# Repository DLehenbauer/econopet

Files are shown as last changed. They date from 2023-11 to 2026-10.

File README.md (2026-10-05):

# EconoPET

Open hardware mainboard replacement for Commodore PET/CBM 2001/30xx/40xx/80xx machines. The EconoPET can also run standalone with HDMI display and USB keyboard.

EconoPET running Space Invaders

## User Resources

See the [project page](https://dlehenbauer.github.io/econopet) for user manual and firmware updates.

## Manufacturing

> **⚠️ Warning:** Rev A is not perfect. Before ordering, review the currently [known issues](https://github.com/DLehenbauer/econopet/issues?q=is%3Aissue%20label%3Arev-a%20label%3Aerrata) and understand that new issues may be discovered over time.

Rev. A has been released. For manufacturing and assembly instructions, go [here](https://dlehenbauer.github.io/econopet/manual/build-an-econopet/).

## Development

This project uses a [Dev Container](https://containers.dev/) for a consistent development environment on Windows, macOS, and Linux.

### Prerequisites

- [Docker](https://www.docker.com/)
- [VS Code](https://code.visualstudio.com/)
- [Dev Containers extension](https://marketplace.visualstudio.com/items?itemName=ms-vscode-remote.remote-containers)

### Workflow

This project uses [CMake](https://cmake.org/) to manage the build process for firmware, gateware, ROMs, and SD card package.

```sh
# Configure
cmake --preset default              # Do this first

# Build
cmake --build --preset all          # Build everything
cmake --build --preset fw           # Build firmware only
cmake --build --preset fw-test      # Build firmware tests only
cmake --build --preset gw           # Build gateware only
cmake --build --preset rom          # Build ROMs only
cmake --build --preset sdcard       # Build SD card package

# Test
ctest --preset all --parallel       # Run all tests
ctest --preset fw --parallel        # Run firmware tests only
ctest --preset gw --parallel        # Run gateware unit tests only
ctest --preset gw-boot --parallel   # Run full-boot benches (Verilator, minutes)
```

Gateware benches run under both simulators. `gw` runs both quick suites;
`gw-iv` and `gw-vl` run only Icarus or Verilator, respectively. Verilator is
two-state and settles differently, so it catches races Icarus tolerates. Each
suite takes under a minute. `ECONOPET_MEDIA_DIR` must point at the directory
containing `roms/` and `disks/`; `top_tb` and the boot bench load real ROMs
from its `roms/` subdirectory.

`gw-boot` is separate because it simulates seconds of PET time: it boots the
stock BASIC-4 ROMs on the soft 6502 and passes only once the banner, the RAM
sizing result and the `READY.` prompt are all on screen. That takes ~5 minutes
under Verilator and is impractical under Icarus. It prints the screen at the
end and writes `gw/EconoPET/outflow/stock6502_boot_tb.pgm`:

```
|*** COMMODORE BASIC 4.0 ***             |
|                                        |
| 31743 BYTES FREE                       |
|                                        |
|READY.                                  |
```

`ctest` hides that on success, so use `ctest --preset gw-boot --parallel -V` to see it, or
run `./verilate.sh stock6502_boot_tb 0` directly. See
[docs/dev/verilator.md](docs/dev/verilator.md) for the Verilator runner and
[docs/dev/testing.md](docs/dev/testing.md) for test seeding and replay.

## License

This project is released under the [CC0 1.0 Universal](LICENSE) (CC0) license, placing it in the public domain.

**Exception:** external dependencies are subject to their own licenses as noted in their respective source code and in [NOTICE.md](NOTICE.md).



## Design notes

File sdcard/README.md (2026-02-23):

# EconoPET Release Notes

For the user manual, firmware updates, and more, visit the [project page](https://dlehenbauer.github.io/econopet).

## Updating Firmware

1. Copy the contents of this archive to a FAT32-formatted microSD card.
2. Insert the microSD card into the EconoPET board.
3. Power on. The firmware will update automatically.

For detailed instructions, see the [user manual](https://dlehenbauer.github.io/econopet).

## Changelog

### v0.2.0 (2026-02-22)

- High-Speed Virtual Datasette (see `/prgs/README.md`)
- HDMI output now supports limited CRTC emulation (R1, R6, R9, R12-R13)
- Optionally load a default configuration when powered on (set `default:` in `config.yaml`)
- ColourPET preview (RGBI output on HDMI, color buffer starts at $8800)

### v0.1.0 (2025-08-29)

- Minimal viable product

## License

This project is released under the [CC0 1.0 Universal](LICENSE) (CC0) license, placing it in the public domain.

**Exception:** external dependencies are subject to their own licenses as noted in their respective source code and in [NOTICE.md](NOTICE.md).

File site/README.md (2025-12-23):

# Site

This directory contains the static website for EconoPET, hosted via GitHub Pages at:

https://dlehenbauer.github.io/econopet

## Deployment

The site references files stored in Git LFS (images, PDFs, and firmware downloads). Because GitHub Pages' default deployment does not check out LFS objects, we use a custom GitHub Actions workflow instead.

The workflow is defined in [`.github/workflows/gh-pages.yml`](../.github/workflows/gh-pages.yml) and must be triggered manually:

1. Go to the [Actions](https://github.com/DLehenbauer/econopet/actions) tab in the GitHub repository
2. Select the **Deploy static content to Pages** workflow from the left sidebar
3. Click **Run workflow** and confirm

The workflow checks out the repository with `lfs: true` to fetch LFS objects, then deploys the contents of `site/dist` to GitHub Pages.

## Links

QR codes linking to the site are printed on the PCB silkscreen. Because space is limited, we use [is.gd](https://is.gd) to shorten URLs. Shorter URLs encode fewer characters, resulting in lower-density QR codes that remain scannable at small sizes with a typical phone camera.

Page  | Short URL
------|----------
[https://dlehenbauer.github.io/econopet](https://dlehenbauer.github.io/econopet) | [https://is.gd/FjBm6R](https://is.gd/FjBm6R)
[https://dlehenbauer.github.io/econopet/40-8096-A.html](https://dlehenbauer.github.io/econopet/40-8096-A.html) | [https://is.gd/6hpvh6](https://is.gd/6hpvh6)

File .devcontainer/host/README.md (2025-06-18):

# Host

On Windows 10/11, you can expose a picoprobe to a docker container using usbipd-win:

```ps
winget install --interactive --exact dorssel.usbipd-win
```

To get the serial port, you may need to `sudo modprobe cdc_acm` on Ubuntu.

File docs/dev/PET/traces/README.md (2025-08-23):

# Logic Analyzer Traces

This folder contains traces captured by a logic analyzer from a CBM 8032.

The traces were recorded using the KingstVIS software. You can download KingstVIS for free from the official website to view these files, or use the software to export the traces to `.bin` or `.csv` formats for further analysis.

**Download KingstVIS software and user manual:**  
https://www.qdkingst.com/en

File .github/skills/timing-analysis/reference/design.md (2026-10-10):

# EconoPET Hardware Design (Timing Context)

This document describes the EconoPET board-level hardware design with enough
detail for an AI agent to derive SDC timing constraints. It is intended to be
read alongside the gateware source in `gw/EconoPET/src/` and the existing SDC
file at `gw/EconoPET/EconoPET.sdc`.

## FPGA

| Property | Value |
|---|---|
| Device | Efinix Trion T20 (T20Q144) |
| Package | QFP-144 |
| I/O Standard | 3.3 V LVTTL / LVCMOS (all banks) |
| I/O Registers  | None (all GPIOs are unregistered at the pad) |
| Speed Grade | Default |

### PLL

A single PLL (`PLL_TL1`) generates the system clock:

| Parameter | Value |
|---|---|
| Reference input | 18 MHz (from RP2040 PWM on GPIO 15, derived from 12 MHz crystal) |
| PLL multiplier | 64 |
| PLL pre-divider | 1 |
| PLL post-divider | 2 |
| Output divider | 9 |
| Output frequency | 64 MHz |
| Output net | `sys_clock_i` (routed to global clock network via `gclk`) |
| Feedback mode | Internal |

The reference clock is generated by the RP2040's PWM peripheral from the
on-board 12 MHz crystal oscillator (typical accuracy 30 ppm). The PLL's
`is_bypass_lock` is true, meaning the FPGA does not wait for PLL lock before
releasing the core from reset.

## Clock Domains

| Clock | Frequency | Source | Domain | Notes |
|---|---|---|---|---|
| `sys_clock_i` | 64 MHz | PLL output | Primary | All synchronous logic except SPI shift register |
| `spi0_sck_i`  | 24 MHz | RP2040 SPI0 SCK | SPI | External clock, center-aligned SDR (mode 0) |

These two clock domains are asynchronous. The SDC declares them with
`set_clock_groups -asynchronous`.

### Derived Clock Enables

The `timing` module divides `sys_clock_i` using a 6-bit counter to produce
clock enables (active for a single `sys_clock_i` cycle):

| Enable | Effective Rate | Purpose |
|---|---|---|
| `clk16_en`  | 16 MHz | 80-column video pixel clock |
| `clk8_en` | 8 MHz | 40-column video pixel clock, bus slot advance |
| (CPU slot)  | ~1 MHz | CPU PHI2 cycle (see Bus Arbitration) |

These are not separate clock domains. They are single-cycle strobes
synchronous to `sys_clock_i`.

## Bus Arbitration

The system bus is time-division multiplexed into 8 slots of 8 `sys_clock_i`
cycles each (one 64-cycle frame). The `timing` module assigns slots as
follows:

| Slot | Grant | Purpose |
|---|---|---|
| 0 | VIDEO_1 | Video VRAM/VROM fetch (even character) |
| 1 | VIDEO_2 | Video VROM fetch (even pixels) |
| 2 | SPI_1 | SPI/Wishbone bridge access |
| 3 | VIDEO_3 | Video VRAM fetch (odd character, 80-col only) |
| 4 | VIDEO_4 | Video VROM fetch (odd pixels, 80-col only) |
| 5 | SPI_2 | SPI/Wishbone bridge access |
| 6 | CPU_1 | CPU bus cycle (first half) |
| 7 | CPU_2 | CPU bus cycle (second half) |

During CPU slots (6-7), the FPGA deasserts its bus drivers and the CPU owns
the address and data buses. During non-CPU slots, the FPGA can drive the buses
for SPI bridge or video fetch operations.

The Wishbone bus mux (`wbc_mux`) selects between the video controller and SPI
bridge as bus controllers based on the current grant.

## External Components and Timing Parameters

### W65C02S CPU

| Parameter | Symbol | Min  | Max  | Units |
|---|---|---|---|---|
| Cycle time | tCYC  | 125  | - | ns |
| Clock pulse width high | tPWH | 62 | - | ns |
| Clock pulse width low | tPWL | 63 | - | ns |
| BE to valid data | tBVD | - | 30 | ns |
| Address setup time | tADS | - | 40 | ns |
| Address hold time | tAH | 10 | - | ns |
| Read data setup time | tDSR | 15 | - | ns |
| Read data hold time | tDHR | 10 | - | ns |
| Write data delay time | tMDS | - | 40 | ns |
| Write data hold time | tDHW | 10 | - | ns |
| Processor control setup | tPCS | 15 | - | ns |
| Processor control hold | tPCH | 10 | - | ns |

The CPU address bus (A0-A15), data bus (D0-D7), PHI2, BE, RDY, RWB, /RES,
/NMI, and /IRQ connect directly to FPGA I/O pins (no transceiver). The FPGA
generates PHI2 (cpu_clock_o), BE (cpu_be_o), and RDY (cpu_ready_o). /RES and
/NMI are active-low open-drain, driven via output-enable on the FPGA side.

### AS6C1008-55PCN SRAM (128KB)

| Parameter | Symbol | Min | Max | Units |
|---|---|-----|-----|---|
| Read cycle time | tRC | 55 | - | ns |
| Address access time | tAA | - | 55 | ns |
| OE access time | tOE | - | 30 | ns |
| OE to output low-Z | tOLZ | - | 5 | ns |
| OE disable to high-Z | tOHZ | - | 20 | ns |
| Output hold from addr change | tOH | 10 | - | ns |
| Write cycle time | tWC | 55 | - | ns |
| Address valid to end of write | tAW | 50 | - | ns |
| Address setup time | tAS | 0 | - | ns |
| Write pulse width | tWP | 45 | - | ns |
| Write recovery time | tWR | 0 | - | ns |
| Data to write overlap | tDW | 25 | - | ns |
| Data hold from end of write | tDH | 0 | - | ns |

#### SRAM Address Bus Wiring

The SRAM address bus is wired as follows:

- **A0-A9, A12-A14**: Connected directly from the CPU address bus to the SRAM.
  These bits are shared (physically wired CPU-to-SRAM). The FPGA can also
  drive them via `cpu_addr_o` when `cpu_addr_oe` is asserted (i.e., when
  `cpu_be_o` is deasserted).
- **A10, A11**: Actively muxed by the FPGA (`ram_addr_a10_o`, `ram_addr_a11_o`).
  When the CPU owns the bus, the FPGA applies video RAM address masking. When
  the FPGA owns the bus, it drives the Wishbone bridge address.
- **A15**: Muxed by the FPGA (`ram_addr_a15_o`) for 64KB RAM expansion bank
  selection.
- **A16**: Muxed by the FPGA (`ram_addr_a16_o`) for RAM expansion bank
  selection.

#### SRAM Data Bus Wiring

The SRAM data bus (D0-D7) is a shared bus connecting the CPU, FPGA, and SRAM.
At most one device drives the bus at any time:

- **CPU reads from SRAM**: SRAM drives data, CPU latches on PHI2 rising edge.
- **CPU writes to SRAM**: CPU drives data, SRAM latches on WE deassertion.
- **FPGA reads from SRAM**: FPGA asserts OE and reads `cpu_data_i`.
- **FPGA writes to SRAM**: FPGA drives `cpu_data_o` with `cpu_data_oe` asserted.

#### SRAM Control Signals

- CE is active (active-low directly to SRAM or active). Permanently asserted
  (active low directly tied low on board or active high directly tied high).
- OE (`ram_oe_n_o`) and WE (`ram_we_n_o`) are driven by the FPGA.

### SN74LVC4245A Level-Shifting Transceivers

Two SN74LVC4245A devices sit between the shared CPU/SRAM bus and the PIA/VIA
I/O chips:

- **Address transceiver**: CPU address A0-A3 to PIA/VIA (fixed direction
  B-to-A, permanently enabled).
- **Data transceiver**: CPU data D0-D7 to PIA/VIA (bidirectional, DIR follows
  CPU RWB). /OE is controlled by the FPGA (`io_oe_n_o`) and only asserted
  during decoded PIA/VIA accesses.

| Parameter | Symbol | Min | Max | Units |
|---|---|-----|-----|---|
| Propagation A-to-B | tPLH | 1 | 6.7 | ns |
| Propagation B-to-A | tPHL | 1 | 6.1 | ns |
| Enable to output low-Z (B) | tPZL | 1 | 10.3 | ns |
| Enable to output high-Z (B) | tPHZ | 1 | 7.8 | ns |

The FPGA's `io_oe_n_o` output must account for the transceiver's enable delay
(up to 10.3 ns) when budgeting setup time for PIA/VIA reads.

### W65C21N PIA (PIA1, PIA2)

| Parameter | Symbol | Min | Max | Units |
|---|---|-----|-----|---|
| PHI2 cycle time | tCYC | 70 | - | ns |
| PHI2 pulse width | tC | 35 | - | ns |
| Address setup (read) | tACR | 8 | - | ns |
| Address hold (read) | tCAR | 0 | - | ns |
| Data bus delay | tCDR | - | 20 | ns |
| Data bus hold | tHR | 5 | - | ns |
| Address setup (write) | tACW | 8 | - | ns |
| Address hold (write) | tCAW | 0 | - | ns |
| Data bus setup (write) | tDCW | 10 | - | ns |
| Data bus hold (write) | tHW | 5 | - | ns |

### W65C22N VIA

| Parameter | Symbol | Min | Max | Units |
|---|---|-----|-----|---|
| Cycle time | tCYC | 70 | - | ns |
| PHI2 pulse width high | tPWH | 35 | - | ns |
| PHI2 pulse width low | tPWL | 35 | - | ns |
| CSx/RSx/RWB setup (read) | tACR | 10 | - | ns |
| CSx/RSx/RWB hold (read) | tCAR | 10 | - | ns |
| Data bus delay | tCDR | - | 20 | ns |
| Data bus hold | tHR | 10 | - | ns |
| CSx/RSx/RWB setup (write) | tACW | 10 | - | ns |
| CSx/RSx/RWB hold (write) | tCAW | 10 | - | ns |
| Data bus setup (write) | tDCW | 10 | - | ns |
| Data bus hold (write) | tHW | 10 | - | ns |

## PCB Trace Delays

All traces are under 100 mm except where noted. At a typical propagation
velocity of ~6 ns/m (FR-4 microstrip), trace delays are estimated as:

| Signal | Trace Length | Estimated Delay |
|---|---|---|
| Most signals | < 100 mm | < 0.6 ns |
| CPU PHI2 | ~120 mm | ~0.7 ns |
| CPU RWB | ~150 mm | ~0.9 ns |
| CPU /IRQ | ~230 mm | ~1.4 ns |
| CPU /NMI | ~250 mm | ~1.5 ns |
| CPU /RES | ~250 mm | ~1.5 ns |

For timing constraint purposes, a conservative board delay budget of 2 ns
covers all signals.

The maximum trace delay is derived from first principles in `common_pkg.sv`:

```systemverilog
// Signal velocity = c / sqrt(Dk), where c = 299.79 mm/ns.
localparam real SPEED_OF_LIGHT_MM_PER_NS = 299.79;
localparam real TRACE_VELOCITY_MM_PER_NS = SPEED_OF_LIGHT_MM_PER_NS / $sqrt(PCB_DIELECTRIC_CONSTANT);
localparam real MAX_TRACE_LENGTH_MM      = 250.0;
localparam int  MAX_TRACE_DELAY_NS       = int'($ceil(MAX_TRACE_LENGTH_MM / TRACE_VELOCITY_MM_PER_NS));
```

The `PCB_DIELECTRIC_CONSTANT` is 4.5 (FR-4 per JLCPCB specs), giving a trace
velocity of ~141.3 mm/ns and a `MAX_TRACE_DELAY_NS` of 2. The helper function
`ns_to_cycles_with_trace_delay()` adds this budget to any component timing
parameter before converting to `sys_clock_i` cycles.

## SPI Interface

The SPI bus connects the RP2040 MCU to the FPGA:

| Property | Value |
|---|---|
| SPI mode | 0 (CPOL=0, CPHA=0) |
| Max SCK frequency | 24 MHz (41.67 ns period) |
| Data sampling | Rising SCK edge |
| Data shifting | Falling SCK edge |
| Framing | CS_N (manually toggled by MCU firmware) |

### Clock Domain Crossing

The SPI module (`spi.sv`) operates in the `spi0_sck_i` clock domain. The
`spi1_controller` module bridges SPI to the Wishbone bus using 2-stage
synchronizers (`sync2` with `async_reg` attribute) for:

- `spi_cs_ni` (CS_N assertion/deassertion edges)
- `spi_strobe` (byte-complete pulse)

The synchronizers introduce 2-3 `sys_clock_i` cycle latency (31-47 ns at
64 MHz).

### Flow Control

The FPGA asserts `spi_stall_o` while processing a command. The MCU must poll
this signal before starting a new SPI transaction.

## FPGA Output Signal Mapping

### Directly Registered Outputs

All of the following output signals are driven by `always_ff` blocks clocked
on `posedge sys_clock_i` (registered in fabric, but the I/O pad itself has no
output register):

| Port | Driven By | Notes |
|---|---|---|
| `cpu_clock_o` | `timing` | PHI2 clock to CPU |
| `cpu_be_o` | `timing` | Bus enable to CPU |
| `cpu_ready_o` | `register_file`  | RDY to CPU |
| `cpu_reset_n_oe`  | `register_file`  | Open-drain /RES |
| `cpu_nmi_n_oe` | `register_file`  | Open-drain /NMI |
| `ram_oe_n_o` | combinational | SRAM output enable (derived from `cpu_be_o`, `ram_en`, `ram_ctl_oe`) |
| `ram_we_n_o` | combinational | SRAM write enable (derived from `cpu_be_o`, `cpu_we_i`, `ram_en`, `ram_ctl_we`) |
| `io_oe_n_o` | combinational | I/O transceiver enable |
| `pia1_cs_n_o` | combinational | PIA1 chip select |
| `pia2_cs_n_o` | combinational | PIA2 chip select |
| `via_cs_n_o` | combinational | VIA chip select |
| `ram_addr_a10_o`  | combinational | Muxed RAM A10 |
| `ram_addr_a11_o`  | combinational | Muxed RAM A11 |
| `ram_addr_a15_o`  | combinational | Muxed RAM A15 |
| `ram_addr_a16_o`  | combinational | Muxed RAM A16 |
| `cpu_addr_o[15:0]`| registered | From `ram.sv` address capture |
| `cpu_data_o[7:0]` | registered | From `cpu_data_mux` |
| `cpu_we_n_o` | tied low (0) | Currently unused |
| `h_sync_o` | registered | Video horizontal sync |
| `v_sync_o` | registered | Video vertical sync |
| `video_o` | registered | Video data |
| `audio_o` | registered | Audio output |
| `spi0_sd_o` | `spi.sv` | SPI data out (SCK domain) |
| `spi_stall_o` | registered | SPI flow control |

### Combinational Output Paths

The following outputs are driven by combinational logic from `sys_clock_i`
domain flip-flops. These have longer output delays due to LUT propagation:

- `ram_oe_n_o`: depends on `cpu_be_o`, `cpu_we_i` (input), `ram_en` (from
  address decoding), `ram_ctl_oe` (from Wishbone RAM peripheral)
- `ram_we_n_o`: depends on `cpu_be_o`, `cpu_we_i` (input), `cpu_clock_o`,
  `ram_en`, `is_readonly`, `ram_ctl_we`
- `io_oe_n_o`, `pia1_cs_n_o`, `pia2_cs_n_o`, `via_cs_n_o`: depend on
  address decoding of `cpu_addr_i` and `cpu_be_o`
- `ram_addr_a10_o`, `ram_addr_a11_o`, `ram_addr_a15_o`, `ram_addr_a16_o`:
  muxed between CPU-driven and FPGA-driven values based on `cpu_be_o`

## CPU Bus Cycle Timing

The `timing` module generates the CPU bus cycle within slots 6-7 of the
64-cycle frame. The cycle counts (in `sys_clock_i` cycles from the start of
the CPU slot) are computed from component timing parameters:

| Event | Cycle Offset | Purpose |
|---|---|---|
| `CPU_BE_START` | 0 | Assert BE (CPU takes ownership of bus) |
| `CPU_PHI_START` | +4 | Assert PHI2 (after tBVD + tIOTX delays) |
| `CPU_DATA_STROBE`  | +7 | Capture read data / validate write data |
| `CPU_PHI_END` | +9 | Deassert PHI2 (after tPWH minimum met) |
| `CPU_BE_END` | +11 | Deassert BE (after tDHx hold time met) |

The CPU effective clock rate is 1 MHz (one PHI2 cycle per 64 `sys_clock_i`
cycles, i.e., 64 / 64 MHz = 1 us).

## Wishbone Bus

The internal Wishbone B4 pipelined bus connects:

**Controllers:**
- SPI bridge (`spi1_controller`): MCU read/write access via SPI
- Video controller (`video`): VRAM and character ROM fetches

**Peripherals:**
- RAM (`ram`): External SRAM read/write with multi-cycle state machine
- Register file (`register_file`): CPU control, status, video config
- Keyboard (`keyboard`): USB keyboard matrix state
- CRTC (`video_crtc`): CRT controller register access
- BRAM (`bram`): On-chip character ROM (4KB)

Address decoding is combinational from `wb_addr` in `main.sv`.

## Key Timing Paths for Constraint Derivation

### 1. sys_clock_i Internal Paths

All core logic runs on one clock. Setup/hold analysis is straightforward at
15.625 ns period. The most timing-critical internal paths are likely:

- Address decoding logic (combinational `casez` in `main.sv` and
  `address_decoding.sv`)
- Wishbone peripheral mux (`wbp_mux`) and controller mux (`wbc_mux`)
- CPU data mux (`cpu_data_mux`) with 4 sources

### 2. SPI I/O Paths (spi0_sck_i domain)

- **Input (spi0_sd_i)**: Sampled on rising SCK, transitions on falling SCK.
  Constrained with `set_input_delay` relative to falling SCK edge.
- **Output (spi0_sd_o)**: Shifted out on falling SCK. Constrained with
  `set_output_delay` relative to falling SCK edge.
- **CS_N (spi0_cs_ni)**: Used as async reset in `spi.sv`. Currently a false
  path in the SDC.

### 3. CPU-Facing Output Paths (sys_clock_i to pad)

These are constrained with `set_output_delay` relative to `sys_clock_i`:

- `cpu_clock_o`, `cpu_be_o`, `cpu_ready_o`: Registered outputs.
- `ram_oe_n_o`, `ram_we_n_o`: Combinational from registered signals. The
  relationship between address output delay and WE assertion is critical (WE
  minimum delay must be >= maximum address output delay to maintain SRAM
  address setup to end-of-write).
- `cpu_data_o`, `cpu_addr_o`: Directly driven for FPGA bus master operations.

### 4. CPU-Facing Input Paths (pad to sys_clock_i)

- `cpu_addr_i[15:0]`: Sampled during CPU slots for address decoding and SRAM
  address mux. Not currently constrained with `set_input_delay` in the SDC
  (the CPU drives addresses synchronous to PHI2, which the FPGA generates).
- `cpu_data_i[7:0]`: Sampled at `cpu_data_strobe` timing point. Same
  consideration as address.
- `cpu_we_n_i`: Sampled for read/write direction.

These inputs are quasi-static relative to `sys_clock_i` because the CPU's
timing is controlled by FPGA-generated PHI2. The data is guaranteed valid by
the time the FPGA samples it (multiple `sys_clock_i` cycles after the relevant
edge). This may justify `set_false_path` or relaxed `set_input_delay`
constraints rather than full-speed setup/hold analysis.

### 5. Asynchronous Inputs

The following inputs are asynchronous and should be false-pathed or
constrained with `set_max_delay`:

- `config_crt_i`, `config_keyboard_i`: DIP switch settings (static)
- `text_mode_i`: VIA CA2 output (asynchronous to sys_clock_i)
- `diag_i`, `via_cb2_i`: Audio-related inputs
- `cpu_reset_n_i`, `cpu_irq_n_i`, `cpu_nmi_n_i`: Active-low open-drain signals

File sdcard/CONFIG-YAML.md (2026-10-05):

# config.yaml

The `config.yaml` file describes the startup choices shown by the boot menu and the configuration steps taken when the user selects a configuration.

> **⚠️ Important — please read before customizing `config.yaml`:**
>
> - **Firmware updates overwrite `config.yaml`.** If you have customized the file, be sure to back it up before applying a firmware update.
> - **The format is not stable.** It is likely to change in future firmware revisions. Do not expect forward or backward compatibility between versions.
> - **The YAML parser is custom and does not support all YAML features.** Stick to the constructs you see used in the shipped `config.yaml`.

YAML is a general file format for serializing a tree of data. It is designed to be easy for people to read and edit. If you are new to YAML, the following references are helpful:

- [YAML Basic Syntax - Learn YAML Fundamentals | YAML.cc](https://yaml.cc/tutorial/basic-syntax.html) — a gentle introduction that builds up the syntax one concept at a time.
- [Learn YAML in Y Minutes](https://learnxinyminutes.com/yaml/) — a concise tour of the language with small examples of each feature.
- [YAML Ain't Markup Language (YAML™) revision 1.2.2](https://yaml.org/spec/1.2.2/#chapter-2-language-overview) — the official specification, for when you need the authoritative details.

## Top-level settings

The root of the YAML file has two properties:

| Property | Meaning |
| --- | --- |
| `default` | Optional. The `id` of the configuration to use on power-on. If omitted, the boot menu is shown at power-on. |
| `configs` | A list of configurations to show in the boot menu. |

## Configurations

Each item in `configs` describes one boot menu option:

| Property | Meaning |
| --- | --- |
| `id` | A unique string that identifies the configuration. This is what `default` refers to. |
| `name` | A human-readable name to show in the boot menu. |
| `setup` | A list of actions to perform when this configuration is selected. |

The parser stores up to 40 text bytes for configuration IDs and names, plus
the terminating null. Longer values are truncated. The parser forwards the
`default` scalar unchanged, but the boot menu stores only its first 40 text
bytes when matching configuration IDs. Keep IDs, names, and `default` within
this limit so the menu and default selection use the intended text.

## Setup actions

Each item in a `setup` list is an action. The `action` property tells the
firmware what kind of action to perform:

| Action | Meaning |
| --- | --- |
| `load` | Copies a list of binary files from the SD card to memory addresses. This is used to initialize ROMs. |
| `patch` | Overwrites a range of bytes in memory with a hex string. This is used to overlay patches over ROMs. |
| `copy` | Copies a range of bytes in memory from one address to another. This is also used for patching ROMs. |
| `mount` | Inserts a disk image from `/disks` into an IEEE drive slot. |
| `fix-checksum` | Modifies the byte at the target address so memory matches the desired Commodore checksum after patching. |
| `set` | Configures firmware options. |

SD paths have a capacity of 256 bytes including the terminating null, matching
pico-vfs. The full path may contain at most 255 bytes, including any directory
prefix. `load` files and `usb-keymap` values are complete paths. `mount` filenames
are relative to `/disks/`, leaving at most 248 bytes for the filename. Overlong
paths are fatal errors, not truncated filenames.

Setup lists may also contain `if` / `then` / `else` entries. These are used when
a configuration needs different setup steps for different hardware, such as
loading different ROMs for the graphics and business keyboards.

## Firmware options

The `set` action can configure these firmware options:

| Option | Values | Meaning |
| --- | --- | --- |
| `columns` | `80` or `40` | Selects the screen width. |
| `video-ram-kb` | `1`, `2`, `3`[^vram-3], `4`, or `8`[^vram-8] | Selects the amount of video RAM. |
| `usb-keymap` | File name | Names the SD card file containing the USB HID code to PET keyboard matrix mapping. |
| `tape` | ROM-specific bytes | Tells the firmware how to intercept `LOAD` commands for the virtual tape drive. |
| `cpu` | `physical`, `6502`, `6809`, or `auto` | Selects which CPU drives the bus: the socketed 6502, the soft 6502, the soft 6809 (SuperPET), or auto-detect (physical if populated, else soft 6502). Defaults to `auto`. |

Use the `mount` action to select the images inserted by a configuration.
`device` is `8` through `11`, `drive` is `0` or `1`, and `file` is the image
path relative to `/disks`. The path is opened directly; for example, use
`example.d80` for `/disks/example.d80`:

```yaml
      # If not specified, the default device is 8 and the default drive is 0.
      - action: "mount"
        file: "example1.d80"
      # Available devices are 8 through 11.  Each device is a dual-drive unit
      # with two drives: drive 0 and drive 1.
      - action: "mount"
        device: 8
        drive: 1
        file: "example2.d80"
```

Mounting an image enables the virtual IEEE-488 drives. Selecting another
configuration removes the images mounted by the previous configuration and
disables emulation when no images remain.

[^vram-3]: `video-ram-kb: 3` activates the experimental ColourPET 40-column mode.

[^vram-8]: On models with more than 4 KB of video RAM, the upper 4 KB is "write only": CPU writes and CRTC reads to `$9000-$9FFF` target video RAM, while CPU reads in this range return the option ROM.

## Example: *Attack of the PETSCII Robots*

The full version of [*Attack of the PETSCII Robots*](https://www.the8bitguy.com/product/petscii-robots/)
ships with a custom character ROM that replaces the stock PET font with the
graphics tiles used by the game. This example walks through adding a new boot
menu entry that loads that custom character ROM alongside the standard BASIC 4
ROMs for a 40-column PET.

### 1. Back up your existing `config.yaml`

Firmware updates overwrite `config.yaml`, so make a copy before editing:

```
/config.yaml          ← the live file
/config.backup.yaml   ← your copy
```

### 2. Copy the custom character ROM onto the SD card

Place the custom character ROM from the PETSCII Robots download onto the SD
card under `/roms/`. For this example we'll assume the file is named:

```
/roms/CHAR-ROM.bin
```

### 3. Pick an existing configuration to base the new entry on

The shipped `config.yaml` already contains a configuration named
`pet-40xx-60hz` ("PET 40xx (40 Col 60 Hz)") that loads BASIC 4, the editor
ROM, the kernal, and the standard character ROM. The only thing we need to
change is the character ROM file loaded at address `0x68000`.

### 4. Add a new configuration to `configs`

Open `config.yaml` and add a new entry to the `configs` list. The new entry
should be a sibling of the existing `- id: pet-40xx-60hz` block. Indentation
matters in YAML — line the new `- id:` up with the other `- id:` entries.

```yaml
  - id: pet-40xx-60hz-robots
    name: "PET 40xx + PETSCII Robots font"
    setup:
      - action: "load"
        files:
          - address: 0xb000
            file: "/roms/basic-4-b000.901465-23.bin"
          - address: 0xc000
            file: "/roms/basic-4-c000.901465-20.bin"
          - address: 0xd000
            file: "/roms/basic-4-d000.901465-21.bin"
          - address: 0xe000
            file: "/roms/edit-4-40-n-60Hz.901499-01.bin"
          - address: 0xf000
            file: "/roms/kernal-4.901465-22.bin"
          - address: 0x68000
            file: "/roms/CHAR-ROM.bin"   # Custom character ROM
      - action: "set"
        usb-keymap: "/ukm/us.bin"
        video-ram-kb: 1
        tape: "2ef415f4c9cad1d4da"
```

The only change from `pet-40xx-60hz` is the `file:` value at address
`0x68000`, which now points at the PETSCII Robots character ROM.

### 5. Save and reboot

Save `config.yaml` back to the SD card, reinsert it, and power-on the PET. The
new entry should now appear in the boot menu. Loading a BASIC program from the
game will now use the custom font.

**Tip:** If the new entry does not appear, or the machine fails to boot,
restore `config.backup.yaml` and re-check your indentation.

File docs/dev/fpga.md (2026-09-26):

# FPGA

## Documentation

* [T20 Datasheet](https://www.efinixinc.com/docs/trion20-ds-v5.10.pdf)
* [Trion Interfaces User Guide](https://www.efinixinc.com/support/docsdl.php?s=ef&pn=UG-TINTF)
* [Efinity Synthesis User Guide](https://www.efinixinc.com/support/docsdl.php?s=ef&pn=UG-EFN-SYNTH)
* [Efinity Timing Closure User Guide](https://www.efinixinc.com/support/docsdl.php?s=ef&pn=UG-EFN-TIMING)
* [AN 006: Configuring Trion FPGAs](https://www.efinixinc.com/docs/an006-configuring-trion-fpgas-v6.5.pdf)

## Driver

Directions for installing the driver are in [AN 006: Configuring Trion FPGAs](https://www.efinixinc.com/docs/an006-configuring-trion-fpgas-v6.5.pdf):

1. Connect the board to your computer with the appropriate cable and power it up.
2. Run the Zadig software.
Note:  To ensure that the USB driver is persistent across user sessions, run the
Zadig software as administrator.
3. Choose Options > List All Devices.
4. Repeat the following steps for each interface. The interface names end with (Interface N),
where N is the channel number.
    1. Select libusb-win32 in the Driver drop-down list.
    2. Click Replace Driver.
5. Close the Zadig software.

(Mine show as `Dual RS232-HS (Interface n)`)

## T8

There are 24 BRAMs for ~12KB of RAM.

Supported access modes:

* 256 x 20
* 256 x 16
* 512 x 10
* 512 x 8
* 1024 x 5
* 1024 x 4
* 2048 x 2
* 4096 x 1

## T20

Pin-compatible with T8.  There are 204 BRAMs for ~102KB of RAM (+90KB).

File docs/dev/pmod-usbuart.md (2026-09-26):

# Using a PmodUSBUART with the ACIA serial port

> **⚠️ Warning:** Do not use a 5V TTL serial adapter. This will damage the FPGA.

The EconoPET's ACIA serial port is available on the `PMOD2` header. It uses the
Digilent Pmod Type-4 UART pinout, so a Digilent
[PmodUSBUART](https://digilent.com/shop/pmod-usbuart-usb-to-uart-interface/)
provides a direct USB connection to the ACIA.

## Connecting the Pmod USBUART

1. Install the [FTDI VCP drivers](https://ftdichip.com/drivers/vcp-drivers/) on the host computer.
1. Verify that the Pmod USBUART jumper connects `LVL` to `VCC`. (Leave the
   `SYS` pin disconnected.)
1. With the EconoPET powered off, install the Pmod USBUART on the **TOP row** of
   pins on `PMOD2`.

   ```text
   Pmod USBUART board
       +---+---+---+---+---+---+
       | 6 | 5 | 4 | 3 | 2 | 1 |  <-- use this row
       +---+---+---+---+---+---+
       |12 |11 |10 | 9 | 8 | 7 |
       +---+---+---+---+---+---+
   ================================= EconoPET PCB
   ```

1. Connect the Pmod USBUART to the host computer with USB.

PMOD2 connects the signals below. The PmodUSBUART supplies the required
cross-over between the EconoPET and USB serial interface.

| PMOD2 pin | EconoPET signal | Pmod USBUART signal |
| --- | --- | --- |
| 1 | CTS input | RTS# |
| 2 | TXD output | RXD |
| 3 | RXD input | TXD |
| 4 | RTS# output | CTS# |

The ACIA is at `$EFF0-$EFF3`. Configure the host terminal to use the serial
settings required by the software running on the EconoPET.

## Testing with SuperPET OS-9

OS-9 provides a convenient way to verify the serial connection:

1. Boot the EconoPET in SuperPET 6809 mode, then boot OS-9.
1. At the main OS-9 terminal, start a terminal monitor for the serial port:

   ```text
   tsmon /t1 &
   ```

1. Configure the host terminal for **1200 baud, 8 data bits, no parity, and 1
   stop bit (8N1)**. Disable both hardware and software flow control.

The serial terminal should present an OS-9 login prompt after `tsmon` starts. If
output is garbled or absent, verify that the terminal's baud, data bits, parity,
and stop bits match the OS-9 configuration.

## Reference

- [Digilent PmodUSBUART Reference Manual](https://digilent.com/reference/_media/pmod:pmod:pmodusbuart_rm.pdf)

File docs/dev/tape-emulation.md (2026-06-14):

# Virtual Tape Drive

This document describes how the MCU emulates a tape drive to load PRG files
from the SD card when the user types `LOAD`. Rather than emulating the tape
hardware signals, the MCU intercepts the KERNAL's LOAD dispatch, copies the
program directly into SRAM, and redirects execution to a stub that prints a
LOADING message and returns to the BASIC ready prompt.

## Overview

1. User types `LOAD "PROGRAM"` (or `LOAD "P*"` for wildcard prefix match)
2. BASIC calls the KERNAL LOAD routine, which parses the filename and device
   number into zero page variables (FNLEN, FNADR, FA)
3. MCU breakpoint fires just before the KERNAL dispatches to the
   device-specific load path (at `JSR LD15` for ROM 2/4, `LDA FA` for ROM 1)
4. MCU reads the device number. If not a tape device (1 or 2), the MCU
   resumes the KERNAL so it can handle disk/IEEE LOADs normally
5. MCU reads the filename from PET memory. If empty or just `*`, the MCU
   resumes the KERNAL (fall through to physical datasette). If the filename is
   `$`, the MCU generates a directory listing instead (see the Directory
   Listing section below)
6. MCU searches `/sd/prgs/` for a matching `.prg` file
7. If found:
   - MCU copies the PRG data into SRAM at the load address from the PRG file
   - MCU sets EAL/EAH to the end address
   - MCU saves the existing tape buffer contents (for later restoration)
   - MCU writes a stub to the tape buffer that prints
     `FOUND "/SD/PRGS/FILENAME.PRG"` then jumps to the KERNAL's LD210
     routine, which prints "READY.", sets VARTAB, relinks BASIC lines,
     clears variables, and enters the main loop
   - When the stub's `JMP LD210` fires a second breakpoint at LD210, the
     MCU restores the original tape buffer contents before resuming
8. If not found:
   - MCU resumes the KERNAL, which enters the tape path normally (prints
     "PRESS PLAY ON TAPE" and polls the sense pin)

## Background

When the user types `LOAD`, the KERNAL displays "PRESS PLAY ON TAPE" and
enters a tight loop polling PIA1 Port A bit 4 (the cassette sense pin),
waiting for it to go low. See [tape.md](PET/tape.md) for full details.

## Detection Strategy

The firmware uses its breakpoint subsystem (see [breakpoint.h](../../../fw/src/breakpoint.h))
to intercept the KERNAL's LOAD dispatch before it enters the device-specific
code path.

### LOAD Dispatch (ROM 4)

The KERNAL's LOAD routine parses the filename and device number into zero
page variables via PARS1, then dispatches to the appropriate device handler
via `JSR LD15`:

```
LOAD   F401  LDA #0
       F403  STA VERCK            ; set load (not verify)
LD10   F405  JSR PARS1            ; parse FNLEN, FNADR, FA, SA
LOADNP F408  JSR SV60             ; set STAL/STAH/EAL/EAH
       F40B  LDA #$FF
LD11   F40D  CMP STKEY            ; wait for all keys released
       F40F  BNE LD11
       F411  CMP STKEY
       F413  BNE LD11
  -->  F415  JSR LD15             ; <--- breakpoint here
```

At `$F415`, PARS1 and SV60 have both returned. FNLEN, FNADR, and FA (device
number) are fully initialized in zero page, and there are no stale KERNAL
subroutine frames on the stack. This is essential for program-mode LOADs
(e.g., a BASIC program that LOADs itself), because LD210's program-mode path
uses STKINI to pop the top return address from the stack and reset the stack
pointer. If stale KERNAL frames were present, STKINI would pop the wrong
address.

ROM 1.0 uses inline device dispatch instead of `JSR LD15`. The equivalent
clean breakpoint is `LDA FA` at `$F362`, just before the `BCC LD100` branch
to the tape path.

Since the breakpoint fires for all LOADs (tape, disk, IEEE), the callback
checks the device number first and immediately resumes if it is not a tape
device (1 or 2). This costs a single SPI read for non-tape LOADs.

## PRG File Format

A `.prg` file is the standard Commodore program format:

| Offset | Size | Description |
|---|---|---|
| 0 | 2 | Load address (little-endian) |
| 2 | n | Program data (BASIC tokens or ML code) |

For BASIC programs, the load address is typically `$0401` (start of BASIC
program area). The program data consists of linked BASIC lines.

### BASIC Line Format

Each BASIC line has:

| Offset | Size | Description |
|---|---|---|
| 0 | 2 | Pointer to next line (or $0000 for end)  |
| 2 | 2 | Line number |
| 4 | n | Tokenized BASIC text |
| 4+n | 1 | Zero terminator ($00) |

The "next line" pointers form a linked list. These pointers are absolute
addresses that depend on where the program is loaded in memory.

## Memory Locations

### Zero Page Variables (ROM 4)

| Address | Name | Description |
|---|---|---|
| $28-29  | TXTTAB | Pointer: Start of BASIC program |
| $2A-2B  | VARTAB | Pointer: Start of BASIC variables |
| $C9 | EAL | End address low (end of loaded program)  |
| $CA | EAH | End address high |
| $D1 | FNLEN  | Length of current filename (0-16) |
| $D4 | DEVNUM | Current device number (1=Cass#1, 2=Cass#2) |
| $DA-DB  | FNADR  | Pointer to filename string |

### BASIC/KERNAL Entry Points (ROM 4)

| Address | Name | Description |
|---|---|---|
| $B3FF | READY | BASIC warm start (prints "READY" prompt) |
| $B4B6 | LINKPRG | Rechain BASIC lines (fix link pointers)  |
| $B5E9 | RSTXCLR | Reset TXTPTR and perform CLR |
| $B5F0 | CLR | Clear variables, reset stack |
| $F42E | LD210 | Post-load fixup (see below) |

## Load Sequence

When the breakpoint fires and a matching PRG file is found:

### Step 1: Read Filename from PET Memory

```c
uint8_t fnlen = spi_read_at(FNLEN);      // $D1
uint16_t fnadr = spi_read16_at(FNADR);   // $DA-DB
char filename[17];
spi_read(fnadr, filename, fnlen);
filename[fnlen] = '\0';
```

### Step 2: Search SD Card

Search `/sd/prgs/` for a file matching the requested name. Support the `*`
wildcard for prefix matching:

- `LOAD "*"` or `LOAD ""` - fall through to physical datasette
- `LOAD "GAME*"` - load first file starting with "game"
- `LOAD "ADVENTURE"` - load exact match "adventure.prg"

Filename matching is case-insensitive. PETSCII is converted to ASCII for
filesystem operations.

### Step 3: Copy PRG to SRAM

```c
// Read PRG header (2-byte load address)
uint16_t load_addr;
f_read(&file, &load_addr, 2, &bytes_read);

// Use the load address from the PRG file (typically $0401 for BASIC).
// This matches KERNAL behavior: the tape header's start address (not
// TXTTAB) determines where data is loaded.
uint16_t dest = load_addr;

// Copy program data to SRAM
while (f_read(&file, buffer, sizeof(buffer), &bytes_read) == FR_OK 
       && bytes_read > 0) {
    spi_write(dest, buffer, bytes_read);
    dest += bytes_read;
}

uint16_t end_addr = dest;
```

### Step 4: Update End-of-Load Pointer

Set EAL/EAH to point just past the end of the loaded program. The KERNAL's
LD210 routine copies these into VARTAB before calling FINI (which relinks
BASIC lines and clears variables). The EAL/EAH ZP addresses come from the
config blob:

```c
spi_write_at(cfg.eal, end_addr & 0xFF);
spi_write_at(cfg.eah, end_addr >> 8);
```

### Step 5: Write Stub to Tape Buffer

The MCU writes a small 6502 program to the tape buffer ($027A) that:

1. Prints a message with the SD card path using CHROUT ($FFD2)
2. Jumps to the KERNAL's LD210 routine

Before overwriting the tape buffer, the MCU saves its current contents
(192 bytes) in a local buffer. These are restored when the stub reaches
LD210 (see [Step 7](#step-7-restore-tape-buffer)).

CHROUT ($FFD2) is in the KERNAL jump table and stable across all ROM
versions. The LD210 address comes from the config blob.

The LD210 routine is the KERNAL's own post-tape-load fixup path. It:

1. Prints "READY." (from the KERNAL message table)
2. Copies EAL/EAH into VARTAB
3. Calls FINI, which calls RUNC (reset TXTPTR, clear variables), then
   falls through into LNKPRG (rechain BASIC line pointers), which ends
   by jumping to the BASIC main input loop

This reuses the exact same code path the KERNAL uses after a real tape load,
so all ROM versions (including ROM 1.0 where LNKPRG ends with `JMP MAIN`
instead of `RTS`) work correctly.

#### Tape Buffer Layout

The MCU constructs the following program at runtime (ROM 4 shown):

```
Offset  Addr   Hex          Asm
------  -----  -----------  ----------------------------------
 0      027A   A2 00        LDX #$00
 2      027C   BD 8A 02     LDA $028A,X      ; message address
 5      027F   F0 06        BEQ $0287        ; null terminator
 7      0281   20 D2 FF     JSR $FFD2        ; CHROUT
10      0284   E8           INX
11      0285   D0 F5        BNE $027C        ; loop
13      0287   4C 2E F4     JMP $F42E        ; LD210
16      028A   ...          message string (null-terminated)
```

Bytes 0-12 are a fixed print loop. The `LDA` operand at offset 3-4 is
computed as `TAPE_BUFFER + 16` (print loop size + JMP size). Bytes 13-15
are `JMP ld210` built at runtime from `cfg.ld210`. The message string
starts at byte 16, for example:

```
FOUND /PRGS/GAME.PRG\rLOADING
```

The `\r` ($0D, carriage return) moves the cursor to the next line. LD210
then prints "READY." on the following line. The path is converted to
uppercase for the PET's default character set. The tape buffer is 192
bytes, leaving 176 bytes for the message (more than enough for any path).

### Step 6: Resume Execution

The breakpoint callback returns the stub address ($027A) as the resume
target. The breakpoint system writes a JMP instruction to redirect execution.

### Step 7: Restore Tape Buffer

The `tape_load_callback` arms a one-shot breakpoint at LD210 (`cfg.ld210`).
When the stub's `JMP LD210` reaches this breakpoint, the MCU restores the
saved tape buffer contents, removes the breakpoint, and resumes LD210
normally. This ensures the tape buffer is left in its original state after
the virtual load completes.

Because the breakpoint only exists while a virtual load is in progress,
physical datasette loads never trigger the callback.

```c
// Fixed print loop: LDX #0 / LDA msg,X / BEQ done / JSR CHROUT / INX / BNE loop
static const uint8_t print_loop[] = {
    0xA2, 0x00,                     // LDX #$00
    0xBD, 0x00, 0x00,               // LDA $xxxx,X  (patched below)
    0xF0, 0x06,                     // BEQ done
    0x20, 0xD2, 0xFF,               // JSR $FFD2 (CHROUT)
    0xE8,                           // INX
    0xD0, 0xF5                      // BNE loop
};

#define PRINT_LOOP_SIZE  sizeof(print_loop)  // 13
#define JMP_SIZE         3

static void tape_build_stub(uint8_t* buf, const char* path) {
    // Print loop (13 bytes)
    memcpy(buf, print_loop, PRINT_LOOP_SIZE);

    // Patch LDA operand with message address
    uint16_t msg_addr = TAPE_BUFFER + PRINT_LOOP_SIZE + JMP_SIZE;
    buf[3] = msg_addr & 0xFF;
    buf[4] = msg_addr >> 8;

    // JMP ld210 (3 bytes)
    buf[PRINT_LOOP_SIZE]     = 0x4C;    // JMP
    buf[PRINT_LOOP_SIZE + 1] = state.cfg.ld210 & 0xFF;
    buf[PRINT_LOOP_SIZE + 2] = state.cfg.ld210 >> 8;

    // Message string
    uint8_t off = PRINT_LOOP_SIZE + JMP_SIZE;
    const char prefix[] = "FOUND ";
    memcpy(buf + off, prefix, sizeof(prefix) - 1);
    off += sizeof(prefix) - 1;
    for (size_t i = 0; path[i]; i++)
        buf[off++] = toupper((unsigned char)path[i]);
    buf[off++] = '\r';      // CR (newline on PET)
    static const char loading[] = "LOADING";
    memcpy(buf + off, loading, sizeof(loading) - 1);
    off += sizeof(loading) - 1;
    buf[off++] = '\0';      // Null terminator
}

static bp_result_t tape_load_callback(uint16_t pc, void* context) {
    // ... check device number, read filename, search SD card ...

    if (load_successful) {
        // Set EAL/EAH so LD210 can update VARTAB
        spi_write_at(state.cfg.eal, end_addr & 0xFF);
        spi_write_at(state.cfg.eah, end_addr >> 8);

        // Save tape buffer before overwriting with stub
        spi_read(TAPE_BUFFER, TAPE_BUFFER_CAPACITY, state.saved_buf);

        // Arm a one-shot breakpoint at LD210 to restore the tape buffer
        bp_set(state.cfg.ld210, tape_ld210_callback, NULL);

        uint8_t buf[192];
        tape_build_stub(buf, path);     // e.g. "/prgs/game.prg"
        uint8_t total = PRINT_LOOP_SIZE + JMP_SIZE + msg_len;
        spi_write(TAPE_BUFFER, buf, total);
        return (bp_result_t){ .pc = TAPE_BUFFER, .rearm = true };
    }

    return (bp_result_t){ .pc = pc, .rearm = true };
}

// One-shot breakpoint at LD210: restore tape buffer after virtual load.
static bp_result_t tape_ld210_callback(uint16_t pc, void* context) {
    spi_write(TAPE_BUFFER, state.saved_buf, TAPE_BUFFER_CAPACITY);
    return (bp_result_t){ .pc = pc, .rearm = false };
}
```

The callback returns a `bp_result_t` with the resume address and a `rearm`
flag. Setting `rearm = false` tells the breakpoint system to remove the
breakpoint after resuming (one-shot behavior).

## Wildcard Matching

The `*` wildcard matches zero or more characters at the end of the pattern.
However, `LOAD ""` and `LOAD "*"` fall through to the physical datasette
since the user did not specify a particular file:

| User Types | Behavior |
|---|---|
| `LOAD ""` | Physical datasette (no file specified) |
| `LOAD "*"` | Physical datasette (no file specified) |
| `LOAD "$"` | Directory listing (see below) |
| `LOAD "A*"` | First file starting with "a" |
| `LOAD "GAME"` | Exactly "game.prg" |
| `LOAD "GAME*"`  | "game.prg", "game2.prg", etc. |

Implementation:

```c
bool match_filename(const char* pattern, uint8_t pattern_len, 
                    const char* filename) {
    // Empty pattern or "*" alone: fall through to physical tape
    if (pattern_len == 0) return false;
    if (pattern_len == 1 && pattern[0] == '*') return false;
    
    // Check for trailing wildcard
    bool has_wildcard = (pattern[pattern_len - 1] == '*');
    uint8_t match_len = has_wildcard ? pattern_len - 1 : pattern_len;
    
    // Compare prefix (case-insensitive, PETSCII to ASCII)
    for (uint8_t i = 0; i < match_len; i++) {
        char p = petscii_to_ascii(pattern[i]);
        char f = tolower(filename[i]);
        if (p != f) return false;
    }
    
    // If no wildcard, filename must match exactly (minus .prg extension)
    if (!has_wildcard) {
        // filename should be "pattern.prg" or just end here
        return (filename[match_len] == '.' || filename[match_len] == '\0');
    }
    
    return true;
}
```

## Directory Listing (`LOAD "$"`)

`LOAD "$"` is special-cased to synthesize a directory listing of the loadable
`.prg` files in `/sd/prgs/`. Listing the directory with `LOAD "$"` is a
convenience borrowed from Commodore DOS (the virtual tape drive does not
otherwise emulate a disk drive). After the load completes, the user types `LIST`
to view it.

The detection happens in `tape_load_callback`, after the device-number gate and
after the empty/`*` check: if the requested name is exactly `$` (and the device
is a tape device), the MCU branches to the directory generator instead of
searching for a file. (A bare `LOAD "$"` defaults to device 1, so it is
intercepted; `LOAD "$",8` is device 8 and is ignored.)

### How It Works

The listing is built as a synthetic BASIC program (the same trick Commodore DOS
uses) and written to memory at the BASIC start (`$0401`, universal across all PET
ROM versions). The MCU then reuses the existing stub + LD210 path: it sets
EAL/EAH to the end of the synthesized program, writes the print stub to the tape
buffer, and redirects execution. LD210 prints `READY.`, sets VARTAB, and relinks
the (fake) BASIC line pointers, leaving a `LIST`-able directory in memory.

Because the program is relinked by LD210/LINKPRG, the line link pointers only
need to be plausible placeholders. The generator fills them with the correct
absolute addresses anyway, and terminates the program with a `$0000` link.

### Directory Format

Each "line" is a fake BASIC line whose line number is printed by `LIST`:

| Line | Line number | Text |
|---|---|---|
| Header | `0` | RVS-ON, `"ECONOPET "`, ` SD 2A` |
| One per file  | block count | quoted name (`.prg` suppressed), then `PRG` |
| Footer | free blocks | `BLOCKS FREE.` |

- The header reports the EconoPET firmware as the disk name, with an `SD`
  disk id (for SD card) and a `2A` DOS-type id.
- The block count is `ceil(file_size / 254)` (at least 1). Leading spaces in the
  text shrink as the block count grows so the filename quote stays aligned.
- Filenames are uppercased for the PET default character set and the `.prg`
  extension is suppressed. The quoted name is padded to a 16-character field.
- Entries are sorted alphabetically (case-insensitive), since `readdir`
  returns filesystem order.
- The footer reports the SD card's free space, obtained from the FAT backend's
  `f_getfree` and converted to 254-byte blocks. CBM BASIC line numbers cap at
  63999, so block counts and the free-block total are clamped to that value.

The number of entries is bounded (`MAX_DIR_ENTRIES`, 144, matching the classic
1541) to keep the synthesized program within the PET's BASIC RAM.

### Rendering

The byte-level formatting lives in `fw/src/tape_dir.c` (`tape_dir_render`),
which is a pure function with no SPI or filesystem dependencies, so it is unit
tested directly (`fw/test/tape_dir_test.c`). `tape.c` gathers the entries
(`readdir` + `stat` for sizes, then sort), queries `sd_free_bytes()`, calls
`tape_dir_render` (which converts the free bytes to CBM blocks), and streams
the result to SRAM.

## Gateware Changes

**None required.** This approach reuses the existing breakpoint infrastructure
which relies on the FPGA's halt mechanism (triggered by the `STP` opcode).

## Firmware Implementation Summary

### New Files

- `fw/src/tape.h` - Public interface
- `fw/src/tape.c` - Implementation
- `fw/src/tape_dir.h` / `fw/src/tape_dir.c` - Directory listing renderer
  (pure function, unit tested in `fw/test/tape_dir_test.c`)

### Tape Configuration Blob

All ROM-specific addresses are encoded as a single packed struct that maps
directly to a hex string in `config.yaml`. The struct contains the LD210
address (where the stub jumps after printing), the breakpoint address, and
the zero page locations the MCU reads/writes. At runtime, the MCU builds a
print loop, appends a `JMP ld210`, and writes the message (see
[Step 5](#step-5-write-stub-to-tape-buffer)):

```c
typedef struct __attribute__((packed)) {
    // KERNAL post-load fixup address (2 bytes, little-endian).
    // The stub jumps here after printing FOUND/LOADING. LD210 prints
    // "READY.", copies EAL/EAH into VARTAB, relinks BASIC lines,
    // clears variables, and enters the main loop.
    uint16_t ld210;

    // Breakpoint address (2 bytes, little-endian).
    // Set at the LOAD dispatch point: JSR LD15 (ROM 2/4) or LDA FA
    // (ROM 1). FNLEN/FNADR/FA are set up and the stack is clean.
    uint16_t bp_addr;

    // Zero page locations (5 bytes)
    // These vary by ROM version. The MCU reads/writes them to access
    // the filename, end address, and device number in PET memory.
    uint8_t eal;        // ZP addr of EAL (end address low)
    uint8_t eah;        // ZP addr of EAH (end address high)
    uint8_t fnlen;      // ZP addr of FNLEN (filename length)
    uint8_t devnum;     // ZP addr of DEVNUM (device number)
    uint8_t fnadr;      // ZP addr of FNADR (filename pointer)
} tape_config_t;        // 9 bytes total
```

The tape buffer address ($027A) is the same across all ROMs and is a
compile-time constant:

```c
#define TAPE_BUFFER 0x027A
```

#### ROM 4 Example

```
Offset  Bytes     Field    Value    Meaning
------  --------  -------  -------  ---------------------------
 0..1   2E F4     ld210    $F42E    KERNAL post-load fixup
 2..3   15 F4     bp_addr  $F415    JSR LD15 (LOAD dispatch)
 4      C9        eal      $C9      ZP: End address low
 5      CA        eah      $CA      ZP: End address high
 6      D1        fnlen    $D1      ZP: Filename length
 7      D4        devnum   $D4      ZP: Device number
 8      DA        fnadr    $DA      ZP: Filename pointer
```

`config.yaml` hex string: `"2ef415f4c9cad1d4da"`

#### ROM 1 Example

```
Offset  Bytes     Field    Value    Meaning
------  --------  -------  -------  ---------------------------
 0..1   E5 F3     ld210    $F3E5    KERNAL post-load fixup
 2..3   62 F3     bp_addr  $F362    LDA FA (inline dispatch)
 4      E5        eal      $E5      ZP: End address low
 5      E6        eah      $E6      ZP: End address high
 6      EE        fnlen    $EE      ZP: Filename length
 7      F1        devnum   $F1      ZP: Device number
 8      F9        fnadr    $F9      ZP: Filename pointer
```

`config.yaml` hex string: `"e5f362f3e5e6eef1f9"`

### State Structure

```c
typedef struct {
    tape_config_t cfg;      // Parsed from config.yaml hex blob
    bool enabled;           // Virtual tape enabled (config had 'tape' key)
    uint8_t saved_buf[192]; // Original tape buffer contents
} tape_state_t;
```

### Public Interface

```c
// Initialize with config blob from config.yaml. If cfg is NULL, virtual
// tape is disabled and all LOADs go to the physical datasette.
void tape_init(const tape_config_t* cfg);

void tape_task(void);       // Process pending loads (call from main loop)
void tape_deinit(void);     // Remove breakpoint
```

## Testing

### Unit Tests

1. **Filename matching**: Test wildcard patterns against various filenames
2. **PETSCII conversion**: Verify correct ASCII conversion for filesystem ops
3. **PRG parsing**: Test reading load address and program data

### Integration Tests

1. **Basic load**: `LOAD "TEST"` loads `/sd/prgs/test.prg`
2. **Empty name**: `LOAD`, `LOAD ""`, and `LOAD "*"` falls through to physical datasette
3. **Prefix match**: `LOAD "GA*"` loads "game.prg"
4. **No match**: `LOAD "NOEXIST"` falls through to tape polling
5. **BASIC execution**: Loaded program runs correctly (line links valid)
6. **Variables cleared**: No stale data from previous programs

### Manual Testing

1. Copy test PRG files to `/sd/prgs/`
2. Boot PET, type `LOAD "filename"`
3. Verify program loads and `LIST` shows correct line numbers
4. Run program to verify execution

## ROM Compatibility

Every address used by the virtual tape drive (zero page variables, BASIC
routines, and the KERNAL LOAD dispatch point) moves between ROM versions.
The PET KERNAL jump table at `$FFC0`+ is stable across all versions, but it
only covers I/O vectors (OPEN, CLOSE, LOAD, SAVE, etc.). The routines we
need (LD210, the LOAD dispatch) are internal routines with no stable vectors.

### Address Table

All addresses below are derived from [memorymap-gen.csv](PET/memorymap-gen.csv):

| Symbol | ROM 1.0 | ROM 2.0 | ROM 4.0 | Description |
|---|---|---|---|---|
| TXTTAB | $7A | $28 | $28 | ZP: Start of BASIC program |
| VARTAB | $7C | $2A | $2A | ZP: Start of variables |
| EAL | $E5 | $C9 | $C9 | ZP: End address low |
| EAH | $E6 | $CA | $CA | ZP: End address high |
| FNLEN | $EE | $D1 | $D1 | ZP: Filename length |
| DEVNUM | $F1 | $D4 | $D4 | ZP: Device number |
| FNADR | $F9 | $DA | $DA | ZP: Filename pointer |
| READY | $C38B | $C389 | $B3FF | BASIC warm start (READY prompt) |
| LINKPRG | $C433 | $C442 | $B4B6 | Rechain BASIC line pointers |
| RSTXCLR | $C567 | $C572 | $B5E9 | Reset TXTPTR and CLR |
| LD210 | $F3E5 | $F3EF | $F42E | Post-load fixup (prints READY, sets VARTAB) |
| CSTE1 | $F83B | $F812 | $F857 | Press-play routine entry |
| bp_addr | $F362 | $F3D6 | $F415 | Breakpoint: LOAD dispatch (see above) |

### Configuration via `config.yaml`

Since none of these addresses have stable vectors, the correct values must be
provided per configuration. The `config.yaml` already has a per-config `set`
action. We extend it with a `tape` key whose value is a hex string encoding
the `tape_config_t` blob (see [Firmware Implementation Summary](#firmware-implementation-summary)):

```yaml
configs:
  - name: "PET 40xx (40 Col 60 Hz)"
    setup:
      - action: "load"
        # ... ROM files ...
      - action: "set"
        usb-keymap: "/ukm/us.bin"
        video-ram-kb: 1
        tape: "2ef415f4c9cad1d4da"
```

Pre-computed blobs for each ROM version:

| ROM Version | Hex Blob (9 bytes) |
|---|---|
| ROM 4.0 | `2ef415f4c9cad1d4da` |
| ROM 2.0 | `eff3d6f3c9cad1d4da` |
| ROM 1.0 | `e5f362f3e5e6eef1f9` |

When the `tape` key is present, the firmware casts the decoded bytes to
`tape_config_t` and enables the virtual tape drive. When absent, the virtual
tape drive is disabled (all LOADs go to the physical datasette).

This makes ROM compatibility explicit and per-config without requiring
auto-detection. Custom or patched ROMs can supply their own blob.

## Limitations

- Only supports `.prg` files (not `.tap` tape images)
- No VERIFY support (would require different interception point)
- No SAVE support (separate feature)
- Single directory (`/sd/prgs/`) - no subdirectory navigation
- `LOAD "$"` lists at most `MAX_DIR_ENTRIES` (144) files; only the plain `$`
  form is recognized (no `$0`, `$:pattern`, etc.)

## Future Enhancements

- Support subdirectories via special filename syntax
- IEEE-488 device emulation for disk-style commands
- SAVE to SD card

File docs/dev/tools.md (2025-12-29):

# Tools

## PCB Design

* [KiCad](https://www.kicad.org/)
  * [JLC2KiCadLib](https://github.com/TousstNicolas/JLC2KiCad_lib)
  * [KiCAD JLCPCB tools](https://github.com/Bouni/kicad-jlcpcb-tools)
  * [Fabrication Toolkit](https://github.com/bennymeg/JLC-Plugin-for-KiCad)
* [Freerouting](https://github.com/freerouting/freerouting/releases)
  * `winget install -e --id EclipseAdoptium.Temurin.17.JRE`
* [LTSpice](https://www.analog.com/en/design-center/design-tools-and-calculators/ltspice-simulator.html)
  * [Parts](https://www.diyaudio.com/community/threads/a-large-free-ltspice-model-library.360086/)
* Online calculators
  * [Ohm's Law](https://www.calculatorology.com/ohms-law-calculator/)
  * [VIA Size Calculator](https://j.mp/via-calc)
  * [VIA Size Calculator](http://circuitcalculator.com/wordpress/2006/03/12/pcb-via-calculator/)
  * [LM317 Calculator](https://circuitdigest.com/calculators/lm317-resistor-voltage-calculator)
  * [Switch Debounce Calculator](https://clisystems.com/tool_debounce.php)
  * [Trace Width Calculator](https://www.digikey.com/en/resources/conversion-calculators/conversion-calculator-pcb-trace-width)
  * [Trace Width Calculator](http://circuitcalculator.com/wordpress/?p=25/)
  * [Trace Impedance Calculator](https://www.eeweb.com/tools/edge-coupled-microstrip-impedance/)
  * [Parallel Resistor Calculator](https://www.qsl.net/in3otd/parallr.html)
* JLCPCB
  * [Capabilities](https://jlcpcb.com/capabilities/Capabilities)
  * [Parts Search](https://jlcpcb.com/parts/all-electronic-components) ([Alt](https://yaqwsx.github.io/jlcparts/#/))
  * [DFM Analysis](https://jlcdfm.com/)

## RP2040

* [Debug Probe Firmware](https://www.raspberrypi.com/documentation/microcontrollers/debug-probe.html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)

## FPGA & Verilog

* [Efinity IDE](https://www.efinixinc.com/support/efinity.php)
  * Requires [Visual C++ Redistributable](https://aka.ms/vs/17/release/vc_redist.x64.exe)
* [Icarus Verilog](http://bleyer.org/icarus/)
* [GtkWave](https://sourceforge.net/projects/gtkwave/files/)
* [Timing Constraints Visualizer](https://juj.github.io/gowin_fpga_code_generators/timing_constraints.html)

## Logic Analyzer

* [PulseView](https://www.sigrok.org/wiki/Downloads) for [HiLetgo 8Ch Logic Analyzer](https://www.amazon.com/dp/B077LSG5P2)
  * Install WinUSB driver with [ZaDig](https://zadig.akeo.ie/) for device 0925 3881
* [KingstVIS](http://www.qdkingst.com/en/download) for [LA1010 16Ch Logic Analyzer](https://www.amazon.com/dp/B07D21GG6J)

## Drawing

* [Diagrams.net](https://app.diagrams.net/)
* [WaveDrom](https://wavedrom.com/editor.html)
  * [asciiwave](https://github.com/Wren6991/asciiwave)

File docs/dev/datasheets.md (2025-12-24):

# Datasheets

## 6502 CPU

* [Western Digital W65C02S](https://www.westerndesigncenter.com/wdc/documentation/w65c02s.pdf)

## 6520/6521 PIA

* [Western Digital W65C21](https://www.westerndesigncenter.com/wdc/documentation/w65c21.pdf)
* [Rockwell R6520](http://archive.6502.org/datasheets/rockwell_r6520_pia.pdf)

## 6522 VIA

* [Western Digital W65C22](https://www.westerndesigncenter.com/wdc/documentation/w65c22.pdf)

## 6545 CRTC

* [Rockwell R6545](http://archive.6502.org/datasheets/rockwell_r6545-1_crtc.pdf)

## SRAM

* [AS6C1008](https://www.alliancememory.com/wp-content/uploads/AS6C1008_Mar_2023V1.2.pdf)
* [IS61WV1288EEBLL](https://www.issi.com/WW/pdf/61-64WV1288EEBLL.pdf)

## MCU

* [RP2040](https://datasheets.raspberrypi.com/rp2040/rp2040-datasheet.pdf)
* [ARM PrimeCell Synchronous Serial Port (PL022)](https://developer.arm.com/documentation/ddi0194/h/introduction/about-the-arm-primecell-ssp--pl022-)

## IEEE

* [MC3446](http://pdf.datasheetcatalog.com/datasheets/400/501349_DS.pdf) Original IEEE-488 Bus Transceiver
* [Card Edge Connector](https://files.edac.net/edac/content/305/305-024-500-501%20-%20EDAC%20Card%20Edge%20Connector.PDF)

## Other

* [SN74LVC4245A](https://www.ti.com/lit/ds/symlink/sn74lvc4245a.pdf) Octal Bus Transceiver and 3.3-V to 5-V Shifter
* TPS5430 3A Wide Input Range Step-Down Converter
  * [Datasheet](https://www.ti.com/lit/ds/symlink/tps5430.pdf)
  * [User's Guide](https://www.ti.com/lit/ug/slvu157a/slvu157a.pdf)
  * [Application Report](https://www.ti.com/lit/an/slva237c/slva237c.pdf)
  * [ROHM Layout Guide](https://fscdn.rohm.com/en/products/databook/applinote/ic/power/switching_regulator/converter_pcb_layout_appli-e.pdf)
* [TLV1117LV](https://www.ti.com/lit/ds/symlink/tlv1117lv.pdf) MLCC compatible LDO
* Op Amps
  * [How to Bias Op Amps Correctly](https://www.renesas.com/en/document/apn/r13an0003-how-bias-op-amps-correctly)

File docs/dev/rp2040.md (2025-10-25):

# RP2040

## Debugprobe Firmware (formely Picoprobe)

Download 'debugprobe_on_pico.uf2' from [releases](https://github.com/raspberrypi/debugprobe/releases).

No drivers necessary on Windows 11, but for container development you will need [usbipd-win](https://learn.microsoft.com/en-us/windows/wsl/connect-usb):

```ps
winget install --interactive --exact dorssel.usbipd-win
```

Share the Debugprobe with WSL via:

```ps
# Older 'interface/picoprobe.cfg' is 2e8a:0004
# Newer 'interface/csmis-dap.cfp' is 2e8a:000c
sudo usbipd bind --hardware-id 2e8a:000c
usbipd attach --auto-attach --hardware-id 2e8a:000c --wsl
```

And add the following to your devcontainer.json:

```json
    "runArgs": [
        "--privileged",             // Required to access Picoprobe SWD from dev container
        "--device=/dev/ttyACM0"     // Expose Picoprobe URT to dev container
    ],
    
    // TODO: Figure out how to connect to Picoprobe as a non-root user.
    //       Maybe https://github.com/robotdad/piconotes?tab=readme-ov-file#setup-udev-rules-in-wsl?
    "remoteUser": "root"
```

## Notes

https://github.com/jfredine/wsl_pico_setup

## Oscillator

With a 1K resistor, YSX321SL requires XOSC workaround:

```cmake
# EconoPET 40/8096 Rev. A: xosc requires a little extra time to stabilize.
# On tested sample (45240-60), 8ms was intermittent and 16ms was reliable.
# 64ms provides a large tolerance.
target_compile_definitions(${PROJECT_NAME} PUBLIC PICO_XOSC_STARTUP_DELAY_MULTIPLIER=64)
```

Anecdotally, [this project](https://github.com/Swyter/psdaptwor/tree/master) claims that 100 ohm + 33pF is "known good".  (4-layer)

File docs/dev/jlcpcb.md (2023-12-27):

# JLCPCB

[PCB Capabilities](https://jlcpcb.com/capabilities/pcb-capabilities)

Property            | Value
--------------------|--------------------------
Thickness           | 1.6 mm
Dielectric constant | 4.5 (double-sided PCB)
Outer copper layer  | 1 oz/ft^2 (35 um / 0.035 mm)

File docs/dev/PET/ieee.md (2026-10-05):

# IEEE

## Signals

Name   | Description
-------|------------
DIO1-8 | Data Input/Output 1-8, used for transmitting and receiving data or commands.
EOI    | End Or Identify, indicates the last byte of a data transfer or is used in parallel polling.
DAV    | Data Valid, signals when data is ready on the data bus for reading.
NRFD   | Not Ready For Data, indicates that a device is not ready to accept data.
NDAC   | Not Data Accepted, signals that a device has not yet accepted the data.
IFC    | Interface Clear, used to initialize the bus and set all devices to a known state.
SRQ    | Service Request, indicates that a device requires attention from the controller.
ATN    | Attention, asserted only by the controller to gain attention and to denote address/control information on the data bus.
SHIELD | Ground shield for reducing electrical noise.
REN    | Remote Enable, allows the controller to set devices into remote or local mode.
GND    | Signal Ground, provides a reference point for all signals on the bus.

## Addresses

Outputs are captured on write
Inputs are intercepted on read

Chip | Address | Register | Bit | Pin   | Signal
-----|---------|----------|-----|-------|------------
PIA1 | E810    | ORA      |  0  | PA0   | KEY_A (Out)
PIA1 | E810    | ORA      |  1  | PA1   | KEY_B (Out)
PIA1 | E810    | ORA      |  2  | PA2   | KEY_C (Out)
PIA1 | E810    | ORA      |  3  | PA3   | KEY_D (Out)
PIA1 | E810    | PIBA     |  4  | PA4   | CASS1_SWITCH (In)
PIA1 | E810    | PIBA     |  5  | PA5   | CASS2_SWITCH (In)
PIA1 | E810    | PIBA     |  6  | PA6   | EOI (In)
PIA1 | E810    | PIBA     |  7  | PA7   | DIAG (In)
PIA1 | E811    | CRA      |  3  | CA2   | EOI (Out)
PIA2 | E820    | PIBA     | 0-7 | PA0-7 | DIO1-8 (In)
PIA2 | E821    | CRA      |  3  | CA2   | NDAC (Out)
PIA2 | E821    | CRA      |  7  | CA1   | ATN (In)
PIA2 | E822    | ORB      | 0-7 | PB0-7 | DIO1-8 (Out)
PIA2 | E823    | CRB      |  3  | CB2   | DAV (Out)
PIA2 | E823    | CRB      |  7  | CB1   | SRQ (In)
VIA  | E840    | IRB      |  0  | PB0   | NDAC (In)
VIA  | E840    | ORB      |  1  | PB1   | NRFD (Out)
VIA  | E840    | ORB      |  2  | PB2   | ATN (Out)
VIA  | E840    | ORB      |  3  | PB3   | CASS_WRITE (Out)
VIA  | E840    | ORB      |  4  | PB4   | CASS2_MOTOR (Out)
VIA  | E840    | IRB      |  5  | PB5   | VERT (In)
VIA  | E840    | IRB      |  6  | PB6   | NRFD (In)
VIA  | E840    | IRB      |  7  | PB7   | DAV (In)

REN is held permanently low by the PET
IFC is tied to RESB

### Virtual drive reset and status

Firmware-initiated PET resets reset DOS/channel state and flush the FPGA's IEEE
FIFOs before releasing the CPU, without ejecting mounted images. This is the
normal reset path used by the menu and long MENU-button hold.

Externally resetting only the CPU or MCU is a development edge case. The FPGA
still releases emulated IEEE lines while RES/IFC is asserted, but firmware-owned
peripheral state is not guaranteed to be coordinated. Power-cycle the board or
use a firmware-initiated reset for normal operation.

Status formatting follows the drive that produced the status. D64 images use
4040 behavior and report four fields, while D80 and `.hdd` images use 8050
behavior and report a fifth drive-number field. This also applies when a
dual-drive unit contains mixed image types. Power-on status follows drive 0,
or the sole mounted drive when drive 0 is empty. Therefore, D64 power-on status
is `73,CBM DOS V2,00,00`, while D80 and `.hdd` power-on status is
`73,CBM DOS V2.7,00,00,0`.

Channel-15 `I` and `V` commands use an explicit drive 0/1 when present and
otherwise retain the previous drive, matching the ROM's `SIMPRS`/`SETANY`
selection.

## ROM

PIA Addressing

Address | CRA (Bit 2) | CRB (Bit 2) | Read | Write
--------|-------------|-------------|------|-------
      0 |           1 |           x | PIBA | ORA
      0 |           0 |           x | DDRA | DDRA
      1 |           x |           x | CRA  | CRA
      2 |           x |           1 | PIBB | ORB
      2 |           x |           0 | DDRB | DDRB
      3 |           x |           x | CRB  | CRB

```
; cint1 Initialize I/O
...

; Configure PIA 1 Port B:
; PB0-3: KEYA-D (Select Key Row)
 E631   LDA #$0F
 E633   STA $E810 ; ORA = 0000_1111 (Key Row = F)
 
; Configures VIA Port B:
; PB0: NDAC (Input)
; PB1: NRFD (Output = 1)
; PB2: ATN  (Output = 1)
; PB3: CASS_WRITE (Output = 1)
; PB4: CASS2_MOTOR (Output = 1)
; PB5: VERT (Input)
; PB6: NRFD (Input)
; PB7: DAV (Input)
 E636   ASL       ; A = 0001_1110
 E637   STA $E840 ; ORB  = 0001_1110
 E63A   STA $E842 ; DDRB = 0001_1110

; Configure PIA 2 Port B
; PB0-7: DIO1-8
 E63D   STX $E822 ; ORB  = 1111_1111

; Configure VIA T1 High Order Counter
 E640   STX $E845 ; = FF

; 
 E643   LDA #$3D
 E645   STA $E813 ; CRB = 0011_1101
 E648   BIT $E812

 E64B   LDA #$3C
 E64D   STA $E821 ; CRA = 0011_1100
 E650   STA $E823 ; CRB = 0011_1100
 E653   STA $E811 ; CRA = 0011_1100
 E656   STX $E822 ; ORB = 1111_1111
 E659   LDA #$0E

; Send TALK Command on IEEE Bus
 F0D2 LDA #$40
 F0D4 BIT $20A9 ; BIT used as 2-byte jump that skips LDA #$20 (A9 20)

; *** Resyncing ***
; Send LISTEN Command on IEEE Bus
 F0D5   LDA #$20

; TALK/LISTEN continue here
 F0D7   PHA
 F0D8   LDA $E840 ; VIA
 F0DB   ORA #$02
 F0DD   STA $E840 ; VIA
 F0E0   LDA #$3C
 F0E2   STA $E821
 F0E5   BIT $A0
 F0E7   BEQ $F0FA
 F0E9   LDA #$34
 F0EB   STA $E811
 F0EE   JSR $F109 ; - Send Data On IEEE Bus
 F0F1   LDA #$00
 F0F3   STA $A0   ; Flag: IEEE Bus-Output Char. Buffered
 F0F5   LDA #$3C
 F0F7   STA $E811
 F0FA   PLA
 F0FB   ORA $D4   ; Current Device Number
 F0FD   STA $A5   ; Buffered Character for IEEE Bus
 F0FF   LDA $E840 ; VIA
 F102   BPL $F0FF
 F104   AND #$FB
 F106   STA $E840 ; VIA
```

## Reference

* [Commodore Peripheral Bus](https://www.pagetable.com/?p=1018)
  * [Part 1: IEEE-488](https://www.pagetable.com/?p=1023)
  * [Part 2: The TALK/LISTEN Layer](https://www.pagetable.com/?p=1031)
  * [Part 3: The Commodore DOS Layer](https://www.pagetable.com/?p=1038)
* [PET and the IEEE488 Bus](http://www.primrosebank.net/computers/pet/documents/PET_and_the_IEEE488_Bus_text.pdf)
* [The Hewlett-Packard Interface Bus (HP-IB)](https://www.hp9845.net/9845/tutorials/hpib/)
* ROM Disassembly
  * [Kernal 4.0](https://www.zimmers.net/anonftp/pub/cbm/src/pet/pet_rom4_disassembly.txt)
  * [4040](https://github.com/mist64/cbmsrc/tree/master/DOS_4040)
  * [8250](https://github.com/mist64/cbmsrc/tree/master/DOS_8250)
* Datasheets
  * [Western Digital W65C21](https://www.westerndesigncenter.com/wdc/documentation/w65c21.pdf)
  * [Rockwell R6520](http://archive.6502.org/datasheets/rockwell_r6520_pia.pdf)
  * [Western Digital W65C22](https://www.westerndesigncenter.com/wdc/documentation/w65c22.pdf)

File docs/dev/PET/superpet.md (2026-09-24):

# SuperPET

## Memory Test

Memory tests are available in [testram9000.d80.gz](https://www.zimmers.net/anonftp/pub/cbm/pet/SuperPET/os9/testram9000.d80.gz):
  
* Mount as disk8/1
* Boot in 6809 mode
* Type `test.main`, `test.banks`, or `test.os9` from the Waterloo microSystems menu
* Use `edit` and `g README` to view the test instructions.

## OS-9

OS-9 path | IEEE device | Physical drive | REL file
---------:|:-----------:|:--------------:|:-----------
/d0       |           8 |              0 | OS9 DRIVE A
/d1       |           8 |              1 | OS9 DRIVE A
/d2       |           8 |              0 | OS9 DRIVE B
/d3       |           8 |              1 | OS9 DRIVE B

## References

* Hardware
  * [CommonPET](https://github.com/InsaneDruid/CommonPET/tree/main) replica of the SuperPET combo board.
  * MMU
    * [SuperPET OS/9 MMU](https://mikenaberezny.com/hardware/superpet/super-os9-mmu)
    * [Schematic](https://mikenaberezny.com/wp-content/uploads/2018/03/superos9-mmu-schematic-nils-eilers.pdf)
    * [Instructions](https://mikenaberezny.com/wp-content/uploads/2009/11/install-2-boards.txt)
  * 6702
    * [Patching Waterloo Disks](https://mikenaberezny.com/wp-content/uploads/2012/04/Waterloo-D64-Disk-Patches.pdf)
* Waterloo
  * [ROM Disassemblies](https://mikenaberezny.com/hardware/superpet/disassemblies/)
  * [Waterloo Languages on the SuperPET](https://mikenaberezny.com/hardware/superpet/waterloo-languages/)
* OS-9
  * [System Disk](https://mikenaberezny.com/wp-content/uploads/2009/11/os9-systemdisk.d80)
  * [OS-9 Operating System User's Guide](https://www.roug.org/retrocomputing/os/os9/os9guide.pdf)
  * [Commodore SuperPET MMU OS/9 Software Notes](https://retro-bobbel.de/zimmers/cbm/pet/SuperPET/os9/OS9_SW_Docs.pdf)

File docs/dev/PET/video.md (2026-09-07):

# Video

## Non-CRTC (9" monitor)

Thomas Skibo documented the Non-CRTC (9") video timings [here](https://github.com/skibo/attiny2313_petvid).

Some additional measurements from a 2001-32N (1979):

Signal | Frequency  | Period   | Width  | Polarity    | Source
-------|------------|----------|--------|-------------|-----------
Crystal| 16.007 MHz |        - |      - |         -   | I1 pin 1
CPU    | 1.0009 MHz |        - |      - |         -   | 6502 pin 37
HSync  | 15.63 KHz  |    64us  |   24us | Active High | Video pin 5 (consistent with 16.007 MHz / 1024 = 15.632 KHz)
VSync  | 60.12 Hz   | 16.64ms  | 1.28ms | Active Low  | Video pin 3 (consistent with 15.632 KHz / 260 lines = ~60.122 Hz)
Video  |          - |        - |      - | Active Low  | -

### EconoPET 9" timing override

The 9" mode overrides the CRTC register outputs to reproduce the timing
[documented by Thomas Skibo](https://github.com/skibo/attiny2313_petvid) as closely as is possible using the CRTC.  Conveniently, the math works out such that 1us = one 8-pixel character.

Register | Value | Description
---------|-------|-----------------------------------------------
 R0      |   63  | H_TOTAL = 8 MHz pixel clock / 8 pixel char / (64 chars - 1) = 15.625 KHz
 R1      |   40  | H_DISPLAYED = 40 columns
 R2      |   48  | H_SYNC_POS = 48 us into each line, 16 us before the next line
 R3[3:0] |   24  | H_SYNC_WIDTH = 24 us (EconoPET internally extends H_SYNC_WIDTH to 5 bits)
 R3[7:4] |   20  | V_SYNC_WIDTH = 20 scan-line lines (EconoPET internally extends V_SYNC_WIDTH to 5 bits)
 R4      |   31  | V_TOTAL = 15.625 KHz / ((33 rows - 1) * 8 lines per row) = 61.04 Hz
 R5      |    4  | V_LINE_ADJUST = 15.625 KHz / (33 rows * 8 lines per row + 5 lines) = 60.10 Hz
 R6      |   25  | V_DISPLAYED = 25 rows
 R7      |   28  | V_SYNC_POS = character-row position
 R9      |    7  | SCAN_LINE = 8 pixel character height (-1)

HSYNC is active high for 24 us every 64 us. The CRTC display-enable signal
starts 16 us after the internal HSYNC rising edge and lasts 40 us. The video
output pipeline adds approximately 1.9 us relative to the HORZ output
pipeline, producing a measured 17.8 us from HORZ rising edge to video data.
VSYNC is active low for 20 lines (1.28 ms), with a 260-line frame period of
16.64 ms (about 60.1 Hz).

The CRTC can position VSYNC only on an 8-line character-row boundary. R7=28
starts it at frame line 224, four lines after the measured line 220. This gives
24 blank lines before VSYNC and 16 after it, rather than the measured 20/20
split. VSYNC also changes at the line boundary, 48 us before HSYNC, rather than
the measured 5 us. R7=27 has the same four-line error in the opposite direction,
so R7=28 retains the existing closest CRTC configuration.

`video_crtc_timing_tb` verifies these timings under Verilator.

## CRTC

### Address decoding

Address decoding asserts the CRTC's CS line (Chip Select) for $E880-E8FF.
The CRTC has a single RS (Register Select) input that is tied to A0.

### Timing (CRTC)

Measurements from a North American 8032 (60 Hz) at power on:

Signal | Frequency  | Period   | Width  | Polarity    | Source
-------|------------|----------|--------|-------------|-----------
HSync  |     20 KHz |    50us  |   15us | Active Low  | Video pin 5
VSync  | 60.062 Hz  | 16.65ms  |  800us | Active Low  | Video pin 3
Video  |          - |        - |      - | Active High | -

`video_crtc_timing_tb` verifies these power-on timings and their original CRTC
counter positions.

## Reference

* non-CRTC
  * [Restoring the Early PET Computer 9" VDU](https://www.worldphaco.com/uploads/RESTORING%20THE%20%20PET%20COMPUTER%209.pdf)
  * [attiny2313_petvid](https://github.com/skibo/attiny2313_petvid)
  * [PET/CBM 4 State Machine](https://forum.vcfed.org/index.php?attachments/cbm4state-jpg.1251230/)
  * [PetVideoSim](https://github.com/skibo/PetVideoSim) ([VCDs](https://github.com/skibo/PetVideoSim/releases))
* CRTC
  * [Operation](http://www.6502.org/users/andre/hwinfo/crtc/crtc.html)
  * [Internals](http://www.6502.org/users/andre/hwinfo/crtc/internals/index.html)
  * [CRTC - BeebWiki](https://beebwiki.mdfs.net/CRTC)
  * [The Amstrad CPC CRTC 
Compendium](https://www.cpcwiki.eu/imgs/4/4a/ACCC1.8-EN.pdf)
  * [Wikipedia](https://en.wikipedia.org/wiki/Motorola_6845)
  * Register Values
    * [Spreadsheet](https://view.officeapps.live.com/op/view.aspx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)
    * [SJGray](https://github.com/sjgray/cbm-edit-rom/blob/master/docs/CRTC%20Registers.txt)
  * [Reverse Engineering](https://stardot.org.uk/forums/viewtopic.php?t=22008)
  * [Part Info](https://www.amiga-stuff.com/hardware/crtc.html)
  * Datasheet
    * [Motorolla MC6845](https://archive.org/details/bitsavers_motorolada_1431515/page/n9/mode/2up)
    * [Motorolla AN-851](https://archive.org/details/bitsavers_motorolaapaMC6845CRTCSimplifiesVideoDisplayControl_9722748/mode/2up)
    * [Rockwell R6545](http://archive.6502.org/datasheets/rockwell_r6545-1_crtc.pdf)
    * [C6845 CRT Controller IP](https://colorcomputerarchive.com/repo/Documents/Datasheets/SY6845E-C6845%20CRT%20Controller%20(CAST).pdf)
    * [DB6845 CRTC IP](https://www.digitalblocks.com/files/DB6845-DS-V1_1.pdf)
* VGA
  * [VGA Timings](http://martin.hinner.info/vga/timing.html)
  * [TinyVGA Timings](http://www.tinyvga.com/vga-timing)
* DVI
  * [CEA-861-D](https://ia903002.us.archive.org/1/items/CEA-861-D/CEA-861-D.pdf)
* NTSC / PAL
  * [Timing Characteristics](http://www.kolumbus.fi/pami1/video/pal_ntsc.html)

## Tools

* [VGA Timing Calculator](https://www.epanorama.net/faq/vga2rgb/calc.html)
* [Pixel Clock Calculator](https://www.monitortests.com/pixelclock.php)
* [Hunter](https://gitlab.com/rabenauge/hunter/)

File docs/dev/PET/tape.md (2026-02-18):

# Tape

The Commodore PET supports two cassette drives (Cassette #1 and Cassette #2) for loading and saving programs. The PET Datasette (C2N) is a simple audio cassette mechanism with no intelligence of its own. All encoding, decoding, and motor control are performed by the PET's KERNAL software using the PIA and VIA I/O chips.

## Signals

Signal         | Chip | Address | Register | Bit | Direction | Description
---------------|------|---------|----------|-----|-----------|----------------------------------
CASS1_SWITCH   | PIA1 | E810    | PIBA     |  4  | In        | Cassette #1 sense (0 = key pressed, 1 = no key pressed)
CASS2_SWITCH   | PIA1 | E810    | PIBA     |  5  | In        | Cassette #2 sense (0 = key pressed, 1 = no key pressed)
CASS1_READ     | PIA1 | E811    | CRA      |  7  | In (CA1)  | Cassette #1 read data
CASS1_MOTOR    | PIA1 | E811    | CRA      |  3  | Out (CA2) | Cassette #1 motor (0 = On, 1 = Off)
CASS_WRITE     | VIA  | E840    | ORB      |  3  | Out       | Cassette write signal
CASS2_MOTOR    | VIA  | E840    | ORB      |  4  | Out       | Cassette #2 motor (0 = On, 1 = Off)

## Sense Pin

The cassette sense pin (PIA1 PA4 for Cassette #1) reflects the physical state of the cassette deck's mechanical switches. It is active-low: bit 4 reads 0 when a key is pressed, and 1 when no key is pressed.

The sense pin is asserted (driven low) whenever the user presses the PLAY, REW (rewind), or F.FWD (fast forward) keys on the Datasette. The KERNAL does not distinguish which key was pressed. It only checks whether any transport key is currently held down.

The STOP/EJECT key is mechanical only and releases all other keys, which causes the sense pin to go inactive (high).

## Loading a Program

When the user types `LOAD "program"`, the following sequence occurs:

1. BASIC calls the KERNAL LOAD routine, which opens Cassette #1 as the default tape device (device 1).

2. The KERNAL displays:

   ```text
   PRESS PLAY ON TAPE
   ```

3. The KERNAL enters a loop polling PIA1 PA4 (the sense pin), waiting for it to go low. The tape mechanism is idle at this point because the motor is off. The user must physically press the PLAY key on the Datasette.

4. Once the sense pin goes low, the KERNAL turns the motor on by clearing the CA2 output on PIA1 (setting CRA bit 3 to drive CA2 low). The tape begins moving.

5. The KERNAL reads data from the tape via the CA1 input on PIA1. Each pulse edge on the read line triggers an interrupt (or is polled), and the KERNAL measures the time between transitions to decode the bit stream. The PET tape format encodes data as pairs of pulses with varying periods to represent 0 and 1 bits.

6. The KERNAL searches for a tape header that matches the requested filename. If the header does not match, it continues searching. If the header matches, the KERNAL displays:

   ```text
   FOUND "program"
   LOADING
   ```

7. The KERNAL reads the program data into memory.

8. When the load is complete (or on error), the KERNAL turns the motor off by setting CA2 high. The tape stops.

## Motor Control

The KERNAL controls the Cassette #1 motor through the CA2 output of PIA1 (active-low: 0 = motor on, 1 = motor off). Cassette #2 motor is controlled via VIA PB4. The motor is only energized when the KERNAL is actively reading or writing the tape. At all other times the motor is off, even if PLAY is held down.

Because the cassette mechanism has no fast-forward or rewind motor control from the PET, the REW and F.FWD operations are entirely mechanical and always run at full speed regardless of motor state.

## Tape Encoding

The PET uses a simple pulse-width encoding scheme:

- A short pulse pair represents a 0 bit.
- A long pulse pair represents a 1 bit.
- A medium pulse pair is used as a sync/marker.

Each byte is recorded twice on tape for error detection. The first copy is followed by an inter-record gap, then the second copy. During playback, the KERNAL compares both copies and reports a `?LOAD ERROR` if they disagree.

## Tape Data Format

A tape file consists of:

1. **Leader** - a series of sync pulses used by the KERNAL to lock onto the data rate.
2. **Header block** - contains the file type, start address, end address, and filename (up to 16 characters).
3. **Data blocks** - the file contents, broken into 192-byte blocks.
4. **Repeat** - the entire sequence (header and data) is recorded a second time for error correction.

## KERNAL Routines (ROM 4)

The following describes the tape-related KERNAL routines from the
[ROM 4 disassembly](https://www.zimmers.net/anonftp/pub/cbm/src/pet/pet_rom4_disassembly.txt).

### Jump Table Entry Points

Address | Label  | Description
--------|--------|----------------------------------------------
FFD5    | load   | JMP $F401 (Perform [load])
FFD8    | save   | JMP $F6DD (Perform [save])
FFDB    | verify | JMP $F4F6 (Perform [verify])

### I/O Messages

The KERNAL stores tape-related messages in a table at $F000. Each message is
terminated by setting bit 7 of the final character.

Offset | Message
-------|-------------------
$41    | PRESS PLAY
$4D    | & RECORD
$56    | ON TAPE
$5F    | LOAD
$64    | WRITING
$6D    | VERIFY

### Zero-Page and Low-RAM Variables

Address | Label                | Description
--------|----------------------|---------------------------------------------------
$96     | ST                   | KERNAL I/O Status Word
$9D     | VERCK                | Flag: 0 = Load, 1 = Verify
$B2     | RITEFLAG             | Flag: Tape Byte-Received
$B7     | (temp)               | Bit counter (8 bits per byte)
$B9     | (temp)               | Pulse pair toggle (alternates 0/1)
$BD     | (temp)               | Block sequence indicator
$C0     | (index)              | Index to tape error log (pass 1)
$C1     | (index)              | Tape pass 2 error log index
$C2     | READFLAGS            | Tape read state: $00=scan, $0F=count, $40=load, $80=end
$C3     | SHORTCNT             | Checksum / seconds before tape write
$C7-C8  | BUFPTR               | Pointer: Tape buffer / screen scrolling
$C9-CA  | ENDADDR              | Tape end address / end of program
$CB     | TCON                 | Tape timing constant (adaptive)
$CE     | READTMR              | Tape read timer flag (IRQ enabled for Timer 1)
$D4     | DEVNUM               | Current device number (1 = Cassette #1, 2 = Cassette #2)
$D6-D7  | TAPBUF               | Pointer: Start of tape buffer
$DD     | CASSCHAR             | Cassette temp (current byte being read/written)
$DE     | BLKCNT               | Cassette read/write block count
$F9     | MOTORLOCK1           | Tape motor interlock #1 (Cassette #1)
$FA     | MOTORLOCK2           | Tape motor interlock #2 (Cassette #2)
$FB-FC  | IOSTART              | I/O start address

### Load Flow (F401)

The BASIC `LOAD` command enters the KERNAL at `$F401`:

```text
F401  verfyt   LDA #$00
F403           STA $9D          ; VERCK = 0 (Load, not Verify)
F405           JSR $F47D        ; slpara - Get Parameters For LOAD/SAVE
F408           JSR $F6CC        ; Set I/O start/end addresses from BASIC pointers
F40B           LDA #$FF
F40D  wait     CMP $9B          ; Wait for STOP key debounce
F40F           BNE wait
F411           CMP $9B
F413           BNE wait
F415           JSR $F356        ; Dispatch by device number
```

The dispatcher at `$F356` branches based on the device number (`$D4`):

- Device 0: syntax error
- Device 3: screen (syntax error)
- Device >= 4: IEEE-488 load (at `$F361`)
- Device 1-2: tape load (falls through to `$F3D4`)

### Tape Load Path (F3D4)

For tape devices, execution continues at `$F3D4`:

```text
F3D4           JSR $F695        ; Get Buffer Address (Cassette #1 or #2)
F3D7           JSR $F857        ; Print "PRESS PLAY ON TAPE"
F3DA           JSR $F449        ; Wait for STOP or sense
F3DD  search   LDA $D1          ; Length of Current File Name
F3DF           BEQ $F3E9        ; If empty name, accept any file
F3E1           JSR $F4D3        ; Read next header block, compare filename
F3E4           BNE $F3EE        ; Found match
F3E6           JMP $F5AD        ; File not found error
F3E9           JSR $F5E5        ; Read next header (any name)
F3EC           BEQ $F3E6        ; Error
F3EE           CPX #$01         ; Check file type (1 = relocatable program)
F3F0           BNE search       ; Not a program header, keep searching
F3F2           LDA $96          ; Check ST
F3F4           AND #$10
F3F6           BNE $F46C        ; Error
F3F8           JSR $F67B        ; Copy header addresses to I/O pointers
F3FB           JSR $F46D        ; Print "LOADING" or "VERIFYING" message
F3FE           JMP $F8A3        ; Enter main tape read loop
```

### Print "PRESS PLAY ON TAPE" (F857)

This routine prints the prompt and waits for the user to press a transport key:

```text
F857           JSR $F87A        ; Check Tape Status (test sense pin)
F85A           BEQ $F88B        ; Already pressed, return
F85C           LDY #$41
F85E           JSR $F185        ; Print "PRESS PLAY"
F861           LDY #$56
F863           JSR $F185        ; Print "ON TAPE "
F866           LDA $D4          ; Device number
F868           ORA #$30         ; Convert to ASCII digit
F86A           JSR $E202        ; Print device number
F86D  poll     JSR $F935        ; Check for STOP key
F870           JSR $F87A        ; Check Tape Status
F873           BNE poll         ; Loop until sense pin asserted
F875           LDY #$AA
F877           JMP $F185        ; Print CR and return
```

### Check Tape Status (F87A)

This routine tests the cassette sense pin for the active device:

```text
F87A           LDA #$10         ; Bit 4 mask (Cassette #1)
F87C           LDX $D4          ; Current Device Number
F87E           DEX
F87F           BEQ $F883        ; Device 1, use bit 4
F881           LDA #$20         ; Bit 5 mask (Cassette #2)
F883           BIT $E810        ; Test PIA1 Port A
F886           BNE $F88B        ; NZ = no key pressed (sense high)
F888           BIT $E810        ; Double-read for debounce
F88B           RTS              ; Z flag: 0 = pressed, 1 = not pressed
```

For Cassette #1, bit 4 of PIA1 Port A ($E810) is tested. For Cassette #2,
bit 5 is tested.

### Initiate Tape Read (F89A)

Sets up the tape system for reading a block:

```text
F89A           LDA #$00
F89C           STA $96          ; Clear ST
F89E           STA $9D          ; Clear verify flag
F8A0           JSR $F6AB        ; Set Buffer Start/End Pointers
F8A3           JSR $F92B        ; Check for STOP key / wait for tape ready
F8A6           JSR $F857        ; Print "PRESS PLAY ON TAPE"
F8A9           SEI
F8AA           LDA #$00
F8AC           STA $C2          ; Read flags = scan mode
F8AE           STA $CE          ; Clear read timer flag
F8B0           STA $CB          ; Clear timing constant
F8B2           STA $C0          ; Clear error log index (pass 1)
F8B4           STA $C1          ; Clear error log index (pass 2)
F8B6           STA $B2          ; Clear byte-received flag
F8B8           LDX $D4          ; Device number
F8BA           DEX
F8BB           BEQ $F8C4        ; Cassette #1
F8BD           LDA #$90
F8BF           STA $E84E        ; VIA IER: enable CB1 interrupt (Cass #2)
F8C2           BNE $F8C7
F8C4           INC $E811        ; PIA1 CRA: enable CA1 interrupt (Cass #1)
F8C7           LDX #$0E         ; IRQ vector index for tape read
F8C9           BNE $F8E0        ; Jump to Common Tape Code
```

### Common Tape Code (F8E0)

Shared setup for both read and write operations. Installs the appropriate IRQ
handler and turns on the motor:

```text
F8E0           JSR $FCE0        ; Set IRQ Vector (from table at $FD4C)
F8E3           LDA #$02
F8E5           STA $DE          ; Block count = 2 (each block recorded twice)
F8E7           JSR $FBC9        ; New Character Setup (reset bit counter)
F8EA           DEC $E813        ; PIA1 CRB: toggle motor control bit
F8ED           LDX $D4          ; Device number
F8EF           DEX
F8F0           BNE $F8FB        ; Not Cassette #1
F8F2           LDA #$34
F8F4           STA $E813        ; PIA1 CRB = $34: CA2 low = Motor ON (Cass #1)
F8F7           STA $F9          ; Set motor interlock #1
F8F9           BNE $F905
F8FB           LDA $E840        ; Read VIA Port B
F8FE           STX $FA          ; Set motor interlock #2
F900           AND #$EF         ; Clear bit 4 = Motor ON (Cass #2)
F902           STA $E840        ; Write VIA Port B
F905           LDX #$FF         ; Delay loop: let the motor spin up
F907  delay    LDY #$FF
F909  inner    DEY
F90A           BNE inner
F90C           DEX
F90D           BNE delay
F90F           STA $E849        ; Reset VIA Timer 2
F912           CLI              ; Enable interrupts, begin tape I/O
```

### Wait For Tape (F913)

After enabling interrupts, the KERNAL waits for the IRQ-driven tape routines
to complete:

```text
F913  waitlp   LDA #$E4
F915           CMP $91          ; Check if IRQ vector still points to tape handler
F917           BEQ $F92A        ; Done (vector restored to normal)
F919           JSR $F935        ; Check for STOP key
F91C           BIT $E813        ; Check PIA1 CRB (CA1 interrupt flag)
F91F           BPL waitlp       ; Loop while tape I/O in progress
F921           BIT $E812        ; Clear interrupt flag by reading PIA1 Port B
F924           JSR $F768        ; Update Jiffy Clock
F927           JMP waitlp
```

### Read Tape Bits (F976)

The core ISR for tape reading. Measures the time between pulses using VIA
Timer 2 and classifies each pulse as short (0), medium (sync), or long (1):

```text
F976           LDX $E849        ; Read VIA Timer 2 high byte
F979           LDY #$FF
F97B           TYA
F97C           SBC $E848        ; Subtract Timer 2 low byte
F97F           CPX $E849        ; Check for timer rollover
F982           BNE $F976        ; Retry if timer changed during read
F984           STX $CC          ; Save high byte
F986           TAX
F987           STY $E848        ; Reset Timer 2 low = $FF
F98A           STY $E849        ; Reset Timer 2 high = $FF
...
F998           LDA $CB          ; Tape Timing Constant (adaptive)
F99A           CLC
F99B           ADC #$3C         ; Threshold offset
...
F9A3           CMP $CC          ; Compare measured period
F9A5           BCS $F9F1        ; Short pulse (< threshold) = 0 bit
...
F9B4           ADC #$30         ; Next threshold
F9B6           ADC $CB
F9B8           CMP $CC
F9BA           BCS $F9D8        ; Medium pulse = sync marker
F9BC           INX
F9BD           ADC #$26         ; Next threshold
F9BF           ADC $CB
F9C1           CMP $CC
F9C3           BCS $F9DC        ; Long pulse = 1 bit
```

The adaptive timing constant (`$CB`) is continuously adjusted based on the
measured pulse widths, allowing the KERNAL to compensate for tape speed
variations.

### Store Tape Characters (FA9C)

After 8 bit-pairs are received, the assembled byte is stored and verified:

```text
FA9C           JSR $FBC9        ; New Character Setup (reset for next byte)
FA9F           STA $B2          ; Clear byte-received flag
...
FAFC           LDA $CF          ; End of tape marker?
FAFE           BEQ $FB0A
FB00           LDA #$04
FB02           JSR $FBC4        ; Set Status Bit (short block error)
FB05           LDA #$00
FB07           JMP $FB8B
FB0A           JSR $FD0B        ; Check if buffer pointer reached end address
FB0D           BNE $FB12        ; More data to store
FB0F           JMP $FB89        ; Block complete
FB12           LDX $BD          ; Block sequence (1st or 2nd copy)
FB14           DEX
FB15           BEQ $FB44        ; 2nd copy: verify against 1st
FB17           LDA $9D          ; Load or Verify?
FB19           BEQ $FB27        ; Load: store directly
FB1B           LDY #$00
FB1D           LDA $DD          ; Byte from tape
FB1F           CMP ($C7),Y      ; Compare with memory (verify mode)
FB21           BEQ $FB27
FB23           LDA #$01
FB25           STA $D0          ; Mark read error
FB27           LDA $D0          ; Check for errors
FB29           BEQ $FB77        ; No error, store byte
...
FB77           LDA $9D          ; Load or Verify?
FB79           BNE $FB81        ; Verify: skip store
FB7B           LDA $DD          ; Byte from tape
FB7D           LDY #$00
FB7F           STA ($C7),Y      ; Store to memory via buffer pointer
```

### Wind Up Tape I/O (FCC0)

Called when tape I/O is complete (or aborted). Disables tape interrupts and
stops the motor:

```text
FCC0           PHP
FCC1           SEI
FCC2           JSR $FCEB        ; Kill Tape Motor
FCC5           LDA #$7F
FCC7           STA $E84E        ; VIA IER: disable all VIA interrupts
FCCA           LDA #$3C
FCCC           STA $E811        ; PIA1 CRA: disable CA1 interrupt
FCCF           LDA #$3D
FCD1           STA $E813        ; PIA1 CRB: restore default
FCD4           LDX #$0C
FCD6           JSR $FCE0        ; Set IRQ Vector back to normal (keyboard scan)
FCD9           PLP
FCDA           RTS
```

### Kill Tape Motor (FCEB)

Turns off both cassette motors:

```text
FCEB           LDA #$3C
FCED           STA $E813        ; PIA1 CRB = $3C: CA2 high = Motor OFF (Cass #1)
FCF0           LDA $E840        ; Read VIA Port B
FCF3           ORA #$10         ; Set bit 4 = Motor OFF (Cass #2)
FCF5           STA $E840        ; Write VIA Port B
FCF8           RTS
```

### Motor Interlock (E47A, in Main IRQ)

The main IRQ handler (at `$E455`) includes a motor interlock that automatically
controls the motors based on the sense pins. This runs on every interrupt
(during keyboard scanning), independent of tape I/O:

```text
E47A           LDY #$00
E47C           LDA $E810        ; Read PIA1 Port A
E47F           AND #$F0         ; Isolate upper nibble (sense pins + EOI + DIAG)
E481           STA $E810        ; Write back (updates key scan outputs)
E484           LDA $E810        ; Re-read to get stable input
E487           ASL              ; Shift bit 4 (Cass #1 sense) into bit 5
E488           ASL              ; Shift into bit 6
E489           ASL              ; Shift into bit 7 (now in N flag)
E48A           BPL $E495        ; Branch if Cass #1 sense = 1 (no key pressed)
E48C           STY $F9          ; Key pressed: clear motor interlock #1
E48E           LDA $E813
E491           ORA #$08         ; Set CRB bit 3: CA2 forced high = motor OFF
E493           BNE $E49E
E495           LDA $F9          ; Motor interlock flag
E497           BNE $E4A1        ; If set, keep motor running
E499           LDA $E813        ;
E49C           AND #$F7         ; Clear CRB bit 3: CA2 forced low = motor ON
E49E           STA $E813
E4A1           BCC $E4AC        ; Now check Cassette #2 (carry from ASL chain)
E4A3           STY $FA          ; Key pressed: clear motor interlock #2
E4A5           LDA $E840        ; Read VIA Port B
E4A8           ORA #$10         ; Set bit 4 = motor OFF
E4AA           BNE $E4B5
E4AC           LDA $FA
E4AE           BNE $E4B8
E4B0           LDA $E840
E4B3           AND #$EF         ; Clear bit 4 = motor ON
E4B5           STA $E840
E4B8           JSR $E4BE        ; Continue to keyboard scan
```

When no transport key is pressed (sense high), the interlock turns the motor
off. When the tape I/O routines set the interlock flag (`$F9`/`$FA`), the
motor stays on regardless of the sense pin state. This prevents the motor
from turning off during brief sense pin glitches while tape I/O is active.

### Initiate Tape Write (F8CB)

Sets up the tape system for writing:

```text
F8CB           JSR $F6AB        ; Set Buffer Start/End Pointers
F8CE           JSR $F92B        ; Check for STOP key
F8D1           LDA #$14
F8D3           STA $C3          ; Leader duration (20 units)
F8D5           JSR $F88C        ; Print "PRESS PLAY & RECORD..."
F8D8           SEI
F8D9           LDA #$A0
F8DB           STA $E84E        ; VIA IER: enable Timer 2 interrupt
F8DE           LDX #$08         ; IRQ vector index for tape write leader
F8E0           (falls through to Common Tape Code)
```

### Write Tape Leader (FC99)

Writes the sync leader that precedes each data block:

```text
FC99           LDA #$78
FC9B           JSR $FBE1        ; Write sync pulse (medium length)
FC9E           BNE $FC83        ; Return from interrupt
FCA0           DEC $BD          ; Decrement leader pulse counter
FCA2           BNE $FC83        ; More leader pulses needed
FCA4           JSR $FBC9        ; New Character Setup
FCA7           DEC $C3          ; Decrement seconds counter
FCA9           BPL $FC83        ; More leader seconds needed
FCAB           LDX #$0A         ; Switch to data write IRQ handler
FCAD           JSR $FCE0        ; Set IRQ Vector
```

### Write Transition to Tape (FBD8)

Writes a single pulse to the tape by toggling VIA PB3 (CASS_WRITE):

```text
FBD8           LDA $DD          ; Current byte being written
FBDA           LSR              ; Shift out low bit
FBDB           LDA #$60         ; Short pulse duration (0 bit)
FBDD           BCC $FBE1
FBDF           LDA #$B0         ; Long pulse duration (1 bit)
FBE1           LDX #$00
FBE3           STA $E848        ; Load VIA Timer 2 low byte
FBE6           STX $E849        ; Load VIA Timer 2 high byte (start timer)
FBE9           LDA $E840        ; Read VIA Port B
FBEC           EOR #$08         ; Toggle bit 3 (CASS_WRITE)
FBEE           STA $E840        ; Write VIA Port B
FBF1           AND #$08         ; Check new state of CASS_WRITE
FBF3           RTS              ; (NZ = high, Z = low)
```

The timer values determine the pulse width: `$60` for a short pulse (0 bit)
and `$B0` for a long pulse (1 bit). The sync/leader uses `$78` (medium).

### Set IRQ Vector (FCE0)

Installs different IRQ handlers depending on the current tape operation phase:

```text
FCE0           LDA $FD4C,X      ; Load handler address low byte from table
FCE3           STA $90          ; Store to IRQ vector low byte
FCE5           LDA $FD4D,X      ; Load handler address high byte
FCE8           STA $91          ; Store to IRQ vector high byte
FCEA           RTS
```

The KERNAL switches between multiple IRQ handlers during tape operations.
The index (X register) selects the appropriate handler:

Index | Purpose
------|------------------------------
$08   | Write tape leader (FC99)
$0A   | Write data to tape (FBF4)
$0C   | Normal IRQ (keyboard scan, E455)
$0E   | Read tape bits (F976)
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

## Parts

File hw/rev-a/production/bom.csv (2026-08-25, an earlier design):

Designator | Footprint | Quantity | Value | LCSC Part #
C1, C100, C104, C106, C107, C13, C14, C2, C25, C27, C3, C33, C34, C35, C36, C37, C38, C40, C44, C45, C46, C47, C48, C49, C50, C51, C52, C53, C55, C57, C59, C67, C68, C69, C70, C71, C72, C73, C74, C78, C83, C90, C93, C94, C95, C96, C97, C98 | 0402 | 48 | 100n | C307331
C10, C81, C85, C9 | 0402 | 4 | 22n | C1532
C101, C102, C16, C28, C30, C8, C84 | 1206 | 7 | 47u 10V | C96123
C103, C19, C20, C39, C41, C42, C43, C80 | 0402 | 8 | 1u | C52923
C105 | 0603 | 1 | 47n | C1622
C11, C12, C15, C17 | 0805 | 4 | 22u | C45783
C18, C26 | 0603 | 2 | 10u | C96446
C21 | 0402 | 1 | 150p | C1527
C22, C54, C56, C58, C60, C61 | 0402 | 6 | 10n | C15195
C23, C31, C32, C62, C63, C64, C65, C66, C75, C76, C77, C79, C99 | 0402 | 13 | 4u7 10V | C23733
C24 | 0402 | 1 | 220n 16V | C16772
C29 | 0402 | 1 | 1n | C1523
C7 | CP_Radial_D16.0mm_P7.50mm | 1 | 4700uF 25V
C82 | 0603 | 1 | 68n | C31658
C86, C87 | 0402 | 2 | 33p | C1562
C88, C91, C92 | 0402 | 3 | 2u2 6.3V | C12530
C89 | CP_Radial_D24.0mm_P5.00mm_P7.50mm_P10.00mm_SnapIn | 1 | 120uF
D1, D12, D2, D3, D5 | D_SMA | 5 | SS54 | C22452
D10, D6, D8, D9 | 0603 | 4 | LED_RED | C2286
D11, D7 | 0603 | 2 | LED_GRN | C2986059
D13, D14 | D_SOD-323 | 2 | 1N4148WS | C2128
D4 | D_SOD-123F | 1 | SM4007 | C64898
FB1 | 0603 | 1 | 600 200ma | C1002
H1 | MountingHole_4mm_Pad | 1 | MountingHole_Pad
H2, H3, H4 | PET_MountingHole_4mm | 3 | MountingHole
J1 | CBM_PET_IEEE_EDGE_CON_24P | 1 | IEEE_EDGE
J10 | PinHeader_2x03_P2.54mm_Vertical | 1 | 5V PWR
J11 | PinHeader_1x02_P2.54mm_Vertical | 1 | 9V POWER
J12 | PinHeader_1x03_P2.54mm_Vertical_or_SolderJumper | 1 | VIDEO_OR_5V
J13 | BarrelJack_Horizontal | 1 | 9V POWER JACK
J14 | PinHeader_2x11_P2.54mm_Vertical | 1 | USER_HEADER
J15 | PinHeader_1x06_P2.54mm_Vertical | 1 | CASS_A_HEADER
J16 | PinHeader_1x06_P2.54mm_Vertical | 1 | CASS_B_HEADER
J17 | PMOD_Socket_2x06_P2.54mm_Horizontal | 1 | PMOD1
J18 | PMOD_Socket_2x06_P2.54mm_Horizontal | 1 | PMOD2
J19 | PinHeader_2x08_P2.54mm_Vertical | 1 | KEYBOARD_EX
J2 | CBM_PET_USER_EDGE_CON_24P | 1 | USER_EDGE
J20 | PinHeader_2x09_P2.54mm_Vertical | 1 | IEEE_HEADER
J21 | CUI_SJ-43504-SMT-TR | 1 | AUDIO
J22 | IDC-Header_2x08_P2.54mm_Vertical | 1 | PROG
J23 | PinHeader_1x02_P2.54mm_Vertical | 1 | MENU_HDR
J24 | HDMI_A_Molex_208658-1001_Horizontal | 1 | NOT_HDMI_A | C138388
J25 | TF-SMD_TF-PUSH | 1 | MICRO_SD | C393941
J26 | USB-C_SMD-TYPE-C-31-M-12 | 1 | USB1.1_HOST_TYPE_C | C165948
J27 | PinHeader_1x02_P2.54mm_Vertical | 1 | 6V POWER
J3 | CBM_PET_CASS_EDGE_CON_12P | 1 | CASS_A_EDGE
J4 | PinHeader_2x25_P2.54mm_Vertical | 1 | BUS_EXPANSION
J5 | CBM_PET_KEYBOARD_KEYED_20P | 1 | KEYBOARD
J6 | CBM_PET_CASS_EDGE_CON_12P | 1 | CASS_B_EDGE
J7 | PET_Video | 1 | VIDEO
J8 | PET_POWER_Molex_KK-396_A-41791-0009_1x09_P3.96mm_Vertical | 1 | PET POWER
J9 | PinHeader_2x10_P2.54mm_Vertical | 1 | FPGA_MCU
JP1 | SolderJumper-3_P1.3mm_Open_RoundedPad1.0x1.5mm | 1 | CASS A ~{SWITCH}
JP2 | SolderJumper-3_P1.3mm_Open_RoundedPad1.0x1.5mm | 1 | CASS B ~{SWITCH}
JP3 | SolderJumper-3_P1.3mm_Open_RoundedPad1.0x1.5mm | 1 | CASS A READ
JP4 | SolderJumper-3_P1.3mm_Open_RoundedPad1.0x1.5mm | 1 | CASS B READ
JP5 | SolderJumper-3_P1.3mm_Open_RoundedPad1.0x1.5mm | 1 | CASS A ~{MOTOR}
JP6 | SolderJumper-3_P1.3mm_Open_RoundedPad1.0x1.5mm | 1 | CASS B ~{MOTOR}
JP7 | SolderJumper-2_P1.3mm_Open_RoundedPad1.0x1.5mm | 1 | DVI_CEC
JP8 | SolderJumper-3_P1.3mm_Open_RoundedPad1.0x1.5mm | 1 | DVI_SDA
JP9 | SolderJumper-3_P1.3mm_Open_RoundedPad1.0x1.5mm | 1 | DVI_SCL
L1 | IND-SMD_L12.5-W12.5 | 1 | 22uH | C2924827
LS1 | AT1220TT9R | 1 | 42Ω SPK
Q1 | SOT-23 | 1 | MMBT3904 | C20526
Q2, Q3 | SOT-23_L2.9-W1.3-P1.90-LS2.4-BR | 2 | AO3401A | C15127
Q4, Q5, Q6 | SOT-23 | 3 | SS8050 | C2150
Q7 | SOT-23 | 1 | SS8550 | C8542
R1, R15, R2, R3, R4, R40 | 0402 | 6 | 4k7 | C25900
R10 | 0603 | 1 | 330 | C23138
R11 | 0402 | 1 | 300 | C25102
R12 | 0402 | 1 | 120 | C25079
R13 | 0402 | 1 | 220 | C25091
R14, R16, R18, R19, R20, R25, R32, R33, R39, R62, R66, R70 | 0402 | 12 | 10k | C25744
R17, R34, R35, R67, R69, R7 | 0402 | 6 | 1k5 | C25867
R21, R22, R23 | 0402 | 3 | 5k6 | C25908
R24, R28, R71 | 0402 | 3 | 100k | C25741
R26, R36 | 0402 | 2 | 12k | C25752
R27, R29, R41, R42, R43, R65, R74 | 0402 | 7 | 1k | C11702
R30, R31, R38 | 0402 | 3 | 470 | C25117
R37 | 0402 | 1 | 22k | C25768
R44, R45, R48, R49, R50, R51, R52 | 0402 | 7 | 2k2 | C25879
R46, R47 | 0603 | 2 | 27 | C25190
R5 | 0805 | 1 | 68 | C17802
R53, R54, R55, R56, R57, R58, R59, R60, R61 | 0603 | 9 | 270 | C22966
R6, R8 | 0603 | 2 | 0 | C21189
R63, R64 | 0402 | 2 | 56k | C25796
R68 | 0402 | 1 | 680 | C25130
R72, R73 | 0603 | 2 | 1 | C22936
R9 | 0402 | 1 | 5k1 | C25905
RN1, RN10, RN14, RN15, RN16, RN4, RN5, RN8, RN9 | R_Array_Convex_4x0603 | 9 | 10kx4 | C29718
RN11, RN12, RN13 | R_Array_Convex_4x0603 | 3 | 470x4 | C25510
RN2, RN3, RN6, RN7 | R_Array_Convex_4x0603 | 4 | 4k7x4 | C1980
SW1 | SW_PUSH_1P1T_6x3.5mm_H4.3_APEM_MJTP1243 | 1 | RESET
SW2 | SW_PUSH_1P1T_6x3.5mm_H4.3_APEM_MJTP1243 | 1 | NMI
SW3 | SW_DIP_SPSTx02_Slide_6.7x6.64mm_W7.62mm_P2.54mm_LowProfile_or_SolderJumper | 1 | CONFIG
SW4 | SW_PUSH_1P1T_6x3.5mm_H4.3_APEM_MJTP1243 | 1 | RUN
SW5 | APEM_MJTP1117 | 1 | MENU_BTN
SW6 | SW_PUSH_1P1T_6x3.5mm_H4.3_APEM_MJTP1243 | 1 | BOOTSEL
SYM3 | EconoPET_Model | 1 | SYM_Arrow_Small
U1 | DIP-40_W15.24mm_Socket | 1 | W65C02S
U10 | LQFP-144_20x20mm_P0.5mm | 1 | T20Q144C3 | C3278392
U11, U12 | DIP-40_W15.24mm_Socket | 2 | W65C21N
U13 | DIP-40_W15.24mm_Socket | 1 | W65C22N
U14, U15, U16 | SOIC-14_3.9x8.7mm_P1.27mm | 3 | SN74LS07 | C513513
U17, U18 | SOIC-20W_7.5x12.8mm_P1.27mm | 2 | 74LS245 | C129580
U19 | SOIC-16_3.9x9.9mm_P1.27mm | 1 | 74LS145 | C60829
U2 | DIP-32_W15.24mm_Socket | 1 | AS6C1008
U21 | LQFN-56_L7.0-W7.0-P0.4-EP | 1 | RP2040 | C2040
U22 | SOIC-8_5.23x5.23mm_P1.27mm | 1 | W25Q128JVS | C97521
U3 | SOT-223-3_TabPin2 | 1 | TLV1117LV33 | C15578
U4, U5 | TO-252-2 | 2 | LM317AG-TN3-R | C75510
U6 | TI_SO-PowerPAD-8_ThermalVias | 1 | TPS5430DDA | C9864
U7, U8, U9 | TSSOP-24_4.4x7.8mm_P0.65mm | 3 | SN74LVC4245APWR | C7859
Y1 | Crystal_SMD_3225-4Pin_3.2x2.5mm | 1 | 12 MHz | C9002

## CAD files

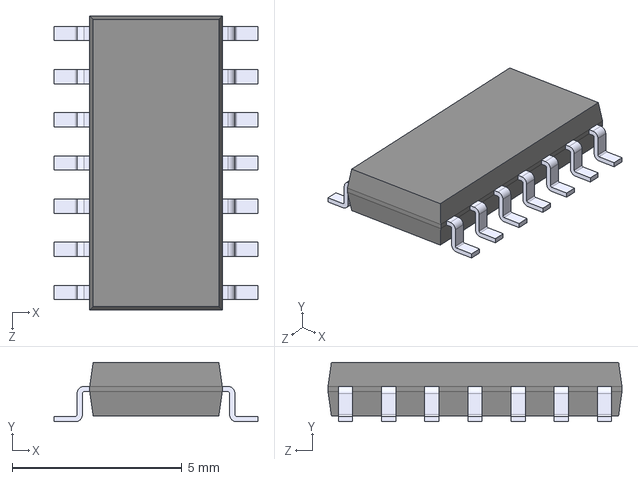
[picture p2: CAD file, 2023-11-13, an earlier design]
hw/rev-b/mainboard/kicad/SN74LS07DR.step
6.00 x 1.75 x 8.65 mm

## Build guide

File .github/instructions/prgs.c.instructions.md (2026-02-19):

---
description: 'C coding conventions for Commodore PET/CBM test and utility programs compiled with CC65'
applyTo: 'prgs/**/*.c, prgs/**/*.h, prgs/**/*.s'
---

# PET/CBM Program Guidelines

Example, utility, and test programs that run on the Commodore PET/CBM (WDC 65C02). Written in C, compiled with CC65 (`cl65 -t pet --cpu 65C02`), with inline or linked assembly where needed.

## File Header

```c
/* SPDX-License-Identifier: CC0-1.0 */
/* https://github.com/dlehenbauer/econopet */

/*
 * example.c -- One-line summary.
 *
 * Extended description of the test scenario or utility purpose.
 */
```

## Project Layout

Each program lives in its own subdirectory under `prgs/`. Name the subdirectory and main source file identically (e.g., `bp/bp.c`). Register new subdirectories in `prgs/CMakeLists.txt`. See `prgs/bp/CMakeLists.txt` for the build template.

## CC65-Specific C Conventions

- Prefer `unsigned char` over `int` for byte-sized values (CC65 generates far better code for 8-bit types)
- Declare counters and accumulators as `static` at file scope (CC65 generates more efficient code for statics than stack locals)
- Use `<conio.h>` (`cputs`, `cprintf`, `clrscr`) for text output, not `<stdio.h>` (`printf` pulls in a much larger runtime)
- Use `\r\n` for newlines in `cputs()`
- Use `PEEK()`/`POKE()` from `<peekpoke.h>` for direct memory access
- Use CC65/CA65 syntax (not ACME) for linked `.s` assembly files

## Test Program Pattern

1. Clear screen and print a banner identifying the test
2. Run each test case with a pass/fail check
3. Print a summary (`N/M passed`)

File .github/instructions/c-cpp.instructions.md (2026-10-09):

---
description: 'General C/C++ coding conventions for project code, including system integration tests'
applyTo: '**/*.c, **/*.cpp, **/*.cc, **/*.cxx, **/*.h, **/*.hpp, **/*.hh, **/*.hxx'
---

# C/C++ Development Guidelines

Apply these conventions to project-owned C/C++ sources and headers, including
firmware, shared test support, and system integration tests. Follow additional
target-specific instructions for toolchain and platform requirements. Do not
rewrite external dependencies to enforce these conventions.

## Build

- Build production with `RelWithDebInfo`.
- Build tests, simulator integration, frameworks, and their dependencies with
  `Debug`, including production sources compiled for tests.
- Compile Verilator-generated models and runtime separately with optimized
  `RelWithDebInfo` flags (Verilator `-O3`, C++ `-O3`, native CPU tuning, and LTO).
  Preserve debug symbols and SV assertions. Keep linked test, framework, and
  firmware sources in `Debug`. Do not propagate model flags or `NDEBUG` to them.
- Do not add Release builds or cross-configuration matrices, or undefine `NDEBUG`.

## Invariants and Test Expectations

- Prefer compile-time `static_assert` and `_Static_assert` checks when possible.
- Enforce production-required invariants with `vet()` from `fatal.h` and a
  useful diagnostic.
- Use `assert()` for sufficiently test-covered paranoid production checks
  (active in Debug tests, elided from production).
- Use GoogleTest `EXPECT_*`/`ASSERT_*` or Check `ck_assert_*` for expectations
  and helper checks within the respective framework.
- Keep required validation, work, and side effects outside assertions and
  `NDEBUG` guards.
- Fail stubs explicitly with useful diagnostics. Never return placeholders
  or succeed.

## Header File Conventions

- `#pragma once` must be the first non-comment line
- Never include `pch.h` from header files

## Source File Include Order

Include files in this order with blank lines between groups:

1. `pch.h` (when the target uses a precompiled header), followed by the corresponding header for this source file (when one exists)
2. Standard library headers `<...>` (alphabetized)
3. External headers (alphabetized, using the dependency's include style)
4. Project headers `"..."` (alphabetized)

Do not add a precompiled header to targets that do not use one.

### Good Example (With a Precompiled Header)

```c
#include "pch.h"
#include "my_module.h"

#include <stdbool.h>
#include <stdint.h>

#include "external/library.h"

#include "project/helper.h"
```

### Bad Example

```c
#include "project/helper.h"
#include <stdint.h>
#include "pch.h"  // Wrong: pch.h must be first when used
#include "my_module.h"
```

## Include Paths

- Use include-directory-relative paths: `#include "my_module.h"` or `#include "subdir/header.h"`
- Never use parent-relative paths like `../../pch.h`
- Configure the target's include directories instead of traversing the source tree in includes

## Const Correctness

- Default all variables, parameters, and pointers to `const` or `constexpr` when possible
- Use `const` pointee types (`const T *`) unless the pointed-to data is modified

## Enums and Constants

- Use enums for natural categories such as states, selections, and opcodes.
  Use `constexpr`, `const`, or `#define` for other constants. Do not group
  unrelated constants in an enum.

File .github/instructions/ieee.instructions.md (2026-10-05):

---
description: 'ROM-evidenced compatibility requirements for Commodore IEEE-488 disk-drive emulation'
applyTo: 'fw/src/ieee/**/*, fw/test/**/*ieee*, fw/test/**/*disk*, gw/**/*ieee*, docs/**/*ieee*'
---

# IEEE Drive Compatibility Instructions

Treat externally observable behavior of the virtual drive as a compatibility
contract with the original Commodore peripheral. Require primary-source
evidence for implementation decisions and code-review conclusions. Do not infer
behavior from the current EconoPET implementation or its tests.

## Compatibility Standard

For native Commodore behavior, require the implementation to match the relevant
4040 ROM or the selected 8050/8250 ROM revision and hardware mode in every
observable respect:

- command and secondary-address decoding
- TALK, LISTEN, UNTALK, UNLISTEN, OPEN, and CLOSE state transitions
- channel allocation, readiness, isolation, reuse, and teardown
- data bytes, byte ordering, EOI placement, EOF behavior, and repeated reads
- command-channel collection, termination, execution, and status clearing
- exact status numbers, text, punctuation, track, sector, and drive fields
- filename parsing, drive prefixes, wildcards, file types, and access modes
- directory byte stream, BASIC line structure, entries, free-block count, and
  final EOI
- D64 and D80 geometry, directory layout, BAM interpretation, sector links, and
  final-sector length
- REL record positioning, record lengths, side-sector behavior, overflow,
  read/write errors, and channel interaction
- reset, initialization, device addressing, dual-drive behavior, and per-unit
  state
- IEEE-488 electrical polarity, open-collector composition, handshake ordering,
  ATN behavior, and EOI timing

Treat a difference as a compatibility defect unless primary evidence proves it
belongs to the selected peripheral or ROM revision.

Extensions without an original-hardware counterpart, such as EconoPET's flat
`.hdd` container, must be explicitly labeled as extensions. Isolate them so
native D64/D80 and IEEE behavior remains unchanged.

## Source Priority

Use evidence in this order:

1. Relevant Commodore drive ROM source or disassembly.
2. Relevant PET KERNAL source for the controller side of the exchange.
3. Original manuals, schematics, datasheets, and captures from real hardware.
4. Established emulators and FPGA implementations as corroboration.
5. Existing EconoPET code and tests only as descriptions of current behavior.

Never use a secondary source to override the relevant Commodore ROM. When
sources disagree, identify the target model and ROM revision, follow the
primary source, and document the discrepancy.

## Primary ROM Sources

Use the exact files below. Start from `master` to understand composition, then
follow calls and constants through every routine that controls the changed
behavior.

### Commodore 4040 and D64 behavior

- Build/source index:
  [DOS_4040/master](https://github.com/mist64/cbmsrc/blob/master/DOS_4040/master)
- IEEE handshake, addressing, command-byte decoding, EOI, TALK, and LISTEN:
  [DOS_4040/ieee](https://github.com/mist64/cbmsrc/blob/master/DOS_4040/ieee)
- OPEN names, drive prefixes, file type/mode parsing, directory and direct
  channels:
  [DOS_4040/open](https://github.com/mist64/cbmsrc/blob/master/DOS_4040/open)
- CLOSE and channel teardown:
  [DOS_4040/close](https://github.com/mist64/cbmsrc/blob/master/DOS_4040/close)
- Read/write channel construction and channel state:
  [DOS_4040/opchnl](https://github.com/mist64/cbmsrc/blob/master/DOS_4040/opchnl)
- Command-channel parsing, dispatch, syntax, and termination:
  [DOS_4040/parsex](https://github.com/mist64/cbmsrc/blob/master/DOS_4040/parsex)
  and
  [DOS_4040/idle](https://github.com/mist64/cbmsrc/blob/master/DOS_4040/idle)
- Exact status numbers and strings:
  [DOS_4040/erproc](https://github.com/mist64/cbmsrc/blob/master/DOS_4040/erproc)
- Directory stream construction and final EOI:
  [DOS_4040/lstdir](https://github.com/mist64/cbmsrc/blob/master/DOS_4040/lstdir)
- File lookup and transfer:
  [DOS_4040/lookup](https://github.com/mist64/cbmsrc/blob/master/DOS_4040/lookup),
  [DOS_4040/getact](https://github.com/mist64/cbmsrc/blob/master/DOS_4040/getact),
  and
  [DOS_4040/trnsfr](https://github.com/mist64/cbmsrc/blob/master/DOS_4040/trnsfr)
- Block and memory commands:
  [DOS_4040/block](https://github.com/mist64/cbmsrc/blob/master/DOS_4040/block)
  and
  [DOS_4040/memrw](https://github.com/mist64/cbmsrc/blob/master/DOS_4040/memrw)
- REL behavior:
  [DOS_4040/record](https://github.com/mist64/cbmsrc/blob/master/DOS_4040/record),
  [DOS_4040/fndrel](https://github.com/mist64/cbmsrc/blob/master/DOS_4040/fndrel),
  [DOS_4040/rel1](https://github.com/mist64/cbmsrc/blob/master/DOS_4040/rel1),
  [DOS_4040/rel2](https://github.com/mist64/cbmsrc/blob/master/DOS_4040/rel2),
  [DOS_4040/rel3](https://github.com/mist64/cbmsrc/blob/master/DOS_4040/rel3),
  and
  [DOS_4040/rel4](https://github.com/mist64/cbmsrc/blob/master/DOS_4040/rel4)
- Geometry, constants, BAM, and disk initialization:
  [DOS_4040/equate](https://github.com/mist64/cbmsrc/blob/master/DOS_4040/equate),
  [DOS_4040/dskint](https://github.com/mist64/cbmsrc/blob/master/DOS_4040/dskint),
  and
  [DOS_4040/romtbl](https://github.com/mist64/cbmsrc/blob/master/DOS_4040/romtbl)

### Commodore 8050/8250 shared DOS source and D80 behavior

`DOS_8250` is the shared DOS 2.7 source base used by full-size 8050 and 8250
drives. The same main ROM can branch on the hardware's single-sided 8050 or
double-sided 8250 mode. It is not a universal source for earlier DOS 2.5
revisions, vendor-specific controller ROMs, or the later 8250LP.

Select the exact ROM revision and hardware mode before drawing a compatibility
conclusion. Use the corresponding DOS 8250 files whenever D80 geometry,
8050/8250 status, or model-specific behavior is involved. EconoPET's current
D80 path primarily targets single-sided 8050 behavior:

- [DOS_8250/master](https://github.com/mist64/cbmsrc/blob/master/DOS_8250/master)
- [DOS_8250/ieee](https://github.com/mist64/cbmsrc/blob/master/DOS_8250/ieee)
- [DOS_8250/open](https://github.com/mist64/cbmsrc/blob/master/DOS_8250/open)
- [DOS_8250/close](https://github.com/mist64/cbmsrc/blob/master/DOS_8250/close)
- [DOS_8250/opchnl](https://github.com/mist64/cbmsrc/blob/master/DOS_8250/opchnl)
- [DOS_8250/parsex](https://github.com/mist64/cbmsrc/blob/master/DOS_8250/parsex)
- [DOS_8250/erproc](https://github.com/mist64/cbmsrc/blob/master/DOS_8250/erproc)
- [DOS_8250/lstdir](https://github.com/mist64/cbmsrc/blob/master/DOS_8250/lstdir)
- [DOS_8250/block](https://github.com/mist64/cbmsrc/blob/master/DOS_8250/block)
- [DOS_8250/memrw](https://github.com/mist64/cbmsrc/blob/master/DOS_8250/memrw)
- [DOS_8250/record](https://github.com/mist64/cbmsrc/blob/master/DOS_8250/record)
- [DOS_8250/fndrel](https://github.com/mist64/cbmsrc/blob/master/DOS_8250/fndrel)
- [DOS_8250/rel1](https://github.com/mist64/cbmsrc/blob/master/DOS_8250/rel1)
- [DOS_8250/rel2](https://github.com/mist64/cbmsrc/blob/master/DOS_8250/rel2)
- [DOS_8250/rel3](https://github.com/mist64/cbmsrc/blob/master/DOS_8250/rel3)
- [DOS_8250/rel4](https://github.com/mist64/cbmsrc/blob/master/DOS_8250/rel4)
- [DOS_8250/equate](https://github.com/mist64/cbmsrc/blob/master/DOS_8250/equate)
- [DOS_8250/dskint](https://github.com/mist64/cbmsrc/blob/master/DOS_8250/dskint)
- [DOS_8250/map](https://github.com/mist64/cbmsrc/blob/master/DOS_8250/map)
- [DOS_8250/sidsec](https://github.com/mist64/cbmsrc/blob/master/DOS_8250/sidsec)

### PET controller-side behavior

PET ROM 1 and the uncorrected early ROM 2 IEEE input implementation are not
native compatibility targets. Cover the installed corrected PET KERNAL 2.0
image, grouped below as ROM 2/3, and PET KERNAL 4.0/4.1:

- PET KERNAL 2.0 reconstructed IEEE primitives:
  [KERNAL_PET_2.0_REC/ob1src](https://github.com/mist64/cbmsrc/blob/master/KERNAL_PET_2.0_REC/ob1src)
- PET KERNAL 2.0 reconstructed LOAD/OPEN, SAVE/CLOSE, and channel-I/O paths:
  [ob2src](https://github.com/mist64/cbmsrc/blob/master/KERNAL_PET_2.0_REC/ob2src),
  [ob3src](https://github.com/mist64/cbmsrc/blob/master/KERNAL_PET_2.0_REC/ob3src),
  and
  [ob4src](https://github.com/mist64/cbmsrc/blob/master/KERNAL_PET_2.0_REC/ob4src)
- PET KERNAL 4.0 reconstructed IEEE primitives and controller sequences:
  [KERNAL_PET_4.0_REC/ob1src](https://github.com/mist64/cbmsrc/blob/master/KERNAL_PET_4.0_REC/ob1src)

- IEEE send/receive primitives, TALK, LISTEN, UNTALK, UNLISTEN, secondary
  addressing, EOI, and handshakes:
  [KERNAL_PET_4.0_1979-10-23/ob1src](https://github.com/mist64/cbmsrc/blob/master/KERNAL_PET_4.0_1979-10-23/ob1src)
- LOAD and OPEN byte sequences:
  [KERNAL_PET_4.0_1979-10-23/ob2src](https://github.com/mist64/cbmsrc/blob/master/KERNAL_PET_4.0_1979-10-23/ob2src)
- SAVE and CLOSE byte sequences:
  [KERNAL_PET_4.0_1979-10-23/ob3src](https://github.com/mist64/cbmsrc/blob/master/KERNAL_PET_4.0_1979-10-23/ob3src)
- CHKIN/CHRIN and channel input behavior:
  [KERNAL_PET_4.0_1979-10-23/ob4src](https://github.com/mist64/cbmsrc/blob/master/KERNAL_PET_4.0_1979-10-23/ob4src)
- ROM 4 disk statement parsing, command construction, and public vectors:
  [dos.syntax](https://github.com/mist64/cbmsrc/blob/master/KERNAL_PET_4.0_REC/dos.syntax),
  [dos.write](https://github.com/mist64/cbmsrc/blob/master/KERNAL_PET_4.0_REC/dos.write),
  and
  [ob7src](https://github.com/mist64/cbmsrc/blob/master/KERNAL_PET_4.0_REC/ob7src)

Use "ROM 2/3" below only for the installed corrected KERNAL 2.0 image. It does
not mean that every early PET KERNAL has the same `ACPTR` implementation.

| ROM group | Address range | Part | ROM binary | MD5 |
|---|---|---|---|-----|
| ROM 2/3 KERNAL 2.0 | `$F000-$FFFF` | `901465-03` | [kernal-2.901465-03.bin](https://www.zimmers.net/anonftp/pub/cbm/firmware/computers/pet/kernal-2.901465-03.bin) | `51a38bfef8f9e72cb64bf7d874b4c8c6` |
| ROM 4 disk statements | `$D000-$DFFF` | `901465-21` | [basic-4-d000.901465-21.bin](https://www.zimmers.net/anonftp/pub/cbm/firmware/computers/pet/basic-4-d000.901465-21.bin) | `ab780e94772dca756a0678a17b5bc3a2` |
| ROM 4 KERNAL 4.0/4.1 | `$F000-$FFFF` | `901465-22` | [kernal-4.901465-22.bin](https://www.zimmers.net/anonftp/pub/cbm/firmware/computers/pet/kernal-4.901465-22.bin) | `16ec21443ea5431ab63d511061054e6f` |

Use the repository's generated
[PET memory map](../../docs/dev/PET/memorymap-gen.csv) as the authoritative
cross-version symbol map. Its `2.0` and `4.0` columns supply the two address
columns below. Preserve the map's case-sensitive names: `DOPEN` is the public
vector while `dopen` is the disk implementation; `STOP` is BASIC's statement
handler while `stop` is the KERNAL routine; `LIST4` and `list4` are unrelated
BASIC and IEEE labels. Reconstructed listings use uppercase names in separate
assembly units, so do not join them to this map by uppercasing symbol names.
The addresses, instruction boundaries, and behavior were then
checked against the
[PET2](https://github.com/ethandicks/cbmsymbols/blob/master/listings/PET2.txt)
and
[PET4](https://github.com/ethandicks/cbmsymbols/blob/master/listings/PET4.txt)
assembler listings, the
[8032 ROM 4 disassembly](https://www.zimmers.net/anonftp/pub/cbm/src/pet/pet_rom4_disassembly.txt),
and the installed binaries. Every listing byte present in the KERNAL 2 range
matched `901465-03`. Every listed byte in the ROM 4 `$D000` and `$F000` ranges
matched except the source placeholders at `CKSUMD` (`$DE9D`) and `CKSUMF`
(`$FD5C`), which contain generated checksum bytes in the installed images.
Source labels describe internal structure and are not automatically safe entry
points.

The dated 1979 KERNAL 4 source is not the final byte-level revision authority.
Its LOAD path calls `SECND` after TALK, while the reconstructed source and
installed `901465-22` call `TKSA` at `$F379`. The production path therefore
performs the talk-side receive-line setup before releasing ATN. No separate
KERNAL 4.1 F-ROM was found. The patched BASIC B-ROM still uses `901465-22`.

#### Callable IEEE transport entries

These routines directly manipulate PIA2 or VIA IEEE lines, or deliberately
enter the byte handshake. Use `ISOUR` and `ACPTR` for electrical handshake
tests. Use the addressing and termination entries for controller-sequence
tests.

| ROM 2/3 address | ROM 4 address | Source label or role | Entry evidence | Observable behavior and test relevance |
|---|---|---|---|---|
| `$E1DE` | `$E000` | `CINT`, editor-resident system initialization | The authoritative map names both entries. ROM 2/3 starts `A9 7F 8D 4E E8`. ROM 4 is editor-dependent and starts either the implementation or a jump to it. | Initializes system I/O including the IEEE-facing PIA and VIA registers. It is useful for full-machine startup, but it is outside the KERNAL ROM and is not a focused bus-reset primitive. |
| `$F0B6` | `$F0D2` | `TALK` | ROM 2/3 starts `A9 40 D0 02 A9 20`. ROM 4 starts `A9 40 2C A9 20`. Called by LOAD and CHKIN paths, and by ROM 4 `EREAD`. | Enters `LIST1` with the TALK base `$40`, combines it with `FA`, asserts ATN, and sends MTA. It does not send the secondary address. |
| `$F0BA` | `$F0D5` | `LISTN` | Both start `A9 20 48 AD 40 E8`. Called by OPEN, SAVE, CLOSE, CHKOUT, and ROM 4 command paths. | Enters `LIST1` with the LISTEN base `$20`, combines it with `FA`, asserts ATN, and sends MLA. |
| `$F0BC` | `$F0D7` | `LIST1`, command-byte sender | Both start `48 AD 40 E8 09 02 8D 40`. Called by `UNLSN`, and reached by `TALK`, `LISTN`, and `UNTLK`. | Releases the receive handshake lines, flushes a pending `CIOUT` byte with EOI when required, waits for DAV release, asserts ATN, and sends `A OR FA` through `ISOUR`. Use only with a valid base command in A and a valid `FA`. |
| `$F0EE` | `$F109` | `ISOUR`, physical byte output | Both start `A9 3C 8D 23 E8 AD 40 E8`. Called by `LIST1`, `SECND`, `TKSA`, and `CIOUT`. | Takes the logical byte in `BSOUR` and complements it for PIA2 output, waits for NRFD and NDAC, applies the VIA timer policy (with ROM 4's optional STOP-key retry), then releases DAV and DIO. This is the focused controller-output handshake. |
| `$F128` | `$F143` | `SECND` | ROM 2/3 starts `85 A5 20 EE F0 AD 40 E8`. ROM 4 starts `85 A5 20 09 F1 AD 40 E8`. Called by OPEN, SAVE, CLOSE, and CHKOUT. | Sends A as a listener secondary command through `ISOUR`, then falls into `SCATN` to release ATN. |
| `$F12D` | `$F148` | `SCATN`, release ATN | Both start `AD 40 E8 09 04 8D 40 E8`. Called by `SECND` and `TKATN`, and reached after UNLISTEN. | Sets VIA port-B bit 2 to release ATN. Use it for a focused ATN-polarity test, not as a complete address sequence. |
| `$F164` | `$F193` | `TKSA` | ROM 2/3 starts `85 A5 20 EE F0 20 46 F1`. ROM 4 starts `85 A5 20 09 F1 20 75 F1`. Called by CHKIN. ROM 4 LOAD and `EREAD` also call it. | Sends A as a talker secondary command, establishes controller-listener handshake state through `TKATN`, and releases ATN. |
| `$F169` | `$F198` | `TKATN` | ROM 2/3 starts `20 46 F1 4C 2D F1`. ROM 4 starts `20 75 F1 4C 48 F1`. Called by `TKSA` and by CHKIN for a negative secondary address. | Asserts NRFD, prepares PIA2 for input, and then jumps to `SCATN`. It is the correct talk-to-data transition entry. |
| `$F16F` | `$F19E` | `CIOUT`, buffered IEEE output | Both start `24 A0 30 04 C6 A0 D0 05`. Called by `BSOUT`, OPEN, and SAVE paths. | Buffers A in `BSOUR` and sends the previously buffered byte when required. The final pending byte is flushed with EOI by the next command or UNLISTEN. Do not expect one call to produce the current byte immediately. |
| `$F17F` | `$F1AE` | `UNTLK` | ROM 2/3 starts `A9 5F D0 02 A9 3F`. ROM 4 starts `AD 40 E8 29 FB 8D 40 E8`. Called by LOAD, `CLRCHN`, and ROM 4 status reads. | Sends `$5F`. ROM 2/3 enters `LIST1`, which releases NRFD and NDAC before asserting ATN. ROM 4 asserts ATN first, then enters the shared command path. Keep these termination-order tests separate. |
| `$F183` | `$F1B9` | `UNLSN` | ROM 2/3 starts `A9 3F EA EA 20 BC F0`. ROM 4 starts `A9 3F 20 D7 F0 D0 88`. Called by OPEN, SAVE, CLOSE, `CLRCHN`, and ROM 4 disk paths. | Sends `$3F` through `LIST1`, flushing a pending output byte with EOI first, then releases ATN through `SCATN`. |
| `$F18C` | `$F1C0` | `ACPTR`, physical byte input | Both start `A9 34 8D 21 E8 AD 40 E8`. Called by LOAD, `BASIN`, and ROM 4 `EREAD`. | Asserts NDAC, releases NRFD, waits for DAV, asserts NRFD, samples EOI and complemented DIO, releases NDAC, waits for DAV release, then re-arms NDAC while leaving NRFD asserted. This is the focused controller-input handshake. |
| `$F146` | `$F175` | `ER001`, receive-state setup/recovery | ROM 2/3 starts `AD 40 E8 29 FD 8D 40 E8`. ROM 4 has the same bytes. Both `TKATN` implementations call it with `JSR`. | Asserts NRFD and NDAC and returns CR in A. Does not release ATN. A valid prepared-state helper, also entered by receive-timeout handling. |

The transport routines merge status into `SATUS`/ST at `$96`: `$01` is an
output/listener timeout, `$02` is an input timeout, `$40` is EOI, and `$80` is
device not present. VERIFY sets `SATUS` to `$10` on a compare failure (it does not OR that bit into the previous status).

#### Callable KERNAL channel and file entries

These entries intentionally invoke the transport routines. They are valid
integrated tests, but they include file-table, parser, screen, cassette, and
error-message behavior that is unrelated to the electrical handshake.

| ROM 2/3 address | ROM 4 address | Source label or role | Entry evidence | Behavior and test relevance |
|---|---|---|---|---|
| `$F466` | `$F4A5` | `OPENI`, IEEE OPEN sender | ROM 2/3 starts `A5 D3 30 F5 A4 D1 F0 F1`. ROM 4 starts `A5 D3 30 F5 A4 D1 F0 F1`. Called by generic OPEN, LOAD, and SAVE. | With `FA`, `SA`, `FNLEN`, and `FNADR` prepared, sends MLA, `$F0 OR SA`, the filename through `CIOUT`, and UNLISTEN. This is the generic end-to-end OPEN transaction. |
| `$F2AE` | `$F2E2` | `CLOS5`/`FCLOSE`, close logical file in A | ROM 2/3 starts `20 8D F2 D0 4D 20 99 F2`. ROM 4 starts `20 C1 F2 D0 4D 20 CD F2`. Called by generic CLOSE. ROM 4 `DCLOSE` also jumps here. | Looks up the logical file, calls `CLSE1` for IEEE devices, and removes the table entry. |
| `$F6F0` | `$F72F` | `CLSE1`, IEEE CLOSE sender | ROM 2/3 starts `24 D3 30 78 20 BA F0 A5`. ROM 4 starts `24 D3 30 78 20 D5 F0 A5`. Called by CLOSE and after LOAD/SAVE. | If SA is nonnegative, sends MLA, `$E0 OR (SA AND $0F)`, and UNLISTEN. A negative SA deliberately suppresses the close command. |
| `$F322` | `$F356` | `LD15`, LOAD/VERIFY device dispatcher | ROM 2/3 starts `A5 D4 D0 03 4C 03 CE C9`. ROM 4 starts `A5 D4 D0 03 4C 00 BF C9`. Called by LOAD and the resident monitor. | For IEEE devices, sends OPEN, TALK, the secondary address, reads the two-byte load address and data through `ACPTR`, UNTALKs, and closes. ROM 2/3 uses `SECND` after TALK. ROM 4 uses `TKSA` and checks status before the second address byte. |
| `$F3C9` | `$F408` | `LOADNP`, load with prepared parameters | ROM 2/3 starts `20 8D F6 A9 FF C5 9B D0`. ROM 4 starts `20 CC F6 A9 FF C5 9B D0`. ROM 4 `DLOAD` jumps here. | Copies BASIC bounds, waits for the keyboard switch state, and calls `LD15`. Use this only when the LOAD parameters have already been prepared. |
| `$F6A1` | `$F6E0` | `SV3`, save with prepared parameters | ROM 2/3 starts `20 8D F6 A5 D4 D0 05 A0`. ROM 4 starts `20 CC F6 A5 D4 D0 05 A0`. ROM 4 `DSAVE` jumps here. | Copies BASIC bounds and falls into `SV5`. It is an integrated prepared-state entry, not an IEEE primitive. |
| `$F6A4` | `$F6E3` | `SV5`, SAVE device dispatcher | ROM 2/3 starts `A5 D4 D0 05 A0 74 4C 70`. ROM 4 starts `A5 D4 D0 05 A0 74 4C AF`. Called by SAVE and the resident monitor. | For IEEE devices, sends OPEN, MLA, secondary `$61`, the start address and data through `CIOUT`, then UNLISTENs and closes. |
| `$F770` | `$F7AF` | `CHKIN` | Both start `48 8A 48 98 48 A9 00 85`. Public vector `$FFC6`. | Selects logical file X. For IEEE input it sends TALK and the stored secondary address, then makes the device the default input. ROM 4 first invalidates cached `DS$`. |
| `$F7BC` | `$F7FE` | `CHKOUT`/`CKOUT` | Both start `48 8A 48 98 48 A9 00 85`. Public vector `$FFC9`. | Selects logical file X. For IEEE output it sends LISTEN and the stored secondary address, then makes the device the default output. ROM 4 first invalidates cached `DS$`. |
| `$F272` | `$F2A6` | `CLRCHN`/`CLRCH` | ROM 2/3 starts `A5 B0 C9 04 90 03 20 83`. ROM 4 starts `A5 B0 C9 04 90 03 20 B9`. Public vector `$FFCC`. | Sends UNLISTEN for an active IEEE output and UNTALK for an active IEEE input, then restores screen and keyboard defaults. |
| `-` | `$F563` | `OP94`, prepared generic OPEN | ROM 4 starts `A5 D2 F0 F6 A0 0E 20 C1`. Called by `DOPEN` and `APPEND`. | Validates prepared `LA`, `FA`, `SA`, `FNLEN`, and `FNADR`, installs the file-table entry, then reaches `OPENI` for IEEE. ROM 2/3 has equivalent inline code but no archived caller or source entry at its initial `LDA LA`. |

#### ROM 4 disk-statement and status entries

ROM 4's disk commands are not implemented in `901465-22`. The KERNAL adds
`JMP` trampolines at `$FF93-$FFBD`, but their implementations are in
`901465-21` at `$D000-$DFFF`. ROM 2/3 uses `$FF93-$FFBD` for resident-monitor
code and has none of these entries. The addresses below name the implementation
first and the public trampoline second.

| ROM 2/3 address | ROM 4 address | Source label or BASIC statement | Entry evidence | Command behavior and test relevance |
|---|---|---|---|---|
| `-` | `$DAC7` via `$FF93` | `CONCAT` | Starts `20 68 DC 20 1D D8 A0 22`. `$FF93` is `JMP $DAC7`. | Parses and sends `C<dest-drive>:<dest>=<dest-drive>:<dest>,<source-drive>:<source>` on command channel 15 through `TRANS`. |
| `-` | `$D942` via `$FF96` | `DOPEN` | Starts `20 68 DC 20 2E D8 29 22`. `$FF96` is `JMP $D942`. | Parses `DOPEN`, allocates a secondary address, builds the drive/name/type/mode/record-length string, and enters `OP94`. |
| `-` | `$DA07` via `$FF99` | `DCLOSE` | Starts `20 68 DC 29 F3 F0 03 4C`. `$FF99` is `JMP $DA07`. | Clears cached disk status and closes one logical file through `CLOS5`, or every open file matching the selected primary device address `FA` through `DCLALL` (both disk drive numbers). |
| `-` | `$D7AF` via `$FF9C` | `RECORD` | Starts `A9 01 8D 3A 03 20 76 00`. `$FF9C` is `JMP $D7AF`. | Parses channel, record number, and optional position, then `BOBREC` sends binary `P`, channel, record low/high, and position on command channel 15. |
| `-` | `$D9D2` via `$FF9F` | `FORMAT`/`HEADER` | Starts `20 68 DC 20 04 D8 29 11`. `$FF9F` is `JMP $D9D2`. | Validates name and optional disk ID, closes files on the drive, obtains confirmation in direct mode, and sends `N<drive>:<name>[,<id>]`. |
| `-` | `$DA65` via `$FFA2` | `COLECT`, BASIC `COLLECT` | Starts `20 68 DC 20 18 D8 20 1B`. `$FFA2` is `JMP $DA65`. | Closes files on the drive and sends `V[<drive>]` on command channel 15. |
| `-` | `$DA7E` via `$FFA5` | `BACKUP` | Starts `20 68 DC 29 30 C9 30 F0`. `$FFA5` is `JMP $DA7E`. | Closes affected files and sends `D<destination-drive>=<source-drive>`. |
| `-` | `$DAA7` via `$FFA8` | `COPY` | Starts `20 68 DC 29 30 C9 30 D0`. `$FFA8` is `JMP $DAA7`. | Sends the parsed `C<destination-drive>:<destination>=<source-drive>:<source>` command through `TRANS`. |
| `-` | `$D977` via `$FFAB` | `APPEND` | Starts `20 68 DC 20 2E D8 29 E2`. `$FFAB` is `JMP $D977`. | Allocates a secondary address, builds `<drive>:<name>,A`, and enters prepared generic OPEN through `OP94`. |
| `-` | `$DB0D` via `$FFAE` | `DSAVE` | Starts `20 68 DC 20 0B D8 29 66`. `$FFAE` is `JMP $DB0D`. | Builds the disk filename, optionally prefixes `@`, then enters `SV3` to perform the normal KERNAL SAVE transaction. |
| `-` | `$DB3A` via `$FFB1` | `DLOAD` | Starts `20 68 DC 20 0B D8 29 E6`. `$FFB1` is `JMP $DB3A`. | Builds the disk filename, clears VERIFY mode, and enters `LOADNP` to perform the normal KERNAL LOAD transaction. |
| `-` | `$D873` via `$FFB4` | `CATLOG`, BASIC `DIRECTORY`/`CATALOG` | Starts `A5 D2 85 B3 20 68 DC 20`. `$FFB4` is `JMP $D873`. | Opens `$` or `$<drive>` as logical file 14, reads and formats the directory stream, then closes it. This exercises OPEN, TALK, repeated `ACPTR`, and CLOSE. |
| `-` | `$DB55` via `$FFB7` | `RENAME` | Starts `20 68 DC 20 24 D8 29 E4`. `$FFB7` is `JMP $DB55`. | Sends `R<drive>:<new>=<drive>:<old>` through command channel 15. |
| `-` | `$DB66` via `$FFBA` | `SCRTCH`, BASIC `SCRATCH` | Starts `20 68 DC 20 04 D8 20 9E`. `$FFBA` is `JMP $DB66`. | Obtains confirmation in direct mode, sends `S<drive>:<name>`, then reads and optionally prints the disk status. |
| `-` | `$D991` | `ERRCHL`, user status entry | Starts `A5 0D D0 16 A9 28 85 0D`. Source marks it `ENTRY FOR USER`. | Reuses an allocated `DS$` buffer or falls into `GETDS` to allocate one, then performs the same status-channel read. |
| `-` | `$D995` via `$FFBD` | `GETDS`, BASIC `DS$`/`READDS` | Starts `A9 28 85 0D 20 1D C6 86`. `$FFBD` is `JMP $D995`. | Allocates the 40-byte `DS$` buffer, defaults `FA` to 8, TALKs on secondary `$6F`, reads through CR with `ACPTR`, and UNTALKs. This is the ROM 4 integrated status-channel entry. |

#### Wrappers and helpers without direct IEEE register access

The generic I/O wrappers can cause bus traffic through the entries above. The
parsers and state helpers do not establish any gateware or drive-firmware
behavior by themselves.

| ROM 2/3 address | ROM 4 address | Source label or role | Entry evidence | Relevance |
|---|---|---|---|---|
| `$F521` via `$FFC0` | `$F560` via `$FFC0` | `OPEN`, BASIC OPEN parser | ROM 2/3 starts `20 CE F4 A5 D2 F0 F6 A0`. ROM 4 starts `20 0D F5 A5 D2 F0 F6 A0`. | Parses BASIC text, installs a file-table entry, and calls `OPENI` only for IEEE devices. Use `OPENI` or `OP94` for a prepared-state transaction. |
| `$F2A9` via `$FFC3` | `$F2DD` via `$FFC3` | `CLOSE`, BASIC CLOSE parser | ROM 2/3 starts `20 CE F4 A5 D2 20 8D F2`. ROM 4 starts `20 0D F5 A5 D2 20 C1 F2`. | Parses BASIC text, then enters `CLOS5`. |
| `$F3C2` via `$FFD5` | `$F401` via `$FFD5` | `LOAD`, BASIC LOAD/VERIFY front end | ROM 2/3 starts `A9 00 85 9D 20 3E F4`. ROM 4 starts `A9 00 85 9D 20 7D F4`. | Parses BASIC LOAD arguments, waits for key-switch stability, and calls `LD15`. |
| `$F69E` via `$FFD8` | `$F6DD` via `$FFD8` | `SAVE`, BASIC SAVE front end | ROM 2/3 starts `20 3E F4 20 8D F6 A5 D4`. ROM 4 starts `20 7D F4 20 CC F6 A5 D4`. | Parses BASIC SAVE arguments, copies BASIC bounds, and enters `SV5`. |
| `$F4B7` via `$FFDB` | `$F4F6` via `$FFDB` | `VER`, BASIC VERIFY front end | ROM 2/3 starts `A9 01 85 9D 20 C6 F3 A5`. ROM 4 starts `A9 01 85 9D 20 05 F4 A5`. | Sets `VERCK`, reuses the LOAD path, and compares received bytes instead of storing them. It sets SATUS to `$10` on a mismatch. |
| `$F1D1` via `$FFE4` | `$F205` via `$FFE4` | `GETIN` | Both start `A9 00 85 96 A5 AF D0 17`. | Dispatches keyboard, tape, or IEEE input. The IEEE branch jumps to `ACPTR`, but GETIN adds current-device policy. |
| `$F1E1` via `$FFCF` | `$F215` via `$FFCF` | `BASIN`/`CHRIN` | Both start `A5 AF D0 0B A5 C6 85 A4`. | Dispatches screen, tape, or IEEE input. Use `ACPTR` for an electrical receive test. |
| `$F232` via `$FFD2` | `$F266` via `$FFD2` | `BSOUT`/`CHROUT` | Both start `48 A5 B0 C9 03 D0 04 68`. | Dispatches screen, tape, or IEEE output. The IEEE branch jumps to buffered `CIOUT`. |
| `$F26E` via `$FFE7` | `$F2A2` via `$FFE7` | `CLALL` | ROM 2/3 starts `A9 00 85 AE A5 B0 C9 04`. ROM 4 starts `A9 00 85 AE A5 B0 C9 04`. | Clears the open-file count and falls into `CLRCHN`. It aborts file bookkeeping rather than issuing CLOSE commands for each file. |
| `$F43E` | `$F47D` | `PARS1` | Both start `A2 00 86 96 86 D1 86 D3`. | Parses LOAD/SAVE arguments only. It performs no IEEE access. |
| `$F4CE` | `$F50D` | `PARS2` | Both start `A2 00 86 D3 86 96 86 D1`. | Parses OPEN/CLOSE arguments only. It performs no IEEE access. |
| `$F28D` | `$F2C1` | `JLTLK`, file-table lookup | Both start `A6 AE CA 30 16 DD 51 02`. | Finds logical file A in LAT, returning index X and comparison flags. No bus access. |
| `$F299` | `$F2CD` | `JZ100`, load file parameters | Both start `BD 51 02 85 D2 BD 5B 02`. | Loads LA, FA and SA from file-table index X. No bus access. |
| `$FB7F` | `$FBC4` | `UDST`, status-bit merge | Both start `05 96 85 96 60`. | ORs A into `SATUS` and returns. It records EOI and timeout results but does not perform a handshake. |
| `-` | `$DC68` | `DOSPAR`, ROM 4 disk parser | Starts `A2 00 8E 3E 03 86 D2 8E`. | Parses disk-statement parameters into `LA`, `FA`, drive, filename, record, and option fields. No bus access occurs. |
| `-` | `$DA1B` | `DCLALL`, close all files on a device | Starts `A5 D4 A6 AE CA 30 0E DD`. | Walks the file table and invokes `CLOS10` for matching `FA` values, irrespective of disk drive number. It adds no electrical behavior. |
| `-` | `$DBFA` | `SENDP`, ROM 4 command builder | Starts `A2 00 8D 41 03 20 E1 DB`. | Expands a `TABLD` template into `TBUFF` and sets `FNLEN`/`FNADR`. It does not transmit the command. |
| `-` | `$DBE1` | `OLDCLR`, ROM 4 status-cache reset | Starts `98 48 A5 0D F0 0A A0 28`. | Invalidates the allocated `DS$` string and clears `SATUS`. It performs no bus access. |

The shared `$FFC0-$FFEA` entries are three-byte `JMP` trampolines to generic
OPEN, CLOSE, CHKIN, CHKOUT, CLRCHN, CHRIN, CHROUT, LOAD, SAVE, VERIFY, SYS,
STOP, GETIN, CLALL, and UDTIM implementations. The ROM 4-only `$FF93-$FFBD`
disk vectors are listed above. Do not treat ROM 2/3 bytes at `$FF93-$FFBD` as
those vectors. That range contains resident-monitor code in `901465-03`.
Unlike later Commodore KERNALs, these PET OPEN, CLOSE, LOAD, SAVE, and VERIFY
targets parse the current BASIC text stream. They are not `SETNAM`/`SETLFS`
register APIs.

#### Shared PET public I/O vectors

These vectors are callable ABI entries distinct from their implementation
addresses. The ROM 4 disk-only vectors are paired with their targets above.
SYS (`$FFDE`) and UDTIM (`$FFEA`) are generic execution/time services, not file
or IEEE entries, and are recorded as exclusions in the audit ledger.

| ROM 2/3 address | ROM 4 address | Source role | Exact bytes | Target and calling convention |
|---|---|---|---|---|
| `$FFC0` | `$FFC0` | `OPEN` public vector | ROM 2: `4C 21 F5`. ROM 4: `4C 60 F5`. | JMP to ROM 2/3 `$F521` or ROM 4 `$F560`. Uses the implementation calling convention above. |
| `$FFC3` | `$FFC3` | `CLOSE` public vector | ROM 2: `4C A9 F2`. ROM 4: `4C DD F2`. | JMP to ROM 2/3 `$F2A9` or ROM 4 `$F2DD`. Uses the implementation calling convention above. |
| `$FFC6` | `$FFC6` | `CHKIN` public vector | ROM 2: `4C 70 F7`. ROM 4: `4C AF F7`. | JMP to ROM 2/3 `$F770` or ROM 4 `$F7AF`. Uses the implementation calling convention above. |
| `$FFC9` | `$FFC9` | `CHKOUT` public vector | ROM 2: `4C BC F7`. ROM 4: `4C FE F7`. | JMP to ROM 2/3 `$F7BC` or ROM 4 `$F7FE`. Uses the implementation calling convention above. |
| `$FFCC` | `$FFCC` | `CLRCHN` public vector | ROM 2: `4C 72 F2`. ROM 4: `4C A6 F2`. | JMP to ROM 2/3 `$F272` or ROM 4 `$F2A6`. Uses the implementation calling convention above. |
| `$FFCF` | `$FFCF` | `CHRIN` public vector | ROM 2: `4C E1 F1`. ROM 4: `4C 15 F2`. | JMP to ROM 2/3 `$F1E1` or ROM 4 `$F215`. Uses the implementation calling convention above. |
| `$FFD2` | `$FFD2` | `CHROUT` public vector | ROM 2: `4C 32 F2`. ROM 4: `4C 66 F2`. | JMP to ROM 2/3 `$F232` or ROM 4 `$F266`. Uses the implementation calling convention above. |
| `$FFD5` | `$FFD5` | `LOAD` public vector | ROM 2: `4C C2 F3`. ROM 4: `4C 01 F4`. | JMP to ROM 2/3 `$F3C2` or ROM 4 `$F401`. Uses the implementation calling convention above. |
| `$FFD8` | `$FFD8` | `SAVE` public vector | ROM 2: `4C 9E F6`. ROM 4: `4C DD F6`. | JMP to ROM 2/3 `$F69E` or ROM 4 `$F6DD`. Uses the implementation calling convention above. |
| `$FFDB` | `$FFDB` | `VERIFY` public vector | ROM 2: `4C B7 F4`. ROM 4: `4C F6 F4`. | JMP to ROM 2/3 `$F4B7` or ROM 4 `$F4F6`. Uses the implementation calling convention above. |
| `$FFE1` | `$FFE1` | `STOP` public vector | ROM 2: `4C 0F F3`. ROM 4: `4C 43 F3`. | JMP to ROM 2/3 `$F30F` or ROM 4 `$F343`. Uses the implementation calling convention above. |
| `$FFE4` | `$FFE4` | `GETIN` public vector | ROM 2: `4C D1 F1`. ROM 4: `4C 05 F2`. | JMP to ROM 2/3 `$F1D1` or ROM 4 `$F205`. Uses the implementation calling convention above. |
| `$FFE7` | `$FFE7` | `CLALL` public vector | ROM 2: `4C 6E F2`. ROM 4: `4C A2 F2`. | JMP to ROM 2/3 `$F26E` or ROM 4 `$F2A2`. Uses the implementation calling convention above. |

#### Internal continuations and prepared-state entries

A prepared-state entry is callable when its documented register, flag, memory,
and bus prerequisites hold. It is not the same as a stack-dependent continuation.
The following first group contains internal phases. The second group contains
legitimate alternate entries that must remain in the callable inventory.

| ROM 2/3 address | ROM 4 address | Label | Why it is not a standalone entry |
|---|---|---|---|
| `$F0DF` | `$F0FA` | `LIST2` | It begins with `PLA` to recover the byte pushed by `LIST1`. A direct JSR consumes the caller's return address as command data and corrupts the stack. |
| `$F0E4` | `$F0FF` | `LIST4` | It assumes `LIST1` already released the receive lines and placed the addressed command in `BSOUR`. A direct call can send stale data under an invalid line state. |
| `$F103/$F10D/$F112/$F11D` | `$F11E/$F128/$F12D/$F138` | `ISR1`/`ISR0`/`ISR2`/`ISR3` | These are wait, timeout, and cleanup phases inside `ISOUR`. They require DIO, DAV, the timer, and saved state established by the prologue. |
| `$F177/$F17C` | `$F1A6/$F1AB` | `CI2`/`CI4` | These are the send-previous-byte and buffer-current-byte branches inside `CIOUT`. `CI2` relies on CIOUT's A value and `CI4` bypasses the required prior-byte decision. |
| `$F199/$F19E/$F1BA/$F1C5` | `$F1CD/$F1D2/$F1EE/$F1F9` | `ACP00`/`ACP01`/`ACP03`/`ACP05` | These are timer, wait, sample, and DAV-release phases inside `ACPTR`. They assume the input handshake was initialized at the real entry. |
| `$F7A1/$F7AE/$F7B1` | `$F7E3/$F7F0/$F7F3` | `JX3301`/`JX340`/`JX350` | These are mid-CHKIN addressing and status labels. They assume CHKIN saved the selected device on the stack. Their common tail executes `PLA`, so a direct JSR corrupts the return address. |
| `-` | `$F831` | `JX3701` | ROM 4 reaches this after CHKOUT saves the selected device and clears `DS$`. Direct entry skips that setup and later consumes an unsaved stack byte. ROM 2/3 has no separate label before its LISTEN call. |
| `$F7F8/$F7FB` | `$F83D/$F840` | `JX380`/`JX390` | These are mid-CHKOUT secondary-address and status labels. They assume CHKOUT's saved registers and device byte. The common tail executes `PLA`. |

Prepared-state entries (the prerequisites are part of the calling contract):

| ROM 2/3 address | ROM 4 address | Label | Required state and use |
|---|---|---|---|
| `$F2B3` | `$F2E7` | `CLOS10` | Callable close-and-remove entry, explicitly called by ROM 4 `DCLALL`. X must identify an existing logical-file table entry. It calls `JZ100`, saves X, performs device close, then removes the table entry. Use `CLOS5` when starting with a logical file number in A. |
| `$F526` | `$F565` | `FOPEN` | The label is a `BEQ` that depends on flags set by the preceding `LDA LA` or, for ROM 4 CATALOG, by a prior call. ROM 4's safe prepared-parameter entry is `OP94` at `$F563`. ROM 2/3 has no source-labelled equivalent. |
| `$F475` | `$F4B4` | `OPENIB` | It starts by sending a secondary command. It assumes the device is already LISTEN-addressed and that `FNLEN`/`FNADR` describe the message. ROM 4 `TRANS1` uses it, but it is not a complete OPEN entry. |
| `-` | `$D9B3` | `EREAD` | It is the bus-reading tail of `GETDS`. It assumes a valid `DS$` descriptor and buffer pointer. Use `$D995`/`$FFBD` for the complete status operation. |
| `-` | `$DA31` | `BOBREC` | It is the command-building tail reached after `RECORD` parsing. It assumes prepared logical-file and record fields before jumping to `TRANS1`. |
| `-` | `$DA98` | `TRANS` | It expects a command-template offset in Y and a template length in A, then calls `SENDP` and falls into `TRANS1`. It is a callable command sender with those explicit parameters. |
| `-` | `$DA9B` | `TRANS1` | It sends a prepared `FNLEN`/`FNADR` buffer on command channel 15 through `OPENIB`. It does not parse or build a command. |

#### Additional called and prepared-state PET helpers

These are part of the file/disk call graph, including parser and error helpers.
They require the calling state described below. They are not all electrical
primitives, and a routine that deliberately unwinds a parser or error stack
must not be used as an ordinary leaf call. Source labels, instruction bytes,
call sites, and excluded continuations are retained in the
[audit ledger](../../docs/dev/PET/ieee-rom-entry-audit.json).

| ROM 2/3 address | ROM 4 address | Source label | Entry bytes | Required state and relevance |
|---|---|---|---|---|
| `$F301` | `$F335` | `STOP1` | ROM 2: `A5 9B C9 EF D0 07`. ROM 4: `A5 9B C9 EF D0 07`. | Tests the STOP key and clears active channels on STOP. Changes keyboard state. Required by LOAD/SAVE, directory and timeout paths. |
| `$F30F` | `$F343` | `STOP` | ROM 2: `20 01 F3 4C 3F C7`. ROM 4: `20 35 F3 4C C6 B7`. | Calls STOP1, then jumps to BASIC stop handling. Public vector `$FFE1`. May unwind into BASIC rather than return normally. |
| `$F3C6` | `$F405` | `LD10` | ROM 2: `20 3E F4 20 8D F6`. ROM 4: `20 7D F4 20 CC F6`. | Alternate LOAD parser used by VERIFY. Requires VERCK already selected and a valid BASIC text pointer. Falls through LOADNP. |
| `$F68D` | `$F6CC` | `SV60` | ROM 2: `A5 2A 85 C9 A5 2B`. ROM 4: `A5 2A 85 C9 A5 2B`. | Copies BASIC start/end bounds to transfer pointers. No bus access. |
| `$FB76` | `$FBBB` | `RD300` | ROM 2: `A5 FC 85 C8 A5 FB`. ROM 4: `A5 FC 85 C8 A5 FB`. | Copies STAL/STAH to SAL/SAH for SAVE. Despite its location in tape source, it is also a called IEEE SAVE helper. |
| `$FCC6` | `$FD0B` | `WRT62` | ROM 2: `A5 C8 C5 CA D0 04`. ROM 4: `A5 C8 C5 CA D0 04`. | Compares SAL/SAH with EAL/EAH for SAVE completion. Requires valid pointers. No bus access. |
| `$F460` | `$F49F` | `PR070` | ROM 2: `20 16 F5 4C 78 D6`. ROM 4: `20 55 F5 4C D4 C8`. | Parses a comma and byte argument through PR150 and GETBYT. Requires BASIC parser state. |
| `$F519` | `$F558` | `PR130` | ROM 2: `20 76 00 D0 F7 4C`. ROM 4: `20 76 00 D0 F7 4C`. | Checks that an argument follows at the current BASIC text pointer. Missing arguments raise a BASIC syntax error. |
| `$F50E` | `$F54D` | `PR140` | ROM 2: `20 76 00 D0 02 68`. ROM 4: `20 76 00 D0 02 68`. | Optional-argument probe. On end-of-statement it discards its own return address, returning from the enclosing parser. Requires that enclosing parser frame. |
| `$F516` | `$F555` | `PR150` | ROM 2: `20 F8 CD 20 76 00`. ROM 4: `20 F5 BE 20 76 00`. | Consumes a required comma then enters PR130. Requires BASIC parser state. |
| `-` | `$BFC1` | `ISVDS` | ROM 4: `C9 44 D0 0E C0 D3`. | Prepared BASIC string-variable dispatch with A/Y holding the variable identity. Recognizes DS$, calls CHKDS, and returns its cached descriptor through STRLIT; other names return through STRRTS. |
| `-` | `$BFFC` | `CHKDS` | ROM 4: `A5 0D D0 D3 4C BD`. | Callable DS/DS$ cache guard. Returns if DSDESC is populated; otherwise jumps through READDS at $FFBD. This routine crosses the B-ROM/C-ROM boundary at $C000. |
| `-` | `$C01C` | `QDSAV` | ROM 4: `C9 44 D0 20 C0 53`. | Prepared BASIC numeric-variable dispatch with A/Y holding the variable identity. Recognizes DS, calls CHKDS, and converts the first two status-string digits to a BASIC number. Other variables continue through GOMOVF. |
| `$F4FD` | `$F53C` | `PR200` | ROM 2: `20 9F CC 20 7D D5`. ROM 4: `20 98 BD 20 B5 C7`. | Evaluates a filename string and sets FNLEN/FNADR. Requires BASIC expression and string workspace. |
| `$F156` | `$F185` | `MSG` | ROM 2: `B9 00 F0 08 29 7F`. ROM 4: `B9 00 F0 08 29 7F`. | Prints a high-bit-terminated ROM message starting at offset Y through editor PRT. Presentation helper, no IEEE transport. |
| `$F315` | `$F349` | `SPMSG` | ROM 2: `20 1D F3 D0 F4 4C`. ROM 4: `20 51 F3 D0 F4 4C`. | Prints MSG only in direct mode. Requires Y to name a message offset. |
| `$F31D` | `$F351` | `TXTST` | ROM 2: `A5 78 C9 02 60 A5`. ROM 4: `A5 78 C9 02 60 A5`. | Tests the BASIC text pointer for direct mode. No bus access. |
| `$F40A` | `$F449` | `LD300` | ROM 2: `20 1D F3 D0 1E A0`. ROM 4: `20 51 F3 D0 1E A0`. | Prints SEARCHING and the prepared filename when appropriate. Uses MSG and LD105. |
| `$F41D` | `$F45C` | `LD105` | ROM 2: `A4 D1 F0 0C A0 00`. ROM 4: `A4 D1 F0 0C A0 00`. | Prints FNLEN bytes from FNADR through current output. That output can itself be IEEE, so this is not necessarily screen-only. |
| `$F42E` | `$F46D` | `LD400` | ROM 2: `A0 5F A5 9D F0 02`. ROM 4: `A0 5F A5 9D F0 02`. | Selects LOADING or VERIFYING messages using VERCK and SPMSG. |
| `$F570` | `$F5AF` | `ERMSG` | ROM 2: `20 6E F2 A9 0D 20`. ROM 4: `20 A2 F2 A9 0D 20`. | Closes active channels through CLALL, prints the selected error, and jumps to BASIC error handling. Does not return normally. |
| `-` | `$D92F` | `ENTRY0` | ROM 4: `A0 61 C8 98 A6 AE`. | Allocates an unused secondary address starting at `$62`, comparing SAT entries. Does not send OPEN. |
| `-` | `$D931` | `ENTRY1` | ROM 4: `C8 98 A6 AE CA 30`. | Alternate allocator entry with initial secondary candidate in Y (incremented before testing). Called through ENTRY0 fall-through. |
| `-` | `$DBFC` | `SENDP1` | ROM 4: `8D 41 03 20 E1 DB`. | Command-template builder with initial output offset X, template offset Y, and length A. Preserves an existing prefix such as `@`. |
| `-` | `$DC4C` | `TRANR` | ROM 4: `86 D1 A9 53 85 DA`. | Sets FNLEN from X and FNADR to TBUFF. Used after both template expansion and binary REL-position construction. |
| `-` | `$DAD4` | `RSFN` | ROM 4: `A5 D1 8D 3A 03 A5`. | Copies filename-1 descriptor to filename-2 scratch fields, then falls into RDFN. Requires buffer index X and template index Y. |
| `-` | `$DAE1` | `RDFN` | ROM 4: `98 48 AC 3A 03 F0`. | Appends filename-2 to TBUFF at X, preserving Y. Used by SENDP. No bus access. |
| `-` | `$DAFD` | `RID` | ROM 4: `AD 3F 03 9D 53 03`. | Appends two disk-ID bytes at TBUFF,X and advances X. No bus access. |
| `-` | `$DC57` | `RWRT` | ROM 4: `AD 3D 03 F0 04 A9`. | Returns `L` for a REL record length or `W` while setting default type `S`. Used by template expansion. |
| `-` | `$D804` | `CHK1` | ROM 4: `29 E6 F0 03 4C 00`. | Checks HEADER/SCRATCH option mask, then CHK2 required filename. Requires parsed PARCHK and A. |
| `-` | `$D80B` | `CHK2` | ROM 4: `AD 3E 03 29 01 C9`. | Requires filename-1 in PARCHK and returns PARCHK in A. |
| `-` | `$D818` | `CHK3` | ROM 4: `29 E7 D0 EC 60 29`. | Rejects invalid CATALOG/COLLECT options in A. |
| `-` | `$D81D` | `CHK4` | ROM 4: `29 C4 D0 E7 AD 3E`. | Checks COPY/CONCAT options, then CHK5 required filenames. |
| `-` | `$D824` | `CHK5` | ROM 4: `29 03 C9 03 D0 DE`. | Requires both filenames in PARCHK and returns PARCHK in A. |
| `-` | `$D82E` | `CHK6` | ROM 4: `29 05 C9 05 D0 D4`. | Requires logical file and filename for DOPEN/APPEND. |
| `-` | `$DE2C` | `ON` | ROM 4: `20 70 00 C9 55 D0`. | Consumes the ON clause and requires U, then enters UNIT. |
| `-` | `$DE33` | `UNIT` | ROM 4: `20 87 DE E0 20 B0`. | Parses a unit in the ROM-accepted range 3 through 31, stores FA, and sets its PARCHK bit. |
| `-` | `$DE49` | `NEWNAM` | ROM 4: `D0 D5 20 98 BD 20`. | Filename-expression helper. Requires Z set by caller option check, valid BASIC string workspace, and PARCHK. Returns filename length and pointer. |
| `-` | `$DE87` | `GETVAL` | ROM 4: `20 70 00 D0 03 4C`. | Advances CHRGET then enters GTVL2 to parse a byte value. |
| `-` | `$DE8A` | `GTVL2` | ROM 4: `D0 03 4C 00 BF 90`. | Alternate numeric parser entry. Requires A and condition flags from CHRGET/CHRGOT. Handles an expression in parentheses. |
| `-` | `$DB99` | `DDIREC` | ROM 4: `A5 78 C9 02 60 20`. | Tests direct/program mode from TXTPTR. No bus access. |
| `-` | `$DB9E` | `RUSURE` | ROM 4: `20 99 DB D0 32 A0`. | Confirmation helper for HEADER/SCRATCH. Uses CLRCH and BASIN, returns carry set on rejection in direct mode. |
| `-` | `$DBD7` | `BADDIS` | ROM 4: `20 99 DB D0 FA A0`. | Prints BAD DISK only in direct mode, otherwise returns. Presentation helper. |
| `-` | `$DE9E` | `PATCH5` | ROM 4: `85 96 91 0E 88 60`. | GETDS helper at `$DE9E`, after checksum data `$DE9D`. Clears SATUS, stores the high backlink byte through DSDESC, and decrements Y. |
| `-` | `$D9F8` | `FERRS` | ROM 4: `20 91 D9 A0 00 B1`. | Prepared status-check tail of HEADER. Reads ERRCHL and treats first status digit >= `2` as BAD DISK. |
| `-` | `$DB78` | `NUMSCR` | ROM 4: `20 99 DB D0 1B 20`. | Prepared SCRATCH completion entry. Reads and prints disk status only in direct mode. |
| `-` | `$D91A` | `SUBA` | ROM 4: `20 23 D9 20 66 F2`. | Directory-output helper: selects saved output through SUBB, writes A through BSOUT, then CLRCHN. Requires CATALOG state. |
| `-` | `$D923` | `SUBB` | ROM 4: `A6 BA E0 03 F0 05`. | Restores CATALOG output selection using CNTDN/WSW, possibly calling CHKOUT. Requires saved CATALOG state. |
| `-` | `$D87D` | `CATALG` | ROM 4: `A0 00 A2 01 AD 3E`. | Prepared CATALOG entry after parsing and option checks. Requires PARCHK, FA, DRIVE1 and saved WSW. Builds and reads the directory. |

IEEE initialization is editor-resident, not KERNAL-resident. The ROM 2/3
source places `CINT` at `$E1DE`. ROM 4 non-CRTC editor `901447-29` starts its
implementation at `$E000`. The
[4032 CRTC editor](https://www.zimmers.net/anonftp/pub/cbm/firmware/computers/pet/edit-4-40-n-60hz-901499-01.dis.txt)
uses `$E000` as a jump to `$E036`, and the cited 8032 editor uses `$E000` as a
jump to `$E04B`. Use the public `$E000` editor entry for ROM 4 startup tests and
load the matching editor ROM. Do not invent one fixed ROM 4 `CINT`
implementation address.

### SuperPET Waterloo 6809 controller behavior

Use the exact Waterloo revision 12 ROM set downloaded by
[`.devcontainer/download.sh`](../../.devcontainer/download.sh). Use the linked
6809 disassemblies for navigation and the pinned Zimmers.net binaries as the
primary byte-level evidence:

| Address range | Part | Disassembly | ROM binary | MD5 |
|---|---|---|---|-----|
| `$A000-$BFFF` | `970018-12` | [waterloo-a000-bfff.asm](https://github.com/prachwal/personal-004/blob/main/docs/pet/disassembly/waterloo-a000-bfff.asm) | [waterloo-a000-bfff.970018-12.bin](https://www.zimmers.net/anonftp/pub/cbm/firmware/computers/pet/SuperPET/waterloo-a000-bfff.970018-12.bin) | `84cb402449c6107b7d2b636cb28f0042` |
| `$C000-$DFFF` | `970019-12` | [waterloo-c000-dfff.asm](https://github.com/prachwal/personal-004/blob/main/docs/pet/disassembly/waterloo-c000-dfff.asm) | [waterloo-c000-dfff.970019-12.bin](https://www.zimmers.net/anonftp/pub/cbm/firmware/computers/pet/SuperPET/waterloo-c000-dfff.970019-12.bin) | `0f9bd7123d99892ce80f1e7e438c2194` |
| `$E000-$FFFF` | `970034-12` | [waterloo-e000-ffff.asm](https://github.com/prachwal/personal-004/blob/main/docs/pet/disassembly/waterloo-e000-ffff.asm) | [waterloo-e000-ffff-970034-12.bin](https://www.zimmers.net/anonftp/pub/cbm/firmware/computers/pet/SuperPET/waterloo-e000-ffff-970034-12.bin) | `c03098d26dbb1a23737d3286f264bc97` |

These are generated linear
[Capstone 6809 disassemblies](https://github.com/prachwal/personal-004/blob/main/docs/pet/disassembly/README.md),
not original Waterloo source or an annotated reconstruction. They can decode
embedded strings and tables as instructions. Confirm conclusions against the
pinned ROM bytes, call sites, and reachable control flow.

Use the
[Waterloo investigation notes](https://github.com/prachwal/personal-004/blob/main/docs/pet/waterloo-investigation.md)
as a secondary call-path guide, not as primary compatibility evidence. The
notes distinguish verified traces from open hypotheses. Preserve that
distinction in implementations and reviews.

The Waterloo 6809 directly controls the PET's PIA2 and VIA. It does not invoke
the 6502 KERNAL as an intermediary. Its IEEE implementation spans the
`$A000-$BFFF` and `$C000-$DFFF` ROMs:

### Revision-12 IEEE routine map

The archived `OPSYSDIS*` and `MAP*` files on TPUG disks `(s)t8.d64`, `(s)t9.d64`,
and `(s)ta.d64` are an annotated 1983 navigation aid, not a revision authority.
`NOTE_FROM_JOHN` says that a disassembler bug may have produced bad code and only
comments identify sections the author considered reliable. `NOTE_FROM_DICK`
identifies the files as John A. Toebes VIII's paged operating-system disassembly
and partial map, but neither note identifies the ROM revision. Do not use their
labels or addresses without checking the pinned binaries.

The tables below were cross-checked against the revision-12 images whose MD5
values are listed above. An address is a callable entry only when the binary
starts on the archived instruction boundary and the archived disassembly shows
a caller or a complete leaf routine with its own return. Names present in `OPSYSDIS*` but absent from `MAP*` (for example `ByteOut_`,
`sysrdbyt`, and `openf`) are archived disassembly labels, not invented roles.
Neither archive is original Waterloo source. Inferred descriptions are marked
as roles in the tables.

#### Callable bus and disk-command entries

These entries either access the IEEE registers directly or deliberately invoke
the lower-level routines to produce an IEEE transaction. Use the electrical
entries for focused gateware tests and the disk-command entries for integrated
gateware and firmware tests.

| Address | Archived label or role | Entry evidence | Revision-12 behavior and test relevance |
|---|---|---|---|
| `$BCD0` | `addrbcd0`, generic OPEN sender | Starts `34 06 32 7E CC 00 14`; called by `ieeopen` and `sysdirop`. | Addresses the device as listener with OPEN secondary offset `$F0`, sends the filename, and terminates it with EOI and UNLISTEN. This is the normal end-to-end disk OPEN entry. |
| `$BD11` | `addrbd11`, CLOSE/role release | Starts `34 06 CC 00 15`; called by `$D331` and `sysdircl`. | Sends a CLOSE secondary command (`$E0 + SA`) when required, then ends TALK or LISTEN if this FCB owns the active role. |
| `$BD51` | `addrbd51`, REL OPEN sender | Starts `34 06 32 7E CC 00 16`; called by `ieeopen` at `$D308`. | Sends the REL filename followed by `L,` and the record length as the EOI byte, then UNLISTENs. |
| `$BD96` | `addrbd96`, SCRATCH sender | Starts `34 06 C6 0F AE E4`; called by `sysscrat`. | Selects command channel 15, sends `S` plus the parsed name, then sends CR with EOI and UNLISTENs. |
| `$BDC6` | `addrbdc6`, RENAME sender | Starts `34 06 C6 0F AE E4`; called by `sysrenam`. | Selects command channel 15 and sends `R` plus the new and old names separated by `=` before EOI and UNLISTEN. |
| `$BE23` | `addrbe23`, drive initialize sender | Starts `34 06 C6 0F AE E4`; called by `sysmount`. | Selects command channel 15 and sends `I0` or `I1` followed by EOI and UNLISTEN. |
| `$BE53` | final-byte and UNLISTEN helper | Starts `34 06 4F E6 61 8D 05`; called by the OPEN and REL-position paths. | Sends one EOI-marked byte through `$BE5F`, then calls `$C0D0`. It is useful for verifying final-byte EOI and command termination together. |
| `$BE5F` | EOI byte output | Starts `34 06 BD C1 76`; called by `$BE53`, `$D3DE`, and write paths. | Calls `$C176`, sends the byte through `$BE6F`, then calls `$C17E`. This is the focused EOI-send entry. |
| `$BE6F` | `ByteOut_` | Starts `34 06 CC 00 17 BD E7 6B`; called throughout the command and write paths. | Drives complemented DIO through PIA2 port B, waits for NRFD and NDAC, reports absent-device or timeout status through the active control block, and releases DAV and DIO on exit. |
| `$BEFB` | byte input | Starts `32 7F CC 00 18 BD E7 6B`; called by status, read, and directory paths. | Asserts NDAC and NRFD, waits for DAV, samples EOI and complemented DIO, releases NDAC, waits for DAV release, then re-arms NDAC and releases DIO. |
| `$BF98` | REL position sender | Starts `34 06 32 E8 EF CC 00 19`; called by `sysseek`. | Sends five bytes `P`, channel, record low, record high, and `$00` on command channel 15. The trailing position byte `$00`, not record high, carries EOI through `$BE53`, followed by UNLISTEN. |
| `$BFEF` | status-channel reader | Starts `34 06 32 E8 ED CC 00 1A`; called by seek, scratch, rename, mount, read, and error paths. | Talks on command channel 15, reads through CR, UNTALKs, and treats status prefixes `00` and `01` as success. |
| `$C072` | `SetLstnr` | Starts `34 06 CC 00 1B BD E7 6B`; called by all listener-side senders. | Resolves any prior role, asserts ATN, sends MLA and MSA, then releases ATN. This is the focused LISTEN-addressing entry. |
| `$C0D0` | `UNListen` | Starts `CC 00 1C BD E7 6B`; called by `$BE53` and role replacement. | Calls `$C14F`, sends `$3F`, releases ATN, and clears the active-role flag. |
| `$C0DD` | `SetTalkr` | Starts `34 06 CC 00 1D BD E7 6B`; called by read and directory paths. | Resolves any prior role, asserts ATN, sends MTA and MSA, asserts NRFD, then releases ATN. This is the focused TALK-addressing entry. |
| `$C13C` | `UNTalk_` | Starts `CC 00 1E BD E7 6B`; called by close and role replacement. | Calls `$C14F`, sends `$5F`, releases ATN, and clears the active-role flag. |
| `$C14F` | `ATNDown_` | Starts `4F F6 E8 40 CA 02`; called by the address and termination routines. | Releases NRFD and NDAC, waits for DAV to release, then asserts ATN. Use it to verify controller line ordering, not disk protocol. |
| `$C16E` | `ATNUp_` | Starts `4F F6 E8 40 CA 04`; called by the address and termination routines. | Releases ATN through the shared `$C1C4` store. Use it to verify the VIA mapping and ATN polarity. |
| `$C176` | `EOIDown_` | Starts `4F F6 E8 11 C4 F7`; called by `$BE5F`. | Asserts EOI through PIA1 control register `$E811`. |
| `$C17E` | `EOIUp_` | Starts `4F F6 E8 11 CA 08`; called by `$BE5F`. | Releases EOI through PIA1 control register `$E811`. |
| `$C188` | `IEEEInit` | Starts `0F 77 4F F6 E8 11 CA 38`; called by `sysioini` at `$C1F5`. | Configures the PIAs and VIA, releases DIO and EOI, establishes the initial ATN/NRFD state, and clears the active role. This is the correct focused initialization entry. |

#### Internal labels that are not independent entries

Do not start a ROM test at an address merely because `MAP*` names it, unless
it is useful to do so for white-box testing.

| Address | Label | Why it is not an independent entry |
|---|---|---|
| `$BEA2` | byte-output continuation | It is inside `$BE6F`, after the prologue, active-control-block lookup, absent-device check, and DIO setup. Entering here does not implement `ByteOut_`. |
| `$C137` | `SetFin_` | It is the shared tail of `$C072` and `$C0DD`. It calls `$C16E`, then falls through to `$C139`, which removes their saved `D` before returning. A direct `JSR $C137` corrupts the caller's stack. |
| `$C139` | `SetTdone` | It is only the `LEAS 2,S; RTS` epilogue for `$C072` and `$C0DD`. |
| `$C147` | `CMDFin_` | It is the shared command-completion tail reached from `$C0D0` and `$C13C`, not a separately called routine. |
| `$C184` | `EOISet_` | It is the shared final store and return reached by branches from `$C176` and `$C17E`. The archive has no caller that treats it as a standalone EOI operation. |
| `$C1C4` | `ATNSet_` | It is the shared final store and return reached by branches from `$C14F` and `$C16E` and by fall-through from `$C188`. The archive has no standalone call to it. |

The following archived numeric labels are not instruction boundaries in the
pinned revision. They must not be promoted to entries, even for white-box tests:

| Address | Archived anchor | Binary evidence and disposition |
|---|---|---|
| `$B29C` | `addrb29c` | Operand of `JSR $C9D6` at `$B29B` (`BD C9 D6`). The complete close wrapper starts at `$B292`. |
| `$C6E7` | `addrc6e7` | Displacement of `BEQ $C6ED` at `$C6E6` (`27 05`), inside sysnl. |
| `$C6FF` | `addrc6ff` | Indexed postbyte of `STB [,S]` at `$C6FE` (`E7 F4`), inside sysnl. |
| `$D33C` | `addrd33c` | Register mask of `PSHS D` at `$D33B` (`34 06`). `$D33B` is the IEEE read adapter entry. |
| `$DD75` | `addrdd75` | Address operand of `STB $E810` at `$DD74` (`F7 E8 10`), inside keyboard initialization. |
| `$FF86` | `addrff86` | Opcode byte following the page prefix of `LDY #$0100` at `$FF85` (`10 8E 01 00`), inside reset initialization. |

#### Wrappers and parser helpers without direct IEEE register access

None of these routines directly accesses `$E810`, `$E811`, `$E820-$E823`, or
`$E840`. The `$Cxxx` dispatchers and `$Dxxx` adapters can still cause bus
traffic by calling the `$BCxx-$C1xx` routines, so they are valid full-stack
entry points but not electrical primitive tests. The `$Exxx` helpers only
parse or mutate FCB state and are not evidence that the gateware or firmware
drive implementation works.

| Address | Map label or inferred role | Entry evidence | Relevance |
|---|---|---|---|
| `$C1F5` | `sysioini` | Starts `BD E7 7A 4F 5F 34 06`; target of the `$B0A8` public trampoline. | Initializes all system I/O and eventually calls `$C188`. Use `$C188`, not `$C1F5`, for a focused IEEE initialization test. |
| `$C244` | `sysopen` | Starts `34 06 32 7E 4F 5F`; reached through the public file API. | Parses and dispatches all device types, calling `$D28C` only for IEEE. It is an application-level OPEN entry, not an IEEE primitive. |
| `$C2A5` | `sysclose` | Starts `34 06 32 7E CC 00 01`. | Dispatches IEEE close through `$D331`; it adds FCB and generic-device handling. |
| `$C2D8` | `sysread` | Starts `34 06 32 7C CC 00 02`. | Implements record buffering and format handling, then uses `$C0DD`, `$D33B`, and `$BFEF` for IEEE files. |
| `$C52C` | `syswrite` | Starts `34 06 32 7D CC 00 03`. | Implements record sizing and buffering, then uses `$C072`, `$D37B`, or `$BE5F` for IEEE files. |
| `$C6C6` | `sysnl` | Starts `34 06 32 7C CC 00 08`. | Implements end-of-record policy and dispatches IEEE termination through `$D3DE` or `$BE5F`. |
| `$C7F7` | `sysskip` | Starts `34 06 32 7D CC 00 09`. | Skips to the next record by calling `sysread` or `sysnl`; it has no IEEE logic of its own. |
| `$C846` | `sysseek` | Starts `34 06 32 7E CC 00 0A`. | Validates REL access, adds one to the caller record number, dispatches positioning through `$BF98`, and reads status through `$BFEF`. A returned `50` prefix is cleared for seek. |
| `$C8C9` | `sysscrat` | Starts `34 06 32 7E CC 00 0B`. | Parses and dispatches disk SCRATCH through `$BD96`, then reads status through `$BFEF`. |
| `$C90A` | `sysrenam` | Starts `34 06 32 7E CC 00 0C`. | Parses and dispatches disk RENAME through `$BDC6`, then reads status through `$BFEF`. |
| `$C963` | `sysmount` | Starts `34 06 32 7E CC 00 0D`. | Parses and dispatches disk initialize through `$BE23`, then reads status through `$BFEF`. |
| `$C9D6` | `geterror` | Starts `34 06 32 7E CC 00 0E`. | Applies cached FCB error policy and calls `$BFEF` only when a disk status read is required. |
| `$CA99` | `sysdirop` | Starts `34 06 32 7E CC 00 11`. | Opens a directory through `$BCD0`, addresses TALK through `$C0DD`, and consumes its two-byte header through `$BEFB`. |
| `$CAEA` | `sysdirrd` | Starts `34 06 32 7E CC 00 12`. | Reads and reformats directory records by repeated calls to `$BEFB`. |
| `$CB98` | `sysdircl` | Starts `34 06 32 7E CC 00 13`. | Dispatches disk directory close through `$BD11`. |
| `$D28C` | `ieeopen` | Starts `34 06 AE E4 E6 02`; called by `sysopen`. | Rewrites mode suffixes and dispatches to `$BD51` for REL or `$BCD0` otherwise. Use only for full OPEN-path testing. |
| `$D331` | IEEE close adapter | Starts `34 06 EC E4 BD BD 11`; called by `sysclose`. | A stack adapter around `$BD11`. It adds no IEEE behavior. |
| `$D33B` | IEEE read adapter | Starts `34 06 32 7F 4F AE 61`; called by `sysread`. | Checks cached EOF/EOR flags, calls `$BEFB`, and updates FCB status. It adds no electrical behavior. |
| `$D37B` | IEEE write adapter | Starts `34 06 4F AE E4 E6 0C`; called by `syswrite` through `outbyte`. | Clears FCB status and performs printer character translation before calling `$BE6F`. It adds no disk handshake behavior. |
| `$D3DE` | IEEE end-record adapter | Starts `34 06 CC 00 0D BD BE 5F`; called by `sysnl`. | Sends CR through `$BE5F` and updates printer state. It adds no electrical behavior. |
| `$E1EE` | `chkfname` | Starts `34 06 CC 00 0F BD E7 6B`. | Parses file type, device, secondary address, drive, and disk filename before `sysopen`. No bus access occurs. |
| `$E2EE` | `chkdirpm` | Starts `34 06 CC 00 10 BD E7 6B`. | Parses directory or mount parameters and constructs `$0` or `$1`. No bus access occurs. |
| `$E373` | `chkdevnm` | Starts `32 7E 9E 13 6F 02`. | Maps a textual device name to an FCB device code and defaults an omitted device to disk 8. No bus access occurs. |
| `$E3D1` | `chkieedv` | Starts `32 7E BD E6 D5 ED E4`. | Parses an IEEE primary address, defaulting disk to 8 and printer to 4. No bus access occurs. |
| `$E408` | `chkieesa` | Starts `32 7E 9E 68 E6 84`. | Parses a `-secondary-address` suffix or calls `$E570` for a disk default. No bus access occurs. |
| `$E444` | `chkdskdr` | Starts `32 7E 9E 68 E6 84`. | Parses a `/drive` suffix and defaults to drive 0. No bus access occurs. |
| `$E47D` | `chddevcd` | Starts `9E 13 E6 02 26 0A`. | Validates the device/file separator and marks a disk-style filename. No bus access occurs. |
| `$E4C6` | `chkrcdsz` | Starts `34 06 9E 11 EC 01`. | Validates the requested record size against the selected format. No bus access occurs. |
| `$E570` | `ieegetsa` | Starts `32 7C C6 02 9E 13`. | Allocates an unused secondary address, starting at `$02`, from the active FCB list. No bus access occurs. |
| `$E5B9` | `ieedname` | Starts `BD E4 7D 9E 11 AE 04`. | Forms the disk filename with drive prefix and default `,SEQ` or `,PRG` type. No bus access occurs. |

#### Additional Waterloo application and support entries

For normal Waterloo calls, the first word argument is in D, subsequent word
arguments start at `2,S` on callee entry, and the caller removes those extra
arguments. `CALL.MACRO` implements this convention. D/B carry return values.
Use DP=0 and initialized system RAM. Application FCB pointers and their
parameter-block pointers at FCB+4 are distinct: the transport routines take
the latter, while the file API takes the former. Byte senders take the byte
in B and use the active parameter block at `$02`. `SetLstnr` takes a parameter
block in D plus a stacked secondary-command offset. `SetTalkr` takes the
parameter block in D. Preserve these distinctions in ROM tests.

| Address | Archived label or inferred role | Entry bytes | Required state and relevance |
|---|---|---|---|
| `$F303` | `monitor file-load command (unlabelled in OPSYSDIS.26)` | `32 E8 E6 BD B0 C6 E7 E4` | Reads a filename from default input, opens mode L through openf_, calls $F39E, and closes the FCB. Complete 26-byte-frame entry, distinct from loadcmd at $AC20. |
| `$F39E` | `addrf39e / monitor module reader` | `34 06 32 74 1F 41 C6 06` | FCB in D. Reads six-byte headers and payloads through $F3FB, checks errorf_, selects the bank via $EFFC for type 1, stops on type 2, and restores bank zero. Requires initialized monitor state. |
| `$F3FB` | `addrf3fb / monitor byte reader` | `34 06 EC 64 34 06 C3 00` | FCB in D, destination and nonzero count on stack. Copies bytes through fgetchar_ at $B0D8. Decrements the count after each byte; zero is not an empty transfer. |
| `$AC20` | `loadcmd` | `34 06 32 7D EC 63 34 06` | Filename string in D. Opens using mode L through openf_, invokes loadprog on success, and closes through closef_. `$AC30` is an internal argument-load instruction, not its entry. |
| `$AC59` | `loadprog` | `34 06 32 73 4F 5F DD 2A` | FCB in D. Reads six-byte module headers and payloads through progread, supports banked loads, checks errorf_, and sets the program-start vector. Requires initialized banks and FCB state. |
| `$ACFC` | `progread` | `34 06 EC 66 34 06 EC 66` | FCB in D, buffer and count on stack. Stack adapter to public sysread_ at `$B108`. |
| `$B1C1` | `initstd` | `BD D4 06 4F 5F DD 6B CC` | Initializes the FCB pool and default terminal input/output FCBs. Establishes defaults used by the application wrappers, not an IEEE reset. |
| `$B1E5` | `getchar` | `DC 6B 7E B2 A6 34 06 4F` | Reads one character from default input FCB `$6B` through fgetchar. |
| `$B1EA` | `putchar` | `34 06 4F E6 61 34 06 DC` | Byte in B. Writes through default output FCB `$6D` and fputchar. |
| `$B1F9` | `putnl` | `DC 6D 7E B3 24 34 06 EC` | Ends a record on default output FCB through fputnl. |
| `$B1FE` | `getrec` | `34 06 EC 64 34 06 EC 62` | Buffer in D, capacity on stack. Reads a record from default input through fgetrec. |
| `$B20F` | `putrec` | `34 06 EC 64 34 06 EC 62` | Buffer in D, length on stack. Writes a record to default output through fputrec. |
| `$B221` | `printf` | `35 10 34 06 34 10 1F 41` | Format string in D and variadic stack arguments. Repackages the return address and calls the archived sprintf formatter on default output. |
| `$B23B` | `openf` | `34 06 32 E8 CA BD D4 12` | Filename in D, mode-string pointer on stack. Allocates FCB, copies strings to workspace, calls sysopen and geterror, frees failed opens, and returns FCB or zero. |
| `$B292` | `closef` | `34 06 EC E4 BD C2 A5 EC` | FCB in D. Calls sysclose, geterror and freefcb. Generic file API, not the low-level CLOSE sender. |
| `$B2A6` | `fgetchar` | `34 06 32 7F AE 61 E6 98` | FCB in D. Reads through sysread and implements cached EOR/EOF and CR policy. |
| `$B2FD` | `fputchar` | `34 06 32 7F 4F E6 66 E7` | FCB in D, character word on stack. Calls syswrite for one byte and updates cached status. |
| `$B324` | `fputnl` | `34 06 CC FF FF 34 06 EC` | FCB in D. Calls sysnl with reset-status argument `$FFFF`. |
| `$B333` | `fgetrec` | `34 06 32 7E 4F 5F ED E4` | FCB in D, buffer and count on stack. Skips previous record, invokes sysread, returns count, and caches status. |
| `$B367` | `fputrec` | `34 06 EC E4 BD C7 F7 AE` | FCB in D, buffer and count on stack. Calls sysskip, syswrite and sysnl, caching status. |
| `$B3AA` | `fprintf` | `34 06 1F 41 C6 04 3A 34` | FCB in D, format and substitutions on stack. Calls the shared formatter. |
| `$B3BA` | `sprintf` | `34 06 32 E8 E5 EC F8 1F` | Archived name, not a memory-only C sprintf. FCB in D, argument-block pointer on stack. Formats through fputchar/fputnl and can therefore cause IEEE output. |
| `$B4A3` | `fseek` | `34 06 EC E4 BD C7 F7 AE` | FCB in D, record number on stack. Ends current record through sysskip, invokes sysseek and caches status. |
| `$B4C9` | `eor` | `34 06 AE E4 E6 03 C1 01` | FCB in D. Tests cached status at FCB+3 against 1. No bus transaction. |
| `$B4D3` | `eof` | `34 06 AE E4 E6 03 C1 02` | FCB in D. Tests cached status at FCB+3 against 2. No bus transaction. |
| `$B4E5` | `errorf` | `34 06 32 7F EC 61 26 07` | FCB in D, or zero for global status. A nonzero FCB can invoke geterror and a disk status read. |
| `$B510` | `errormsg` | `34 06 CC 03 00 32 62 39` | Returns pointer `$0300` to the global message buffer. Does not read the disk. |
| `$B518` | `scratchf` | `34 06 32 E8 D5 BD D4 12` | Filename in D. Allocates temporary FCB and workspace, dispatches sysscrat and frees the FCB. |
| `$B543` | `renamef` | `34 06 32 E8 AC BD D4 12` | Old filename in D, new-name pointer on stack. Allocates temporary FCB/workspace and dispatches sysrenam. |
| `$B58B` | `mount` | `34 06 32 E8 D5 BD D4 12` | Device/drive string in D. Allocates temporary FCB/workspace and dispatches sysmount. |
| `$B5BD` | `timeout` | `34 06 AE E4 AE 04 34 10` | FCB in D, timeout word on stack. Sets parameter-block+7. Zero selects unbounded handshake waits. No bus transaction. |
| `$B5D2` | `diropenf` | `34 06 32 E8 D5 BD D4 12` | Device/drive string in D. Allocates an FCB and calls sysdirop. Returns FCB or zero. Binary prologue allocates 43 bytes despite archive placeholder. |
| `$B610` | `dirreadf` | `34 06 EC 64 34 06 EC 62` | Directory FCB in D, destination buffer on stack. Calls sysdirrd and caches status. |
| `$B627` | `dirclosef` | `34 06 EC E4 BD CB 98 EC` | Directory FCB in D. Calls sysdircl then freefcb. |
| `$B636` | `global status clear` | `0F 6A 8E 03 00 6F 84 39` | Clears `$6A` and first message byte at `$0300`. Called by system I/O and allocation. No bus transaction. |
| `$B63E` | `global EOF setter` | `C6 02 D7 6A CC 03 00 34` | Sets `$6A=2` and copies eof to `$0300`. Does not receive a byte. |
| `$B650` | `timeout error setter` | `CC B6 6A 34 06 C6 03 D7` | Loads timeout message and falls through `$B653`. Sets global error 3. Does not perform a handshake. |
| `$B653` | `global error-message setter` | `34 06 C6 03 D7 6A CC 03` | Message pointer in D. Own prologue saves D, sets `$6A=3`, and copies the message to `$0300`. Independent callable entry, not an unsafe tail. |
| `$C4D2` | `sysrdbyt / MAP sysread7` | `34 06 32 7D CC 00 06 BD` | FCB in D. Complete byte-input dispatcher, hook 6. Resolves FCB+4 and calls `$D33B` for IEEE. It is not a sysread continuation despite the MAP name. |
| `$C669` | `outbyte` | `34 06 32 7E CC 00 07 BD` | FCB in D, byte on stack. Complete output dispatcher, hook 7. Resolves FCB+4 and calls `$D37B` for IEEE. |
| `$C9A5` | `getacmod` | `34 06 EC 64 BD B7 B1 34` | Parameter block in D, mode string on stack. Decodes mode through the table at `$B18C` and sets access flags or error. No bus access. |
| `$CA15` | `chekcod2` | `34 06 AE E4 E6 98 04 C1` | FCB in D. Tests parameter-block status for EOF (2), returning boolean D. Complete leaf helper even without a direct caller in the audited graph. |
| `$CA20` | `chekcod1` | `34 06 AE E4 E6 98 04 C1` | FCB in D. Tests parameter-block status for EOR (1), returning boolean D. Called repeatedly by sysread. |
| `$D406` | `initfcbs` | `CC 05 7F DD 75 DD 73 9E` | Initializes FCB-pool bounds `$73/$75` to `$057F` and clears its sentinel. Called by initstd. No bus access. |
| `$D412` | `asignfcb` | `32 7A BD B6 36 DC 75 ED` | Allocates a 26-byte slot downward within `$0480-$057F`, links it into the FCB ring and initializes status. Returns FCB in D or zero plus an error. No bus access. |
| `$D483` | `freefcb` | `34 06 32 7C EC 64 C3 FF` | FCB in D, valid circular FCB list required. Unlinks and marks the slot free, coalesces the pool boundary. No bus access. |
| `$E476` | `invfname` | `9E 68 E6 84 26 3D 39 9E` | Checks the remaining filename text at `$68`, using the existing parser state. Returns if empty, otherwise enters the invalid-filename error tail. |
| `$E4DF` | `record-format parser` | `32 7E 4F 5F 9E 11 ED 01` | Uses parser globals `$11/$13/$68`. Initializes and parses record format and optional record size. Called by chkfname. No bus access. |
| `$E6C0` | `alphabetic-prefix scanner` | `32 7E DC 68 ED E4 4F E6` | Returns the length of the alphabetic prefix at `$68`. Used by device and format parsing. |
| `$E6D5` | `numeric-prefix scanner` | `32 7E DC 68 ED E4 4F E6` | Returns the length of the numeric prefix at `$68`. Used by primary, secondary, drive and record-size parsing. |
| `$E6F1` | `consume filename prefix` | `34 06 DC 68 34 06 E3 62` | Count in D. Removes that many bytes from the string at `$68` using the overlapping copy helper. No bus access. |
| `$E76B` | `system I/O hook dispatch` | `1F 01 E6 89 05 80 27 06` | Hook index in D. Tests byte at `$0580+index`, otherwise returns. If enabled, jumps indirectly through `$05C0+index`. Clear hooks for native-ROM tests. |
| `$E77A` | `clear system I/O hooks` | `32 7E CC 05 80 ED E4 83` | Clears `$0580-$05FF`. Called by sysioini. Prevents user hooks from changing native I/O behavior. |
| `$DD48` | `keyboard/PIA1 initialization` | `C6 1E F7 01 2A 7F 01 2B` | Called by terminal initialization. Programs `$E810/$E811/$E813`, including releasing EOI. Shared hardware setup, not a complete IEEE initialization. |
| `$FE74` | `early PIA1/clock initialization` | `32 79 C6 FF F7 EF F1 7F` | Called during restart. Clears PIA1 control and data/direction registers before sysioini configures IEEE. Not a focused bus operation. |
| `$F000` | `restart1` | `10 CE 02 20 BD FE 74 BD` | Boot entry sets S itself, calls `$FE74` and system I/O initialization, then enters startup. Not a subroutine returning to a test caller. |
| `$FF80` | `reset-vector target` | `8E FF B1 C6 07 10 8E 01` | Reached through hardware vector `$FFFE`. Initializes interrupt dispatch and jumps to restart1. Do not invoke with JSR expecting a return. |

#### Waterloo public file and disk vectors

Each row is an independently verified three-byte JMP. These application ABI
entries are relevant even though the trampoline itself has no electrical
behavior. Date/time, generic request, and keyboard-enable vectors interleaved
in this block are excluded from the file/disk API and recorded in the ledger.

| Address | Public label | Implementation target | Exact bytes |
|---|---|---|---|
| `$B09F` | `diropenf_` | `$B5D2` | `7E B5 D2` |
| `$B0A2` | `dirreadf_` | `$B610` | `7E B6 10` |
| `$B0A5` | `dirclose_` | `$B627` | `7E B6 27` |
| `$B0A8` | `sysioini_` | `$C1F5` | `7E C1 F5` |
| `$B0AB` | `initstd_` | `$B1C1` | `7E B1 C1` |
| `$B0AE` | `openf_` | `$B23B` | `7E B2 3B` |
| `$B0B1` | `closef_` | `$B292` | `7E B2 92` |
| `$B0B4` | `fseek_` | `$B4A3` | `7E B4 A3` |
| `$B0B7` | `printf_` | `$B221` | `7E B2 21` |
| `$B0BA` | `putrec_` | `$B20F` | `7E B2 0F` |
| `$B0BD` | `putchar_` | `$B1EA` | `7E B1 EA` |
| `$B0C0` | `putnl_` | `$B1F9` | `7E B1 F9` |
| `$B0C3` | `getrec_` | `$B1FE` | `7E B1 FE` |
| `$B0C6` | `getchar_` | `$B1E5` | `7E B1 E5` |
| `$B0C9` | `fprintf_` | `$B3AA` | `7E B3 AA` |
| `$B0CC` | `fputrec_` | `$B367` | `7E B3 67` |
| `$B0CF` | `fputchar_` | `$B2FD` | `7E B2 FD` |
| `$B0D2` | `fputnl_` | `$B324` | `7E B3 24` |
| `$B0D5` | `fgetrec_` | `$B333` | `7E B3 33` |
| `$B0D8` | `fgetchar_` | `$B2A6` | `7E B2 A6` |
| `$B0DB` | `eor_` | `$B4C9` | `7E B4 C9` |
| `$B0DE` | `eof_` | `$B4D3` | `7E B4 D3` |
| `$B0E1` | `errorf_` | `$B4E5` | `7E B4 E5` |
| `$B0E4` | `errormsg_` | `$B510` | `7E B5 10` |
| `$B0E7` | `mount_` | `$B58B` | `7E B5 8B` |
| `$B0EA` | `scratchf_` | `$B518` | `7E B5 18` |
| `$B0ED` | `renamef_` | `$B543` | `7E B5 43` |
| `$B105` | `timeout_` | `$B5BD` | `7E B5 BD` |
| `$B108` | `sysread_` | `$C2D8` | `7E C2 D8` |
| `$B10B` | `syswrite_` | `$C52C` | `7E C5 2C` |
| `$B10E` | `sysnl_` | `$C6C6` | `7E C6 C6` |

The standard PET I/O range `$E800-$EFFF` lies inside the 6809 ROM address
range but must override ROM. In particular, `$E820-$E83F` must select PIA2 and
`$E840-$E87F` must select the VIA. This is required by the direct register
accesses above, matches
[VICE `petmem.c`](https://github.com/VICE-Team/svn-mirror/blob/main/vice/src/pet/petmem.c),
and is implemented by
[`address_decoding.sv`](../../gw/EconoPET/src/address_decoding.sv). A test that
loads the Waterloo ROM without this I/O hole cannot establish IEEE behavior.

For TALK termination and counted-read continuation, trace these routines:

- `$C13C` calls `$C14F`, sends UNTALK byte `$5F`, then calls `$C16E` to
  release ATN.
- `$C14F-$C16D` releases NRFD by setting `$E840` bit 1, releases NDAC by
  setting `$E821` bit 3, waits for DAV to release through `$E840` bit 7, then
  clears `$E840` bit 2 to assert ATN.
- `$C16E-$C175` sets `$E840` bit 2 to release ATN.

Tests that claim Waterloo compatibility must reproduce this register-write and
handshake order. Do not substitute ATN-before-NDAC termination. A fast FPGA
talker can already have the next byte's DAV asserted when `$C14F` releases
NDAC, so review FIFO advancement and resumed TALK data explicitly.

Do not use PET 6502 BASIC or KERNAL memory-map labels as symbols for the
Waterloo 6809 ROMs merely because an address matches. Derive routine boundaries
and behavior from the pinned Waterloo binaries and their call sites.

The Waterloo module-load path starts at `loadcmd` `$AC20`. `$AC30` is an
internal instruction preparing the mode pointer before the call at `$AC37`
to `openf_` `$B0AE`, which jumps to `openf` `$B23B`. Its call at `$B240`
reaches `asignfcb` `$D412`. The allocator examines RAM pool/list state,
returns zero on exhaustion, and performs no IEEE transaction. A successful
allocation continues through `sysopen` `$C244`, `ieeopen` `$D28C`, and the
normal OPEN sender, then `geterror`. Successful module reads use `loadprog`
`$AC59` and `progread` `$ACFC` through `sysread_` `$B108`. This resolves the
static call path, not the cause of a particular failed runtime load. Displayed
`Loading` or `Program not found` text alone is not compatibility evidence.

The exhaustive address/disposition ledger and reproducible validation command
are documented in [the ROM entry audit](../../docs/dev/PET/ieee-rom-entry-audit.md).
That audit verifies addresses and static calling contracts. It does not claim
that every listed entry has an executed full-ROM compatibility test.

## Corroborating Sources

Use at least one independent secondary source for ordinary changes and two when
the ROM is ambiguous, timing-sensitive, or model-dependent.

- Michael Steil's Commodore Peripheral Bus series:
  - [Part 1: IEEE-488](https://www.pagetable.com/?p=1023)
  - [Part 2: TALK/LISTEN](https://www.pagetable.com/?p=1031)
  - [Part 3: Commodore DOS](https://www.pagetable.com/?p=1038)
- VICE ROM-level IEEE-drive emulation:
  - [vice/src/drive/ieee/ieee.c](https://github.com/VICE-Team/svn-mirror/blob/main/vice/src/drive/ieee/ieee.c)
  - [vice/src/drive/iecieee/iecieee.c](https://github.com/VICE-Team/svn-mirror/blob/main/vice/src/drive/iecieee/iecieee.c)
- MAME original-hardware models:
  - [c2040.cpp](https://github.com/mamedev/mame/blob/master/src/devices/bus/ieee488/c2040.cpp)
  - [c8050.cpp](https://github.com/mamedev/mame/blob/master/src/devices/bus/ieee488/c8050.cpp)
  - [ieee488.cpp](https://github.com/mamedev/mame/blob/master/src/devices/bus/ieee488/ieee488.cpp)
  - [c4040_dsk.cpp](https://github.com/mamedev/mame/blob/master/src/lib/formats/c4040_dsk.cpp)
  - [d80_dsk.cpp](https://github.com/mamedev/mame/blob/master/src/lib/formats/d80_dsk.cpp)
- PET Universal for MiSTer:
  - [rtl/ieee_drive/ieee_drive.sv](https://github.com/raparici/PET_Universal_MiSTer/blob/main/rtl/ieee_drive/ieee_drive.sv)
  - [rtl/ieee_drive/ieeedrv_drv.sv](https://github.com/raparici/PET_Universal_MiSTer/blob/main/rtl/ieee_drive/ieeedrv_drv.sv)
  - [rtl/ieee_drive/ieeedrv_logic.sv](https://github.com/raparici/PET_Universal_MiSTer/blob/main/rtl/ieee_drive/ieeedrv_logic.sv)
- Repository summaries and original-hardware references:
  - [docs/dev/PET/ieee.md](../../docs/dev/PET/ieee.md)
  - [PET and the IEEE-488 Bus](http://www.primrosebank.net/computers/pet/documents/PET_and_the_IEEE488_Bus_text.pdf)
  - [Rockwell R6520 PIA](http://archive.6502.org/datasheets/rockwell_r6520_pia.pdf)
  - [Western Design Center W65C22 VIA](https://www.westerndesigncenter.com/wdc/documentation/w65c22.pdf)

## Required Workflow

1. Define the exact observable behavior being changed and select the target
   peripheral and ROM revision.
2. Trace the complete EconoPET path across gateware, FIFOs/registers, firmware,
   disk-image access, and caller-visible output.
3. Trace the corresponding primary ROM routine from entry through all relevant
   calls, tables, flags, and error exits. Do not rely on routine names or
   comments alone.
4. Record the exact bytes, state transitions, status, EOI behavior, and edge
   cases established by the primary source.
5. Corroborate the conclusion with the required independent sources. Explain
   any disagreement.
6. Implement the change that matches the selected Commodore behavior.
7. Add tests derived from the primary behavior, including negative, boundary,
   state-transition, repeated-operation, and multi-unit/channel cases.
8. Run the set of relevant tests, then the complete affected suite.
9. Include the compatibility evidence in the final implementation summary or
   code-review report.

## Required Evidence

For every changed or reviewed behavior, provide a table with this shape:

| Behavior | Target peripheral/ROM | Primary source and routine | Required observable result | EconoPET code and test | Corroboration |
|---|---|---|---|---|---|

Use exact file links and routine labels. State the ROM-derived rule in concrete
terms, such as command bytes, channel state, returned bytes, error code, EOI
position, track/sector values, or handshake transitions.

Do not claim compatibility based only on:

- passing existing tests
- agreement with VICE, MAME, MiSTer, or pagetable
- comments in EconoPET code
- general Commodore DOS documentation
- behavior observed in one happy-path program

If primary evidence is unavailable or ambiguous, stop and report the gap. Do
not describe the behavior as compatible until it is resolved through another
ROM revision, a real-hardware trace, or equivalent primary evidence.

## Implementation and Review Gates

Report an incomplete implementation when changed behavior lacks a primary ROM
citation, an exact compatibility conclusion, or a ROM-derived test.

Report a compatibility defect when EconoPET bytes, state transitions, status,
EOI, filesystem interpretation, or handshake behavior differs from the
selected Commodore source.

Report insufficient evidence when a conclusion relies only on secondary
sources or existing EconoPET behavior.

Report a model-selection defect when 4040 behavior is applied to an 8050/8250
path, or the reverse, without evidence that the ROMs agree.

Report an extension-boundary defect when EconoPET-specific behavior leaks into
native D64/D80, channel, status, or IEEE semantics.

For code reviews, treat every gate above as actionable. For implementations,
resolve each gate before declaring the task complete.

## Validation

Use the relevant commands:

```sh
cmake --build --preset fw-test
ctest --preset fw --parallel --output-on-failure
ctest --preset gw --parallel -R 'ieee_.*tb' --output-on-failure
```

Run both Icarus and Verilator variants when gateware behavior changes:
`ieee_tb`, `ieee_tb_vl`, `ieee_sys_tb`, and `ieee_sys_tb_vl`.

Tests must assert exact compatibility outputs. Avoid tests that check only that
an operation succeeds.

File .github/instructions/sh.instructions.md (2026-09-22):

---
description: 'Shell script conventions for EconoPET build, simulation, and tooling scripts'
applyTo: '**/*.sh'
---

# Shell Script Guidelines

Conventions for the `.sh` scripts that drive the build, simulation, and tooling flows (`build.sh`, `sim.sh`, `verilate.sh`, `seed.sh`, and the helpers under `.devcontainer/`, `gw/`, and `tools/`).

## Interpreter

- Start every shell script with `#!/usr/bin/env bash`. It resolves bash through `PATH`, so the same script works in the dev container and on a host where bash lives outside `/bin` (Homebrew on macOS, `/usr/local/bin` on BSD, Nix).
- Never omit the shebang. An executable script without one runs under `sh`, where bash builtins such as `pushd` and `[[` fail.
- Keep options out of the shebang. `env` does not pass flags portably, so put them in a `set` line instead.
- Leave a non-bash shebang alone. A few files carry a `.sh` extension but are not shell (`docs/dev/PET/scripts/*.sh` are perl and keep `#!/usr/bin/perl`).

## Executable Bit

Commit every `.sh` file mode `100755`. CMake and the scripts themselves invoke each other directly (`CTestCustom.cmake.in` runs `seed.sh --write` as a pre-test hook, `sim.sh` and `verilate.sh` exec `seed.sh`), so a non-executable script fails with "permission denied" on a fresh clone.

This repository sets `core.fileMode=false`, so `chmod +x` alone stages nothing and git never reports the drift. Set the bit in the index:

```sh
git update-index --chmod=+x path/to/script.sh
```

## File Header

Follow the shebang with the SPDX header (see `fw/src/main.c`), a one-line statement of purpose, and a `Usage:` line when the script takes arguments.

### Good Example

```sh
#!/usr/bin/env bash
# SPDX-License-Identifier: CC0-1.0
# https://github.com/dlehenbauer/econopet
#
# Compile and run a gateware testbench under Verilator (--binary --timing).
# Usage: ./verilate.sh TEST_NAME [RAND_RESET]
#   RAND_RESET: 0 (default; required for m6502), 1 (all ones), or 2 (random).

set -e
```

### Bad Example

```sh
#!/bin/bash -e
cd build
make
```

## Conventions

- Use `set -e` so a failed step stops the script. Add `-uo pipefail` when the script has pipelines or reads variables that may be unset.
- Quote expansions (`"$VAR"`, `"$@"`) and give optional arguments a default (`"${2:-0}"`).
- Resolve paths relative to the script, not the caller's working directory (`SCRIPT_DIR="$(readlink -f $(dirname "$0"))"`).
- Name scripts in lowercase with hyphens (`download.sh`, `lcsc-import.sh`).

## Validation

```sh
bash -n path/to/script.sh                       # Syntax check (no execution)
git ls-files -s '*.sh' | awk '$1 != "100755"'   # Lists any script missing the executable bit
git grep -l '^#!/bin/bash' -- '*.sh'            # Lists any script with a hardcoded interpreter
```

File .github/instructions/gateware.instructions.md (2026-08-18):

---
description: 'SystemVerilog coding conventions and patterns for FPGA gateware development'
applyTo: 'gw/**/*.sv, gw/**/*.v, gw/**/*.svh'
---

# Gateware Development Guidelines

Instructions for developing SystemVerilog gateware for the Efinix FPGA.

## Module Organization

| Module | Purpose |
|---|---|
| `top.sv` | Normalizes hardware signals (inverts active-low pins) |
| `main.sv` | Contains core logic with active-high internal signals |

## Signal Conventions

- Use active-high signals internally
- The `top` module inverts active-low hardware pins at the boundary
- Use "controller" and "peripheral" instead of deprecated "master" and "slave" terminology for all buses (Wishbone, SPI, I2C, etc.):

| Use | Instead of |
|-----|---|
| Controller | Master |
| Peripheral | Slave |

### Naming Suffixes

| Suffix | Meaning | Example |
|---|---|---|
| `_i` | Input port | `clock_i` |
| `_o` | Output port | `data_o` |
| `_n` | Active-low  | `reset_n` |
| `_ni` | Active-low input | `cs_ni` |
| `_no` | Active-low output | `irq_no` |
| `_en` | Enable signal | `write_en` |
| `_oe` | Output enable | `data_oe` |
| `_d` | Combinational next state (D input) | `state_d` |
| `_q` | Registered output (Q output) | `state_q` |

### Wishbone Bus Prefixes

| Prefix | Meaning | Example |
|---|---|---|
| `wb_` | Shared Wishbone bus signals | `wb_addr` |
| `wbc_` | Wishbone controller signals | `wbc_addr_o` |
| `wbp_` | Wishbone peripheral signals | `wbp_addr_i` |

### SPI Signal Names

For SPI signals specifically, follow the [OSHWA resolution](https://oshwa.org/resources/a-resolution-to-redefine-spi-signal-names/):

| Use | Instead of |
|-----|---|
| `SDO` / `SDI` | `MOSI` / `MISO` |
| `PICO` / `POCI` | (for bidirectional devices) |
| `CS` | `SS` |

## Testbenches

- Name testbenches with `*_tb.sv` suffix
- Place testbenches in `gw/EconoPET/sim/`
- Each testbench is standalone and auto-discovered by CTest
- Use TB_INIT and assertion macros from `gw/EconoPET/sim/tb.svh`:
  - `` `TB_INIT `` - emits an `initial` block that sets up VCD dumping, runs the `run` task, and calls `$finish`
  - `` `assert_equal(actual, expected) `` - compare with detailed error messages
  - `` `assert_exact_equal(actual, expected) `` - strict equality check
  - `` `assert_compare(actual, op, expected) `` - comparison with operator

## Running Testbenches

```sh
./sim.sh                  # Run all tests in parallel
./sim.sh spi_tb           # Run the specified test only
./sim.sh --update-only    # Regenerate simulation file lists and exit
./sim.sh --no-update spi_tb # Run one test with existing file lists
```

## Adding New Files

When adding new `*.sv` or `*.v` files, they must be registered in the project:

- Source files (`src/*.sv`): Add `<efx:design_file name="src/mymodule.sv" .../>` in the `<efx:design_info>` section
- Simulation files (`sim/*.sv`): Add `<efx:sim_file name="sim/mymodule_tb.sv"/>` in the `<efx:sim_info>` section

**Critical:** New sources and testbenches must be added in `EconoPET.xml` or they will be excluded from build and test.

## Verification Checklist

- [ ] If the change is testable, add or update a `*_tb.sv` file in `gw/EconoPET/sim/` to add coverage
- [ ] Update `gw/EconoPET/EconoPET.xml` to register new source and test files or remove deleted files
- [ ] Run `./sim.sh` and verify all tests pass
- [ ] Update timing constraints per [timing-analysis/SKILL.md](/.github/skills/timing-analysis/SKILL.md)
- [ ] Only if tests pass, run `cmake --build --preset gw`

**Critical:** Never start gateware build when simulation tests are failing. The gateware build is slow (~2 min) and simulation catches most issues.

## External Dependencies

The `/gw/EconoPET/external` directory contains git submodules. Do not modify files in this path without explicit confirmation.

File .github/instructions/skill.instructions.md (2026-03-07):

---
description: 'Guidelines for authoring AI agent skills following the Agent Skills specification'
applyTo: '**/SKILL.md'
---

# Agent Skills Authoring Guidelines

Instructions for creating skills that follow the Agent Skills specification (https://agentskills.io/specification).

## What Are Agent Skills?

Agent Skills are self-contained directories with instructions and bundled resources that teach AI agents specialized capabilities. Unlike custom instructions (which define coding standards), skills enable task-specific workflows that can include scripts, templates, examples, and reference data.

Key characteristics:

- Portable across VS Code, Copilot CLI, and Copilot coding agent
- Progressive loading (only loaded when relevant to the user's request)
- Resource-bundled (can include scripts, templates, examples alongside instructions)
- Activated automatically based on prompt relevance

## Directory Structure

Skills are stored in `.github/skills/<skill-name>/`. Each skill lives in its own directory named to match the `name` field in SKILL.md:

```
.github/skills/my-skill/
  SKILL.md              # Required: main instructions
  scripts/              # Optional: executable automation
  references/           # Optional: documentation loaded on demand
  assets/               # Optional: static files used as-is in output
  templates/            # Optional: starter code the agent modifies
```

## SKILL.md Format

### Frontmatter (Required)

Every SKILL.md must begin with YAML frontmatter containing at minimum `name` and `description`:

```yaml
---
name: skill-name
description: What this skill does and when to use it.
---
```

#### Required Fields

| Field | Limit | Rules |
|---|---|---|
| name | 1-64 chars | Lowercase alphanumeric and hyphens only. No leading, trailing, or consecutive hyphens. Must match parent directory name. |
| description | 1-1024 chars | Describe what the skill does, when to use it, and include keywords for discovery. |

#### Optional Fields

| Field | Limit | Purpose |
|---|---|---|
| license | -- | License name or reference to a bundled license file |
| compatibility | 1-500 chars | Environment requirements (product, system packages, network access) |
| metadata | key-value map | Arbitrary additional properties (use unique key names to avoid conflicts) |
| allowed-tools | space-delimited | Pre-approved tools the skill may use (experimental) |

### Writing Effective Descriptions

The `description` field is the primary mechanism for automatic skill discovery. Agents read only `name` and `description` to decide whether to load a skill. Include three things:

1. WHAT the skill does (capabilities)
2. WHEN to use it (specific triggers, scenarios, file types, or user requests)
3. KEYWORDS matching terms users would include in their prompts

Good:

```yaml
description: Toolkit for testing local web applications using Playwright. Use
  when asked to verify frontend functionality, debug UI behavior, capture browser
  screenshots, check for visual regressions, or view browser console logs.
  Supports Chrome, Firefox, and WebKit browsers.
```

Bad:

```yaml
description: Web testing helpers.
```

The bad example fails because it has no specific triggers, no keywords, and no capabilities.

### Body Content

The body contains detailed instructions loaded after the skill is activated. Recommended sections:

| Section | Purpose |
|---|---|
| Overview | Brief summary of what this skill enables |
| When to Use | Scenarios that trigger this skill (reinforces description) |
| Prerequisites | Required tools, dependencies, environment setup |
| Step-by-Step Workflows | Numbered steps for common tasks |
| Troubleshooting | Common issues and solutions |
| References | Links to bundled docs or external resources |

## Progressive Disclosure

Structure skills for efficient context usage. Agents load content in three tiers:

1. **Discovery (~100 tokens)**: `name` and `description` loaded at startup for all skills
2. **Instructions (target < 5000 tokens)**: Full SKILL.md body loaded when the request matches the description
3. **Resources (on demand)**: Files in `scripts/`, `references/`, `assets/`, and `templates/` loaded only when the agent references them

This means many skills can be installed without consuming context. Keep SKILL.md under 500 lines. Move detailed reference material to separate files.

## Bundling Resources

### Resource Types

| Directory | Purpose | Loaded into context? | Examples |
|---|---|---|---|
| scripts/ | Executable automation | When executed | helper.py, validate.sh |
| references/ | Documentation the agent reads | When referenced | api_reference.md, schema.md |
| assets/ | Static files used as-is in output | No | logo.png, report-template.html |
| templates/ | Starter code the agent modifies | When referenced | scaffold.py, config.template |

### Assets vs Templates

- **Assets** are static resources consumed unchanged (a logo embedded into a generated document, a font applied to rendered text)
- **Templates** are starter code or scaffolds the agent actively modifies (a config file the agent fills in, a project directory the agent extends)

Rule of thumb: if the agent reads and builds upon the content, use `templates/`. If the file is used as-is in output, use `assets/`.

### Referencing Resources

Use relative paths from the skill root:

```markdown
See [API reference](./references/api_reference.md) for detailed documentation.

Run the extraction script:
scripts/extract.py
```

Keep references one level deep from SKILL.md. Avoid deeply nested reference chains.

## Writing Style

- Use imperative mood: "Run", "Create", "Configure" (not "You should run")
- Be specific and actionable
- Include exact commands with parameters
- Show expected outputs where helpful
- Keep sections focused and scannable

## Scripts

Scripts in `scripts/` must:

- Be self-contained or clearly document dependencies
- Include help/usage documentation (`--help` flag)
- Handle errors gracefully with clear messages
- Avoid storing credentials or secrets
- Use relative paths where possible

Prefer cross-platform languages:

| Language | Good for |
|---|---|
| Python | Complex automation, data processing |
| Node.js | JavaScript-based tooling |
| Bash/Shell | Simple automation tasks |

### When to Bundle Scripts

Include scripts when:

- The same code would be rewritten repeatedly by the agent
- Deterministic reliability is critical (file manipulation, API calls)
- Complex logic benefits from being pre-tested rather than generated each time
- The operation has a self-contained purpose that can evolve independently
- Predictable behavior is preferred over dynamic generation

### Security

- Rely on existing credential helpers (no credential storage in scripts)
- Include `--force` flags only for destructive operations
- Warn users before irreversible actions
- Document any network operations or external calls

### Scratch Data

- Store repo-local AI logs, traces, and temporary state under `.cache/ai/`

## Name Validation

Valid:
- `pdf-processing`
- `data-analysis`
- `code-review`

Invalid:
- `PDF-Processing` (uppercase not allowed)
- `-pdf` (cannot start with hyphen)
- `pdf-` (cannot end with hyphen)
- `pdf--processing` (consecutive hyphens not allowed)

## Workflow Execution Pattern

For multi-step workflows, create a TODO list where each step references the relevant documentation:

```markdown
## TODO
- [ ] Step 1: Configure environment (see [workflow-setup.md](./references/workflow-setup.md#environment))
- [ ] Step 2: Build project (see [workflow-setup.md](./references/workflow-setup.md#build))
- [ ] Step 3: Deploy to staging (see [workflow-deployment.md](./references/workflow-deployment.md#staging))
```

This ensures traceability and allows resuming workflows if interrupted. Split large workflows (more than 5 steps) into separate reference files.

## Validation Checklist

Before publishing a skill:

- [ ] SKILL.md has valid frontmatter with `name` and `description`
- [ ] `name` is lowercase with hyphens, at most 64 characters, matches directory name
- [ ] `description` clearly states WHAT it does, WHEN to use it, and relevant KEYWORDS
- [ ] Body includes when to use, prerequisites, and step-by-step workflows
- [ ] If SKILL.md exceeds 500 lines, warn the user but do not shorten it unless asked
- [ ] Large workflows split into `references/` with clear links from SKILL.md
- [ ] Scripts include help documentation and error handling
- [ ] Relative paths used for all resource references
- [ ] No hardcoded credentials or secrets

## Additional Resources

- [Agent Skills Specification](https://agentskills.io/specification)
- [Awesome Copilot Agent Skills Instructions](https://github.com/github/awesome-copilot/blob/main/instructions/agent-skills.instructions.md)

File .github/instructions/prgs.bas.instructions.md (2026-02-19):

---
description: 'BASIC coding conventions for Commodore PET/CBM test and utility programs compiled with petcat'
applyTo: 'prgs/**/*.bas'
---

# PET/CBM BASIC Program Guidelines

Test and utility programs written in Commodore BASIC for the PET/CBM. Source files use VICE `petcat` text format and are compiled to `.prg` with the `petcat` tool.

## Toolchain

Programs are compiled with `petcat` (from VICE). The standard invocation is:

```sh
petcat -h -v -l 401 -w1p -o output.prg -- input.bas
```

| Flag | Purpose |
| --- | --- |
| `-h` | Write load address header in output |
| `-v` | Verbose output |
| `-l 401`| Set load address to $0401 (PET BASIC start) |
| `-w1p`  | Target PET/CBM BASIC 1.0+ tokenization |
| `-o` | Output file path |

## Project Layout

Each program lives in its own subdirectory under `prgs/`. Name the subdirectory and the `.bas` source file identically (e.g., `hello/hello.bas`). Register new subdirectories in `prgs/CMakeLists.txt`.

### CMakeLists.txt Template

Use `prgs/hello/CMakeLists.txt` as the build template. Key elements:

```cmake
find_program(PETCAT_EXECUTABLE petcat REQUIRED)

set(PRG_NAME example.prg)

add_custom_command(
    OUTPUT ${BIN_DIR}/${PRG_NAME}
    COMMAND ${CMAKE_COMMAND} -E make_directory ${BIN_DIR}
    COMMAND ${PETCAT_EXECUTABLE} -h -v -l 401 -w1p -o ${BIN_DIR}/${PRG_NAME} -- ${SRC_DIR}/example.bas
    DEPENDS ${SRC_DIR}/example.bas
    COMMENT "Building ${PRG_NAME}"
    VERBATIM
)
```

## BASIC Coding Conventions

- Write all BASIC keywords in lowercase (`print`, `goto`, `peek`, `poke`)
- Use explicit line numbers, starting at 10 and incrementing by 10
- Use `peek()` and `poke` for direct memory access
- Keep lines short (under 80 characters) for readability
- Use `rem` for comments (sparingly, since they consume PET memory)

### Good Example

```basic
10 print "hello"
20 goto 10
```

### Bad Example

```basic
10 PRINT "HELLO"
20 GOTO 10
```

## Build and Verify

```sh
cmake --build --preset prgs    # Build all BASIC programs
```

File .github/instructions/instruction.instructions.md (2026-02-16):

---
description: 'Guidelines for creating high-quality instruction files for GitHub Copilot'
applyTo: '**/*.instructions.md'
---

# Instructions File Guidelines

Instructions for creating effective and maintainable instruction files that guide GitHub Copilot in generating domain-specific code and following project conventions.

## Project Context

- Target audience: Developers and GitHub Copilot working with domain-specific code
- File format: Markdown with YAML frontmatter
- File naming convention: lowercase with hyphens (e.g., `react-best-practices.instructions.md`)
- Location: `.github/instructions/` directory
- Purpose: Provide context-aware guidance for code generation, review, and documentation

## Required Frontmatter

Every instruction file must include YAML frontmatter with the following fields:

```yaml
---
description: 'Brief description of the instruction purpose and scope'
applyTo: 'glob pattern for target files (e.g., **/*.ts, **/*.py)'
---
```

### Frontmatter Guidelines

- **description**: Single-quoted string, 1-500 characters, clearly stating the purpose
- **applyTo**: Glob pattern(s) specifying which files these instructions apply to
  - Single pattern: `'**/*.ts'`
  - Multiple patterns: `'**/*.ts, **/*.tsx, **/*.js'`
  - Specific files: `'src/**/*.py'`
  - All files: `'**'`

## File Structure

A well-structured instruction file should include the following sections:

### 1. Title and Overview

- Clear, descriptive title using `#` heading
- Brief introduction explaining the purpose and scope
- Optional: Project context section with key technologies and versions

### 2. Core Sections

Organize content into logical sections based on the domain:

- **General Instructions**: High-level guidelines and principles
- **Best Practices**: Recommended patterns and approaches
- **Code Standards**: Naming conventions, formatting, style rules
- **Architecture/Structure**: Project organization and design patterns
- **Common Patterns**: Frequently used implementations
- **Security**: Security considerations (if applicable)
- **Performance**: Optimization guidelines (if applicable)
- **Testing**: Testing standards and approaches (if applicable)

### 3. Examples and Code Snippets

Provide concrete examples with clear labels:

```markdown
### Good Example
\`\`\`language
// Recommended approach
code example here
\`\`\`

### Bad Example
\`\`\`language
// Avoid this pattern
code example here
\`\`\`
```

### 4. Validation and Verification (Optional but Recommended)

- Build commands to verify code
- Linting and formatting tools
- Testing requirements
- Verification steps

## Content Guidelines

### Writing Style

- Use clear, concise language
- Write in imperative mood ("Use", "Implement", "Avoid")
- Be specific and actionable
- Avoid ambiguous terms like "should", "might", "possibly"
- Use bullet points and lists for readability
- Keep sections focused and scannable

### Best Practices

- **Be Specific**: Provide concrete examples rather than abstract concepts
- **Show Why**: Explain the reasoning behind recommendations when it adds value
- **Use Tables**: For comparing options, listing rules, or showing patterns
- **Include Examples**: Real code snippets are more effective than descriptions
- **Stay Current**: Reference current versions and best practices
- **Link Resources**: Include official documentation and authoritative sources

### Common Patterns to Include

1. **Naming Conventions**: How to name variables, functions, classes, files
2. **Code Organization**: File structure, module organization, import order
3. **Error Handling**: Preferred error handling patterns
4. **Dependencies**: How to manage and document dependencies
5. **Comments and Documentation**: When and how to document code
6. **Version Information**: Target language/framework versions

## Patterns to Follow

### Bullet Points and Lists

```markdown
## Security Best Practices

- Always validate user input before processing
- Use parameterized queries to prevent SQL injection
- Store secrets in environment variables, never in code
- Implement proper authentication and authorization
- Enable HTTPS for all production endpoints
```

### Tables for Structured Information

```markdown
## Common Issues

| Issue            | Solution            | Example                       |
| ---------------- | ------------------- | ----------------------------- |
| Magic numbers    | Use named constants | `const MAX_RETRIES = 3`       |
| Deep nesting     | Extract functions   | Refactor nested if statements |
| Hardcoded values | Use configuration   | Store API URLs in config      |
```

### Code Comparison

````markdown
### Good Example - Using TypeScript interfaces
```typescript
interface User {
  id: string;
  name: string;
  email: string;
}

function getUser(id: string): User {
  // Implementation
}
```

### Bad Example - Using any type
```typescript
function getUser(id: any): any {
  // Loses type safety
}
```
````

### Conditional Guidance

```markdown
## Framework Selection

- **For small projects**: Use Minimal API approach
- **For large projects**: Use controller-based architecture with clear separation
- **For microservices**: Consider domain-driven design patterns
```

## Patterns to Avoid

- **Overly verbose explanations**: Keep it concise and scannable
- **Outdated information**: Always reference current versions and practices
- **Ambiguous guidelines**: Be specific about what to do or avoid
- **Missing examples**: Abstract rules without concrete code examples
- **Contradictory advice**: Ensure consistency throughout the file
- **Copy-paste from documentation**: Add value by distilling and contextualizing

## Testing Your Instructions

Before finalizing instruction files:

1. **Test with Copilot**: Try the instructions with actual prompts in VS Code
2. **Verify Examples**: Ensure code examples are correct and run without errors
3. **Check Glob Patterns**: Confirm `applyTo` patterns match intended files

## Example Structure

Here's a minimal example structure for a new instruction file:

````markdown
---
description: 'Brief description of purpose'
applyTo: '**/*.ext'
---

# Technology Name Development

Brief introduction and context.

## General Instructions

- High-level guideline 1
- High-level guideline 2

## Best Practices

- Specific practice 1
- Specific practice 2

## Code Standards

### Naming Conventions
- Rule 1
- Rule 2

### File Organization
- Structure 1
- Structure 2

## Common Patterns

### Pattern 1
Description and example

```language
code example
```

### Pattern 2
Description and example

## Validation

- Build command: `command to verify`
- Linting: `command to lint`
- Testing: `command to test`
````

## Maintenance

- Review instructions when dependencies or frameworks are updated
- Update examples to reflect current best practices
- Remove outdated patterns or deprecated features
- Add new patterns as they emerge in the community
- Keep glob patterns accurate as project structure evolves

## Additional Resources

- [Custom Instructions Documentation](https://code.visualstudio.com/docs/copilot/customization/custom-instructions)
- [Awesome Copilot Instructions](https://github.com/github/awesome-copilot/tree/main/instructions)

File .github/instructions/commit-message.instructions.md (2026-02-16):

---
description: 'Conventional Commits format for generated commit messages'
applyTo: ''
---

# Commit Message Format

Use the Conventional Commits standard (https://www.conventionalcommits.org/).

## Structure

```
<type>(<scope>): <description>

[optional body]
```

## Types

| Type | When to use |
|---|---|
| feat | A new feature or capability |
| fix | A bug fix |
| refactor | Code change that neither fixes a bug nor adds a feature |
| test | Adding or updating tests or testbenches |
| build | Changes to build system, CI, or dependencies |
| docs | Documentation only changes |
| style | Formatting, whitespace - no code change |
| chore | Maintenance tasks that don't fit other types |

## Scopes

Use a short scope that identifies the component:

| Scope | When to use |
|---|---|
| gw | Gateware changes (gw/) |
| fw | Firmware changes (fw/) |
| rom | ROM changes (rom/) |
| dev | VS Code settings, Dev container or Dockerfile changes (.devcontainer/) |

Omit scope when the change spans multiple components or does not fit a single scope.

## Rules

- Subject line: lowercase, imperative mood, no period at the end
- Keep the subject line under 72 characters
- Use plain ASCII (no smart quotes, em-dashes, or ellipsis characters)
- Add a body only when the "what" and "why" are not obvious from the subject
- Separate subject from body with a blank line

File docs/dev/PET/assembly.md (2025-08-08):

# 6502

* 6502
  * [Opcodes](http://www.6502.org/tutorials/6502opcodes.html)
  * [Compare and Branch](http://www.6502.org/tutorials/compare_beyond.html)
* PET
  * [Memory Map](https://www.commodore.ca/manuals/pdfs/commodore_pet_memory_map.pdf)
  * [8032 ROM Map](https://www.zimmers.net/anonftp/pub/cbm/maps/PET8032rom-map.txt)
  * PETSCII Editor
    * [PetMate 9](https://wbochar.com/petmate9/)
    * [lvllvl](https://lvllvl.c64online.com/)

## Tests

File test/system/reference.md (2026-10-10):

# Host test authoring reference

## Building fixture tests

Build production with `RelWithDebInfo`. Build tests, simulator integration,
frameworks, and their dependencies with `Debug`, including production sources
compiled for host tests. Root presets apply this split.

Build Verilator-generated models and runtime separately with optimized
`RelWithDebInfo` flags and SV assertions enabled. Keep linked test, framework,
and firmware sources in `Debug`, without model optimization flags or `NDEBUG`.

Use GoogleTest or Check assertions for test expectations. Use `vet()` for
invariants required in production and `assert()` for test-covered paranoid
checks that are intentionally elided from production. Do not undefine `NDEBUG`
or put required work or side effects inside assertions. Host fatal checks use
[`test_fatal.c`](../support/test_fatal.c).
The host C++ framework requires C++23. Firmware and external dependencies keep
their existing language standards.

The root presets require CMake 3.21 or later and build and run this suite,
including the hardware contract test:

```sh
cmake --preset default
cmake --build --preset sys-test
ctest --preset sys
```

Both `all` presets include this suite, so it runs in CI. Root builds place its
generated files in `build/system`. The standalone commands below use
`build/host-fixtures` instead.

The shared D64 fixtures, checked framework value types, external PIA/VIA models,
and their C++ tests run
without Verilator, a simulated board, ROM media, or firmware transport.
Standalone configuration defaults to `BUILD_BOARD_TESTS=OFF`. Root presets
enable the production-top board tests as well, requiring Verilator but no ROM
media or firmware transport.

Standalone builds require CMake 3.20 or later.
Initialize the pinned peripheral model dependency before configuring:

```sh
git submodule update --init test/external/chips
```

The hardware contract consistency test requires Icarus Verilog (`iverilog`
and `vvp`). It elaborates only the production constants, not a simulated board.

```sh
cmake -S test/system -B build/host-fixtures -G Ninja -DCMAKE_BUILD_TYPE=Debug
cmake --build build/host-fixtures
ctest --test-dir build/host-fixtures --output-on-failure
```

To include board simulation in a standalone build, configure with
`-DBUILD_BOARD_TESTS=ON`. Its SID lookup table is copied into the generated
board-test runtime directory, so tests do not rely on the source working directory.

The firmware Check tests also use the shared C builder. Build and run those
with `cmake --build --preset fw-test` and `ctest --preset fw`.

Keep regression tests in the suite for the feature they exercise. Register
expected-abort tests with the forked runner, using a separate fatal suite in the
same feature test file when its normal suite runs without forking.

## Production-top simulator foundation

[`system.h`](system.h) owns an independent Verilator context, the production
FPGA model, physical SRAM, and fitted PIA/VIA devices. The simulation-only
[`system.sv`](../../gw/EconoPET/sim/system.sv) wraps production `top.sv`
without replacing SPI, Wishbone, address decoding, CPU selection, or video logic.
[`SystemTest`](framework/system_test.h) gives each test a fresh board.

`tick(Cycles)` advances whole 64 MHz system clocks. It resolves CPU/FPGA data
ownership, previews read data, completes peripheral accesses at falling PHI2,
and commits SRAM data when write enable releases. Fitted devices receive the
physical reset, selects and jiffy input, and feed IRQ, text-mode and audio levels
back to the FPGA. The diagnostic switch also drives fitted PIA1 PA7 without
replacing the other port-A input levels. `RawStimulus::audio_det_i` is active-high
(true means a jack is inserted). The wrapper converts it to the production
active-low `audio_det_n_i` pin, which `top` normalizes back to active-high for `main`.
PIA1 follows its isolated keyboard-scanning clock while PIA2
and the VIA follow CPU PHI2. `peek` and `poke` access physical SRAM for fixture setup,
not CPU-visible addresses or the SPI bridge.
The VIA CA2 level reaches the FPGA and snapshots as `text_mode_i`
(high selects upper/lowercase text, low selects uppercase/graphics).

If a tick rejects an access after the FPGA advances, it suspends at the exact
phase rather than rolling state back or rounding the simulator counter.
`clock_faulted()` identifies this state, `half_ticks()` retains its exact
timestamp, and `time()` remains readable as the last completed whole cycle.
Snapshots, SRAM and peripheral inspection remain available. Further ticks
require external reset assertion. `set_external_reset(true)` followed by
`tick(Cycles{1})` cancels the rejected access and completes the retained cycle
(including only its remaining half when interrupted in the high phase).
Remove invalid stimulus before releasing reset. A zero-cycle tick does not
recover the clock.
Reset does not override normal SRAM or FPGA bus resolution, so SPI memory
inspection remains available while either reset driver holds the CPU.
Only an unsupported VIA shift-register read canceled by reset is treated as
undriven data instead of rejecting recovery.

Use `drive_physical_cpu`, external reset/interrupt setters, and
`raw_stimulus(callback)` for pin-level setup. Raw edits commit only after
successful completion and cannot mutate or clock the board during the callback.
`drive_spi` drives only SPI0 pin levels and cannot steal a scoped transaction's
pins. Changes do not evaluate the FPGA until `tick`.
`snapshot()` and `peek_stimulus()` return editable, assignable detached values
that can outlive their board. Fixture-owned inputs have one access path,
`snapshot().stimulus`. Resolved bus data, device feedback, harness inputs and
FPGA outputs remain separate snapshot members. Editing a snapshot does not
edit the board. The board is noncopyable/nonmovable, and borrowed `io()` devices must
not outlive it.

## Observation, deadlines and failures

`observe(callback)` returns a move-only `ObserverSubscription`. Keep it alive
for the interval to observe. Callbacks receive `const System&` after each full
cycle's FPGA evaluation, peripheral updates, SRAM commits and time advancement.
No callback runs for `tick(0)`. Subscribers run in registration order.
Disconnecting a subscription is idempotent and takes effect during dispatch,
including when a callback disconnects itself or a later subscriber. An executing
callback retains its captures until it returns. A subscription may outlive its
board, but does not keep the board alive.

Observers and completion predicates cannot mutate or clock the board through
captured references, register observers, or mutate retained fitted devices.
Read-only snapshots, SRAM/device inspection and diagnostics remain available.
An observer exception propagates unchanged and stops that cycle's dispatch.
The completed cycle is retained and the board remains clockable after the
throwing subscription is removed. This differs from an interrupted hardware
access, which still requires the external-reset recovery described above.

`run_until(predicate, budget, reason)` checks completion immediately, then
after each cycle through the inclusive final boundary. `service_until` uses
the same predicate contract, but passes a mutable board and the remaining
`Cycles` to an active service callback. If service makes no clock progress,
completion is checked again, then one cycle is clocked if still incomplete.
An already complete zero-budget wait succeeds without work. An incomplete
zero-budget wait times out without service or clocks. Oversized clock requests
are rejected before advancing. Nested waits inherit the tighter deadline and
restore the enclosing deadline on every exit. Predicate and service exceptions
propagate unchanged, and guards are restored. Clock health is checked before
every completion predicate. If active service catches a hardware rejection,
it must complete external-reset recovery before completion can be observed.
Merely asserting reset without completing the retained cycle is not recovery.

```cpp
System board;
const auto start = board.time();
unsigned samples = 0;
auto subscription = board.observe([&](const System& observed) {
    EXPECT_EQ(observed.time(), start + econopet::Cycles{++samples});
});
board.run_until([&](const System& observed) {
    return observed.time() == start + econopet::Cycles{7};
}, econopet::Cycles{7}, "seven observed cycles");
subscription.reset();
```

The default simulation seed is 1, or the decimal value of `ECONOPET_SIM_SEED`.
Valid seeds are in `[1, INT_MAX]`. `System(seed)` supplies a per-board override.
Startup is zero-initialized unless `System(seed, System::InitialState::Random)`
is requested. The seed and policy are installed before model construction and
do not alter a peer board's RNG. These are simulation seeds, not FPGA placement
seeds. `SystemTest` records the actual seed in test properties and assertion
traces, and reports diagnostics when a test fails.

`diagnostic(operation, detail)` formats read-only evidence with the completed
cycle, half-cycle phase, CPU selection, seed, startup policy, reset/fault state,
bus address, SPI levels and up to 16 recent fixture/deadline/SRAM events.
Successful raw-stimulus edits record changed fields and their requested values,
including CPU direction/data and indexed spare pins. Unchanged fields, no-op
edits and discarded callbacks do not add history entries.
Timeouts and board-side access rejections attach this evidence while preserving
their standard exception category. `failure<Exception>(operation, detail)`
constructs an exception with the same evidence for later framework layers.
Diagnostics do not clock, dispatch callbacks or acknowledge peripheral reads.

## External PIA/VIA models

[`io.h`](io.h) and [`io.cpp`](io.cpp) adapt the pinned
[`chips`](../external/chips) digital models. The `econopet_external_io` library
builds in Debug, independently of GoogleTest and the FPGA simulator. Its tests
are in [`io_test.cpp`](io_test.cpp).

The submodule requires the [DLehenbauer/chips fork](https://github.com/DLehenbauer/chips),
pinned to [`264ddc2`](https://github.com/DLehenbauer/chips/commit/264ddc2fe7a5127eeb0e87e44af6ca2314818706),
rather than upstream `floooh/chips`. The adapters depend on its:

- MOS 6520 model and `m6520_peek`/`m6522_peek` functions, which preview
  register reads with current input levels without advancing the original
  model or acknowledging its interrupts or handshakes.
- PIA C2 fixes for manual levels, read-A/write-B handshake strobes, one-cycle
  pulses, and preservation of externally driven control-input levels.
- VIA fixes for independent control-input edge sampling, preservation of
  input levels, IRQ summary gating after enable changes, and ignoring IFR
  summary-bit writes when acknowledging source flags.
- VIA timer-load pipeline restart, underflow detection only on actual count
  edges (including maximum loads), and reset suppression of one-shot
  interrupts until the timers are rearmed.
- T2 pulse counting from resolved PB6 levels across DDR/output changes,
  independently of external/output disagreement or the port input latch.

Dependency updates must preserve them and pass the peripheral regressions.
PIA/VIA control and GPIO pin encodings must also match (checked at compile time).

`Pia6520` models DDR/output-latch isolation, mixed GPIO, both control-input
edge polarities, interrupt flags/enables, and fixed/handshake/pulse C2 outputs.
`Via6522` models unlatched GPIO, T1 one-shot/free-running timers, timed or
PB6-counted T2, IFR/IER, control-input interrupts, and fixed/handshake C2
outputs. VIA shift-register accesses, input latching, PB7 timer output, and C2
pulse-output modes throw before changing device state or write observations.
These are digital models, not analog loading or propagation-delay models.
T2 pulse counting observes the resolved PB6 pin: DDR selects the external
input or output latch. External transitions cannot count while PB6 is driven
as an output, and stable levels never generate repeated pulses. Output-latch
and direction changes count only when they produce a resolved falling edge.

Access fitted devices with `pia1()`, `pia2()`, and `via()`. Use named
`PiaRegister`, `ViaRegister`, control flags, and interrupt sources.
PIA control composites such as `PiaC2High` pass directly to `set_control`.
Use `.bits()` only when encoding a raw bus or assembly byte.
Use `ChipSelect::None`, `ChipSelect::Pia1`, `ChipSelect::Pia2`, and
`ChipSelect::Via` directly when constructing `ChipSelects` bus selections.

```cpp
using namespace econopet;
using namespace econopet::io;

Io devices;
auto& pia = devices.pia1();
const CycleTime at{Cycles{0}};

// Configure external inputs and a mixed-direction port.
pia.inputs([](Inputs& levels) { levels.port_a = 0xa5; });
pia.set_control(PiaRegister::ControlA, PiaDdrAccess, at);
write(pia, PiaRegister::PortA, 0x0f, at + Cycles{1});
// Select port access and a fixed high CA2 output, then drive the output latch.
pia.set_control(PiaRegister::ControlA, PiaC2High, at + Cycles{2});
write(pia, PiaRegister::PortA, 0x03, at + Cycles{3});
// Observe without acknowledgment, then complete a read.
const auto presented = pia.peek(PiaRegister::PortA);
const auto completed = read(pia, PiaRegister::PortA, at + Cycles{4});
```

`read(device, reg, at)` and `write(device, reg, data, at)` each advance that
peripheral by one clock, not the board clock. Reads return the presented value
before acknowledging flags or handshakes. `peek` and `peek_inputs` change
nothing. Keep `clock(access)` for timestamped PHI2 bus integration.

`inputs(callback)` edits detached levels and commits only after successful
callback completion and mutation-guard checks. Callback or guard failures
discard the edit. Nested edits and peripheral mutation during a fitted
device's callback are rejected across all fitted devices.

`Pia6520`, `Via6522`, and `Io` are noncopyable and nonmovable. Device references
must not outlive their `Io` owner. Copy `state()` or use `peek_inputs()` for
detached snapshots. Reset preserves externally driven inputs, injected faults,
and write history.

`Io::sample` captures the preceding stable bus sample once at falling PHI2.
`BusSample::pia1_phi2` optionally supplies the isolated PIA1 clock (otherwise
PIA1 follows CPU PHI2). Isolated PIA1 edges do not advance PIA2, the VIA or the
CPU PHI2 clock count.
Repeated high/low samples do not duplicate accesses, deselected devices still
clock their timers, and reset assertion cancels pending accesses even with
overlapping selects or an invalid register. Held reset does not repeatedly
reset the devices. Multiple physical chip selects are rejected when reset is
inactive. `writes().last()` is optional, so no write
is distinct from a write of zero. Completed-write records carry the caller's
full-cycle timestamp, and explicit observation clearing does not reset devices.
The selected access is validated before any peripheral advances. Unsupported
VIA modes or out-of-range registers leave every device, write history, cycle
count, and pending bus sample unchanged. Retrying the rejected falling edge
rejects again without ticking. Present a corrected high sample before completing
the access, or assert reset to cancel it.

`Via6522::Timer1Fault::StuckInterruptFlag` is an explicit synthetic overlay.
It does not modify normal timer state, survives reset, and raises IRQ only
when the corresponding source is enabled. Removing the fault exposes the
normal underlying interrupt flags again.

Run the standalone peripheral checks with:

```sh
ctest --test-dir build/system \
  -R '^system\.External(Types|Pia|Via|Bus)\.' --output-on-failure
```

Trace publication and real-CPU bus/IRQ integration tests belong
to later incremental layers.

## Checked SPI and CPU lifecycle

[`registers.h`](registers.h) defines named FPGA registers, SPI commands,
status flags, PET peripheral addresses and native reset vectors.
`StatusBit::Text` uses `ECONOPET_REG_STATUS_TEXT_MODE_MASK` for the asserted
video-mode bit (clear means graphics).
`spi().read` and `spi().write` use the production SPI/Wishbone path, not a
memory shortcut. Use `fpga::address(SramAddress)` for direct SRAM access
(including the upper bank), or a named `fpga::Register`. Valid but unmapped
Wishbone addresses reach the real decoder and time out rather than being
rejected as out of range. These operations advance simulation time and work
while the CPU is held in reset.

`spi().command(ByteView)` accepts exactly one complete command, rejects
reserved bits and wrong lengths before clocks or pin changes, and returns
the first received byte. Production reads are pipelined. `spi().read`
seeks with `ReadAt`, then clocks the result with `ReadNext`.
`spi().transaction(callback)` holds CS across complete commands. Its callback
receives only `SpiCommands::command`, not raw shifting or release controls.
The scope drains the controller and releases CS before returning.
Void and value results (including owning move-only values) are supported.
References, raw pointers and
`reference_wrapper` results are rejected. Other returned values must not
retain callback-local or board-borrowed state. These restrictions reject common
borrowed forms, not all borrowing types. Spans, views and reference-capturing
callables still require the caller to ensure every referenced object outlives
its use. The API does not prove that a returned value is detached.

```cpp
System board;
const auto address = fpga::address(econopet::SramAddress{0x12345});
board.spi().write(address, 0x42);
EXPECT_EQ(board.spi().read(address), 0x42);

const std::array<uint8_t, 2> write_next{
    fpga::command_byte(fpga::SpiCommand::WriteNext), 0x5a};
board.spi().transaction([&](auto& commands) {
    commands.command(write_next);
});
```

`spi().raw_transaction(half_period)` explicitly permits partial commands,
bit/byte shifting and custom positive timing. Call `finish()` to drain the
controller before releasing CS, or `abort()` for a deliberate reusable release.
Abort does not roll back an admitted write. Default SCK half-periods are two
system cycles, and release settles for four. Readiness waits accept the
inclusive final cycle and inherit enclosing deadlines. No phase is shortened
to fit a deadline.

An unfinished owner or exception escaping acquisition, work, drain or release
fails closed: CS is raised, SCK lowered and ownership released without cleanup
clocks, FPGA evaluation or observer calls. The original exception and timestamp
are retained. `spi().peek_failed()` then rejects further clocks and active
transport/deadline work permanently, even if a service callback catches the
exception. Discard that board and construct another. Passive snapshots, SRAM,
CPU observations and diagnostics remain usable. This transport policy is
distinct from recoverable hardware clock suspension.

`cpu()` offers shared reset, selection/control reads and passive inspection.
Selection reads decode only the CPU field, independently of the SuperPET I/O
mode flag. Selection, preparation and startup preserve that independent flag.
CPU-control reads mask unspecified upper register bits before constructing
typed flags. Raw SPI register reads still return the complete byte.
`cpu(CPU_SOFT_6502)` or `cpu(CPU_SOFT_6809)` binds core-specific lifecycle
operations. `prepare()` asserts reset, drains admitted activity and selects
the core. `write_vector(entry)` requires that bound core quiescent in reset.
`start(entry)` prepares, installs a native-endian vector, holds reset and
releases it. `start()` instead uses an already installed vector.
Startup does not imply program completion.

6502 reset vectors use little-endian bytes at $FFFC, while 6809 vectors use
big-endian bytes at $FFFE. Reset hold is 1,280 system cycles. Release sets READY
for both physical and soft 6502, clears it for soft 6809, and verifies resolved reset.
External reset cannot be overridden. Selection requires quiescent reset, and
stale bound views cannot release another core or overwrite its vector.
Direct vector installation also requires an idle, unowned SPI bus. It drains
outstanding controller work before patching SRAM, then rechecks CPU
quiescence. Raw CS release settles for four cycles before checking both SPI
and admitted Wishbone/SRAM activity. Calling it inside a checked or raw
transaction is rejected before
clocks or memory changes.
Physical-6502 startup requires explicit fixture vector/memory setup, and its
fetch history is unsupported. `write_control_raw(byte)` is the escape hatch
for deliberately unusual control sequences.

```cpp
auto cpu = board.cpu(CPU_SOFT_6502);
cpu.prepare();
// Install native machine-code bytes in physical SRAM before writing the vector.
board.poke(econopet::SramAddress{0x0300}, 0x4c);
board.poke(econopet::SramAddress{0x0301}, 0x00);
board.poke(econopet::SramAddress{0x0302}, 0x03);
cpu.write_vector(econopet::CpuAddress{0x0300});
const auto checkpoint = cpu.peek_fetch_checkpoint();
cpu.release_reset();
board.run_until([&](const System& observed) {
    return observed.cpu(CPU_SOFT_6502).peek_fetched_at(
        econopet::CpuAddress{0x0300}, checkpoint);
}, econopet::Cycles{10000}, "6502 loop fetch");
```

Native address observations are not necessarily opcode fetches. Fetch history
is per-address, monotonically checkpointed and preserved across reset and
selection changes. Soft 6502 records SYNC opcode consumption at its advancing
falling clock edge,
using that edge's READY and pre-advance address. A core held on SYNC does not
advance checkpoints, even as bus arbitration continues.
Soft 6809 records native SYNC (not exact opcode attribution). Inactive
cores and SPI accesses do not create CPU observations. Snapshots expose these
simulation-only native signals without changing production RTL.

SPI/CPU views borrow a persistent board and must not outlive it. Factories
reject temporary boards. Const-board views expose only passive inspection.
Active operations and captured transaction handles remain subject to observer
and input-edit mutation guards.
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

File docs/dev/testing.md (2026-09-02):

# Test randomization

`ctest` picks one pseudo-random seed per run and shares it with every test, so
a run that trips a seed-sensitive bug can be replayed in full.

## How it works

CTest runs `seed.sh --write` as a pre-test hook (rather than a fixture) so the
seed prints even when every test passes. The hook picks a seed, prints it as
`Test seed: N`, and writes it to `build/test.seed`. Each test is handed that
path in `ECONOPET_TEST_SEED_FILE`.

`sim.sh` and `verilate.sh` call `seed.sh` to resolve the effective seed
(`ECONOPET_TEST_SEED` wins over the file) and pass it to the simulator as a
`+seed=N` plusarg. The `TB_INIT` macro in `gw/EconoPET/sim/tb.svh` reads the
plusarg and feeds it to `$urandom`. Verilator additionally gets
`+verilator+seed+N`, which also drives `RAND_RESET=2` power-up randomization
(see [verilator.md](verilator.md)).

The firmware tests receive `ECONOPET_TEST_SEED_FILE` as well, though no
firmware test consumes it yet.

## Replaying a run

Each bench echoes the seed it used, so `--output-on-failure` shows the value
alongside the failure. Set `ECONOPET_TEST_SEED` to replay:

```sh
ECONOPET_TEST_SEED=123456789 ctest --preset gw --parallel   # whole run
ECONOPET_TEST_SEED=123456789 ./verilate.sh top_tb           # one Verilator bench
ECONOPET_TEST_SEED=123456789 ./sim.sh top_tb                # one Icarus bench
```

The two simulators produce different values from the same seed, so a seed
reproduces a given bench under a given simulator, not across both.

Simulators accept `1..2147483647`. A seed outside that range fails the pre-test
hook and no tests run.

## Caveats

- Each `ctest` run draws a fresh seed, so a bench with a latent seed-sensitive
  bug presents as flaky. The reported seed is the reproducer.
- Running a bench directly (outside CTest, without `ECONOPET_TEST_SEED`) passes
  no seed at all, so the simulator's own default applies. Those runs repeat but
  do not report a seed.
- Icarus has no global RNG seed and its `$random()` stream ignores `$urandom`
  seeding, so benches must use `$urandom`/`$urandom_range` to be reproducible.
- The seed only affects benches that call `$urandom`/`$urandom_range` or run
  with `RAND_RESET=2`. Benches that draw no random values are unaffected.

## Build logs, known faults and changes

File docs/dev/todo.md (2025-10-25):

# TODOs

* Before release
  * Hang on reset?
* Firmware
  * Try [pio_spi](https://github.com/raspberrypi/pico-examples/tree/master/pio/spi):
    * Handles CS automatically
    * Potentially can exceed 24 MHz
  * 8K Video RAM:
    * Move character rom to shadowed I/O region at $E000-$E800?
    * (Will require gw support for "ghost byte" readback for compat.)
  * Menu:
    * Enter/Exit without reset?
  * Commit patched PicoDVI (?)
* Gateware:
  * Handle reset for:
    * Keyboard
  * Consider CPU addr_strobe signal?
  * Use writes to VIA/CA2 to cache Gfx state instead of physical pin?
  * Remove unused *.sv files (cpu, arbiter, bram, vsync, io, ??)
  * Generalize IO shadowing and interception for keyboard and (future) IEEE, etc.
* Compat:
  * Echo last byte on bus when reading unmapped regions. ("ghost byte")
* Hardware
  * Straighten bumped traces below User Port header (front)
  * Parts
    * SMT Tactile Buttons (C318884)
    * SMT Dip for config (C2961921)
      * Maybe could use to switch on/off sound and 5V/Video as well (using diode)?
    * Insufficient 1x headers due to 6V and 5V/VIDEO selector (but maybe we can use scrap from 2x header?)
  * Silk
    * Recommended Assembly order: IDC header accidentally included in 2x header parts
    * Reorder so that we do large headers first and in an order that ensures scraps will have sufficient parts.
      * Header #1 (length 25): 25 = 25 used, 0 waste
      * Header #2 (length 25): 11 + 10 + 3 = 24 used, 1 waste
      * Header #3 (length 20): 9 + 8 = 17 used, 3 waste
  * Layout / Routing
    * These parts should be offset: CPU, RAM, 25-pin header
    * Route ground with signals
    * Check http://jlcdfm.com recommendations
      * Ideal SMD pad to THT is >= 3.05mm (Really? This seems very large.)
      * Annular rings >0.15mm

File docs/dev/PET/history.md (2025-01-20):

# History

## Reference

* [Serial Numbers](https://docs.google.com/spreadsheets/d/1NTQpIdW1gT3KTPUPs5mWHLGJxomzp0It32OHQ076W90/edit?usp=sharing)

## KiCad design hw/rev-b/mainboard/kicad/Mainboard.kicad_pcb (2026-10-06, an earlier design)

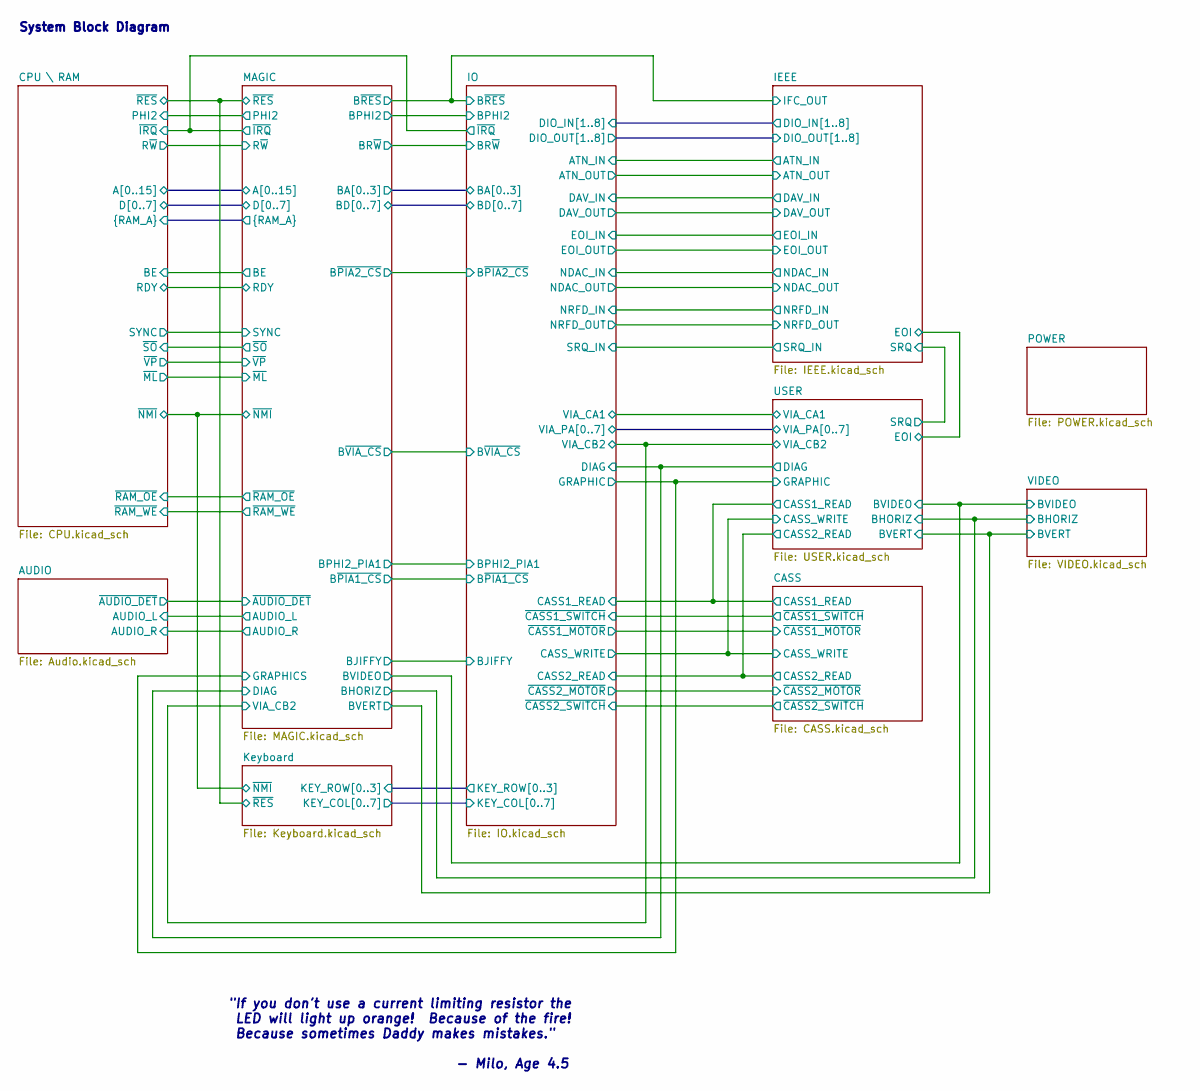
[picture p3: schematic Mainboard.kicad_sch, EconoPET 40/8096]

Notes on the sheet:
"If you don't use a current limiting resistor the LED will light up orange! Because of the fire! Because sometimes Daddy makes mistakes." - Milo, Age 4.5
System Block Diagram

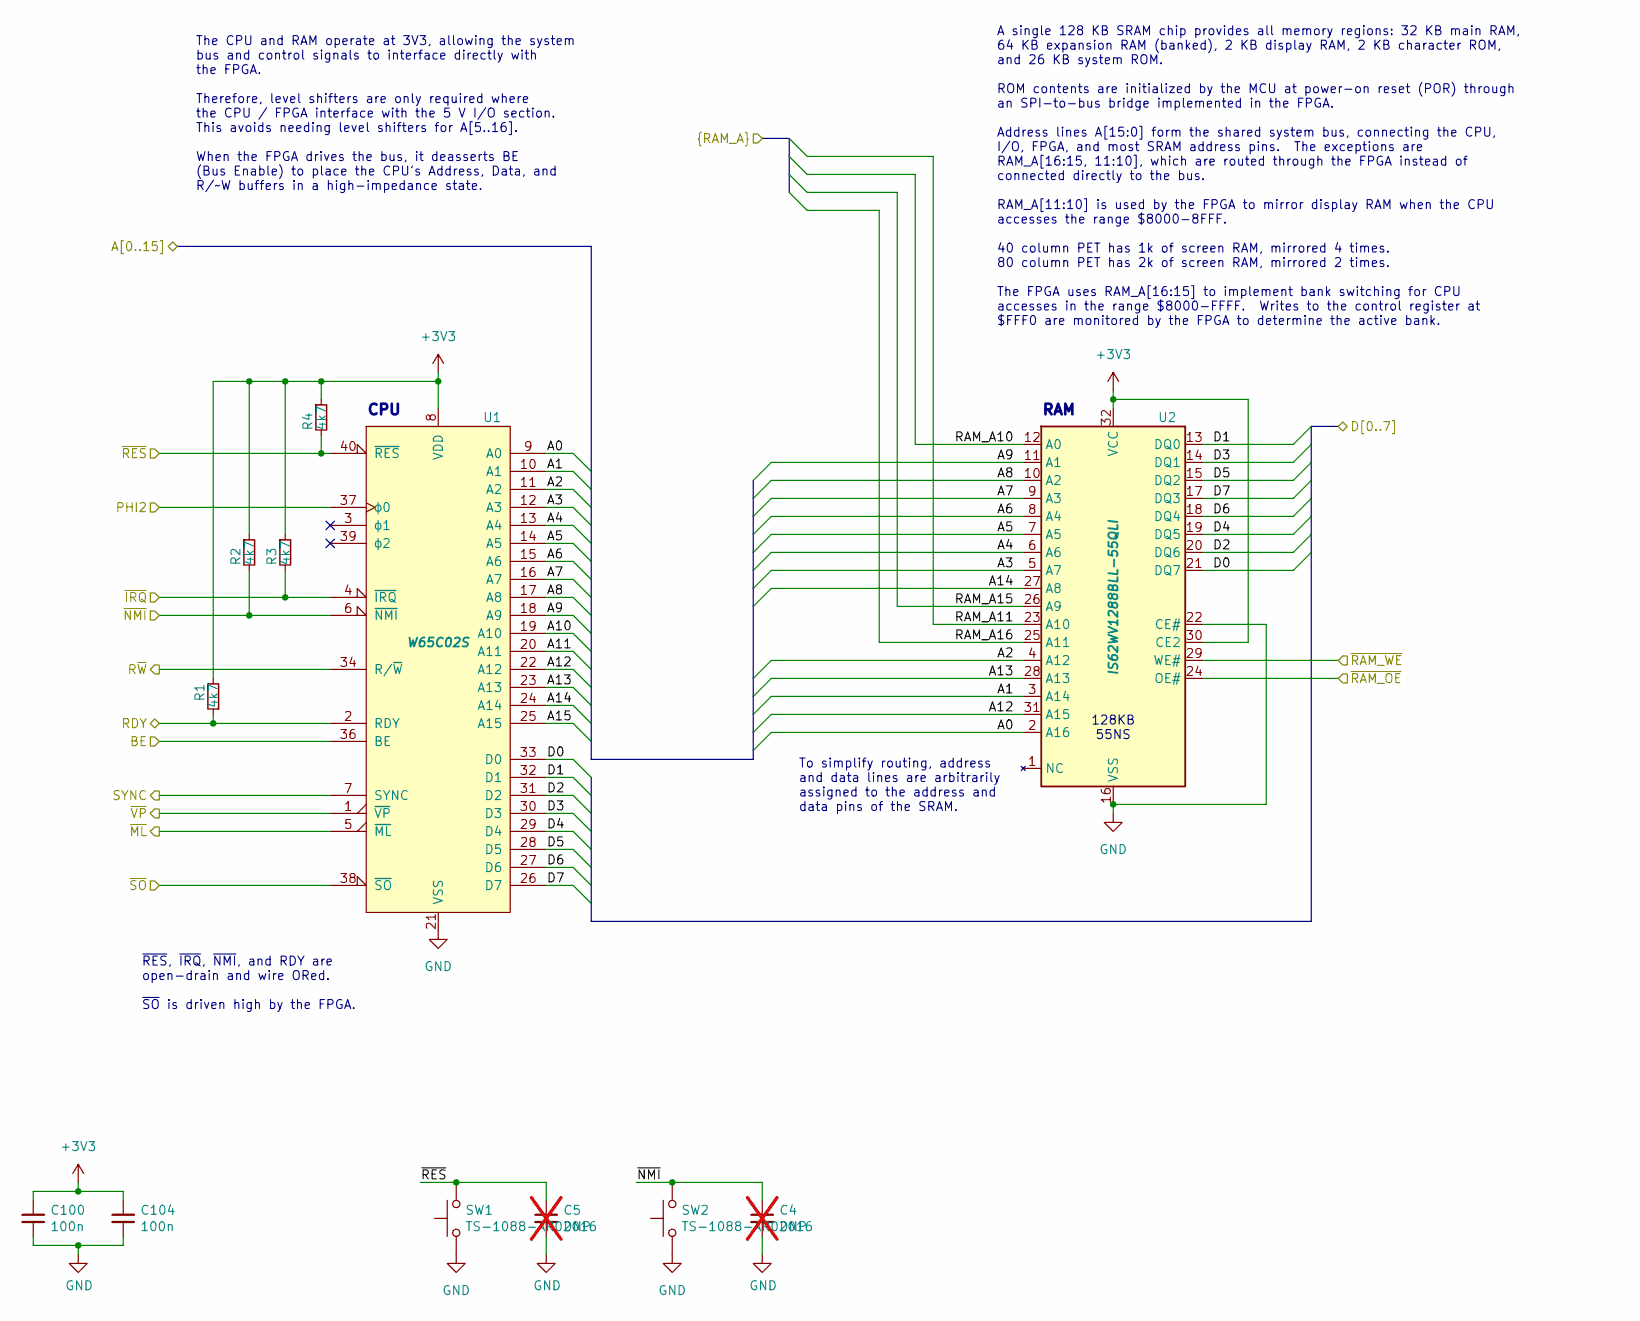
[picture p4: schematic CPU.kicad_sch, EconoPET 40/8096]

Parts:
C4, C5: DNP; C_0402_1005Metric; not fitted
C100, C104: 100n; C_0402_1005Metric; LCSC Part # C307331
R1, R2, R3, R4: 4k7; R_0402_1005Metric; LCSC Part # C25900
SW1, SW2: TS-1088-AR02016; SW-SMD_L3.9-W3.0-P4.45; LCSC Part # C720477
U1: W65C02S; DIP-40_W15.24mm_Socket; MOUSER 955-W65C02S6TPG-14,571-1-2199299-5
U2: IS62WV1288BLL-55QLI; SOP-32_L20.7-W11.3-P1.27-LS14.1-BL; LCSC Part # C1351025

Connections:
+3V3: C100.1, C104.1, R1.2, R2.1, R3.1, R4.1, U1.8 (VDD), U2.30 (CE2), U2.32 (VCC); also elsewhere on the board
/CPU \ RAM/A0: U1.9 (A0), U2.2 (A16); also elsewhere on the board
/CPU \ RAM/A1: U1.10 (A1), U2.3 (A14); also elsewhere on the board
/CPU \ RAM/A2: U1.11 (A2), U2.4 (A12); also elsewhere on the board
/CPU \ RAM/A3: U1.12 (A3), U2.5 (A7); also elsewhere on the board
/CPU \ RAM/A4: U1.13 (A4), U2.6 (A6); also elsewhere on the board
/CPU \ RAM/A5: U1.14 (A5), U2.7 (A5); also elsewhere on the board
/CPU \ RAM/A6: U1.15 (A6), U2.8 (A4); also elsewhere on the board
/CPU \ RAM/A7: U1.16 (A7), U2.9 (A3); also elsewhere on the board
/CPU \ RAM/A8: U1.17 (A8), U2.10 (A2); also elsewhere on the board
/CPU \ RAM/A9: U1.18 (A9), U2.11 (A1); also elsewhere on the board
/CPU \ RAM/A10: U1.19 (A10); also elsewhere on the board
/CPU \ RAM/A11: U1.20 (A11); also elsewhere on the board
/CPU \ RAM/A12: U1.22 (A12), U2.31 (A15); also elsewhere on the board
/CPU \ RAM/A13: U1.23 (A13), U2.28 (A13); also elsewhere on the board
/CPU \ RAM/A14: U1.24 (A14), U2.27 (A8); also elsewhere on the board
/CPU \ RAM/A15: U1.25 (A15); also elsewhere on the board
/CPU \ RAM/D0: U1.33 (D0), U2.21 (DQ7); also elsewhere on the board
/CPU \ RAM/D1: U1.32 (D1), U2.13 (DQ0); also elsewhere on the board
/CPU \ RAM/D2: U1.31 (D2), U2.20 (DQ6); also elsewhere on the board
/CPU \ RAM/D3: U1.30 (D3), U2.14 (DQ1); also elsewhere on the board
/CPU \ RAM/D4: U1.29 (D4), U2.19 (DQ5); also elsewhere on the board
/CPU \ RAM/D5: U1.28 (D5), U2.15 (DQ2); also elsewhere on the board
/CPU \ RAM/D6: U1.27 (D6), U2.18 (DQ4); also elsewhere on the board
/CPU \ RAM/D7: U1.26 (D7), U2.17 (DQ3); also elsewhere on the board
/CPU \ RAM/RAM_A10: U2.12 (A0); also elsewhere on the board
/CPU \ RAM/RAM_A11: U2.23 (A10); also elsewhere on the board
/CPU \ RAM/RAM_A15: U2.26 (A9); also elsewhere on the board
/CPU \ RAM/RAM_A16: U2.25 (A11); also elsewhere on the board
/CPU \ RAM/~ML: U1.5 (~ML); also elsewhere on the board
/CPU \ RAM/~NMI: C4.1, R2.2, SW2.2, U1.6 (~NMI); also elsewhere on the board
/CPU \ RAM/~RAM_OE: U2.24 (OE#); also elsewhere on the board
/CPU \ RAM/~RAM_WE: U2.29 (WE#); also elsewhere on the board
/CPU \ RAM/~RES: C5.1, R4.2, SW1.2, U1.40 (~RES); also elsewhere on the board
/CPU \ RAM/~VP: U1.1 (~VP); also elsewhere on the board
/MAGIC/FPGA/BE: U1.36 (BE); also elsewhere on the board
/MAGIC/FPGA/RDY: R1.1, U1.2 (RDY); also elsewhere on the board
/MAGIC/FPGA/SYNC: U1.7 (SYNC); also elsewhere on the board
/MAGIC/FPGA/~IRQ: R3.2, U1.4 (~IRQ); also elsewhere on the board
/MAGIC/FPGA/~SO: U1.38 (~SO); also elsewhere on the board
/MAGIC/PHI2: U1.37 (ϕ0); also elsewhere on the board
/MAGIC/R~W: U1.34 (R/~W); also elsewhere on the board
GND: C4.2, C5.2, C100.2, C104.2, SW1.1, SW2.1, U1.21 (VSS), U2.16 (VSS), U2.22 (CE#); also elsewhere on the board

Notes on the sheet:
RAM
A single 128 KB SRAM chip provides all memory regions: 32 KB main RAM, 64 KB expansion RAM (banked), 2 KB display RAM, 2 KB character ROM, and 26 KB system ROM. ROM contents are initialized by the MCU at power-on reset (POR) through an SPI-to-bus bridge implemented in the FPGA. Address lines A[15:0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
To simplify routing, address and data lines are arbitrarily assigned to the address and data pins of the SRAM.
~{RES}, ~{IRQ}, ~{NMI}, and RDY are open-drain and wire ORed. ~{SO} is driven high by the FPGA.
128KB 55NS
CPU
The CPU and RAM operate at 3V3, allowing the system bus and control signals to interface directly with the FPGA. Therefore, level shifters are only required where the CPU / FPGA interface with the 5 V I/O section. This avoids needing level shifters for A[5..16]. When the FPGA drives the bus, it dea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

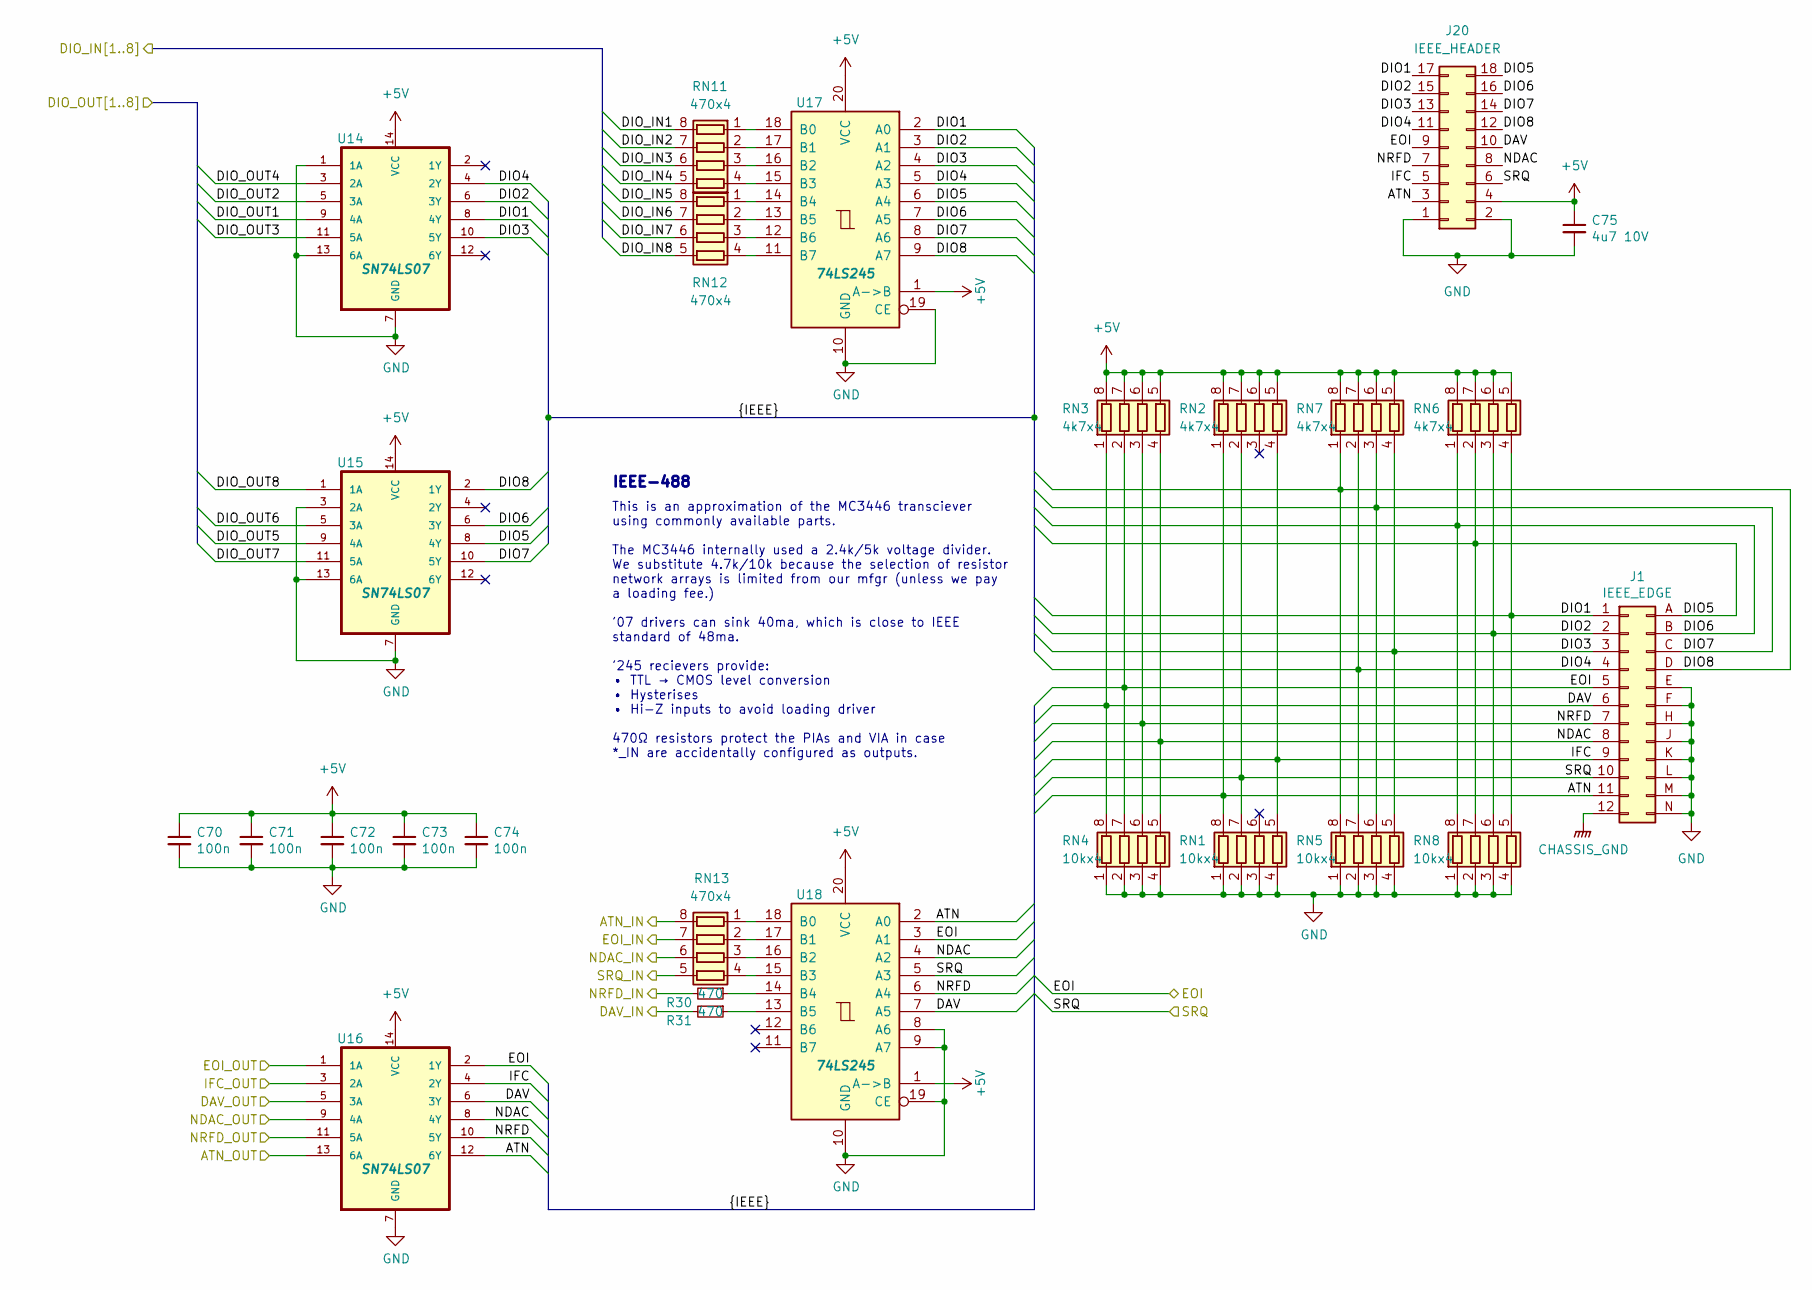
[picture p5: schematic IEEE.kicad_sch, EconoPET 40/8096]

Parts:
C70, C71, C72, C73, C74: 100n; C_0402_1005Metric; LCSC Part # C307331
C75: 4u7 10V; C_0402_1005Metric; LCSC Part # C23733
J1: IEEE_EDGE; CBM_PET_IEEE_EDGE_CON_24P
J20: IEEE_HEADER; PinHeader_2x09_P2.54mm_Vertical; MOUSER 649-1012938195002BLF
R30, R31: 470; R_0402_1005Metric; LCSC Part # C25117
RN1, RN4, RN5, RN8: 10kx4; R_Array_Convex_4x0603; LCSC Part # C29718
RN2, RN3, RN6, RN7: 4k7x4; R_Array_Convex_4x0603; LCSC Part # C1980
RN11, RN12, RN13: 470x4; R_Array_Convex_4x0603; LCSC Part # C25510
U14, U15, U16: SN74LS07; SOIC-14_3.9x8.7mm_P1.27mm; LCSC Part # C513513
U17, U18: 74LS245; SOIC-20W_7.5x12.8mm_P1.27mm; LCSC Part # C129580

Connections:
+5V: C70.1, C71.1, C72.1, C73.1, C74.1, C75.1, J20.4, RN2.5 (R4.2), RN2.6 (R3.2), RN2.7 (R2.2), RN2.8 (R1.2), RN3.5 (R4.2), RN3.6 (R3.2), RN3.7 (R2.2), RN3.8 (R1.2), RN6.5 (R4.2), RN6.6 (R3.2), RN6.7 (R2.2), RN6.8 (R1.2), RN7.5 (R4.2), RN7.6 (R3.2), RN7.7 (R2.2), RN7.8 (R1.2), U14.14 (VCC), U15.14 (VCC), U16.14 (VCC), U17.1 (A->B), U17.20 (VCC), U18.1 (A->B), U18.20 (VCC); also elsewhere on the board
/IEEE/ATN: J1.11 (ATN), J20.3, RN1.8 (R1.2), RN2.1 (R1.1), U16.12 (6Y), U18.2 (A0)
/IEEE/ATN_IN: RN13.8 (R1.2); also elsewhere on the board
/IEEE/ATN_OUT: U16.13 (6A); also elsewhere on the board
/IEEE/DAV: J1.6 (DAV), J20.10, RN3.1 (R1.1), RN4.8 (R1.2), U16.6 (3Y), U18.7 (A5)
/IEEE/DAV_IN: R31.2; also elsewhere on the board
/IEEE/DAV_OUT: U16.5 (3A); also elsewhere on the board
/IEEE/DIO1: J1.1 (DIO1), J20.17, RN6.4 (R4.1), RN8.5 (R4.2), U14.8 (4Y), U17.2 (A0)
/IEEE/DIO2: J1.2 (DIO2), J20.15, RN6.3 (R3.1), RN8.6 (R3.2), U14.6 (3Y), U17.3 (A1)
/IEEE/DIO3: J1.3 (DIO3), J20.13, RN5.5 (R4.2), RN7.4 (R4.1), U14.10 (5Y), U17.4 (A2)
/IEEE/DIO4: J1.4 (DIO4), J20.11, RN5.7 (R2.2), RN7.2 (R2.1), U14.4 (2Y), U17.5 (A3)
/IEEE/DIO5: J1.A (DIO5), J20.18, RN6.2 (R2.1), RN8.7 (R2.2), U15.8 (4Y), U17.6 (A4)
/IEEE/DIO6: J1.B (DIO6), J20.16, RN6.1 (R1.1), RN8.8 (R1.2), U15.6 (3Y), U17.7 (A5)
/IEEE/DIO7: J1.C (DIO7), J20.14, RN5.6 (R3.2), RN7.3 (R3.1), U15.10 (5Y), U17.8 (A6)
/IEEE/DIO8: J1.D (DIO8), J20.12, RN5.8 (R1.2), RN7.1 (R1.1), U15.2 (1Y), U17.9 (A7)
/IEEE/DIO_IN1: RN11.8 (R1.2); also elsewhere on the board
/IEEE/DIO_IN2: RN11.7 (R2.2); also elsewhere on the board
/IEEE/DIO_IN3: RN11.6 (R3.2); also elsewhere on the board
/IEEE/DIO_IN4: RN11.5 (R4.2); also elsewhere on the board
/IEEE/DIO_IN5: RN12.8 (R1.2); also elsewhere on the board
/IEEE/DIO_IN6: RN12.7 (R2.2); also elsewhere on the board
/IEEE/DIO_IN7: RN12.6 (R3.2); also elsewhere on the board
/IEEE/DIO_IN8: RN12.5 (R4.2); also elsewhere on the board
/IEEE/DIO_OUT1: U14.9 (4A); also elsewhere on the board
/IEEE/DIO_OUT2: U14.5 (3A); also elsewhere on the board
/IEEE/DIO_OUT3: U14.11 (5A); also elsewhere on the board
/IEEE/DIO_OUT4: U14.3 (2A); also elsewhere on the board
/IEEE/DIO_OUT5: U15.9 (4A); also elsewhere on the board
/IEEE/DIO_OUT6: U15.5 (3A); also elsewhere on the board
/IEEE/DIO_OUT7: U15.11 (5A); also elsewhere on the board
/IEEE/DIO_OUT8: U15.1 (1A); also elsewhere on the board
/IEEE/EOI: J1.5 (EOI), J20.9, RN3.2 (R2.1), RN4.7 (R2.2), U16.2 (1Y), U18.3 (A1); also elsewhere on the board
/IEEE/EOI_IN: RN13.7 (R2.2); also elsewhere on the board
/IEEE/EOI_OUT: U16.1 (1A); also elsewhere on the board
/IEEE/IFC: J1.9 (IFC), J20.5, RN1.5 (R4.2), RN2.4 (R4.1), U16.4 (2Y)
/IEEE/IFC_OUT: U16.3 (2A); also elsewhere on the board
/IEEE/NDAC: J1.8 (NDAC), J20.8, RN3.4 (R4.1), RN4.5 (R4.2), U16.8 (4Y), U18.4 (A2)
/IEEE/NDAC_IN: RN13.6 (R3.2); also elsewhere on the board
/IEEE/NDAC_OUT: U16.9 (4A); also elsewhere on the board
/IEEE/NRFD: J1.7 (NRFD), J20.7, RN3.3 (R3.1), RN4.6 (R3.2), U16.10 (5Y), U18.6 (A4)
/IEEE/NRFD_IN: R30.2; also elsewhere on the board
/IEEE/NRFD_OUT: U16.11 (5A); also elsewhere on the board
/IEEE/SRQ: J1.10 (SRQ), J20.6, RN1.7 (R2.2), RN2.2 (R2.1), U18.5 (A3); also elsewhere on the board
/IEEE/SRQ_IN: RN13.5 (R4.2); also elsewhere on the board
CHASSIS_GND: J1.12 (GND); also elsewhere on the board
GND: C70.2, C71.2, C72.2, C73.2, C74.2, C75.2, J1.E (GND), J1.F (GND), J1.H (GND), J1.J (GND), J1.K (GND), J1.L (GND), J1.M (GND), J1.N (GND), J20.1, J20.2, RN1.1 (R1.1), RN1.2 (R2.1), RN1.3 (R3.1), RN1.4 (R4.1), RN4.1 (R1.1), RN4.2 (R2.1), RN4.3 (R3.1), RN4.4 (R4.1), RN5.1 (R1.1), RN5.2 (R2.1), RN5.3 (R3.1), RN5.4 (R4.1), RN8.1 (R1.1), RN8.2 (R2.1), RN8.3 (R3.1), RN8.4 (R4.1), U14.1 (1A), U14.7 (GND), U14.13 (6A), U15.3 (2A), U15.7 (GND), U15.13 (6A), U16.7 (GND), U17.10 (GND), U17.19 (CE), U18.8 (A6), U18.9 (A7), U18.10 (GND), U18.19 (CE); also elsewhere on the board
unnamed: RN11.1 (R1.1), U17.18 (B0)
unnamed: RN11.2 (R2.1), U17.17 (B1)
unnamed: RN11.3 (R3.1), U17.16 (B2)
unnamed: RN11.4 (R4.1), U17.15 (B3)
unnamed: RN12.1 (R1.1), U17.14 (B4)
unnamed: RN12.2 (R2.1), U17.13 (B5)
unnamed: RN12.3 (R3.1), U17.12 (B6)
unnamed: RN12.4 (R4.1), U17.11 (B7)
unnamed: RN13.1 (R1.1), U18.18 (B0)
unnamed: RN13.2 (R2.1), U18.17 (B1)
unnamed: RN13.3 (R3.1), U18.16 (B2)
unnamed: RN13.4 (R4.1), U18.15 (B3)
unnamed: R30.1, U18.14 (B4)
unnamed: R31.1, U18.13 (B5)

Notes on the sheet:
This is an approximation of the MC3446 transciever using commonly available parts. The MC3446 internally used a 2.4k/5k voltage divider. We substitute 4.7k/10k because the selection of resistor network arrays is limited from our mfgr (unless we pay a loading fee.) '07 drivers can sink 40ma, which i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
IEEE-488

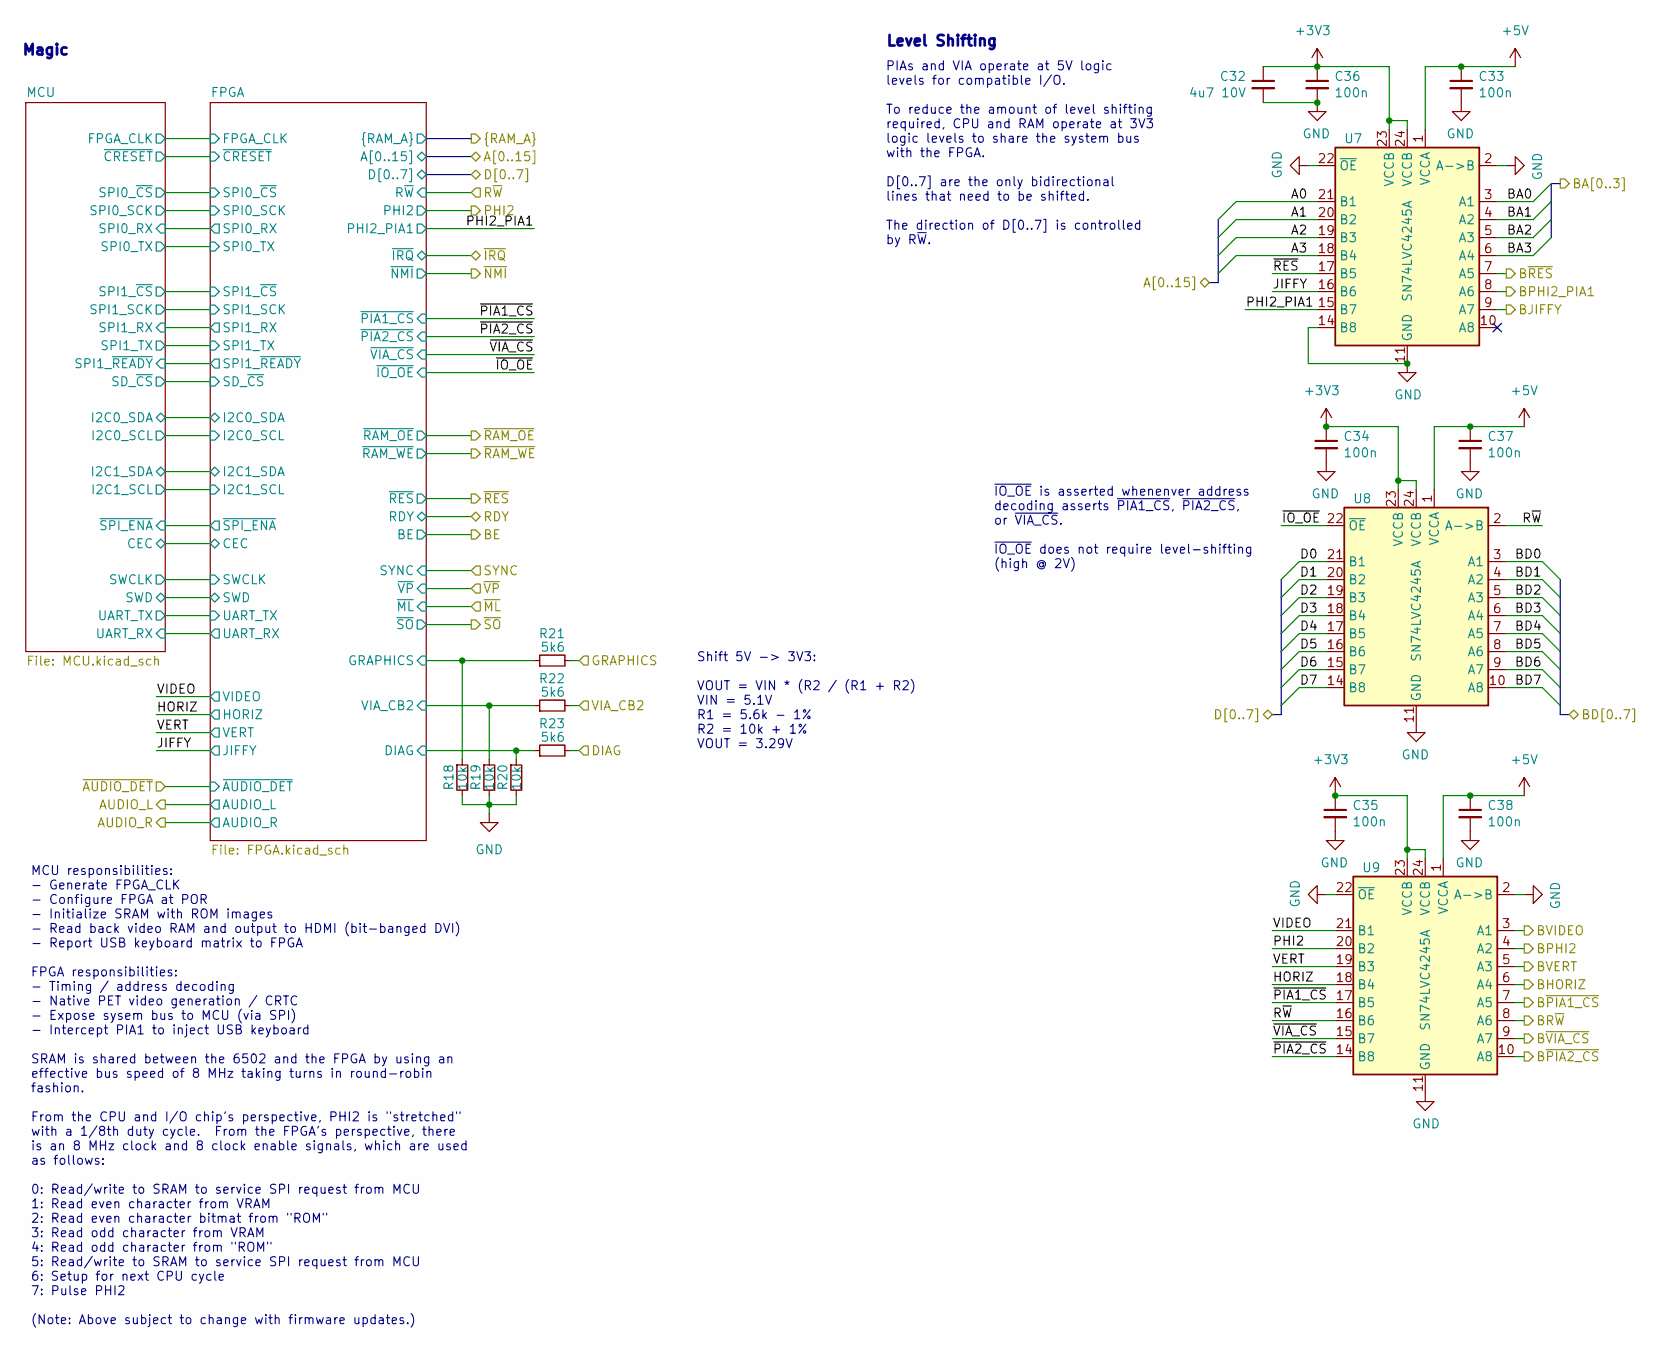
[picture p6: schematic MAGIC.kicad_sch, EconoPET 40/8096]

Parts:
C32: 4u7 10V; C_0402_1005Metric; LCSC Part # C23733
C33, C34, C35, C36, C37, C38: 100n; C_0402_1005Metric; LCSC Part # C307331
R18, R19, R20: 10k; R_0402_1005Metric; LCSC Part # C25744
R21, R22, R23: 5k6; R_0402_1005Metric; LCSC Part # C25908
U7, U8, U9: SN74LVC4245A; TSSOP-24_4.4x7.8mm_P0.65mm; LCSC Part # C7859

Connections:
+3V3: C32.1, C34.1, C35.1, C36.1, U7.23 (VCCB), U7.24 (VCCB), U8.23 (VCCB), U8.24 (VCCB), U9.23 (VCCB), U9.24 (VCCB); also elsewhere on the board
+5V: C33.1, C37.1, C38.1, U7.1 (VCCA), U8.1 (VCCA), U9.1 (VCCA); also elsewhere on the board
/CPU \ RAM/A0: U7.21 (B1); also elsewhere on the board
/CPU \ RAM/A1: U7.20 (B2); also elsewhere on the board
/CPU \ RAM/A2: U7.19 (B3); also elsewhere on the board
/CPU \ RAM/A3: U7.18 (B4); also elsewhere on the board
/CPU \ RAM/D0: U8.21 (B1); also elsewhere on the board
/CPU \ RAM/D1: U8.20 (B2); also elsewhere on the board
/CPU \ RAM/D2: U8.19 (B3); also elsewhere on the board
/CPU \ RAM/D3: U8.18 (B4); also elsewhere on the board
/CPU \ RAM/D4: U8.17 (B5); also elsewhere on the board
/CPU \ RAM/D5: U8.16 (B6); also elsewhere on the board
/CPU \ RAM/D6: U8.15 (B7); also elsewhere on the board
/CPU \ RAM/D7: U8.14 (B8); also elsewhere on the board
/CPU \ RAM/~RES: U7.17 (B5); also elsewhere on the board
/IEEE/IFC_OUT: U7.7 (A5); also elsewhere on the board
/IO/BA0: U7.3 (A1); also elsewhere on the board
/IO/BA1: U7.4 (A2); also elsewhere on the board
/IO/BA2: U7.5 (A3); also elsewhere on the board
/IO/BA3: U7.6 (A4); also elsewhere on the board
/IO/BD0: U8.3 (A1); also elsewhere on the board
/IO/BD1: U8.4 (A2); also elsewhere on the board
/IO/BD2: U8.5 (A3); also elsewhere on the board
/IO/BD3: U8.6 (A4); also elsewhere on the board
/IO/BD4: U8.7 (A5); also elsewhere on the board
/IO/BD5: U8.8 (A6); also elsewhere on the board
/IO/BD6: U8.9 (A7); also elsewhere on the board
/IO/BD7: U8.10 (A8); also elsewhere on the board
/IO/BJIFFY: U7.9 (A7); also elsewhere on the board
/IO/BPHI2: U9.4 (A2); also elsewhere on the board
/IO/BPHI2_PIA1: U7.8 (A6); also elsewhere on the board
/IO/BR~W: U9.8 (A6); also elsewhere on the board
/IO/B~PIA1_CS: U9.7 (A5); also elsewhere on the board
/IO/B~PIA2_CS: U9.10 (A8); also elsewhere on the board
/IO/B~VIA_CS: U9.9 (A7); also elsewhere on the board
/IO/DIAG: R23.2; also elsewhere on the board
/IO/GRAPHIC: R21.2; also elsewhere on the board
/IO/VIA_CB2: R22.2; also elsewhere on the board
/MAGIC/BHORIZ: U9.6 (A4); also elsewhere on the board
/MAGIC/BVERT: U9.5 (A3); also elsewhere on the board
/MAGIC/BVIDEO: U9.3 (A1); also elsewhere on the board
/MAGIC/FPGA/DIAG: R20.1, R23.1; also elsewhere on the board
/MAGIC/FPGA/GRAPHICS: R18.1, R21.1; also elsewhere on the board
/MAGIC/FPGA/VIA_CB2: R19.1, R22.1; also elsewhere on the board
/MAGIC/HORIZ: U9.18 (B4); also elsewhere on the board
/MAGIC/JIFFY: U7.16 (B6); also elsewhere on the board
/MAGIC/PHI2: U9.20 (B2); also elsewhere on the board
/MAGIC/PHI2_PIA1: U7.15 (B7); also elsewhere on the board
/MAGIC/R~W: U8.2 (A->B), U9.16 (B6); also elsewhere on the board
/MAGIC/VERT: U9.19 (B3); also elsewhere on the board
/MAGIC/VIDEO: U9.21 (B1); also elsewhere on the board
/MAGIC/~IO_OE: U8.22 (~OE); also elsewhere on the board
/MAGIC/~PIA1_CS: U9.17 (B5); also elsewhere on the board
/MAGIC/~PIA2_CS: U9.14 (B8); also elsewhere on the board
/MAGIC/~VIA_CS: U9.15 (B7); also elsewhere on the board
GND: C32.2, C33.2, C34.2, C35.2, C36.2, C37.2, C38.2, R18.2, R19.2, R20.2, U7.2 (A->B), U7.11 (GND), U7.12 (GND), U7.13 (GND), U7.14 (B8), U7.22 (~OE), U8.11 (GND), U8.12 (GND), U8.13 (GND), U9.2 (A->B), U9.11 (GND), U9.12 (GND), U9.13 (GND), U9.22 (~OE); also elsewhere on the board

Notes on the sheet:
PIAs and VIA operate at 5V logic levels for compatible I/O. To reduce the amount of level shifting required, CPU and RAM operate at 3V3 logic levels to share the system bus with the FPGA. D[0..7] are the only bidirectional lines that need to be shifted. The direction of D[0..7] is controlled by R~{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
Level Shifting
Magic
MCU responsibilities: - Generate FPGA_CLK - Configure FPGA at POR - Initialize SRAM with ROM images - Read back video RAM and output to HDMI (bit-banged DVI) - Report USB keyboard matrix to FPGA FPGA responsibilities: - Timing / address decoding - Native PET video generation / CRTC - Expose sysem b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
~{IO_OE} is asserted whenenver address decoding asserts ~{PIA1_CS}, ~{PIA2_CS}, or ~{VIA_CS}. ~{IO_OE} does not require level-shifting (high @ 2V)
Shift 5V -> 3V3: VOUT = VIN * (R2 / (R1 + R2) VIN = 5.1V R1 = 5.6k - 1% R2 = 10k + 1% VOUT = 3.29V

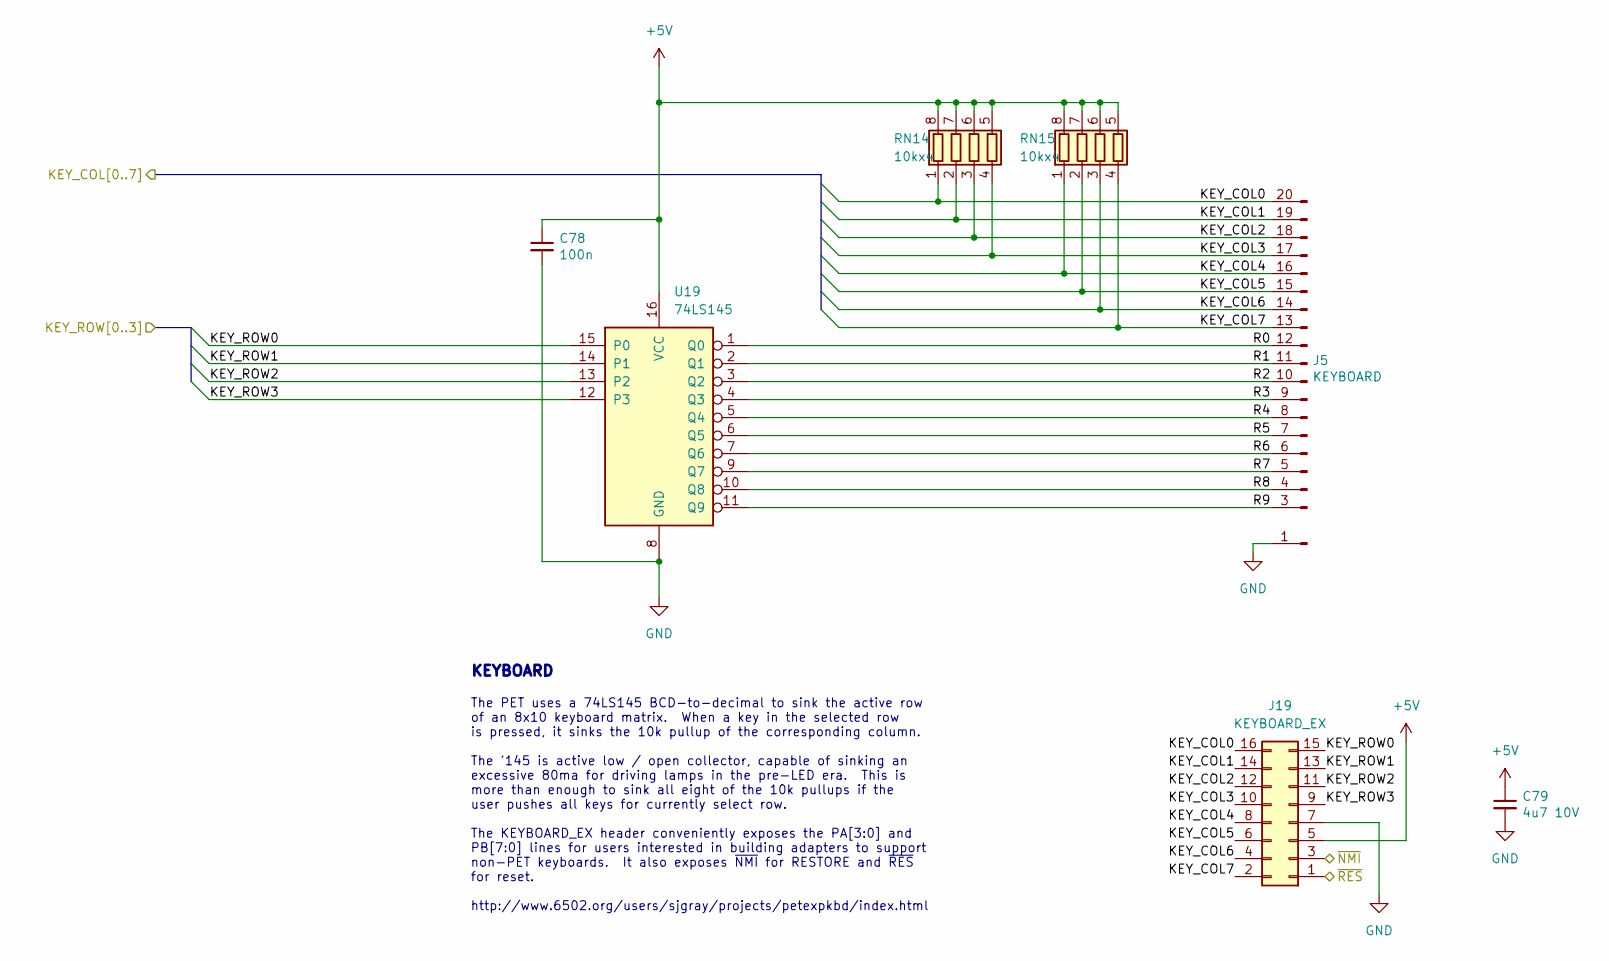
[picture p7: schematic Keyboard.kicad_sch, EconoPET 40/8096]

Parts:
C78: 100n; C_0402_1005Metric; LCSC Part # C307331
C79: 4u7 10V; C_0402_1005Metric; LCSC Part # C23733
J5: KEYBOARD; CBM_PET_KEYBOARD_KEYED_20P; MOUSER 649-1012937893603BLF
J19: KEYBOARD_EX; PinHeader_2x08_P2.54mm_Vertical; MOUSER 649-1012938195002BLF
RN14, RN15: 10kx4; R_Array_Convex_4x0603; LCSC Part # C29718
U19: 74LS145; SOIC-16_3.9x9.9mm_P1.27mm; LCSC Part # C60829

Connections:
+5V: C78.1, C79.1, J19.5, RN14.5 (R4.2), RN14.6 (R3.2), RN14.7 (R2.2), RN14.8 (R1.2), RN15.5 (R4.2), RN15.6 (R3.2), RN15.7 (R2.2), RN15.8 (R1.2), U19.16 (VCC); also elsewhere on the board
/CPU \ RAM/~NMI: J19.3; also elsewhere on the board
/CPU \ RAM/~RES: J19.1; also elsewhere on the board
/IO/KEY_COL0: J5.20, J19.16, RN14.1 (R1.1); also elsewhere on the board
/IO/KEY_COL1: J5.19, J19.14, RN14.2 (R2.1); also elsewhere on the board
/IO/KEY_COL2: J5.18, J19.12, RN14.3 (R3.1); also elsewhere on the board
/IO/KEY_COL3: J5.17, J19.10, RN14.4 (R4.1); also elsewhere on the board
/IO/KEY_COL4: J5.16, J19.8, RN15.1 (R1.1); also elsewhere on the board
/IO/KEY_COL5: J5.15, J19.6, RN15.2 (R2.1); also elsewhere on the board
/IO/KEY_COL6: J5.14, J19.4, RN15.3 (R3.1); also elsewhere on the board
/IO/KEY_COL7: J5.13, J19.2, RN15.4 (R4.1); also elsewhere on the board
/IO/KEY_ROW0: J19.15, U19.15 (P0); also elsewhere on the board
/IO/KEY_ROW1: J19.13, U19.14 (P1); also elsewhere on the board
/IO/KEY_ROW2: J19.11, U19.13 (P2); also elsewhere on the board
/IO/KEY_ROW3: J19.9, U19.12 (P3); also elsewhere on the board
/Keyboard/R0: J5.12, U19.1 (Q0)
/Keyboard/R1: J5.11, U19.2 (Q1)
/Keyboard/R2: J5.10, U19.3 (Q2)
/Keyboard/R3: J5.9, U19.4 (Q3)
/Keyboard/R4: J5.8, U19.5 (Q4)
/Keyboard/R5: J5.7, U19.6 (Q5)
/Keyboard/R6: J5.6, U19.7 (Q6)
/Keyboard/R7: J5.5, U19.9 (Q7)
/Keyboard/R8: J5.4, U19.10 (Q8)
/Keyboard/R9: J5.3, U19.11 (Q9)
GND: C78.2, C79.2, J5.1, J19.7, U19.8 (GND); also elsewhere on the board

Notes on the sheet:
The PET uses a 74LS145 BCD-to-decimal to sink the active row of an 8x10 keyboard matrix. When a key in the selected row is pressed, it sinks the 10k pullup of the corresponding column. The '145 is active low / open collector, capable of sinking an excessive 80ma for driving lamps in the pre-LED era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
KEYBOARD

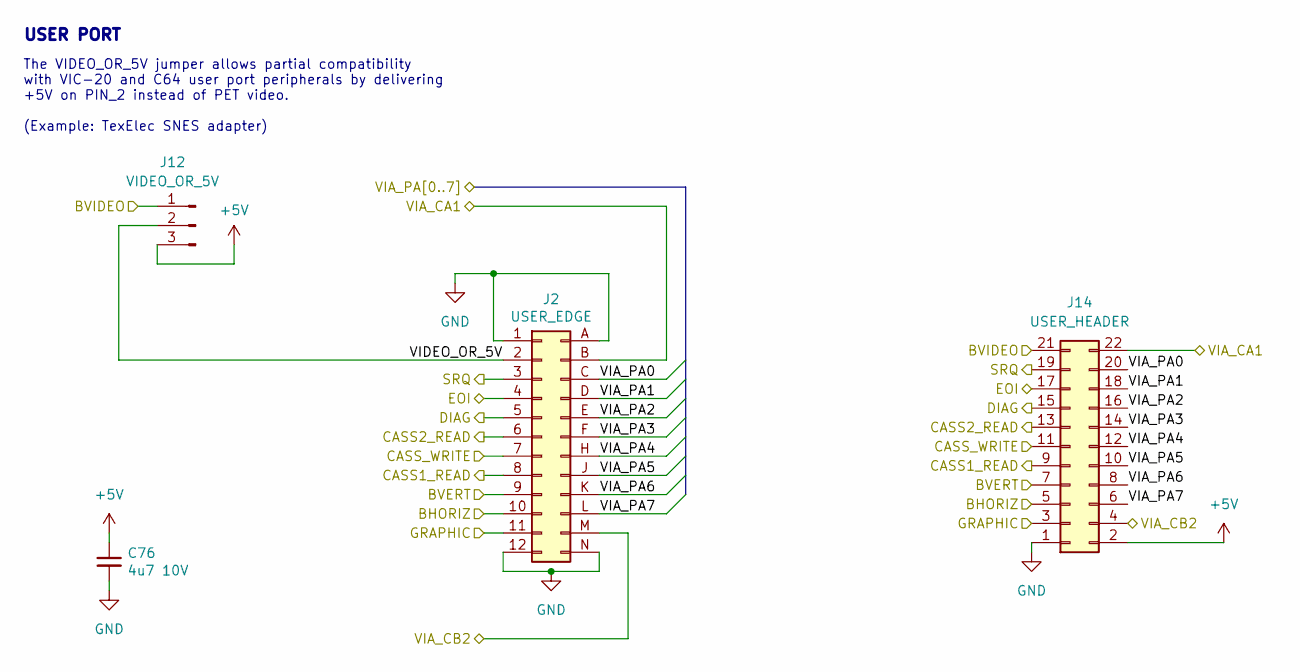
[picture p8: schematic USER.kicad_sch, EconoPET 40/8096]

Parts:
C76: 4u7 10V; C_0402_1005Metric; LCSC Part # C23733
J2: USER_EDGE; CBM_PET_USER_EDGE_CON_24P
J12: VIDEO_OR_5V; PinHeader_1x03_P2.54mm_Vertical_or_SolderJumper
J14: USER_HEADER; PinHeader_2x11_P2.54mm_Vertical; MOUSER 649-1012938195002BLF

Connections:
+5V: C76.1, J12.3, J14.2; also elsewhere on the board
/CASS/CASS1_READ: J2.8 (CASS1_READ), J14.9; also elsewhere on the board
/CASS/CASS2_READ: J2.6 (CASS2_READ), J14.13; also elsewhere on the board
/CASS/CASS_WRITE: J2.7 (CASS_WRITE), J14.11; also elsewhere on the board
/IEEE/EOI: J2.4 (EOI), J14.17; also elsewhere on the board
/IEEE/SRQ: J2.3 (SRQ), J14.19; also elsewhere on the board
/IO/DIAG: J2.5 (DIAG), J14.15; also elsewhere on the board
/IO/GRAPHIC: J2.11 (GRAPHIC), J14.3; also elsewhere on the board
/IO/VIA_CA1: J2.B (VIA_CA1), J14.22; also elsewhere on the board
/IO/VIA_CB2: J2.M (VIA_CB2), J14.4; also elsewhere on the board
/IO/VIA_PA0: J2.C (VIA_PA0), J14.20; also elsewhere on the board
/IO/VIA_PA1: J2.D (VIA_PA1), J14.18; also elsewhere on the board
/IO/VIA_PA2: J2.E (VIA_PA2), J14.16; also elsewhere on the board
/IO/VIA_PA3: J2.F (VIA_PA3), J14.14; also elsewhere on the board
/IO/VIA_PA4: J2.H (VIA_PA4), J14.12; also elsewhere on the board
/IO/VIA_PA5: J2.J (VIA_PA5), J14.10; also elsewhere on the board
/IO/VIA_PA6: J2.K (VIA_PA6), J14.8; also elsewhere on the board
/IO/VIA_PA7: J2.L (VIA_PA7), J14.6; also elsewhere on the board
/MAGIC/BHORIZ: J2.10 (HORIZ), J14.5; also elsewhere on the board
/MAGIC/BVERT: J2.9 (VERT), J14.7; also elsewhere on the board
/MAGIC/BVIDEO: J12.1, J14.21; also elsewhere on the board
/USER/VIDEO_OR_5V: J2.2 (~VIDEO), J12.2
GND: C76.2, J2.1 (GND), J2.12 (GND), J2.A (GND), J2.N (GND), J14.1; also elsewhere on the board

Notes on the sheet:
The VIDEO_OR_5V jumper allows partial compatibility with VIC-20 and C64 user port peripherals by delivering +5V on PIN_2 instead of PET video. (Example: TexElec SNES adapter)
USER PORT

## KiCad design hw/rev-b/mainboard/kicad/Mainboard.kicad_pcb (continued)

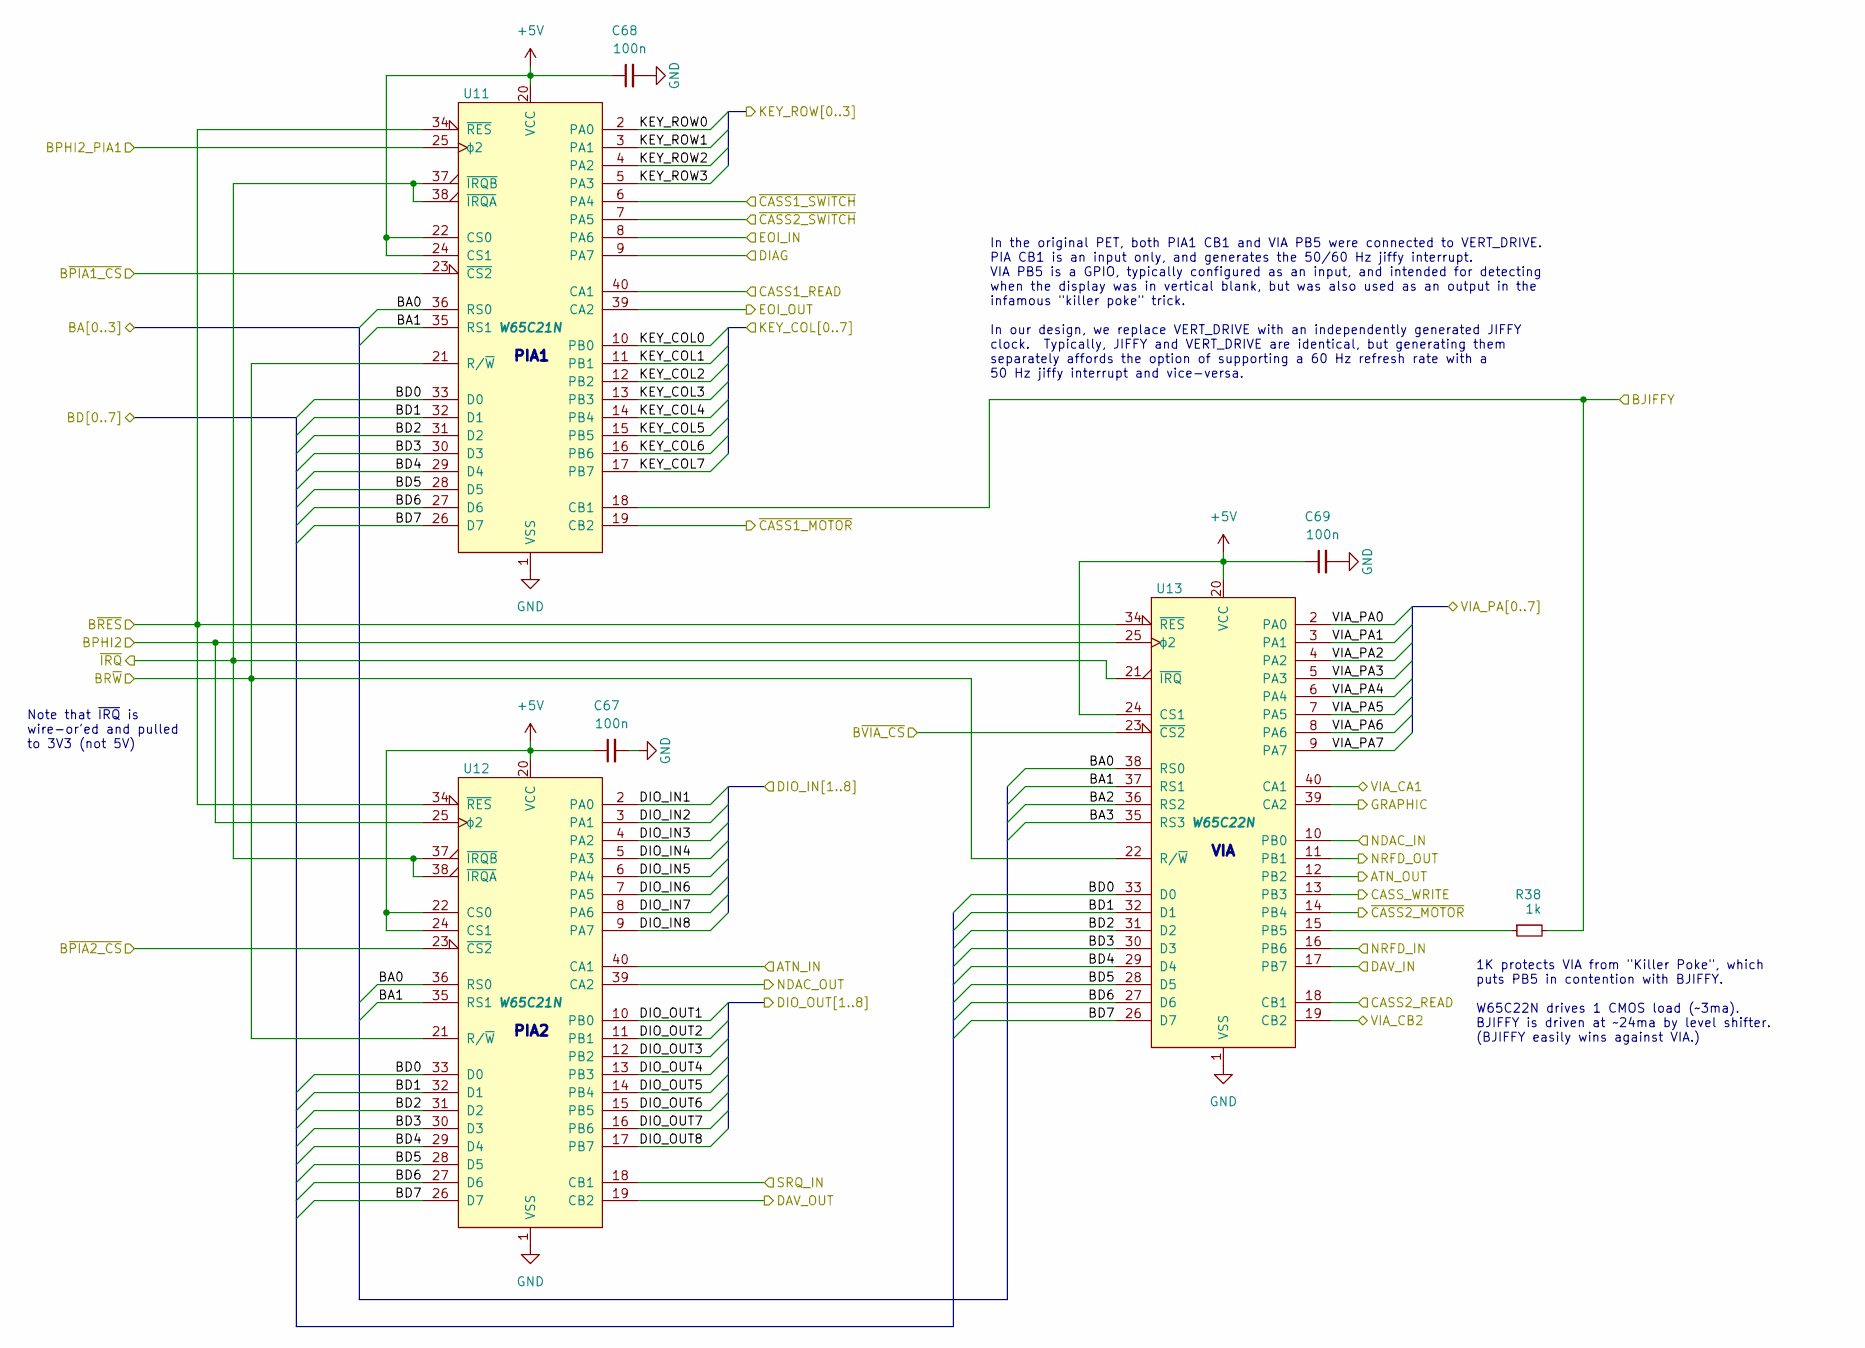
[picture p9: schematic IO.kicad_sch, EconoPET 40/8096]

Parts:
C67, C68, C69: 100n; C_0402_1005Metric; LCSC Part # C307331
R38: 1k; R_0402_1005Metric; LCSC Part # C11702
U11, U12: W65C21N; DIP-40_W15.24mm_Socket; MOUSER 955-W65C21N6TPG-14,571-1-2199299-5
U13: W65C22N; DIP-40_W15.24mm_Socket; MOUSER 955-W65C22N6TPG-14,571-1-2199299-5

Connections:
+5V: C67.1, C68.1, C69.1, U11.20 (VCC), U11.22 (CS0), U11.24 (CS1), U12.20 (VCC), U12.22 (CS0), U12.24 (CS1), U13.20 (VCC), U13.24 (CS1); also elsewhere on the board
/CASS/CASS1_READ: U11.40 (CA1); also elsewhere on the board
/CASS/CASS2_READ: U13.18 (CB1); also elsewhere on the board
/CASS/CASS_WRITE: U13.13 (PB3); also elsewhere on the board
/CASS/~CASS1_MOTOR: U11.19 (CB2); also elsewhere on the board
/CASS/~CASS1_SWITCH: U11.6 (PA4); also elsewhere on the board
/CASS/~CASS2_MOTOR: U13.14 (PB4); also elsewhere on the board
/CASS/~CASS2_SWITCH: U11.7 (PA5); also elsewhere on the board
/IEEE/ATN_IN: U12.40 (CA1); also elsewhere on the board
/IEEE/ATN_OUT: U13.12 (PB2); also elsewhere on the board
/IEEE/DAV_IN: U13.17 (PB7); also elsewhere on the board
/IEEE/DAV_OUT: U12.19 (CB2); also elsewhere on the board
/IEEE/DIO_IN1: U12.2 (PA0); also elsewhere on the board
/IEEE/DIO_IN2: U12.3 (PA1); also elsewhere on the board
/IEEE/DIO_IN3: U12.4 (PA2); also elsewhere on the board
/IEEE/DIO_IN4: U12.5 (PA3); also elsewhere on the board
/IEEE/DIO_IN5: U12.6 (PA4); also elsewhere on the board
/IEEE/DIO_IN6: U12.7 (PA5); also elsewhere on the board
/IEEE/DIO_IN7: U12.8 (PA6); also elsewhere on the board
/IEEE/DIO_IN8: U12.9 (PA7); also elsewhere on the board
/IEEE/DIO_OUT1: U12.10 (PB0); also elsewhere on the board
/IEEE/DIO_OUT2: U12.11 (PB1); also elsewhere on the board
/IEEE/DIO_OUT3: U12.12 (PB2); also elsewhere on the board
/IEEE/DIO_OUT4: U12.13 (PB3); also elsewhere on the board
/IEEE/DIO_OUT5: U12.14 (PB4); also elsewhere on the board
/IEEE/DIO_OUT6: U12.15 (PB5); also elsewhere on the board
/IEEE/DIO_OUT7: U12.16 (PB6); also elsewhere on the board
/IEEE/DIO_OUT8: U12.17 (PB7); also elsewhere on the board
/IEEE/EOI_IN: U11.8 (PA6); also elsewhere on the board
/IEEE/EOI_OUT: U11.39 (CA2); also elsewhere on the board
/IEEE/IFC_OUT: U11.34 (~RES), U12.34 (~RES), U13.34 (~RES); also elsewhere on the board
/IEEE/NDAC_IN: U13.10 (PB0); also elsewhere on the board
/IEEE/NDAC_OUT: U12.39 (CA2); also elsewhere on the board
/IEEE/NRFD_IN: U13.16 (PB6); also elsewhere on the board
/IEEE/NRFD_OUT: U13.11 (PB1); also elsewhere on the board
/IEEE/SRQ_IN: U12.18 (CB1); also elsewhere on the board
/IO/BA0: U11.36 (RS0), U12.36 (RS0), U13.38 (RS0); also elsewhere on the board
/IO/BA1: U11.35 (RS1), U12.35 (RS1), U13.37 (RS1); also elsewhere on the board
/IO/BA2: U13.36 (RS2); also elsewhere on the board
/IO/BA3: U13.35 (RS3); also elsewhere on the board
/IO/BD0: U11.33 (D0), U12.33 (D0), U13.33 (D0); also elsewhere on the board
/IO/BD1: U11.32 (D1), U12.32 (D1), U13.32 (D1); also elsewhere on the board
/IO/BD2: U11.31 (D2), U12.31 (D2), U13.31 (D2); also elsewhere on the board
/IO/BD3: U11.30 (D3), U12.30 (D3), U13.30 (D3); also elsewhere on the board
/IO/BD4: U11.29 (D4), U12.29 (D4), U13.29 (D4); also elsewhere on the board
/IO/BD5: U11.28 (D5), U12.28 (D5), U13.28 (D5); also elsewhere on the board
/IO/BD6: U11.27 (D6), U12.27 (D6), U13.27 (D6); also elsewhere on the board
/IO/BD7: U11.26 (D7), U12.26 (D7), U13.26 (D7); also elsewhere on the board
/IO/BJIFFY: R38.2, U11.18 (CB1); also elsewhere on the board
/IO/BPHI2: U12.25 (ϕ2), U13.25 (ϕ2); also elsewhere on the board
/IO/BPHI2_PIA1: U11.25 (ϕ2); also elsewhere on the board
/IO/BR~W: U11.21 (R/~W), U12.21 (R/~W), U13.22 (R/~W); also elsewhere on the board
/IO/B~PIA1_CS: U11.23 (~CS2); also elsewhere on the board
/IO/B~PIA2_CS: U12.23 (~CS2); also elsewhere on the board
/IO/B~VIA_CS: U13.23 (~CS2); also elsewhere on the board
/IO/DIAG: U11.9 (PA7); also elsewhere on the board
/IO/GRAPHIC: U13.39 (CA2); also elsewhere on the board
/IO/KEY_COL0: U11.10 (PB0); also elsewhere on the board
/IO/KEY_COL1: U11.11 (PB1); also elsewhere on the board
/IO/KEY_COL2: U11.12 (PB2); also elsewhere on the board
/IO/KEY_COL3: U11.13 (PB3); also elsewhere on the board
/IO/KEY_COL4: U11.14 (PB4); also elsewhere on the board
/IO/KEY_COL5: U11.15 (PB5); also elsewhere on the board
/IO/KEY_COL6: U11.16 (PB6); also elsewhere on the board
/IO/KEY_COL7: U11.17 (PB7); also elsewhere on the board
/IO/KEY_ROW0: U11.2 (PA0); also elsewhere on the board
/IO/KEY_ROW1: U11.3 (PA1); also elsewhere on the board
/IO/KEY_ROW2: U11.4 (PA2); also elsewhere on the board
/IO/KEY_ROW3: U11.5 (PA3); also elsewhere on the board
/IO/VIA_CA1: U13.40 (CA1); also elsewhere on the board
/IO/VIA_CB2: U13.19 (CB2); also elsewhere on the board
/IO/VIA_PA0: U13.2 (PA0); also elsewhere on the board
/IO/VIA_PA1: U13.3 (PA1); also elsewhere on the board
/IO/VIA_PA2: U13.4 (PA2); also elsewhere on the board
/IO/VIA_PA3: U13.5 (PA3); also elsewhere on the board
/IO/VIA_PA4: U13.6 (PA4); also elsewhere on the board
/IO/VIA_PA5: U13.7 (PA5); also elsewhere on the board
/IO/VIA_PA6: U13.8 (PA6); also elsewhere on the board
/IO/VIA_PA7: U13.9 (PA7); also elsewhere on the board
/MAGIC/FPGA/~IRQ: U11.37 (~IRQB), U11.38 (~IRQA), U12.37 (~IRQB), U12.38 (~IRQA), U13.21 (~IRQ); also elsewhere on the board
GND: C67.2, C68.2, C69.2, U11.1 (VSS), U12.1 (VSS), U13.1 (VSS); also elsewhere on the board
unnamed: R38.1, U13.15 (PB5)

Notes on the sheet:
1K protects VIA from "Killer Poke", which puts PB5 in contention with BJIFFY. W65C22N drives 1 CMOS load (~3ma). BJIFFY is driven at ~24ma by level shifter. (BJIFFY easily wins against VIA.)
In the original PET, both PIA1 CB1 and VIA PB5 were connected to VERT_DRIVE. PIA CB1 is an input only, and generates the 50/60 Hz jiffy interrupt. VIA PB5 is a GPIO, typically configured as an input, and intended for detecting when the display was in vertical blank, but was also used as an output i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
PIA1
PIA2
Note that ~{IRQ} is wire-or'ed and pulled to 3V3 (not 5V)
VIA

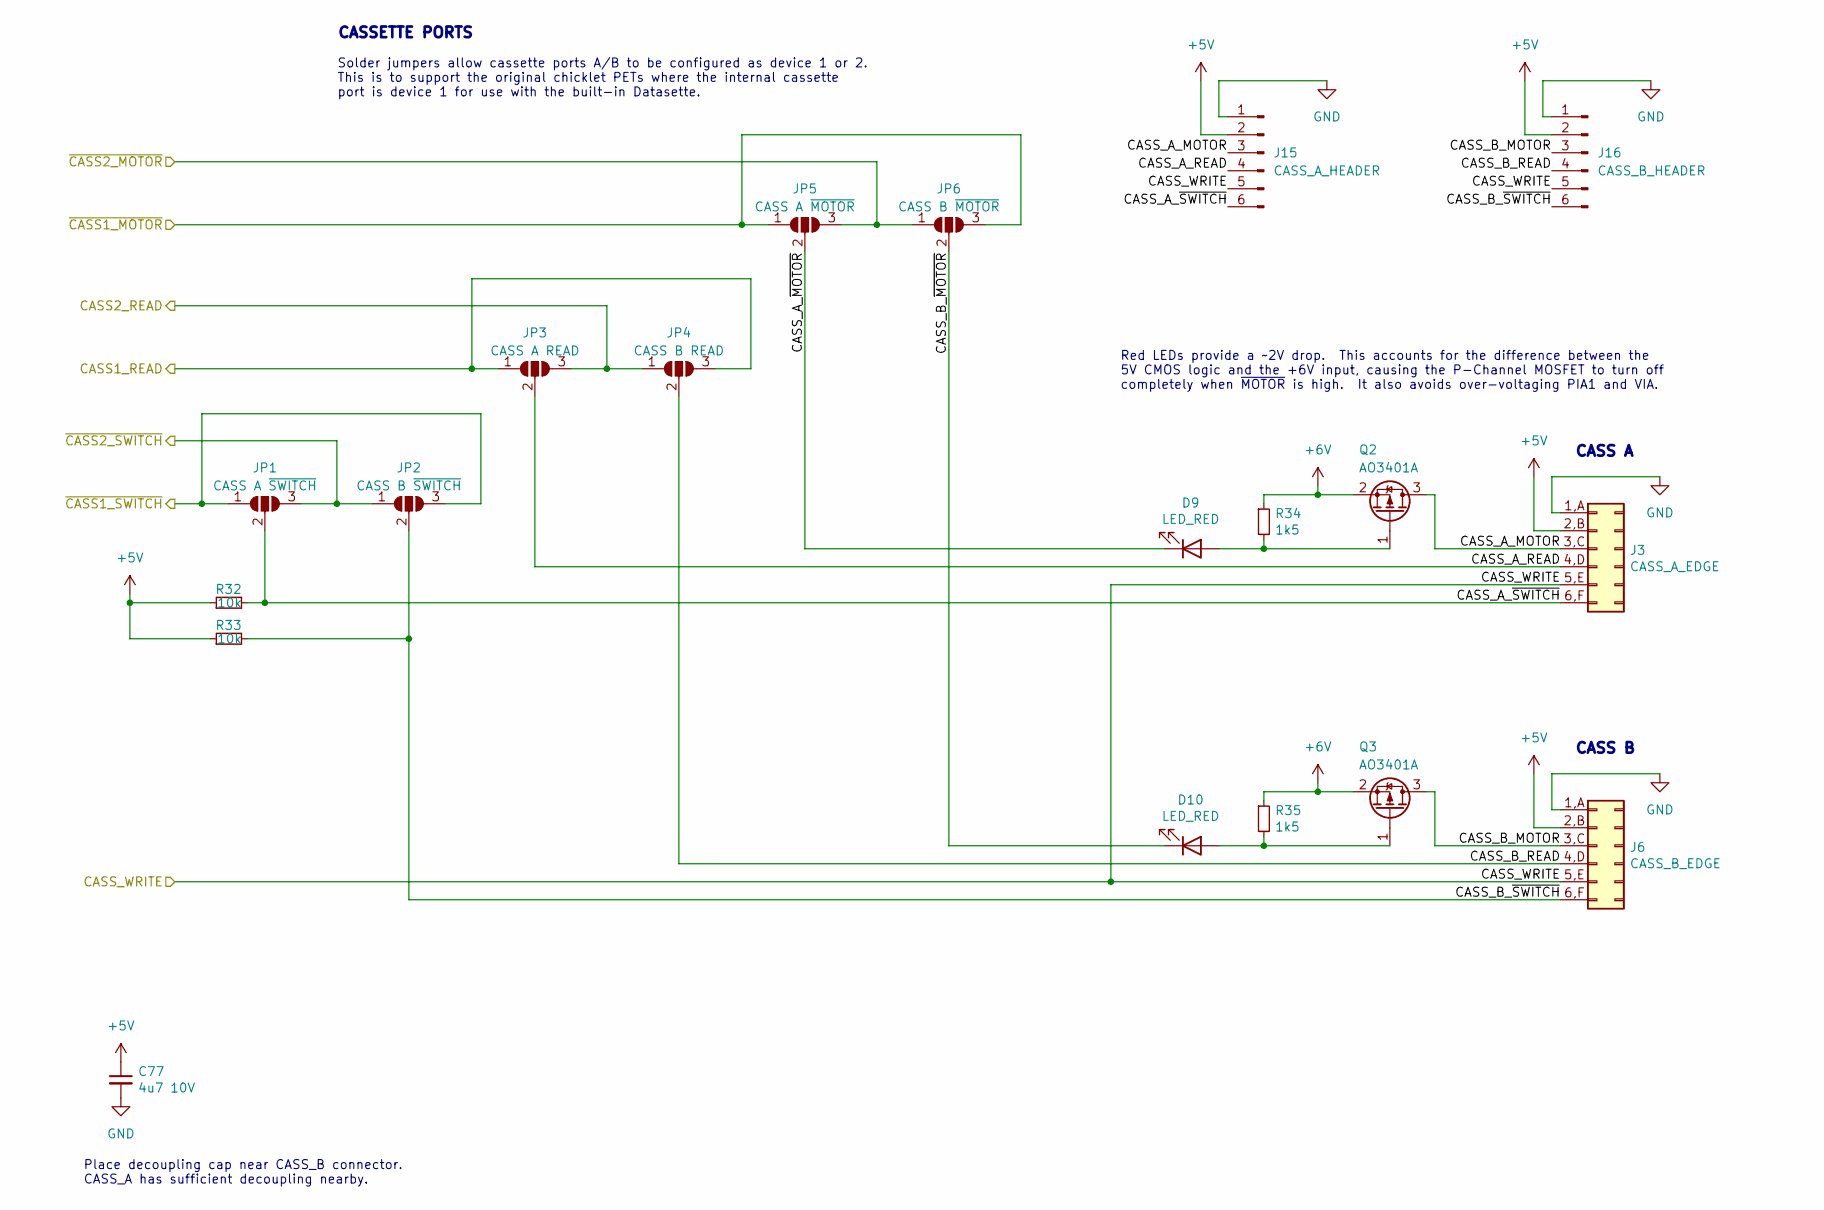
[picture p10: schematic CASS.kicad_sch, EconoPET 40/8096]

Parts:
C77: 4u7 10V; C_0402_1005Metric; LCSC Part # C23733
D9, D10: LED_RED; LED_0603_1608Metric; LCSC Part # C2286
J3: CASS_A_EDGE; CBM_PET_CASS_EDGE_CON_12P
J6: CASS_B_EDGE; CBM_PET_CASS_EDGE_CON_12P
J15: CASS_A_HEADER; PinHeader_1x06_P2.54mm_Vertical; MOUSER 649-1012937891002BLF
J16: CASS_B_HEADER; PinHeader_1x06_P2.54mm_Vertical; MOUSER 649-1012937891002BLF
JP1: CASS A ~{SWITCH}; SolderJumper-3_P1.3mm_Open_RoundedPad1.0x1.5mm
JP2: CASS B ~{SWITCH}; SolderJumper-3_P1.3mm_Open_RoundedPad1.0x1.5mm
JP3: CASS A READ; SolderJumper-3_P1.3mm_Open_RoundedPad1.0x1.5mm
JP4: CASS B READ; SolderJumper-3_P1.3mm_Open_RoundedPad1.0x1.5mm
JP5: CASS A ~{MOTOR}; SolderJumper-3_P1.3mm_Open_RoundedPad1.0x1.5mm
JP6: CASS B ~{MOTOR}; SolderJumper-3_P1.3mm_Open_RoundedPad1.0x1.5mm
Q2, Q3: AO3401A; SOT-23_L2.9-W1.3-P1.90-LS2.4-BR; LCSC Part # C15127
R32, R33: 10k; R_0402_1005Metric; LCSC Part # C25744
R34, R35: 1k5; R_0402_1005Metric; LCSC Part # C25867

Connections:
+5V: C77.1, J3.2,B (+5V), J6.2,B (+5V), J15.2, J16.2, R32.1, R33.1; also elsewhere on the board
+6V: Q2.2 (S), Q3.2 (S), R34.1, R35.1; also elsewhere on the board
/CASS/CASS1_READ: JP3.1 (A), JP4.3 (B); also elsewhere on the board
/CASS/CASS2_READ: JP3.3 (B), JP4.1 (A); also elsewhere on the board
/CASS/CASS_A_MOTOR: J3.3,C (MOTOR), J15.3, Q2.3 (D)
/CASS/CASS_A_READ: J3.4,D (READ), J15.4, JP3.2 (C)
/CASS/CASS_A_~MOTOR: D9.1 (K), JP5.2 (C)
/CASS/CASS_A_~SWITCH: J3.6,F (SWITCH), J15.6, JP1.2 (C), R32.2
/CASS/CASS_B_MOTOR: J6.3,C (MOTOR), J16.3, Q3.3 (D)
/CASS/CASS_B_READ: J6.4,D (READ), J16.4, JP4.2 (C)
/CASS/CASS_B_~MOTOR: D10.1 (K), JP6.2 (C)
/CASS/CASS_B_~SWITCH: J6.6,F (SWITCH), J16.6, JP2.2 (C), R33.2
/CASS/CASS_WRITE: J3.5,E (WRITE), J6.5,E (WRITE), J15.5, J16.5; also elsewhere on the board
/CASS/~CASS1_MOTOR: JP5.1 (A), JP6.3 (B); also elsewhere on the board
/CASS/~CASS1_SWITCH: JP1.1 (A), JP2.3 (B); also elsewhere on the board
/CASS/~CASS2_MOTOR: JP5.3 (B), JP6.1 (A); also elsewhere on the board
/CASS/~CASS2_SWITCH: JP1.3 (B), JP2.1 (A); also elsewhere on the board
GND: C77.2, J3.1,A (GND), J6.1,A (GND), J15.1, J16.1; also elsewhere on the board
unnamed: D9.2 (A), Q2.1 (G), R34.2
unnamed: D10.2 (A), Q3.1 (G), R35.2

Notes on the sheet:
Solder jumpers allow cassette ports A/B to be configured as device 1 or 2. This is to support the original chicklet PETs where the internal cassette port is device 1 for use with the built-in Datasette.
CASS B
Red LEDs provide a ~2V drop. This accounts for the difference between the 5V CMOS logic and the +6V input, causing the P-Channel MOSFET to turn off completely when ~{MOTOR} is high. It also avoids over-voltaging PIA1 and VIA.
CASS A
Place decoupling cap near CASS_B connector. CASS_A has sufficient decoupling nearby.
CASSETTE PORTS

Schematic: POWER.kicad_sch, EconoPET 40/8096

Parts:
C7, C14, C18, C25, C27, C28, C89: 100n; C_0402_1005Metric; LCSC Part # C307331
C9, C10, C85: 22n; C_0402_1005Metric; LCSC Part # C1532
C11, C19, C22, C24, C29: 22u; C_0805_2012Metric; LCSC Part # C45783
C12, C13, C15, C16: 10u; C_0603_1608Metric; LCSC Part # C96446
C17, C21: 33p; C_0402_1005Metric; LCSC Part # C1562
C20: 1u; C_0402_1005Metric; LCSC Part # C52923
C23, C26, C30, C31: 4u7 10V; C_0402_1005Metric; LCSC Part # C23733
C108, C109: 10u 16V; CP_EIA-3216-18_Kemet-A; LCSC Part # C7171
C110: 15000uF; CP_Radial_D18.0mm_P5.00mm_P7.50mm; MOUSER 661-BV250L153AM40S; not fitted
C111, C112: 2200uF; CP_Radial_D12.5mm_P5.00mm_P7.50mm; MOUSER 232-25PK2200MEFC125X
D1, D2, D3: SS54; D_SMA; LCSC Part # C22452
D4: SM4007; D_SOD-123F; LCSC Part # C64898
D6: LED_RED; LED_0603_1608Metric; LCSC Part # C2286
FB1: 600 200ma; L_0603_1608Metric; LCSC Part # C1002
H1: MountingHole_Pad; MountingHole_4mm_Pad
J8: PET POWER; PET_POWER_Molex_KK-396_A-41791-0009_1x09_P3.96mm_Vertical; MOUSER 571-6403849
J10: 5V PWR; PinHeader_2x03_P2.54mm_Vertical; MOUSER 649-1012938195002BLF
J11: 9V POWER; PinHeader_1x02_P2.54mm_Vertical; MOUSER 649-1012937891002BLF
J13: 9V POWER JACK; BarrelJack_Horizontal; MOUSER 806-KLDX-0202-B
J27: 6V POWER; PinHeader_1x02_P2.54mm_Vertical; MOUSER 649-1012937891002BLF
J28: 5V POWER; PinHeader_1x02_P2.54mm_Vertical; MOUSER 649-1012937891002BLF
L1, L2: 1.8uH; IND-SMD_L5.0-W5.0_FNR50XXS; LCSC Part # C167956
R5: 120; R_0805_2012Metric; LCSC Part # C17437
R6: 12k; R_0402_1005Metric; LCSC Part # C25752
R7: 2k2; R_0402_1005Metric; LCSC Part # C25879
R8: 120k; R_0603_1608Metric; LCSC Part # C25808
R9: 13k; R_0603_1608Metric; LCSC Part # C22797
R10: 330; R_0603_1608Metric; LCSC Part # C23138
R11: 22k; R_0402_1005Metric; LCSC Part # C25768
R12: 120; R_0402_1005Metric; LCSC Part # C25079
R13: 4k7; R_0402_1005Metric; LCSC Part # C25900
R14, R16: 330k; R_0603_1608Metric; LCSC Part # C23137
R15: 68k; R_0603_1608Metric; LCSC Part # C23231
R17: 1k5; R_0402_1005Metric; LCSC Part # C25867
R76: 150; R_0805_2012Metric; LCSC Part # C17471
R81: 33K; R_0402_1005Metric; LCSC Part # C25779
U3: AMS1117-3.3; SOT-223-3_TabPin2; LCSC Part # C6186
U4, U6: TPS564247DRLR; SOT-563; MPN TPS564242DRLR; LCSC Part # C5244316
U5: LM317AG-TN3-R; TO-252-2; LCSC Part # C75510

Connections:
+1V2: C20.1, D4.2 (A), FB1.2, R12.1, U5.2 (VO); also elsewhere on the board
+3V3: C108.1, C109.1, R10.1, U3.2 (VO); also elsewhere on the board
+5V: C11.1, C14.2, C21.1, C22.1, C24.1, C26.1, C28.1, C31.1, D4.1 (K), J10.2, J10.4, J10.6, J28.2, L1.2, R14.1, R16.1, R17.1, U3.3 (VI), U5.3 (VI); also elsewhere on the board
+6V: C17.1, C19.1, C29.1, C30.1, C89.1, J27.2, L2.2, R8.1; also elsewhere on the board
+9V_Unreg: C7.1, C12.1, C13.1, C15.1, C16.1, C18.1, C110.1, C111.1, C112.1, J8.2 (9V_IN), J11.2, J13.1, R6.2, R11.1, U4.1 (VIN), U6.1 (VIN)
/POWER/9V_UNFILT: C9.2, C10.1, C85.2, D1.1 (K), D2.1 (K), D3.1 (K), J8.4 (9V_OUT)
/POWER/VAC1: C9.1, D2.2 (A), J8.1 (AC1)
/POWER/VAC2: C10.2, D3.2 (A), J8.5 (AC2)
CHASSIS_GND: H1.1, R5.1, R76.1; also elsewhere on the board
FPGA_VCCA: C23.1, C25.1, C27.1, FB1.1; also elsewhere on the board
GND: C7.2, C11.2, C12.2, C13.2, C14.1, C15.2, C16.2, C18.2, C19.2, C20.2, C22.2, C23.2, C24.2, C25.2, C26.2, C27.2, C28.2, C29.2, C30.2, C31.2, C85.1, C89.2, C108.2, C109.2, C110.2, C111.2, C112.2, D1.2 (A), D6.1 (K), J8.3 (GND), J10.1, J10.3, J10.5, J11.1, J13.2, J13.3, J27.1, J28.1, R5.2, R7.2, R9.2, R10.2, R12.2, R13.2, R15.2, R76.2, R81.2, U3.1 (GND), U4.3 (GND), U4.4 (AGND), U5.1 (ADJ), U6.3 (GND), U6.4 (AGND); also elsewhere on the board
unnamed: D6.2 (A), R17.2
unnamed: R6.1, R7.1, U4.5 (EN)
unnamed: C17.2, R8.2, R9.1, U4.6 (FB)
unnamed: L2.1, U4.2 (SW)
unnamed: R11.2, R13.1, U6.5 (EN)
unnamed: C21.2, R14.2, R15.1, R16.2, R81.1, U6.6 (FB)
unnamed: L1.1, U6.2 (SW)

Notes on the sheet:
LM317A: ΔV_{OUT}=~3V (at ≥ 10ma) Use 120Ω load resistor T20Q144 VCORE Requirements Typical: 1.15V ~ 1.25V, Absolute max: 1.42V
18.3 VAC C.T. arrives on pins 1/5. Rectified DC leaves on pin 4, is externally smoothed by a 17-23mF capacitor and returns on pin 2. Despite being labeled 9V_UNREG in the CBM schematics, the actual voltage is closer to 12V. Pins 8/9 are not used by the replacement board. The PET power supply delive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
Power Indicator
+9V_UNREG
+9V Unreg Supply
Configurable PS filtering caps
Power Headers
FPGA_VCCA is the analog VCORE source for PLLs
AMS1117-3.3: ΔV_{OUT}=1.3V I_{L(MIN)}=10ma Use 330Ω load resistor
+5V Supply
Mounting Holes
120 Ω ∥ 150 Ω ≈ 66.7 Ω (1%) is within tolerance of CBM/PET 68 Ω (5%) Effective 0.225W ≈ original 1/4W
+1.25V Supply
+6V Supply
+3.3V Supply
Max load of ~400ma observed with a black C2N when motor is stalled at end-of-tape during rewind. 6.1V @ 1A allows 400ma per cassette port with some headroom. Voltage is non-critical as the datasette speed is controlled by a mechanical governor.
AMS1117 datasheet specifies 22u tant, but does not state a required ESR range for stability. TI LM1117 specifies 0.3-22Ω. Each C_{OUT} is 3Ω @ 100kHz (for 1.5Ω in parallel). AMS1117 internal protection diodes sufficient with output caps < 1000uF

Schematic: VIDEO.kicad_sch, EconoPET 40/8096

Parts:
J7: VIDEO; PET_Video; MOUSER 649-1012937893603BLF

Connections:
/MAGIC/BHORIZ: J7.5 (HORIZ); also elsewhere on the board
/MAGIC/BVERT: J7.3 (VERT); also elsewhere on the board
/MAGIC/BVIDEO: J7.1 (GND); also elsewhere on the board
GND: J7.2 (GND), J7.4 (GND), J7.7 (VIDEO); also elsewhere on the board

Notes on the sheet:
Not too much to see here. :-) If you're looking for the modern DVI video output over an HDMI connector, look under Magic / MCU / DVI.
VIDEO HEADER

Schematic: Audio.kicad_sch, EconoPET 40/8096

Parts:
C8, C84: 47u 10V; C_1206_3216Metric; LCSC Part # C96123
C80, C114, C115: 1u; C_0402_1005Metric; LCSC Part # C52923
C81, C116: 22n; C_0402_1005Metric; LCSC Part # C1532
C82: 68n; C_0603_1608Metric; LCSC Part # C31658
C83, C106, C107: 100n; C_0402_1005Metric; LCSC Part # C307331
C105: 47n; C_0603_1608Metric; LCSC Part # C1622
C113: 22u; C_0805_2012Metric; LCSC Part # C45783
D13, D14: 1N4148WS; D_SOD-323; LCSC Part # C2128
J21: AUDIO; CUI_SJ-43504-SMT-TR; MOUSER 490-SJ-43504-SMT-TR
LS1: 42Ω SPK; AT1220TT9R; MOUSER 665-AT1220TT9R
Q4, Q5, Q6: SS8050; SOT-23; LCSC Part # C2150
Q7: SS8550; SOT-23; LCSC Part # C8542
R36, R75: 12k; R_0402_1005Metric; LCSC Part # C25752
R37: 22k; R_0402_1005Metric; LCSC Part # C25768
R67, R69: 1k5; R_0402_1005Metric; LCSC Part # C25867
R68: 680; R_0402_1005Metric; LCSC Part # C25130
R70: 10k; R_0402_1005Metric; LCSC Part # C25744
R71: 100k; R_0402_1005Metric; LCSC Part # C25741
R72, R73: 1; R_0603_1608Metric; LCSC Part # C22936
R74: 1k; R_0402_1005Metric; LCSC Part # C11702

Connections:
+6V: C106.1, C107.1, C113.1, C114.1, Q6.3 (C), R70.1, R74.1; also elsewhere on the board
/AUDIO/~AUDIO_DET: J21.4; also elsewhere on the board
/MAGIC/FPGA/AUDIO_L: C115.1; also elsewhere on the board
/MAGIC/FPGA/AUDIO_R: C80.1; also elsewhere on the board
GND: C81.2, C83.2, C106.2, C107.2, C113.2, C114.2, C116.2, J21.1, LS1.2, Q4.2 (E), Q5.2 (E), Q7.3 (C), R68.1; also elsewhere on the board
unnamed: C8.1, C84.1, R71.1, R72.2, R73.1
unnamed: C8.2, C84.2, LS1.1
unnamed: C80.2, R36.1
unnamed: C81.1, J21.3, R36.2
unnamed: C83.1, R67.2, R69.1
unnamed: C82.2, C105.2, R68.2
unnamed: C115.2, R75.1
unnamed: C116.1, J21.2, R75.2
unnamed: D13.2 (A), Q6.1 (B), R74.2
unnamed: D13.1 (K), D14.2 (A)
unnamed: D14.1 (K), Q5.3 (C), Q7.1 (B)
unnamed: J21.5, J21.6, Q4.1 (B), R37.1
unnamed: C82.1, Q4.3 (C), R37.2, R67.1, R70.2
unnamed: C105.1, Q5.1 (B), R69.2, R71.2
unnamed: Q6.2 (E), R72.1
unnamed: Q7.2 (E), R73.2

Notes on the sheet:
Audio
Twin-T notch filter compensates for 2 KHz resonant frequency of our chosen speaker.
PET CB2 and DIAG are connected to FPGA inputs elsewhere in the schematic and are therefore not shown on this page. Within the FPGA, DIAG gates the CB2 sound signal, replacing the external AND gate used in the original PET circuitry. The FPGA then mixes the gated PET CB2 audio with the FPGA-implemen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

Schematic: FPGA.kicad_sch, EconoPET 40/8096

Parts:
C39, C41, C42, C43: 1u; C_0402_1005Metric; LCSC Part # C52923
C40, C44, C45, C46, C47, C48, C49, C50, C51, C52, C53, C55, C57, C59: 100n; C_0402_1005Metric; LCSC Part # C307331
C54, C56, C58, C60, C61: 10n; C_0402_1005Metric; LCSC Part # C15195
C62, C63, C64, C65, C66: 4u7 10V; C_0402_1005Metric; LCSC Part # C23733
D7: LED_GRN; LED_0603_1608Metric; LCSC Part # C2986059
D8: LED_RED; LED_0603_1608Metric; LCSC Part # C2286
J4: BUS_EXPANSION; PinHeader_2x25_P2.54mm_Vertical; MOUSER 649-1012938195002BLF
J9: FPGA_MCU; PinHeader_2x10_P2.54mm_Vertical; MOUSER 649-1012938195002BLF
J17: PMOD1; PMOD_Socket_2x06_P2.54mm_Horizontal; MOUSER 710-613012243121
J18: PMOD2; PMOD_Socket_2x06_P2.54mm_Horizontal; MOUSER 710-613012243121
J22: PROG; IDC-Header_2x08_P2.54mm_Vertical; MOUSER 710-61201621621
Q1: MMBT3904; SOT-23; LCSC Part # C20526
R24, R28: 100k; R_0402_1005Metric; LCSC Part # C25741
R25: 10k; R_0402_1005Metric; LCSC Part # C25744
R26: 12k; R_0402_1005Metric; LCSC Part # C25752
R27, R29: 1k; R_0402_1005Metric; LCSC Part # C11702
RN9, RN10: 10kx4; R_Array_Convex_4x0603; LCSC Part # C29718
SW3: CONFIG; SW_DIP_SPSTx03_Slide_6.7x9.18mm_W7.62mm_P2.54mm_LowProfile_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; MOUSER 490-DS04-254-1L-02BK
U10: T20Q144C3; LQFP-144_20x20mm_P0.5mm; DIGI-KEY 2134-T8Q144C3-ND

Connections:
+1V2: C39.1, C42.1, C44.1, C46.1, C48.1, C50.1, C52.1, C54.1, C56.1, C58.1, U10.13 (VCC), U10.22 (VCC), U10.49 (VCC), U10.57 (VCC), U10.85 (VCC), U10.96 (VCC), U10.125 (VCC), U10.128 (VCC), U10.130 (VCC); also elsewhere on the board
+3V3: C41.1, C43.1, C45.1, C47.1, C49.1, C51.1, C53.1, C55.1, C57.1, C59.1, C60.1, C61.1, C62.1, C63.1, C64.1, C65.1, J4.3, J9.2, J17.6, J17.12, J18.6, J18.12, R25.2, R27.2, R29.2, RN9.5 (R4.2), RN9.6 (R3.2), RN9.7 (R2.2), RN9.8 (R1.2), RN10.5 (R4.2), RN10.6 (R3.2), RN10.7 (R2.2), RN10.8 (R1.2), U10.12 (VCCIO1C_1D), U10.21 (VCCIO1B), U10.23 (VCCIO1A), U10.51 (VCCIO4B), U10.52 (VCCIO4B), U10.62 (VCCIO4A), U10.63 (VCCIO4A), U10.88 (VCCIO3E), U10.91 (VCCIO3D), U10.95 (VCCIO3B_3C), U10.122 (VCCIO3A), U10.143 (VCCIO1E); also elsewhere on the board
+5V: C66.1, J4.2, J22.10; also elsewhere on the board
/AUDIO/~AUDIO_DET: U10.20 (GPIOL_12_CDI2); also elsewhere on the board
/CPU \ RAM/A0: J4.15, U10.60 (GPIOB_RXN03); also elsewhere on the board
/CPU \ RAM/A1: J4.17, U10.65 (GPIOB_RXN07); also elsewhere on the board
/CPU \ RAM/A2: J4.19, U10.67 (GPIOB_RXP10); also elsewhere on the board
/CPU \ RAM/A3: J4.21, U10.70 (GPIOB_RXP12_EXTFB0); also elsewhere on the board
/CPU \ RAM/A4: J4.23, U10.75 (GPIOR_157_PLLIN); also elsewhere on the board
/CPU \ RAM/A5: J4.25, U10.76 (GPIOR_155); also elsewhere on the board
/CPU \ RAM/A6: J4.27, U10.82 (GPIOR_138); also elsewhere on the board
/CPU \ RAM/A7: J4.29, U10.86 (GPIOR_133_CDI18); also elsewhere on the board
/CPU \ RAM/A8: J4.31, U10.89 (GPIOR_129_CTRL10); also elsewhere on the board
/CPU \ RAM/A9: J4.33, U10.92 (GPIOR_125_CLK10); also elsewhere on the board
/CPU \ RAM/A10: J4.35, U10.97 (GPIOR_122_CLK13_CDI21); also elsewhere on the board
/CPU \ RAM/A11: J4.37, U10.99 (GPIOR_116_CTRL15); also elsewhere on the board
/CPU \ RAM/A12: J4.14, U10.59 (GPIOB_RXN02); also elsewhere on the board
/CPU \ RAM/A13: J4.16, U10.61 (GPIOB_RXP03); also elsewhere on the board
/CPU \ RAM/A14: J4.18, U10.66 (GPIOB_RXP07); also elsewhere on the board
/CPU \ RAM/A15: J4.20, U10.69 (GPIOB_RXN12_EXTFB0); also elsewhere on the board
/CPU \ RAM/D0: J4.26, U10.77 (GPIOR_154); also elsewhere on the board
/CPU \ RAM/D1: J4.28, U10.83 (GPIOR_136_CDI16); also elsewhere on the board
/CPU \ RAM/D2: J4.30, U10.87 (GPIOR_132_CDI19); also elsewhere on the board
/CPU \ RAM/D3: J4.32, U10.90 (GPIOR_128_CTRL11); also elsewhere on the board
/CPU \ RAM/D4: J4.34, U10.93 (GPIOR_123_CLK12_CDI20); also elsewhere on the board
/CPU \ RAM/D5: J4.36, U10.98 (GPIOR_117_CTRL14); also elsewhere on the board
/CPU \ RAM/D6: J4.38, U10.100 (GPIOR_113_CDI22); also elsewhere on the board
/CPU \ RAM/D7: J4.40, U10.101 (GPIOR_112_CDI23); also elsewhere on the board
/CPU \ RAM/RAM_A10: U10.84 (GPIOR_135_CDI17); also elsewhere on the board
/CPU \ RAM/RAM_A11: U10.81 (GPIOR_139); also elsewhere on the board
/CPU \ RAM/RAM_A15: U10.68 (GPIOB_RXN10); also elsewhere on the board
/CPU \ RAM/RAM_A16: J4.22, U10.71 (GPIOB_CLKP0); also elsewhere on the board
/CPU \ RAM/~ML: U10.41 (GPIOB_TXN02); also elsewhere on the board
/CPU \ RAM/~NMI: J4.11, U10.55 (GPIOB_RXP00); also elsewhere on the board
/CPU \ RAM/~RAM_OE: U10.72 (GPIOB_CLKN0); also elsewhere on the board
/CPU \ RAM/~RAM_WE: U10.58 (GPIOB_RXP02); also elsewhere on the board
/CPU \ RAM/~RES: J4.4, U10.43 (GPIOB_TXN04); also elsewhere on the board
/CPU \ RAM/~VP: U10.42 (GPIOB_TXP04); also elsewhere on the board
/MAGIC/FPGA/AUDIO_L: J9.3, U10.33 (GPIOL_05_CSO); also elsewhere on the board
/MAGIC/FPGA/AUDIO_R: J9.4, R25.1, U10.32 (GPIOL_04_CSI); also elsewhere on the board
/MAGIC/FPGA/BE: J4.9, U10.53 (GPIOB_TXP11); also elsewhere on the board
/MAGIC/FPGA/CBUS1: J4.43, RN10.2 (R2.1), U10.79 (GPIOR_150_CBUS1)
/MAGIC/FPGA/CBUS2: J4.44, RN10.1 (R1.1), U10.80 (GPIOR_149_CBUS2)
/MAGIC/FPGA/CDONE: J22.16, R28.2, RN9.4 (R4.1), U10.34 (CDONE)
/MAGIC/FPGA/CEC: J9.19, U10.6 (GPIOL_46); also elsewhere on the board
/MAGIC/FPGA/DIAG: U10.39 (GPIOB_TXN00); also elsewhere on the board
/MAGIC/FPGA/FPGA_CLK: U10.132 (GPIOL_74_PLLIN0); also elsewhere on the board
/MAGIC/FPGA/GRAPHICS: U10.40 (GPIOB_TXP02); also elsewhere on the board
/MAGIC/FPGA/HOLD: J22.15
/MAGIC/FPGA/I2C0_SCL: J9.11, U10.15 (GPIOL_24_CLK0); also elsewhere on the board
/MAGIC/FPGA/I2C0_SDA: J9.9, U10.18 (GPIOL_20_CTRL0_CDI4); also elsewhere on the board
/MAGIC/FPGA/I2C1_SCL: J9.12, U10.14 (GPIOL_25_CLK1); also elsewhere on the board
/MAGIC/FPGA/I2C1_SDA: J9.10, U10.17 (GPIOL_21_CTRL1_CDI5); also elsewhere on the board
/MAGIC/FPGA/NSTATUS: D8.1 (K), J22.11, U10.136 (GPIOL_71_NSTATUS)
/MAGIC/FPGA/PMOD1_1: J17.1, U10.135 (GPIOL_72_EXTFB0_CDI14)
/MAGIC/FPGA/PMOD1_2: J17.2, U10.131 (GPIOL_75_PLLIN1)
/MAGIC/FPGA/PMOD1_3: J17.3, U10.123 (GPIOR_77_PLLIN1)
/MAGIC/FPGA/PMOD1_4: J17.4, U10.118 (GPIOR_79_EXTFB1_CDI30)
/MAGIC/FPGA/PMOD1_5: J17.7, U10.137 (GPIOL_70_CBSEL0)
/MAGIC/FPGA/PMOD1_6: J17.8, U10.134 (GPIOL_73_EXTFB1_CDI15)
/MAGIC/FPGA/PMOD1_7: J17.9, U10.124 (GPIOR_76_PLLIN0)
/MAGIC/FPGA/PMOD1_8: J17.10, U10.119 (GPIOR_78_EXTFB0_CDI31)
/MAGIC/FPGA/PMOD2_1: J18.1, U10.4 (GPIOL_54_CDI11)
/MAGIC/FPGA/PMOD2_2: J18.2, U10.144 (GPIOL_64)
/MAGIC/FPGA/PMOD2_3: J18.3, U10.141 (GPIOL_65)
/MAGIC/FPGA/PMOD2_4: J18.4, U10.139 (GPIOL_68)
/MAGIC/FPGA/PMOD2_5: J18.7, U10.3 (GPIOL_53_CDI10)
/MAGIC/FPGA/PMOD2_6: J18.8, U10.142 (GPIOL_66_CDI12)
/MAGIC/FPGA/PMOD2_7: J18.9, U10.140 (GPIOL_67_CDI13)
/MAGIC/FPGA/PMOD2_8: J18.10, U10.138 (GPIOL_69_CBSEL1)
/MAGIC/FPGA/R94: J4.48, U10.106 (GPIOR_94_CDI27)
/MAGIC/FPGA/R95: J4.47, U10.105 (GPIOR_95_CDI26)
/MAGIC/FPGA/R104: J4.46, U10.103 (GPIOR_104_CDI25)
/MAGIC/FPGA/R105: J4.45, U10.102 (GPIOR_105_CDI24)
/MAGIC/FPGA/RDY: J4.6, U10.45 (GPIOB_TXP06); also elsewhere on the board
/MAGIC/FPGA/REF_RES: R26.2, U10.36 (REF_RES)
/MAGIC/FPGA/S1: SW3.6, U10.116 (GPIOR_81_MREFCLK)
/MAGIC/FPGA/S2: SW3.5, U10.117 (GPIOR_80)
/MAGIC/FPGA/S3: SW3.4, U10.19 (GPIOL_13_CDI3)
/MAGIC/FPGA/SPI0_RX: J9.8, U10.28 (GPIOL_09_CDI1); also elsewhere on the board
/MAGIC/FPGA/SPI0_SCK: J9.6, U10.30 (GPIOL_01_CCK); also elsewhere on the board
/MAGIC/FPGA/SPI0_TX: J9.7, U10.29 (GPIOL_08_CDI0); also elsewhere on the board
/MAGIC/FPGA/SPI0_~CS: J9.5, J22.12, U10.31 (GPIOL_00_SS_N); also elsewhere on the board
/MAGIC/FPGA/SPI1_RX: J9.20, U10.7 (GPIOL_41_CDI9); also elsewhere on the board
/MAGIC/FPGA/SPI1_SCK: J9.15, U10.11 (GPIOL_31_CLK7_CDI6); also elsewhere on the board
/MAGIC/FPGA/SPI1_TX: J9.18, U10.8 (GPIOL_40_CDI8); also elsewhere on the board
/MAGIC/FPGA/SPI1_~CS: J9.17, U10.10 (GPIOL_32_CTRL4_CDI7); also elsewhere on the board
/MAGIC/FPGA/SPI1_~READY: J9.16, U10.16 (GPIOL_22_CTRL2); also elsewhere on the board
/MAGIC/FPGA/SWCLK: J22.3; also elsewhere on the board
/MAGIC/FPGA/SWD: J22.5; also elsewhere on the board
/MAGIC/FPGA/SYNC: J4.10, U10.54 (GPIOB_TXN11); also elsewhere on the board
/MAGIC/FPGA/TCK: J22.2, RN9.1 (R1.1), U10.26 (TCK)
/MAGIC/FPGA/TDI: J22.4, RN9.2 (R2.1), U10.27 (TDI)
/MAGIC/FPGA/TDO: J22.6, U10.24 (TDO)
/MAGIC/FPGA/TMS: J22.8, RN9.3 (R3.1), U10.25 (TMS)
/MAGIC/FPGA/UART_RX: J22.7; also elsewhere on the board
/MAGIC/FPGA/UART_TX: J22.9; also elsewhere on the board
/MAGIC/FPGA/VIA_CB2: U10.38 (GPIOB_TXP00); also elsewhere on the board
/MAGIC/FPGA/~CRESET: C40.1, J22.14, R24.1, U10.35 (~CRESET); also elsewhere on the board
/MAGIC/FPGA/~IRQ: J4.5, U10.46 (GPIOB_TXN06); also elsewhere on the board
/MAGIC/FPGA/~SO: J4.8, U10.48 (GPIOB_TXN09); also elsewhere on the board
/MAGIC/FPGA/~SPI_ENA: J22.13; also elsewhere on the board
/MAGIC/HORIZ: U10.111 (GPIOR_85); also elsewhere on the board
/MAGIC/JIFFY: J4.42, RN10.3 (R3.1), U10.78 (GPIOR_151_CBUS0); also elsewhere on the board
/MAGIC/MCU/SD_~CS: J9.14; also elsewhere on the board
/MAGIC/PHI2: J4.7, U10.47 (GPIOB_TXP09); also elsewhere on the board
/MAGIC/PHI2_PIA1: J4.41, RN10.4 (R4.1), U10.74 (GPIOR_158_TEST_N); also elsewhere on the board
/MAGIC/R~W: J4.12, U10.56 (GPIOB_RXN00); also elsewhere on the board
/MAGIC/VERT: U10.110 (GPIOR_87_CDI29); also elsewhere on the board
/MAGIC/VIDEO: U10.109 (GPIOR_88_CDI28); also elsewhere on the board
/MAGIC/~IO_OE: U10.115 (GPIOR_82); also elsewhere on the board
/MAGIC/~PIA1_CS: U10.112 (GPIOR_86); also elsewhere on the board
/MAGIC/~PIA2_CS: U10.114 (GPIOR_83); also elsewhere on the board
/MAGIC/~VIA_CS: U10.113 (GPIOR_84); also elsewhere on the board
FPGA_VCCA: U10.2 (VCCA_TL), U10.73 (VCCA_BR), U10.107 (VCCA_TR); also elsewhere on the board
GND: C39.2, C40.2, C41.2, C42.2, C43.2, C44.2, C45.2, C46.2, C47.2, C48.2, C49.2, C50.2, C51.2, C52.2, C53.2, C54.2, C55.2, C56.2, C57.2, C58.2, C59.2, C60.2, C61.2, C62.2, C63.2, C64.2, C65.2, C66.2, J4.1, J4.13, J4.24, J4.39, J4.49, J4.50, J9.1, J9.13, J17.5, J17.11, J18.5, J18.11, J22.1, Q1.2 (E), R24.2, R26.1, SW3.1, SW3.2, SW3.3, U10.1 (GND), U10.5 (GND), U10.9 (GND), U10.37 (GND), U10.44 (GND), U10.50 (GND), U10.64 (GND), U10.94 (GND), U10.104 (GND), U10.108 (GND), U10.120 (GND), U10.121 (GND), U10.126 (GND), U10.127 (GND), U10.129 (GND), U10.133 (GND); also elsewhere on the board
unnamed: D7.2 (A), R27.1
unnamed: D7.1 (K), Q1.3 (C)
unnamed: D8.2 (A), R29.1
unnamed: Q1.1 (B), R28.1

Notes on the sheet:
BD0
TODO: Cleanup
1% tolerance specified
BD2
BD1
NSTATUS driven low if bitstream contains wrong device ID or fails CRC check.
AD7
AD4
During configuration, GPIO pins (excluding LVDS) are configured in weak pull-up mode. LVDS are tri-stated without a pull-up or pull-down resistor. Pull ~{CRESET} low to reset FPGA until MCU is ready. Note that MCU drives ~{CRESET} through 10k resistor so it can be overridden by programmer when conn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
BD3
Minimum decoupling caps is one 100nF and one 10nF Place lowest values closest to pin.
AD5
AD6
AD3
CDONE is open drain and requires pullup to enter user mode. TDO is terminated by the programmer at the receiving end.
CDONE is an open drain output with 10k pullup. Driving LED requires a current amplifier.

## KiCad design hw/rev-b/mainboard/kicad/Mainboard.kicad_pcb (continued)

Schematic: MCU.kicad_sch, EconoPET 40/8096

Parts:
C3, C6, C90, C93, C94, C95, C96, C97, C98: 100n; C_0402_1005Metric; LCSC Part # C307331
C86, C87: 33p; C_0402_1005Metric; LCSC Part # C1562
C88, C91, C92: 2u2 6.3V; C_0402_1005Metric; LCSC Part # C12530
D11: LED_GRN; LED_0603_1608Metric; LCSC Part # C2986059
J23: MENU; PinHeader_1x02_P2.54mm_Vertical; MOUSER 649-1012937891002BLF
JP7: DVI_CEC; SolderJumper-2_P1.3mm_Open_RoundedPad1.0x1.5mm
R39: 10k; R_0402_1005Metric; LCSC Part # C25744
R40: 4k7; R_0402_1005Metric; LCSC Part # C25900
R41, R42, R43: 1k; R_0402_1005Metric; LCSC Part # C11702
R44, R45, R48, R49: 2k2; R_0402_1005Metric; LCSC Part # C25879
R46, R47: 27; R_0603_1608Metric; LCSC Part # C25190
SW4: TS-1088-AR02016; SW-SMD_L3.9-W3.0-P4.45; LCSC Part # C720477
SW5: MENU_BTN; APEM_MJTP1117; MOUSER 642-MJTP1117
U21: RP2040; LQFN-56_L7.0-W7.0-P0.4-EP; LCSC Part # C2040
Y1: 12 MHz; Crystal_SMD_3225-4Pin_3.2x2.5mm; LCSC Part # C9002

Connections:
+3V3: C92.1, C93.1, C94.1, C95.1, C96.1, C97.1, C98.1, R40.1, R44.1, R45.1, R48.1, R49.1, U21.1 (IOVDD), U21.10 (IOVDD), U21.22 (IOVDD), U21.33 (IOVDD), U21.42 (IOVDD), U21.43 (ADC_AVDD), U21.44 (VREG_IN), U21.48 (USB_VDD), U21.49 (IOVDD); also elsewhere on the board
/MAGIC/FPGA/CEC: JP7.1 (A), U21.36 (GPIO24); also elsewhere on the board
/MAGIC/FPGA/FPGA_CLK: U21.18 (GPIO15); also elsewhere on the board
/MAGIC/FPGA/I2C0_SCL: R49.2, U21.41 (GPIO29_ADC3); also elsewhere on the board
/MAGIC/FPGA/I2C0_SDA: R48.2, U21.40 (GPIO28_ADC2); also elsewhere on the board
/MAGIC/FPGA/I2C1_SCL: R45.2, U21.5 (GPIO3); also elsewhere on the board
/MAGIC/FPGA/I2C1_SDA: R44.2, U21.4 (GPIO2); also elsewhere on the board
/MAGIC/FPGA/SPI0_RX: U21.6 (GPIO4); also elsewhere on the board
/MAGIC/FPGA/SPI0_SCK: U21.8 (GPIO6); also elsewhere on the board
/MAGIC/FPGA/SPI0_TX: U21.9 (GPIO7); also elsewhere on the board
/MAGIC/FPGA/SPI0_~CS: U21.7 (GPIO5); also elsewhere on the board
/MAGIC/FPGA/SPI1_RX: U21.15 (GPIO12); also elsewhere on the board
/MAGIC/FPGA/SPI1_SCK: U21.17 (GPIO14); also elsewhere on the board
/MAGIC/FPGA/SPI1_TX: U21.14 (GPIO11); also elsewhere on the board
/MAGIC/FPGA/SPI1_~CS: U21.16 (GPIO13); also elsewhere on the board
/MAGIC/FPGA/SPI1_~READY: U21.13 (GPIO10); also elsewhere on the board
/MAGIC/FPGA/SWCLK: U21.24 (SWCLK); also elsewhere on the board
/MAGIC/FPGA/SWD: U21.25 (SWD); also elsewhere on the board
/MAGIC/FPGA/UART_RX: U21.3 (GPIO1); also elsewhere on the board
/MAGIC/FPGA/UART_TX: U21.2 (GPIO0); also elsewhere on the board
/MAGIC/FPGA/~CRESET: R39.2; also elsewhere on the board
/MAGIC/FPGA/~SPI_ENA: C6.1, R40.2, R41.2, U21.26 (RUN); also elsewhere on the board
/MAGIC/MCU/DVDD: C3.1, C90.1, C91.1, U21.23 (DVDD), U21.45 (VREG_VOUT), U21.50 (DVDD)
/MAGIC/MCU/DVI/CEC: JP7.2 (B); also elsewhere on the board
/MAGIC/MCU/DVI/DVI_CK+: U21.28 (GPIO17); also elsewhere on the board
/MAGIC/MCU/DVI/DVI_CK-: U21.27 (GPIO16); also elsewhere on the board
/MAGIC/MCU/DVI/DVI_D0+: U21.30 (GPIO19); also elsewhere on the board
/MAGIC/MCU/DVI/DVI_D0-: U21.29 (GPIO18); also elsewhere on the board
/MAGIC/MCU/DVI/DVI_D1+: U21.32 (GPIO21); also elsewhere on the board
/MAGIC/MCU/DVI/DVI_D1-: U21.31 (GPIO20); also elsewhere on the board
/MAGIC/MCU/DVI/DVI_D2+: U21.35 (GPIO23); also elsewhere on the board
/MAGIC/MCU/DVI/DVI_D2-: U21.34 (GPIO22); also elsewhere on the board
/MAGIC/MCU/Flash/SCK: U21.52 (QSPI_SCLK); also elsewhere on the board
/MAGIC/MCU/Flash/SD0: U21.53 (QSPI_SD0); also elsewhere on the board
/MAGIC/MCU/Flash/SD1: U21.55 (QSPI_SD1); also elsewhere on the board
/MAGIC/MCU/Flash/SD2: U21.54 (QSPI_SD2); also elsewhere on the board
/MAGIC/MCU/Flash/SD3: U21.51 (QSPI_SD3); also elsewhere on the board
/MAGIC/MCU/Flash/~CS: U21.56 (QSPI_SS); also elsewhere on the board
/MAGIC/MCU/GP25: R43.1, U21.37 (GPIO25)
/MAGIC/MCU/GP27: C88.1, J23.2, SW5.2, U21.39 (GPIO27_ADC1)
/MAGIC/MCU/MCU_USB_D+: R46.1, U21.47 (USB_DP)
/MAGIC/MCU/MCU_USB_D-: R47.1, U21.46 (USB_DM)
/MAGIC/MCU/MCU_~CRESET: R39.1, U21.38 (GPIO26_ADC0)
/MAGIC/MCU/SD_DETECT: U21.11 (GPIO8); also elsewhere on the board
/MAGIC/MCU/SD_~CS: U21.12 (GPIO9); also elsewhere on the board
/MAGIC/MCU/USB/USB_D+: R46.2; also elsewhere on the board
/MAGIC/MCU/USB/USB_D-: R47.2; also elsewhere on the board
/MAGIC/MCU/XIN: C86.2, U21.20 (XIN), Y1.1
/MAGIC/MCU/XOUT: R42.2, U21.21 (XOUT)
GND: C3.2, C6.2, C86.1, C87.1, C88.2, C90.2, C91.2, C92.2, C93.2, C94.2, C95.2, C96.2, C97.2, C98.2, D11.1 (K), J23.1, SW4.1, SW5.1, U21.19 (TESTEN), U21.57 (GND), Y1.2, Y1.4; also elsewhere on the board
unnamed: C87.2, R42.1, Y1.3
unnamed: D11.2 (A), R43.2
unnamed: R41.1, SW4.2

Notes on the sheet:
100n at RUN pin for EMI immunity. Avoids reset during CRT sync lock.
IO/USB/AVDD Decoupling
The MCU configures the FPGA using SPI0. Once the FPGA is configured, the MCU can communicate asynchronously with the system bus over SPI0 using the FPGA as a bridge. The MCU uses SPI0 to initialize SRAM with the PET ROM contents at POR. Afterwards, Core0 of the MCU uses SPI0 to read back video RAM 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
Menu/Reset Button
Oscillator Specs: C_{L}=20pF C_{0}=7pF DL=1-200μW (100uW typical) ESR=80Ω Load capacitor calculation: C = 2*C_{L} - 2*C_{stray} C_{L} = 20pf, C_{stray} = 2-5pF C = 30-36pF AMS1117-3.3 may require increasing PICO_XOSC_STARTUP_DELAY_MULTIPLIER to allow more time for 3V3 to stabilize. The TLV1117LV ap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
The T8/20Q144 requires SPI0_~{CS} to be pulsed low, even when using JTAG. To prevent contention on SPI0_~{CS}, we use ~{SPI_ENA} to reset the RP2040, which then detects that ~{CRESET} is being actively driven hi and skips JTAG configuration. POR Idle Programming ~SPI0_~{CS} float hi Pulse lo -> hi 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
MCU
MCU Status LED
On short press, MCU triggers a CPU reset. On long press, MCU enters menu.
DVDD Decoupling
10k resistor allows FPGA programmer to override ~{CRESET} during JTAG configuration.

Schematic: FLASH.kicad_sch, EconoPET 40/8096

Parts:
C1: 100n; C_0402_1005Metric; LCSC Part # C307331
R65: 1k; R_0402_1005Metric; LCSC Part # C11702
R66: 10k; R_0402_1005Metric; LCSC Part # C25744
SW6: TS-1088-AR02016; SW-SMD_L3.9-W3.0-P4.45; LCSC Part # C720477
U22: W25Q128JVS; SOIC-8_5.23x5.23mm_P1.27mm; LCSC Part # C97521

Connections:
+3V3: C1.1, R66.1, U22.8 (VCC); also elsewhere on the board
/MAGIC/MCU/Flash/SCK: U22.6 (CLK); also elsewhere on the board
/MAGIC/MCU/Flash/SD0: U22.5 (DI(IO0)); also elsewhere on the board
/MAGIC/MCU/Flash/SD1: U22.2 (DO(IO1)); also elsewhere on the board
/MAGIC/MCU/Flash/SD2: U22.3 (IO2); also elsewhere on the board
/MAGIC/MCU/Flash/SD3: U22.7 (IO3); also elsewhere on the board
/MAGIC/MCU/Flash/~CS: R65.2, R66.2, U22.1 (~CS); also elsewhere on the board
GND: C1.2, SW6.1, U22.4 (GND); also elsewhere on the board
unnamed: R65.1, SW6.2

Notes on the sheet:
16MiB Quad SPI flash memory for MCU. Holding BOOTSEL at power on puts the MCU into programming mode, allowing new firmware to be uploaded via USB for initial programming and recovery. (Typically, firmware updates happen via microSD instead.)
Flash

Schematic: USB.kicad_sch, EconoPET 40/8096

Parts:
C102: 47u 10V; C_1206_3216Metric; LCSC Part # C96123
C103: 1u; C_0402_1005Metric; LCSC Part # C52923
D12: SS54; D_SMA; LCSC Part # C22452
J26: USB1.1_HOST_TYPE_C; USB-C_SMD-TYPE-C-31-M-12; LCSC Part # C165948
R63, R64: 56k; R_0402_1005Metric; LCSC Part # C25796

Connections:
+5V: D12.2 (A); also elsewhere on the board
/MAGIC/MCU/USB/CC1: J26.A5 (CC1), R63.2
/MAGIC/MCU/USB/CC2: J26.B5 (CC2), R64.2
/MAGIC/MCU/USB/USB_D+: J26.A6 (D+), J26.B6 (D+); also elsewhere on the board
/MAGIC/MCU/USB/USB_D-: J26.A7 (D-), J26.B7 (D-); also elsewhere on the board
/MAGIC/MCU/USB/VBUS: C102.1, C103.1, D12.1 (K), J26.A4_B9 (VBUS), J26.A9_B4 (VBUS), R63.1, R64.1
GND: C102.2, C103.2, J26.A1_B12 (GND), J26.A12_B1 (GND), J26.S1 (SHIELD); also elsewhere on the board

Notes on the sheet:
USB
USB 1.1 Host over USB-C connector The 56k pullups on CC1 and CC2 identify the port as downstream facing, supplying 5V/900ma. The diode prevents connected devices from inadvertently backpowering the EconoPET. V_{F} < 0.5V should be within USB spec of 5V +/-10% (4.5V - 5.5V). The 47u capacitor helps 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

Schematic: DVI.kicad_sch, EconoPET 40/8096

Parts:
C99: 4u7 10V; C_0402_1005Metric; LCSC Part # C23733
J24: NOT_HDMI_A; HDMI_A_Molex_208658-1001_Horizontal; LCSC Part # C138388
R50, R51, R52: 2k2; R_0402_1005Metric; LCSC Part # C25879
R53, R54, R55, R56, R57, R58, R59, R60, R61: 270; R_0603_1608Metric; LCSC Part # C22966

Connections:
+3V3: R50.1; also elsewhere on the board
+5V: C99.1, J24.18 (+5V), R51.1, R52.1; also elsewhere on the board
/MAGIC/MCU/DVI/CEC: R50.2, R61.1; also elsewhere on the board
/MAGIC/MCU/DVI/DVI_CK+: R59.1; also elsewhere on the board
/MAGIC/MCU/DVI/DVI_CK-: R60.1; also elsewhere on the board
/MAGIC/MCU/DVI/DVI_D0+: R57.1; also elsewhere on the board
/MAGIC/MCU/DVI/DVI_D0-: R58.1; also elsewhere on the board
/MAGIC/MCU/DVI/DVI_D1+: R55.1; also elsewhere on the board
/MAGIC/MCU/DVI/DVI_D1-: R56.1; also elsewhere on the board
/MAGIC/MCU/DVI/DVI_D2+: R53.1; also elsewhere on the board
/MAGIC/MCU/DVI/DVI_D2-: R54.1; also elsewhere on the board
/MAGIC/MCU/DVI/HDMI_CEC: J24.13 (CEC), R61.2
/MAGIC/MCU/DVI/HDMI_CK+: J24.10 (CK+), R59.2
/MAGIC/MCU/DVI/HDMI_CK-: J24.12 (CK-), R60.2
/MAGIC/MCU/DVI/HDMI_D0+: J24.7 (D0+), R57.2
/MAGIC/MCU/DVI/HDMI_D0-: J24.9 (D0-), R58.2
/MAGIC/MCU/DVI/HDMI_D1+: J24.4 (D1+), R55.2
/MAGIC/MCU/DVI/HDMI_D1-: J24.6 (D1-), R56.2
/MAGIC/MCU/DVI/HDMI_D2+: J24.1 (D2+), R53.2
/MAGIC/MCU/DVI/HDMI_D2-: J24.3 (D2-), R54.2
GND: C99.2, J24.2 (D2S), J24.5 (D1S), J24.8 (D0S), J24.11 (CKS), J24.17 (GND), J24.SH; also elsewhere on the board
unnamed: J24.15 (SCL), R51.2
unnamed: J24.16 (SDA), R52.2

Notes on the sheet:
NOT
DVI TMDS protocol over an HDMI-compatible connector (not HDMI certified). See: https://github.com/Wren6991/PicoDVI
DVI VIDEO

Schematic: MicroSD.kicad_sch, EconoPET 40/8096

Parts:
C2: 100n; C_0402_1005Metric; LCSC Part # C307331
C101: 47u 10V; C_1206_3216Metric; LCSC Part # C96123
J25: MICRO_SD; TF-SMD_TF-PUSH; LCSC Part # C393941
R62: 10k; R_0402_1005Metric; LCSC Part # C25744
RN16: 10kx4; R_Array_Convex_4x0603; LCSC Part # C29718

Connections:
+3V3: C2.1, C101.1, J25.4 (VDD), R62.1, RN16.5 (R4.2), RN16.6 (R3.2), RN16.7 (R2.2), RN16.8 (R1.2); also elsewhere on the board
/MAGIC/FPGA/SPI1_RX: J25.7 (DAT0), RN16.3 (R3.1); also elsewhere on the board
/MAGIC/FPGA/SPI1_SCK: J25.5 (CLK); also elsewhere on the board
/MAGIC/FPGA/SPI1_TX: J25.3 (CMD), RN16.2 (R2.1); also elsewhere on the board
/MAGIC/MCU/SD_DETECT: J25.9 (DET); also elsewhere on the board
/MAGIC/MCU/SD_~CS: J25.2 (DAT3/CD), RN16.1 (R1.1); also elsewhere on the board
GND: C2.2, C101.2, J25.6 (VSS), J25.10 (SHIELD); also elsewhere on the board
unnamed: J25.8 (DAT1), RN16.4 (R4.1)
unnamed: J25.1 (DAT2), R62.2

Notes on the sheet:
47uF decoupling capacitor helps inrush current (although hot insertion is not recommended).
DAT[0] : (POCI) is open-drain output that requires pullup. DAT[2:1] : Unused inputs in SPI mode. Pullups recommended to avoid current draw due to metastablitiy. DAT[3] : (~{CS}) has built-in 22-50k pullup to ensure card is deselected by default. CMD : (PICO) input in SPI mode. CLK : (SCK) always an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
MicroSD

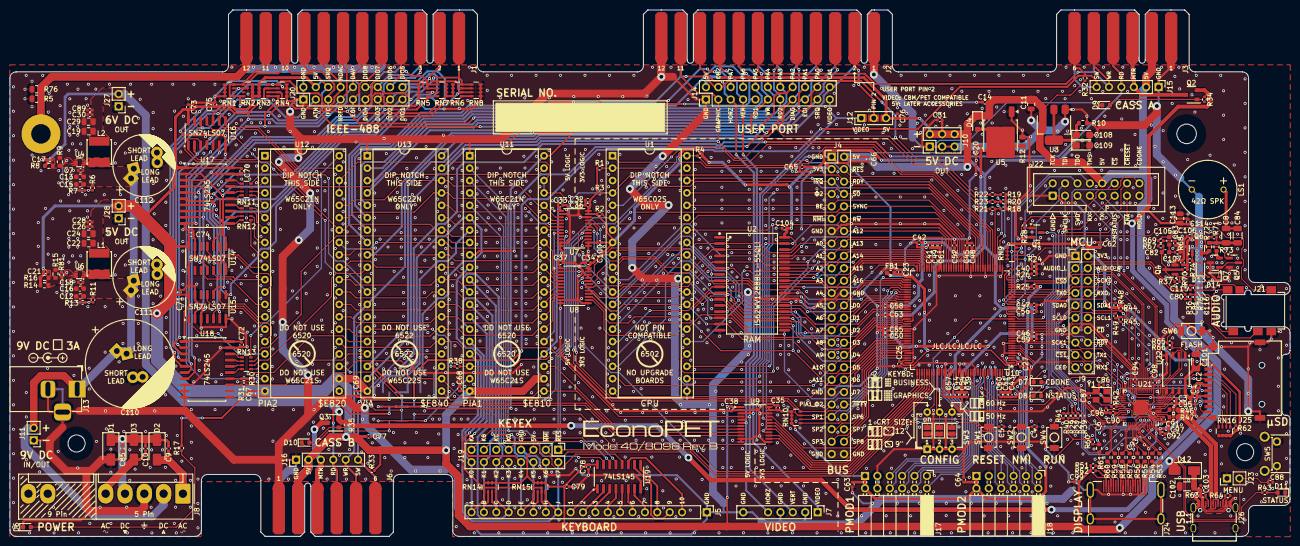
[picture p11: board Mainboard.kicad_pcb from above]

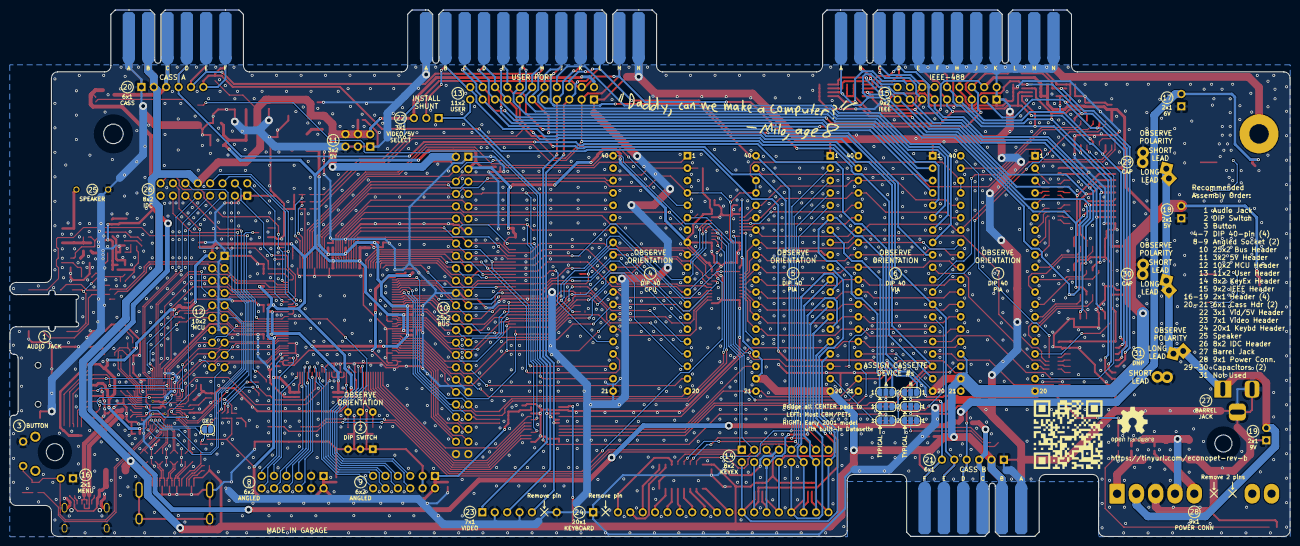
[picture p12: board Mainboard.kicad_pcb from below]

Board: 2 copper layers, 262.5 x 107.9 mm, 305 parts (10 on the bottom side), 326 nets.

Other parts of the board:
H2: MountingHole_Screw; MountingHole_4mm
H3, H4: MountingHole_Pillar; MountingHole_3.5mm
SYM1: SYM_Arrow_Small; Symbol_Barrel_Polarity
SYM2: SYM_Arrow_Small; EconoPET_Milo
SYM3: SYM_Arrow_Small; EconoPET_Model
SYM4: SYM_Arrow_Small; OSHW-Logo2_9.8x8mm_SilkScreen
SYM5: SYM_Arrow_Small; EconoPET_QR_Rev_B

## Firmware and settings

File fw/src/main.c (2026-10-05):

// SPDX-License-Identifier: CC0-1.0
// https://github.com/dlehenbauer/econopet

#include "pch.h"

#include "breakpoint.h"
#include "diag/log/log.h"
#include "diag/mem.h"
#include "display/display.h"
#include "display/dvi/dvi.h"
#include "driver.h"
#include "fatal.h"
#include "global.h"
#include "hw.h"
#include "ieee/ieee_drive.h"
#include "input.h"
#include "menu/menu.h"
#include "pet.h"
#include "sd/sd.h"
#include "system_state.h"
#include "ui/cli.h"
#include "usb/usb.h"

void measure_freqs(uint fpga_div) {
    uint32_t f_pll_sys = frequency_count_khz(CLOCKS_FC0_SRC_VALUE_PLL_SYS_CLKSRC_PRIMARY);
    uint32_t f_pll_usb = frequency_count_khz(CLOCKS_FC0_SRC_VALUE_PLL_USB_CLKSRC_PRIMARY);
    uint32_t f_rosc = frequency_count_khz(CLOCKS_FC0_SRC_VALUE_ROSC_CLKSRC);
    uint32_t f_clk_sys = frequency_count_khz(CLOCKS_FC0_SRC_VALUE_CLK_SYS);
    uint32_t f_clk_peri = frequency_count_khz(CLOCKS_FC0_SRC_VALUE_CLK_PERI);
    uint32_t f_clk_usb = frequency_count_khz(CLOCKS_FC0_SRC_VALUE_CLK_USB);
    uint32_t f_clk_adc = frequency_count_khz(CLOCKS_FC0_SRC_VALUE_CLK_ADC);
    uint32_t f_clk_rtc = frequency_count_khz(CLOCKS_FC0_SRC_VALUE_CLK_RTC);

    log_debug("clk: pll_sys=%lu pll_usb=%lu rosc=%lu kHz", f_pll_sys, f_pll_usb, f_rosc);
    log_debug("clk: sys=%lu peri=%lu usb=%lu kHz", f_clk_sys, f_clk_peri, f_clk_usb);
    log_debug("clk: adc=%lu rtc=%lu fpga=%lu kHz", f_clk_adc, f_clk_rtc, f_clk_sys / fpga_div);
}

void fpga_write_zeros(size_t count) {
    assert(count <= TEMP_BUFFER_SIZE);
    
    uint8_t* temp_buffer = acquire_temp_buffer();
    memset(temp_buffer, 0, count);
    spi_write_blocking(FPGA_SPI_INSTANCE, temp_buffer, count);
    release_temp_buffer(&temp_buffer);
}

void fpga_read_bitstream_callback(size_t offset, uint8_t* buffer, size_t bytes_read, void* context) {
    (void)offset;
    (void)context;

    spi_write_blocking(FPGA_SPI_INSTANCE, buffer, bytes_read);
}

// An MCU reset stops the PWM clock source while the JTAG-configured FPGA
// remains programmed. Allow 10 ms for its PLL to relock before SPI access
// (measured lock time is approximately 3 ms).
#define FPGA_PLL_LOCK_WAIT_MS 10

void fpga_init() {
    gpio_init(FPGA_CRESET_GP);

    // Setup 270 MHz system clock
	vreg_set_voltage(VREG_VOLTAGE_1_20);
	sleep_ms(10);
 	set_sys_clock_khz(270000, true);

    // Use PWM to generate 18 MHz clock for FPGA PLL input:
    //     270 MHz / 15 = 18 MHz
    const uint16_t fpga_div = 15;

    const uint slice = pwm_gpio_to_slice_num(FPGA_CLK_GP);
    const uint channel = pwm_gpio_to_channel(FPGA_CLK_GP);
    pwm_config config = pwm_get_default_config();
    pwm_config_set_wrap(&config, fpga_div - 1);
    pwm_init(slice, &config, /* start: */ true);
    pwm_set_chan_level(slice, channel, 2);
    gpio_set_drive_strength(FPGA_CLK_GP, GPIO_DRIVE_STRENGTH_2MA);
    gpio_set_function(FPGA_CLK_GP, GPIO_FUNC_PWM);

    // Setting 'sys_clk' causes 'peri_clk' to revert to 48 MHz.  (Re)initialize UART.
    //
    // See: https://github.com/Bodmer/TFT_eSPI/discussions/2432
    // See: https://github.com/raspberrypi/pico-examples/blob/master/clocks/hello_48MHz/hello_48MHz.c
    stdio_init_all();
    printf("\e[2J");

    log_debug("FLASH_SIZE=0x%08x XOSC_DELAY=%d", PICO_FLASH_SIZE_BYTES, PICO_XOSC_STARTUP_DELAY_MULTIPLIER);
    measure_freqs(fpga_div);

    // Initialize FPGA_SPI at 24 MHz (default format is SPI mode 0).
    const int baudrate = spi_init(FPGA_SPI_INSTANCE, FPGA_SPI_MHZ * MHZ);
    gpio_set_function(FPGA_SPI_SCK_GP, GPIO_FUNC_SPI);
    gpio_set_function(FPGA_SPI_SDO_GP, GPIO_FUNC_SPI);
    gpio_set_function(FPGA_SPI_SDI_GP, GPIO_FUNC_SPI);
    log_debug("fpga_spi=%u Bd", baudrate);

    // Configure and deassert CS_N.  We configure CS_N as GPIO_OUT rather than GPIO_FUNC_SPI
    // so we can control via software.
    gpio_init(FPGA_SPI_CSN_GP);
    gpio_set_dir(FPGA_SPI_CSN_GP, GPIO_OUT);
    gpio_put(FPGA_SPI_CSN_GP, 1);

    // Configure STALL.  STALL is asserted by the FPGA while it is busy processing the last SPI command.
    gpio_init(SPI_STALL_GP);
    gpio_set_dir(SPI_STALL_GP, GPIO_IN);

    // When no programmer is attached, the onboard 100k pull-down will hold the
    // FPGA in reset. If CRESET_N is high, we know a JTAG programmer is attached
    // and skip FPGA configuration.
    if (gpio_get(FPGA_CRESET_GP)) {
        log_warn("FPGA config skipped: Programmer attached");

        // The FPGA remains programmed after an MCU-only reset, but its PWM
        // reference clock has restarted. Wait for its PLL to relock before
        // attempting communication.
        sleep_ms(FPGA_PLL_LOCK_WAIT_MS);

        // Because we skipped FPGA configuration, the FPGA state is unknown.
        // Manually synchronize the FPGA's state to match the expected initial
        // state. (Initial CPU state per `register_file.sv`)
        set_cpu(CPU_RESET);
    } else {
        // Create a clean CRESET_N pulse to initiate FPGA configuration.
        gpio_set_dir(FPGA_CRESET_GP, GPIO_OUT);
        gpio_put(FPGA_CRESET_GP, 1);
        sleep_ms(1);  // t_CRESET_N = 320 ns
        gpio_put(FPGA_CRESET_GP, 0);
        sleep_ms(1);  // t_CRESET_N = 320 ns

        // Efinix requires SPI mode 3 for configuration.
        spi_set_format(FPGA_SPI_INSTANCE, 8, SPI_CPOL_1, SPI_CPHA_1, SPI_MSB_FIRST);

        // Changes in clock polarity do not seem to take effect until the next
        // write.  Send a single byte while CS_N is deasserted to transition SCK
        // to high.
        fpga_write_zeros(/* count: */ 1);
        sleep_ms(1);  // t_CRESET_N = 320 ns

        // The Efinix FPGA samples CS_N on the positive edge of CRESET_N to
        // select passive vs. active SPI configuration.  (0 = Passive, 1 =
        // Active)
        gpio_put(FPGA_SPI_CSN_GP, 0);

        sleep_ms(1);  // t_CRESET_N = 320 ns
        gpio_put(FPGA_CRESET_GP, 1);
        sleep_ms(1);  // t_CRESET_N = 320 ns

        // Send bitstream to FPGA. To generate a '*.hex.bin' file, you must
        // enable 'Generate SPI Raw Binary Configuration File' under ~File ~Edit
        // Project ~Bitstream Generation.
        char bitstream_path[SD_PATH_MAX];
        sd_make_path(bitstream_path, SD_DIR_FPGA, "EconoPET.hex.bin");
        sd_read_file(bitstream_path, fpga_read_bitstream_callback, NULL, SIZE_MAX);

        // To ensure successful configuration, the microprocessor must continue
        // to supply the configuration clock to the Trion FPGA for at least 100
        // cycles after sending the last configuration data.
        //
        // Efinix example clocks out 1000 zero bits to generate extra clock
        // cycles.
        fpga_write_zeros(/* count: */ 125);

        // Deassert CS_N to signal end of configuration.
        sleep_ms(1);  // t_CRESET_N = 320 ns
        gpio_put(FPGA_SPI_CSN_GP, 1);

        // Restore SPI mode 0
        spi_set_format(FPGA_SPI_INSTANCE, 8, SPI_CPOL_0, SPI_CPHA_0, SPI_MSB_FIRST);

        // Changes in clock polarity do not seem to take effect until the next
        // write.  Send a single byte while CS_N is deasserted to transition SCK
        // to low.
        fpga_write_zeros(/* count: */ 1);

        log_info("FPGA configured");
    }

    // At this point, we expect the FPGA to have entered user mode and the SPI
    // interface to be ready for commands.  We verify this by reading back the
    // initial CPU state defined in `register_file.sv`.
    cpu_state_t cpu_state = get_cpu();
    vet(cpu_state == CPU_RESET,
        "fpga_init: initial CPU state must be CPU_RESET, got %u", (unsigned int) cpu_state);

    // Perform a basic self-test by toggling the CPU_READY state while holding
    // the CPU in the RESET state.  Note that the CPU remains halted when
    // CPU_RESET is asserted.
    set_cpu(CPU_RESET | CPU_READY);
    cpu_state = get_cpu();
    vet(cpu_state == (CPU_READY | CPU_RESET),
        "fpga_init: failed to set CPU_READY, got %u", (unsigned int) cpu_state);

    // Finally, restore the original CPU state.
    set_cpu(CPU_RESET);
}

int main() {
    // Note: A prolonged period without a valid sync signal may cause the PET monitor to
    // display a "bright spot" which can damage the CRT phosphor. Therefore, we initialize
    // the FPGA as soon as possible to start generating a native video for the PET.
    //
    // We limit the work done before fpga_init() to tasks that are either very fast or
    // prerequisites for FPGA configuration.

    // Turn on LED to signal that the RP2040 has booted.  'sd_init()' will turn LED off.
    // If the LED is "stuck on" at boot, this typically means the sd card is missing.
    gpio_init(PICO_DEFAULT_LED_PIN);
    gpio_set_dir(PICO_DEFAULT_LED_PIN, GPIO_OUT);
    gpio_put(PICO_DEFAULT_LED_PIN, 1);

    log_init();     // Initialize logging subsystem early for boot diagnostics
    input_init();   // Begin charging debounce capacitor for menu button (if any)
    sd_init();      // SD card is required to read the FPGA's bitstream file
    fpga_init();    // Setup sys_clock, FPGA_SPI, and configure FPGA

    // We now are generating a valid video signal for the PET, so it's safe to proceed
    // with the rest of the initialization.

    display_init();     // Initialize firmware display subsystem
    usb_init();         // Initialize USB subsystem
    cli_init();         // Start CLI on UART serial
    bp_init();          // Initialize breakpoint subsystem
    ieee_drive_init();  // Mount /disks images, enable IEEE-488 drive emulation

    // Probe before any config is loaded -- it clobbers $0400-$0402 and $FFFC.
    physical_cpu_present();
    
    // Enter boot menu
    menu_enter(/* is_boot: */ true);

    // PET is configured and running.  Enter main loop to synchronize displays, service
    // input queues, and check for menu/reset button.
    while (true) {
        ieee_drive_task();  // Service IEEE-488 FIFOs; an underrun desyncs the loader
        display_task();     // Sync video buffer, render to terminal if needed
        ieee_drive_task();  // Again after the loop's longest task: the FIFO must not sit empty across a display render
        input_task();       // Poll inputs, dispatch based on mode
        bp_task();          // Check for breakpoint hits and handle them
        menu_task();        // Check for button events to enter menu
    }

    __builtin_unreachable();
}

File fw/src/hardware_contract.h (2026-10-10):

// SPDX-License-Identifier: CC0-1.0
// https://github.com/dlehenbauer/econopet

#pragma once

// EconoPET hardware contract. Names match common_pkg.sv after removing the
// ECONOPET_ prefix. *_BIT is an index, *_MASK a mask, and *_ADDR a byte
// address.
//
// IMPORTANT: Keep contract definitions in sync with common_pkg.sv. The
//            generated 'system.HardwareContract.MatchesCommonPackage'
//            suite checks every exported constant against the RTL.
//
//            Use unsigned decimal or hexadecimal literals with a u suffix here.
//            Literals keep C macro expansion simple and hardware values easy
//            to inspect. Keep derivations in common_pkg.sv, where the consistency
//            test checks these compiled values against elaborated RTL without
//            duplicating construction logic.

// Data and address widths (See common_pkg.sv for more details)
#define ECONOPET_DATA_WIDTH 8u
#define ECONOPET_CPU_ADDR_WIDTH 16u
#define ECONOPET_RAM_ADDR_WIDTH 17u
#define ECONOPET_BRAM_ADDR_WIDTH 12u
#define ECONOPET_WB_ADDR_WIDTH 20u

// Wishbone window addresses (See common_pkg.sv for more details)
#define ECONOPET_WB_RAM_BASE_ADDR 0x00000u
#define ECONOPET_WB_CRTC_BASE_ADDR 0x50000u
#define ECONOPET_WB_KBD_BASE_ADDR 0x60000u
#define ECONOPET_WB_BRAM_BASE_ADDR 0x68000u
#define ECONOPET_WB_IEEE_BASE_ADDR 0x70000u

// Register-file Wishbone byte addresses (See common_pkg.sv for more details)
#define ECONOPET_WB_STATUS_ADDR 0x40000u
#define ECONOPET_WB_CPU_ADDR 0x40001u
#define ECONOPET_WB_VIDEO_ADDR 0x40002u
#define ECONOPET_WB_BP_CTL_ADDR 0x40003u
#define ECONOPET_WB_BP_LO_ADDR 0x40003u
#define ECONOPET_WB_BP_HI_ADDR 0x40004u
#define ECONOPET_WB_CPU_SEL_ADDR 0x40005u

// Status register masks (See common_pkg.sv for more details)
#define ECONOPET_REG_STATUS_TEXT_MODE_MASK 0x01u
#define ECONOPET_REG_STATUS_CRT_MASK 0x02u
#define ECONOPET_REG_STATUS_KEYBOARD_MASK 0x04u
#define ECONOPET_REG_STATUS_BP_HALT_MASK 0x08u
#define ECONOPET_REG_STATUS_PHYS_CPU_MASK 0x10u

// CPU control masks (See common_pkg.sv for more details)
#define ECONOPET_REG_CPU_READY_MASK 0x01u
#define ECONOPET_REG_CPU_RESET_MASK 0x02u
#define ECONOPET_REG_CPU_NMI_MASK 0x04u
#define ECONOPET_REG_CPU_MASK 0x07u

// CPU selection and SuperPET I/O enable (See common_pkg.sv for more details)
#define ECONOPET_CPU_SEL_PHYS_6502 0u
#define ECONOPET_CPU_SEL_SOFT_6809 1u
#define ECONOPET_CPU_SEL_SOFT_6502 2u
#define ECONOPET_CPU_SEL_SUPERPET_IO_MASK 0x04u

// Video column mode and RAM size field (See common_pkg.sv for more details)
#define ECONOPET_REG_VIDEO_RAM_MASK_LO_BIT 1u
#define ECONOPET_REG_VIDEO_RAM_MASK 0x06u
#define ECONOPET_REG_VIDEO_COL_80_MASK 0x01u

// Breakpoint halt-clear control (See common_pkg.sv for more details)
#define ECONOPET_REG_BP_CTL_CLEAR_MASK 0x01u

// Configuration pin levels (See common_pkg.sv for more details)
#define ECONOPET_CONFIG_CRT_CRTC 0u
#define ECONOPET_CONFIG_CRT_FIXED 1u
#define ECONOPET_CONFIG_KEYBOARD_BUSINESS 0u
#define ECONOPET_CONFIG_KEYBOARD_GRAPHICS 1u

// SPI command masks and opcode encodings (See common_pkg.sv for more details)
#define ECONOPET_SPI_CMD_OPCODE_MASK 0xe0u
#define ECONOPET_SPI_CMD_RESERVED_MASK 0x10u
#define ECONOPET_SPI_CMD_ADDRESS_HIGH_MASK 0x0fu
#define ECONOPET_SPI_CMD_READ_AT 0x40u
#define ECONOPET_SPI_CMD_READ_NEXT 0x20u
#define ECONOPET_SPI_CMD_READ_PREV 0x60u
#define ECONOPET_SPI_CMD_READ_SAME 0x00u
#define ECONOPET_SPI_CMD_WRITE_AT 0xc0u
#define ECONOPET_SPI_CMD_WRITE_NEXT 0xa0u
#define ECONOPET_SPI_CMD_WRITE_PREV 0xe0u
#define ECONOPET_SPI_CMD_WRITE_SAME 0x80u

// IEEE register indices and count (See common_pkg.sv for more details)
#define ECONOPET_IEEE_REG_CTRL 0u
#define ECONOPET_IEEE_REG_TXS_LAST 7u
#define ECONOPET_IEEE_REG_COUNT 8u

// IEEE Wishbone byte addresses (See common_pkg.sv for more details)
#define ECONOPET_WB_IEEE_CTRL_ADDR 0x70000u
#define ECONOPET_WB_IEEE_STATUS_ADDR 0x70001u
#define ECONOPET_WB_IEEE_RX_ADDR 0x70002u
#define ECONOPET_WB_IEEE_TX_ADDR 0x70003u
#define ECONOPET_WB_IEEE_TX_LAST_ADDR 0x70004u
#define ECONOPET_WB_IEEE_SA_ADDR 0x70005u
#define ECONOPET_WB_IEEE_TXS_ADDR 0x70006u
#define ECONOPET_WB_IEEE_TXS_LAST_ADDR 0x70007u

// IEEE control-write masks (See common_pkg.sv for more details)
#define ECONOPET_IEEE_CTRL_ENABLE_MASK 0x01u
#define ECONOPET_IEEE_CTRL_FLUSH_MASK 0x02u
#define ECONOPET_IEEE_CTRL_DATA_FLUSH_MASK 0x04u

// IEEE control-read masks (See common_pkg.sv for more details)
#define ECONOPET_IEEE_CTRL_RD_ENABLE_MASK 0x01u
#define ECONOPET_IEEE_CTRL_RD_TX_ROOM_MASK 0x02u

// IEEE status masks (See common_pkg.sv for more details)
#define ECONOPET_IEEE_ST_RX_AVAIL_MASK 0x01u
#define ECONOPET_IEEE_ST_RX_ATN_MASK 0x02u
#define ECONOPET_IEEE_ST_TX_FULL_MASK 0x04u
#define ECONOPET_IEEE_ST_TX_EMPTY_MASK 0x08u
#define ECONOPET_IEEE_ST_ATN_MASK 0x10u
#define ECONOPET_IEEE_ST_LISTENING_MASK 0x20u
#define ECONOPET_IEEE_ST_TALKING_MASK 0x40u
#define ECONOPET_IEEE_ST_TALK_STARVED_MASK 0x80u
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

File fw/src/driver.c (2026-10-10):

// SPDX-License-Identifier: CC0-1.0
// https://github.com/dlehenbauer/econopet

#include "pch.h"
#include "driver.h"

#include "diag/log/log.h"

#include "display/dvi/dvi.h"
#include "fatal.h"
#include "global.h"
#include "hw.h"
#include "usb/keyboard.h"

/**
 * Begins an SPI command transaction with the FPGA.
 * 
 * This function:
 * 1. Waits for SPI_STALL_GP to be deasserted (low), indicating the FPGA is ready
 * 2. Asserts CS (chip select) low to begin the next command
 */
static void cmd_start() {
    // Typically, SPI_STALL_GP should already be low before starting a new command.
    while (gpio_get(SPI_STALL_GP));

    // The PrimeCell SSP deasserts CS after each byte is transmitted.  This conflicts with the
    // FPGA SPI state machine, which resets when CS is deasserted, canceling the previous command
    // and deasserting STALL in response (whether the previous command has completed or not).
    //
    // Consequently, we control the CS signal manually (but use the PrimeCell SSP for the
    // the other SPI signals.)
    gpio_put(FPGA_SPI_CSN_GP, 0);
}

/**
 * Ends an SPI command transaction with the FPGA.
 * 
 * This function:
 * 1. Waits for SPI_STALL_GP to be deasserted (low), ensuring the FPGA has completed processing
 * 2. Deasserts CS (chip select) high to end the transaction.
 */
static void cmd_end() {
    // Deasserting CS implicitly resets the FPGA SPI state machine, causing SPI_STALL_GP to be
    // deasserted early.  Therefore, we must wait until SPI_STALL_GP is low before deasserting CS.
    while (gpio_get(SPI_STALL_GP));

    gpio_put(FPGA_SPI_CSN_GP, 1);
}

/**
 * Queues a read operation at the specified address (pipelined read setup).
 * 
 * This function initiates a READ operation but does NOT return any data. The FPGA begins
 * an asynchronous read at the specified address. To retrieve the result, you must call
 * one of the spi_read_*() or spi_write_*() functions to retrieve the result (while
 * simultaneously queuing the next operation).
 * 
 * PIPELINE PROTOCOL:
 * The SPI protocol uses pipelined reads for efficiency:
 * 1. spi_read_seek(addr) - Queue read of address 'addr' (no data returned yet)
 * 2. spi_read_next()     - Returns data from 'addr', queues read of 'addr+1'
 * 3. spi_read_next()     - Returns data from 'addr+1', queues read of 'addr+2'
 * 
 * This pipelining allows efficient sequential access with only 8 bits TX/RX per byte.
 * 
 * @param addr 20-bit address to read from
 */
void spi_read_seek(uint32_t addr) {
    // Upper 4 bits of the address are encoded in the command byte
    const uint8_t cmd = ECONOPET_SPI_CMD_READ_AT | (addr >> 16);
    const uint8_t addr_hi = addr >> 8;
    const uint8_t addr_lo = addr;
    const uint8_t tx[] = { cmd, addr_hi, addr_lo };

    cmd_start();
    spi_write_blocking(FPGA_SPI_INSTANCE, tx, sizeof(tx));
    cmd_end();
}

/**
 * Reads a single byte from the specified address.
 * 
 * This is a convenience function that combines spi_read_seek() and spi_read_next().
 * Due to the pipelined protocol, this requires TWO SPI transactions:
 * 1. Queue the read at the specified address (3 bytes TX)
 * 2. Retrieve the result (1 byte TX/RX)
 * 
 * For sequential reads, use spi_read_seek() once followed by multiple spi_read_next()
 * calls for better efficiency.
 * 
 * @param addr 20-bit address to read from
 * @return The byte value at the specified address
 */
uint8_t spi_read_at(uint32_t addr) {
    spi_read_seek(addr);
    return spi_read_next();
}

/**
 * Retrieves the result of the previous read and queues a read of the next sequential address.
 * 
 * WHY THIS RETURNS THE PREVIOUS READ:
 * The SPI protocol uses pipelined reads where commands and results are temporally separated:
 * 
 * Timeline:
 * T1: Send READ_NEXT command → FPGA begins async read of current address
 * T2: [FPGA processing - SPI_STALL_GP asserted]
 * T3: Next READ_* command → FPGA returns result from T1, starts new read
 * 
 * The bidirectional nature of SPI means that when you send the READ_NEXT command byte,
 * you simultaneously RECEIVE the data byte from the FPGA. However, the FPGA can't return
 * data for the CURRENT command yet (it hasn't been processed), so it returns data from
 * the PREVIOUS command.
 * 
 * This pipelining enables optimal 1:1 efficiency (8 bits TX + 8 bits RX = 1 byte read).
 * 
 * USAGE PATTERN:
 *   spi_read_seek(0x1000);    // Queue read of 0x1000
 *   uint8_t b0 = spi_read_next(); // Returns data[0x1000], queues read of 0x1001
 *   uint8_t b1 = spi_read_next(); // Returns data[0x1001], queues read of 0x1002
 *   uint8_t b2 = spi_read_next(); // Returns data[0x1002], queues read of 0x1003
 * 
 * @return Data byte from the previously queued read operation
 */
uint8_t spi_read_next() {
    const uint8_t tx[1] = { ECONOPET_SPI_CMD_READ_NEXT };
    uint8_t rx[sizeof(tx)];

    cmd_start();
    spi_write_read_blocking(FPGA_SPI_INSTANCE, tx, rx, sizeof(tx));
    cmd_end();
    
    return rx[0];
}

/**
 * Retrieves the result of the previous read and queues a read of the previous sequential address.
 * 
 * Like spi_read_next(), this returns data from the PREVIOUS read operation due to the
 * pipelined protocol. The difference is that this decrements the address pointer instead
 * of incrementing it.
 * 
 * WHY THIS RETURNS THE PREVIOUS READ:
 * See detailed explanation in spi_read_next() documentation. The same pipelined protocol
 * applies - you cannot get results for a command that hasn't been processed yet.
 * 
 * USAGE PATTERN:
 *   spi_read_seek(0x1000);    // Queue read of 0x1000
 *   uint8_t b0 = spi_read_prev(); // Returns data[0x1000], queues read of 0x0FFF
 *   uint8_t b1 = spi_read_prev(); // Returns data[0x0FFF], queues read of 0x0FFE
 * 
 * This enables efficient backward sequential access with 1:1 efficiency (8 bits TX/RX per byte).
 * 
 * @return Data byte from the previously queued read operation
 */
uint8_t spi_read_prev() {
    const uint8_t tx[1] = { ECONOPET_SPI_CMD_READ_PREV };
    uint8_t rx[sizeof(tx)];

    cmd_start();
    spi_write_read_blocking(FPGA_SPI_INSTANCE, tx, rx, sizeof(tx));
    cmd_end();
    
    return rx[0];
}
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

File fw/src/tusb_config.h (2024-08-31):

/* 
 * The MIT License (MIT)
 *
 * Copyright (c) 2019 Ha Thach (tinyusb.org)
 *
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
 */

#ifndef _TUSB_CONFIG_H_
#define _TUSB_CONFIG_H_

#ifdef __cplusplus
 extern "C" {
#endif

//--------------------------------------------------------------------+
// Board Specific Configuration
//--------------------------------------------------------------------+

#if CFG_TUSB_MCU == OPT_MCU_RP2040
// change to 1 if using pico-pio-usb as host controller for raspberry rp2040
#define CFG_TUH_RPI_PIO_USB   0
#define BOARD_TUH_RHPORT      CFG_TUH_RPI_PIO_USB
#endif

// RHPort number used for host can be defined by board.mk, default to port 0
#ifndef BOARD_TUH_RHPORT
#define BOARD_TUH_RHPORT      0
#endif

// RHPort max operational speed can defined by board.mk
#ifndef BOARD_TUH_MAX_SPEED
#define BOARD_TUH_MAX_SPEED   OPT_MODE_DEFAULT_SPEED
#endif

//--------------------------------------------------------------------
// COMMON CONFIGURATION
//--------------------------------------------------------------------

// defined by compiler flags for flexibility
#ifndef CFG_TUSB_MCU
#error CFG_TUSB_MCU must be defined
#endif

#ifndef CFG_TUSB_OS
#define CFG_TUSB_OS           OPT_OS_NONE
#endif

#ifndef CFG_TUSB_DEBUG
#define CFG_TUSB_DEBUG        0
#endif

// Enable Host stack
#define CFG_TUH_ENABLED       1

// Default is max speed that hardware controller could support with on-chip PHY
#define CFG_TUH_MAX_SPEED     BOARD_TUH_MAX_SPEED

/* USB DMA on some MCUs can only access a specific SRAM region with restriction on alignment.
 * Tinyusb use follows macros to declare transferring memory so that they can be put
 * into those specific section.
 * e.g
 * - CFG_TUSB_MEM SECTION : __attribute__ (( section(".usb_ram") ))
 * - CFG_TUSB_MEM_ALIGN   : __attribute__ ((aligned(4)))
 */
#ifndef CFG_TUSB_MEM_SECTION
#define CFG_TUSB_MEM_SECTION
#endif

#ifndef CFG_TUSB_MEM_ALIGN
#define CFG_TUSB_MEM_ALIGN          __attribute__ ((aligned(4)))
#endif

//--------------------------------------------------------------------
// CONFIGURATION
//--------------------------------------------------------------------

// Size of buffer to hold descriptors and other data used for enumeration
#define CFG_TUH_ENUMERATION_BUFSIZE 256

#define CFG_TUH_HUB                 1 // number of supported hubs
#define CFG_TUH_CDC                 1
#define CFG_TUH_HID                 4 // typical keyboard + mouse device can have 3-4 HID interfaces
#define CFG_TUH_MSC                 1
#define CFG_TUH_VENDOR              0

// max device support (excluding hub device)
#define CFG_TUH_DEVICE_MAX          (CFG_TUH_HUB ? 4 : 1) // hub typically has 4 ports

//------------- HID -------------//
#define CFG_TUH_HID_EPIN_BUFSIZE    64
#define CFG_TUH_HID_EPOUT_BUFSIZE   64

//------------- CDC -------------//

// Set Line Control state on enumeration/mounted:
// DTR ( bit 0), RTS (bit 1)
#define CFG_TUH_CDC_LINE_CONTROL_ON_ENUM    0x03

// Set Line Coding on enumeration/mounted, value for cdc_line_coding_t
// bit rate = 115200, 1 stop bit, no parity, 8 bit data width
#define CFG_TUH_CDC_LINE_CODING_ON_ENUM   { 115200, CDC_LINE_CONDING_STOP_BITS_1, CDC_LINE_CODING_PARITY_NONE, 8 }


#ifdef __cplusplus
 }
#endif

#endif /* _TUSB_CONFIG_H_ */

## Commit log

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2023-11-15 hw: correct Mouser PN for headers
    [CASS.kicad_sch, MCU.kicad_sch, POWER.kicad_sch]
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2023-11-19 hw(rev-b): fix pmod, 10u -> 4.7u, swap config silk
    [FPGA.kicad_sch, Mainboard.kicad_sch, POWER.kicad_sch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]
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2023-11-28 gw: pwm for fgpa clk, cycle/stall working
    [hw.h, main.c]
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2024-07-13 fw: fix a few GCC warnings
    [driver.c]
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2024-07-24 fw: minor driver fixes
    [driver.c]
2024-07-24 fw: fix warnings in mem.c
    [mem.c]
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2024-08-29 hw: add oscillator specs to schematic
    [MCU.kicad_sch]
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2024-09-19 hw: fix pmod in rev-c
    [FPGA.kicad_sch]
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2024-09-20 hw(rev-c): use 100ohm/33pF for oscillator
    [MCU.kicad_sch]
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2024-09-27 hw: swap CEC and SPI1/RX breakout
    [FPGA.kicad_sch]
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2024-11-03 fw: swap kbd row/col (wip)
    [driver.c]
2024-11-09 hw: touchup spi1 routing, swap RDY/SCK breakout pins
    [FPGA.kicad_sch]
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2024-11-28 fw: long/short press (wip)
    [menu.c]
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2024-11-29 hw: DRC fixes
    [USER.kicad_sch]
2024-11-29 hw: Some DRC fixes
    [Audio.kicad_sch, USB.kicad_sch]
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2024-12-02 hw: fix wire/grid violations in schematic
    [Audio.kicad_sch, CASS.kicad_sch, CPU.kicad_sch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]
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2024-12-04 hw: mark pads as "heat sink" to avoid DRC error
    [DVI.kicad_sch]
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2024-12-11 hw: rework buck converter (wip)
    [Audio.kicad_sch, CASS.kicad_sch, DVI.kicad_sch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]
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2025-01-25 fw: tidy unmapped region workaround (wip)
    [driver.c]
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2025-02-09 hw: restore 1k current limiting resistor to oscillator
    [MCU.kicad_sch]
2025-02-16 hw: reroute and pin swaps
    [FPGA.kicad_sch]
2025-02-17 hw: fix/update parts / use parallel resistors to control 5V
    [Audio.kicad_sch, CASS.kicad_sch, CPU.kicad_sch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]
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2025-02-19 hw: replacement for 9V POWER JACK
    [POWER.kicad_sch]
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2025-05-04 fw: fix some warnings
    [menu.c]
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2025-05-08 fw: improved error reporting
    [driver.c, menu.c]
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2025-05-17 doc: fix ocr errors in memory map (pass 1)
    [memorymap-ocr.csv]
2025-05-18 doc: fix ocr errors in memory map (pass 2)
    [memorymap-ocr.csv]
2025-05-20 doc: update memorymap-ocr.csv
    Fix line 1738
    [memorymap-ocr.csv]
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2025-05-24 fw: fix 80 cols
    [menu.c]
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2025-08-24 fw: usb num lock swaps keyboard models (wip)
    [roms.c]
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2025-08-31 gw: fix non-synthesizable warnings
    [spi1_controller.sv]
2025-08-31 gw: fix warnings from multiple common_pkg inclusion
    [spi1_controller.sv]
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2025-11-02 fw: fix build warnings
    [roms.c]
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2025-12-07 fw: fix unusued variable in mem.c
    [mem.c]
2025-12-10 rom/fw: play 'uh oh' tune on error
    [menu.c, roms.c]
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2026-01-05 doc: fix CSV downloads
    [jlcpcb-rev-a-bom.csv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]
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2026-02-18 refactor(fw): make bp_set fail-fast
    [breakpoint.c]
2026-02-21 fix(fw): fix breakpoint build
    [breakpoint.c]
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2026-02-28 fix(hw): add 100n on RUN pin to improve EMI immunity
    [MCU.kicad_sch]
2026-02-28 fix(docs): remove duplicate entry for PCB mounting pillar in Mouser parts list
2026-02-28 fix(hw): reduce lower mounting pillars to 3.2mm
    [POWER.kicad_sch]
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2026-08-15 fix(fw): don't fatal() when a non-keyboard HID interface unmounts (#16)
    Combo dongles expose a mouse endpoint alongside the keyboard; only
    keyboard interfaces are tracked at mount, so unplugging one hit the
    fatal() in usb_keyboard_removed().
2026-08-15 fix(fw): HDMI should use the config's character ROM (#17)
    The HDMI renderer always drew with the character ROM compiled into
    flash; mirror the config's ROM and select the quadrant the CRTC does.
    [menu.c, roms.c]
2026-08-15 chore(gw): retarget Efinity project to T20Q144 (#18)
    This updates the Efinity project XML to target the T20Q144C3
    The rev-A BOM has always specified the T20Q144C3, with the hope of eventually adding SuperPET support.
    However, the gateware was previously built for the smaller T8Q144 FPGA to allow for a future downgrade / cost-reduction if the SuperPET idea didn't work out.
2026-08-15 fix(fw): refresh HDMI character ROM from SRAM
    [menu.c, roms.c]
2026-08-16 fix(gw): sim and timing nits (#21)
    - timing.sv: declare CPU_BE_END before its use in the same localparam
    list (CPU_PHI_END read it one line earlier)
    - SDC: bound cpu_data_i pin-to-FF routing with set_max_delay instead of
    a false path, which let P&R stretch the route without limit
    - sim.sh: compile packages registered as sim_file entries too -- the
    m6502 rtl is sim-only here and its package never reached the file
    list, so every registered testbench failed to compile
    - iverilog -g2009 -> -g2012 (the m6502 rtl is SystemVerilog-2012)
2026-08-16 gw: verilator runner for the simulation testbenches (#22)
    * gw: verilator runner for the simulation testbenches
    verilate.sh compiles any registered testbench with --binary --timing;
    docs/dev/verilator.md covers the reset-randomization modes and known
    constraints. ~40x faster than iverilog on the full boot benches.
    Two sim-infra fixes the iverilog flow tolerated by evaluation-order
    accident but Verilator does not:
    - clock_gen.sv: 'always @(posedge enable)' never fires under --timing;
    use 'initial forever wait(enable)'
    - mock_sram.sv: latch write data during the WE-low window (a real SRAM
    has tDH = 0; the WB->RAM bridge drops its data OE on the same edge WE
    rises, and Verilator settles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
2026-08-25 feat(gw): soft 6502 and 6809 with runtime select (#24)
    * fix(gw): sim and timing nits
    * feat(gw): soft 6502 and 6809 CPU cores with runtime select
    Adds two soft CPU cores -- MC6809 (cavnex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
2026-08-25 fix(docs): add C7 to rev-a BOM and assembly instructions
    [bom.csv]
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2026-08-27 fix(hw): correct rotation for U2 in positions.csv
    [positions.csv]
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2026-08-30 fix(gw): IEEE snoop drove the bus into the next cycle's opcode fetch (#35)
    * fix(gw): IEEE snoop drove the bus into the next cycle's opcode fetch
    - close the injection window when BE falls: the stale snapshot fought
    the following opcode fetch on the data bus
    - init the FIFO request flags (phantom power-on push under rand reset)
    - bench: ieee_sys_tb runs the kernal's LISTEN-8 send on the soft 6809
    through main.sv's snoop/inject path, bench serving the MCU over SPI
    * fix(gw): capture self-driven read data internally, not via the pad loop
    Injected reads needed the FPGA's own data to survive the pad round trip
    inside the capture window -- marginal on silicon (Waterloo hung at
    'Loading bas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
2026-08-30 feat(fw): flat .hdd hard-disk images for Super-OS/9 (#36)
    'Loading basic'), hidden by s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
    [ieee_drive.c]
2026-08-31 fix(fw): close file handle in sd_read_file
    [sd.c]
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2026-09-03 fix(gw): reset mc6809i's NMI latch instead of forcing power-up state
    mc6809i's NMILatched has no unconditional refresh path, so it kept
    whatever value it powered up with, and a 0 reads as an NMI pending on
    the first instruction fetch after reset. main.sv ties nNMI inactive, so
    the latch was never clocked at all and the Efinity netlist mapped it to
    a falling-edge FF whose clock only ever rises.
    Bump the mc6809 submodule to the fork's asynchronous reset for the latch
    and drop the GW_RAND_RESET overrides that forced those benches to power
    up all-ones to hide it. The benches now pass at the default all-zeros,
    which is the closer match to the FPGA.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
2026-09-17 fix(hw): use TPS56424x for 5V / 6.1V rails (schematics only)
    [POWER.kicad_sch, USB.kicad_sch]
2026-09-18 fix(hw): use TPS564247 for 5V / 6.1V rails (pcb)
    [Mainboard.kicad_pcb, POWER.kicad_sch]
2026-09-18 fix(hw): additional decoupling for audio power rail
    [Audio.kicad_sch, Mainboard.kicad_pcb]
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2026-09-19 fix(hw): fix ERC for TPS56424x
    [POWER.kicad_sch]
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2026-09-23 fix(fw): reset IEEE channels on unmount (#51)
    [ieee_drive.c]
2026-09-24 fix(fw): reset cpu state when FPGA configuration is skipped
    [main.c]
2026-09-24 fix: clear stale breakpoint state during initialization (#58)
    [breakpoint.c, driver.c, main.c]
2026-09-25 fix(fw): make fatal error reporting robust (#60)
    * fix(fw): fatal selects lowercase, mirrors to native, and hangs
    * fix(fw): make fatal error reporting robust
    Use bounded formatting for fatal and parser diagnostics, teach window output to handle line endings, and allocate decoded config blobs to their required size.
    * fix(fw): address fatal reporting review feedback
    Bound fixed-size hex input before allocation, preserve rows after exact-width line wrapping, and keep configuration names within one menu row.
    * style(fw): fix whitespace
    * doc(fw): com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
    [main.c, menu.c]
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2026-09-28 fix(hw): increase lower mounting holes to 3.5mm
    [Mainboard.kicad_pcb]
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2026-09-29 fix(fw): verify FPGA startup state (#63)
    [driver.c, main.c]
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2026-09-30 fix: reset virtual IEEE drive with PET (#64)
    [breakpoint.c, driver.c, ieee_drive.c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]
2026-09-30 fix(gw): declare simulation timescales (#66)
    [spi1_controller.sv]
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2026-10-03 fix(hw): remove I2C0 jumpers
    [DVI.kicad_sch, MCU.kicad_sch, Mainboard.kicad_pcb]
2026-10-04 fix(fw): enforce shared SD path limits and directory prefixes (#71)
    Match the pinned pico-vfs path capacity and reject overlong paths instead of silently truncating them. Share directory prefixes and checked path construction across production and host tests.
    [ieee_drive.c, main.c, roms.c]
2026-10-04 refactor: extract shared host test support (#73)
    Move host Pico shims, timing, in-memory files, and fatal expectations into test/support. Keep firmware-specific driver and peripheral mocks in fw/test.
    Wire shared support into the host test target, migrate fixture helpers to test_* names, and replace ARRAY_SIZE with the SDK-compatible count_of helper.
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2026-10-05 fix(hw): fix three thermal reliefs with single spoke
    [Mainboard.kicad_pcb, bom.csv, designators.csv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]
2026-10-06 feat(hw): avoid 68R extended part
    [Mainboard.kicad_pcb, POWER.kicad_sch, bom.csv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]
2026-10-06 fix(hw): JLCPCB DFM warnings
    [Mainboard.kicad_pcb, positions.csv]
2026-10-07 refactor: centralize and validate the hardware contract (PR 4.5) (#75)
    Share firmware hardware encodings with the RTL package and verify them through independently compiled C and SystemVerilog evaluators. Add system presets to the all build/test profiles and CI, and bind configuration decoding to the named pin levels.
    Align the root CMake minimum with preset schema requirements, validate the complete video RAM field, and preserve IEEE mock enable readback. Add boundary and flush regression coverage and correct stale comments.
    [driver.c, hardware_contract.h, ieee_drive.c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]
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2026-10-10 feat(gw): add standalone external pia and via models (#81)
    * feat(gw): add standalone external pia and via models
    Add typed host-side peripheral adapters with guarded input edits, completed bus accesses, and atomic rejection of unsupported modes.
    Pin the chips fork with resolved PB6 pulse counting and cover device identities, control modes, timer behavior, and bus recovery.
    * fix(gw): prioritize peripheral reset over select conflicts
    Ignore physical select conflicts while reset is asserted so pending writes are canceled instead of surviving a rejected reset sample.
    Cover all pending devices and overlapping select comb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
2026-10-10 feat(gw): add production-top simulator foundation (#82)
    * feat(gw): add production-top simulator foundation
    Add independent host boards with SRAM and peripheral bus resolution, detached snapshots, raw pin stimulus, and reset recovery for interrupted clocks.
    Separate optimized Verilator models from Debug test support, enable board tests in root presets, and cover soft-CPU execution, SPI inspection under reset, and actual input wiring.
    * fix(gw): restore simulator wiring and close sid envelope timing
    Wire the diagnostic switch into fitted PIA1 PA7 and restore active-low audio detection at the physical boundary.
    Pin the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
2026-10-10 feat: add checked simulator spi and cpu lifecycle (#84)
    * feat: add checked simulator spi and cpu lifecycle
    Add scoped checked/raw SPI transport and CPU lifecycle helpers with native observations, fail-closed ownership, and production-bus regressions.
    * fix: preserve simulator cpu and video register semantics
    Mask unspecified CPU-control bits, preserve SuperPET mode during core selection, assert READY for physical 6502 startup, and name the asserted video status bit as text mode. Cover each behavior with production-bus regressions.
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2026-10-10 feat(test): add atomic ROM installation and revision catalog (#86)
    * feat(test): add atomic ROM installation and revision catalog
    Validate complete ROM batches before clock-free SRAM and metadata commits. Reject unsettled SPI work, require explicit fixture replacement, and preserve declared base identity across deliberate patches and reset.
    Add simulator-independent catalog checks and synthetic board loader regressions.
    * fix(test): reject ROM installation after unsettled reset edits
    Track external reset pin changes until a complete tick evaluates the reset net. Reject clock-free ROM installation while cached reset evidence is stale, including detached raw stimulus edits.
    Cover both rel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
2026-10-11 feat(test): add owned trace infrastructure (#87)
    * feat(test): add owned trace infrastructure
    Add source-bound windows, detached captures, scoped recorders and weak event publication for board and peripheral observations. Preserve explicit coverage across sampling failures and reset recovery, and copy only selected window records.
    Capture repeated physical and model writes, signal transitions and stereo digital A/V samples. Include independent trace storage tests, board regressions and author documentation without later execution or IEEE wire layers.
    * fix(test): prune idle trace subscriptions on registration
    Share subscription pruning between registration and event delivery so expired o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
2026-10-11 feat(test): add deterministic configured board execution (#88)
    * feat(test): add deterministic configured board execution
    Add scoped scheduling and single-use configured runs with explicit anchors,
    shared deadlines, and fail-closed callback and lifecycle completion checks.
    * fix(test): enforce configured service failure contracts
    Reject foreign, SPI-owned and pre-release after-slice service before clocks.
    Keep caught callback and strict scheduling failures unusable, and exhaust
    periodic services when their next occurrence is beyond simulation time.
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2026-10-11 feat(test): add cpu-specific assembly and fluent instructions (#90)
    Publish typed 6502/6809 encoders, owned labels and bounded programs without
    automatic execution. Resolve branches using modular 16-bit PC arithmetic,
    and validate installation and compound stores before backing mutation.
2026-10-12 feat: add cooperative cpu pause and resume (#92)
    * feat: add cooperative cpu pause and resume
    Add preassembled phase handshakes, private mailboxes, checked capabilities,\nresume deadlines and frozen phase captures for both soft CPUs.
    * fix: retain specific phase execution fault causes
    Sample board faults before falling back to generic execution failure and report retained causes ahead of consumed-handle errors.
    * fix: freeze phase snapshots at verified acknowledgment
    Capture selected data and timing in the closed-gate observer transition, before service overshoot or extra predicate waits can change them.
2026-10-13 feat: add ieee controller and protocol evidence (#94)
    * feat: add ieee controller and protocol evidence
    Add typed IEEE transactions, a real-CPU mailbox controller, bounded FIFO assertions, and passive wire tracing. Distinguish FIFO byte/ATN evidence from wire EOI, reject interrupted controller reuse, and retain pure protocol tests without board simulation.
    * fix: rearm ieee acceptor between received bytes
    Match PET KERNAL ACPTR by blocking NRFD before sampling and reasserting NDAC after DAV release, without toggling ATN between bytes. Add independent physical-source, per-byte signal, timeout, and TALK continuation regressions.
    * fix: include fitted signals in ieee wire traces
    Resolve fa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
2026-10-14 feat: add host firmware through production spi (#95)
    * feat: add host firmware through production spi
    Run the real drive implementation through simulated FPGA SPI with checked session ownership and RX evidence. Keep board and firmware executables isolated while including both in board-enabled builds.
    * fix: report all firmware teardown exceptions
    Preserve the original exception_ptr for custom teardown reporters and share catch-all GoogleTest reporting between session destruction and fixture teardown. Keep explicit close rethrows and unhandled destructor termination intact.
    * fix: prevent firmware destruction from abandoning ownership
    Terminate after reporting if rejected teardown leaves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
2026-10-16 test: add end-to-end system acceptance suites (#97)
    * test: add end-to-end system acceptance suites
    * fix(fw): preserve native one-byte file eof behavior
    Emulate the native OPEN readiness overwrite for ordinary D64 and D80 files, including the link-byte leak and eventual EOF. Keep raw image and REL semantics unchanged, and correct the acceptance expectations with independent CPU/wire regressions and pinned-source documentation.
    * fix(fw): isolate native eof detection from rel reads
    Use the ordinary stream's sector count and cursor instead of shared byte accounting to recognize the native one-byte EOF case. Add 24 interleaved-channel regressions spanning native image/file types and REL re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
2026-10-17 test: add commodore rom integration coverage (#98)
    * test: add commodore rom integration coverage
    * test: correct native record command payload
    Use the encoded file secondary and a valid one-based position. Keep the embedded zero in the record-number high byte.
    * build: separate system suite and per-test timeouts
    Allow the complete nested system suite 30 minutes while preserving all per-case deadlines. The previous five-minute aggregate limit also expires on main.
2026-10-17 test: restore omitted system completion coverage (#100)
    Reconcile the published system-test stack with the parked implementation. Restore missing integration coverage and IEEE signal observations, share physical bus sampling, and update the reference.
    Use checked pause/resume when replacing future assembly code so the live polling gate is never overwritten.
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2026-10-19 fix(fw): preserve sequential channel terminal states (#104)
    Stop fabricating CR and EOI after sequential EOF or read failure. Model channel lifetime with closed, readable and exhausted states while keeping streaming independent of addressing pauses.
    Cover D64/D80 terminal handling, repair and reopen recovery, backpressured UNTALK continuation, and real PET/Waterloo ROM receive timeouts. Consolidate current validation and native compatibility evidence.
2026-10-20 fix: preserve native relative record continuation (#105)
    * fix(fw): preserve sequential channel terminal states
    * fix: preserve native relative record continuation
    Track NRFD prefetch progress and bind the shared data queue to its owner so interrupted REL reads retain unread bytes across channel and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
2026-10-21 fix(fw): match native wildcards without drive aliasing (#106)
    * fix(fw): match native wildcards without drive aliasing
    Compare native filename patterns against raw directory bytes, preserving embedded zeros and case-sensitive literals. Keep case folding isolated to the flat HDD extension and decide empty-drive fallback from the peer container type.
    Add lookup, firmware, and native-controller regressions, document the ROM evidence, and initialize logging in the independent IEEE test fixture.
    * fix(fw): truncate native filename patterns at 16 bytes
    Follow FNDLMT and CP34 in the selected 4040 and shared DOS 2.7 sources: accept native matches after 16 directory-name bytes, ignoring later pat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
2026-10-23 fix: preserve native ieee command and response lifetimes (#107)
    * fix: preserve native ieee command and response lifetimes
    Share counted OPEN and command input per unit, defer EOI-marked work until native idle dispatch, and enforce CMDSET length rules. Preserve virtual-unit roles and unread status until terminal-CR GET.
    Add ROM-derived firmware, production-top, and RTL regressions. Promote valid historical transport probes and replace the Waterloo position probe with serviced exact-byte and EOI coverage.
    * fix: preserve binary operands and status response ownership
    Keep raw RECORD fields separate from CMDSET's adjusted text length. Retain each status generation's format across media chan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
2026-10-29 feat: add drive rom reconstruction and verification tools (#110)
    * feat: add drive rom reconstruction and verification tools
    * fix: preserve drive rom tool failure diagnostics
    Forward captured stdout and stderr before propagating tool failures so retained case logs include actionable diagnostics. Apply the same handling to assembler and disassembler version probes.
2026-10-29 test: add native drive reference capture and replay (#111)
    * test: add native drive reference capture and replay
    * fix: validate drive reference receives and source identity
    Compare CPU receive records with the selected replay actions independently of composed-wire frames. Include missing, extra, corrupt, and misattributed receives in the failure report.
    Validate all tracked MAME changes against HEAD using the pinned patch's textual diff format so approved staged or unstaged patches can be rebuilt without accepting unrelated staged edits.
2026-10-30 feat(fw): add ordinary drive write foundation (#114)
    * feat(fw): add ordinary drive write foundation
    * fix(fw): preserve ordinary write state and native completion
    Persist unit allocation state after writer release and retire failed commands without discarding retryable owners. Restore native drive selection, initial allocation status, wildcard detection and APPEND block accounting.
    * fix(fw): revalidate directory ownership across write retries
    Use current replacement metadata with exclusive retry cursors, reserve both directory-growth links and restart lookup after retiring a writer. Preserve writers on lookup I/O failure and invalidate free totals at BAM rebinding.
    * fix(fw): reserve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
2026-10-30 feat(fw): add native rename scratch and validate commands (#115)
    * feat(fw): add native rename scratch and validate commands
    * fix(fw): preserve metadata command ownership and native errors
    Protect retained publication intent and stale SCRATCH completion. Match native selector, drive-scan and VALIDATE chain behavior, and separate delegated initialization results from shared status.
    * fix(fw): preserve scratch chain order and native status widths
    Persist side-chain allocation changes before rejecting an invalid data start. Match native two-digit 4040 status conversion while preserving DOS 2.7's hundreds digit and the byte-sized scratch count.
    * fix(fw): distinguish scratch file owners an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
2026-10-30 feat(fw): add ordinary file copy commands (#117)
    * feat(fw): add ordinary file copy commands
    * fix(fw): preserve native copy ordering and directory ownership
    Share retained-writer directory guards across OPEN and COPY, including the copy-all source iterator. Preserve native short-name and 4040 pending-match behavior, wait for required reads before output boundary writes, and judge self-append by its writer rather than peer status.
    * fix(fw): observe copy directory errors only when selected
    Discard unused directory jobs when OPREAD reopens the internal channel. Let whole-drive and patterned COPY complete current-page files before observing successor errors, while replacing old jobs on nat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

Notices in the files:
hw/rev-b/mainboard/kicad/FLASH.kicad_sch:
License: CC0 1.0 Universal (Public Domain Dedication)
